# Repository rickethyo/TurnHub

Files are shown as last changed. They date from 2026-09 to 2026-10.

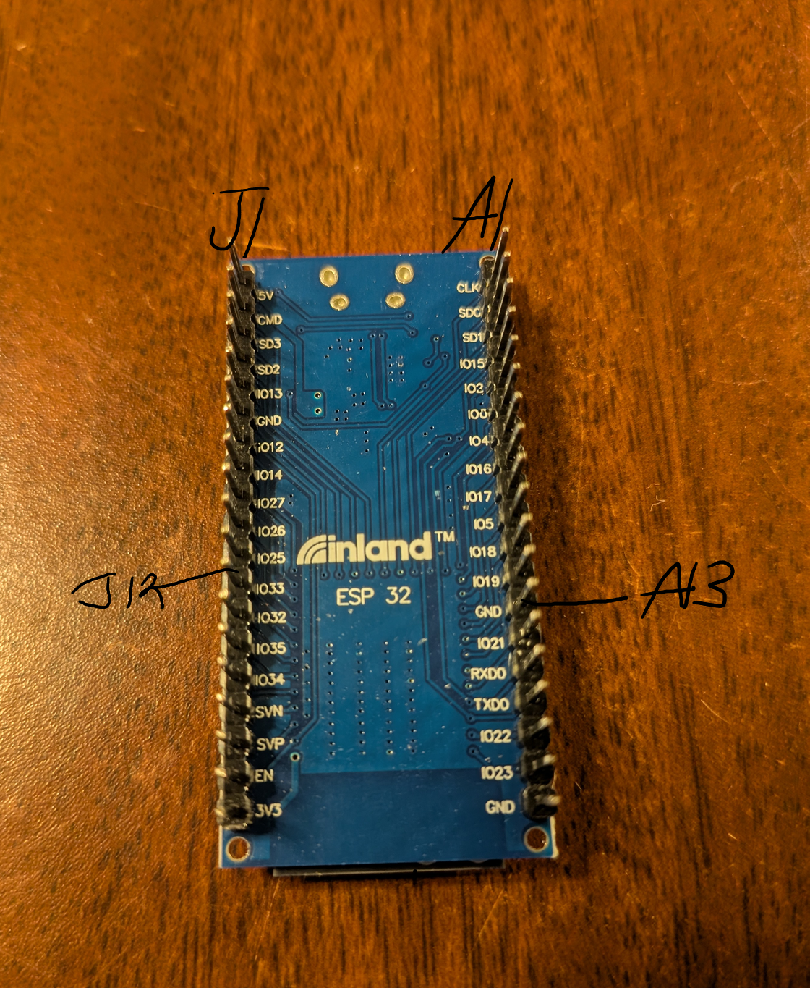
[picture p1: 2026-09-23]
KiCad/PCB/Sigilv1/reference/SigilBackMarked.png

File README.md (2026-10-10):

# TurnHub

TurnHub is a local-first tabletop game-management system: turn timer, lobby,
life totals and Commander damage, player profiles and statistics. An
authoritative **Atlas** table controller runs the game; player-facing
**Sigils**, phones and tablets (the Android app) and the Atlas
touchscreen request the same semantic actions from it.

**Current firmware:** Atlas **0.6.6**, Sigil **0.9.8** (protocol 3), on `master`.
Signed releases are published on GitHub Releases and installed from the
Android app or the Atlas portal.

Earlier Python/Raspberry Pi generations are recorded in
[Generation History](Documentation/engineering/history/GENERATION_HISTORY.md). They are
not part of this repository or the current runtime.

## Where to look

| Path | What |
|---|---|
| [`Atlas/`](Atlas/README.md) | ESP32 table controller: game engine, Wi-Fi AP, web portal and HTTP API, ESP-NOW radio, NVS and optional microSD storage |
| [`Sigil/`](Sigil/DISPLAY.md) | ESP32 player controller, e-ink and OLED variants ([Wokwi simulation](Sigil/WOKWI.md)) |
| [`Android/`](Android/README.md) | Native client: table view, player controls, guided setup and firmware updates |
| [`protocol/`](protocol/README.md) | Client contract: JSON schemas, [`http-v1.md`](protocol/http-v1.md), example responses |
| [`shared/include/`](shared/include) | Firmware headers shared by Atlas and Sigil (radio contract, firmware package format) |
| [`TestHarness/`](TestHarness/README.md) | Retired hardware test harness; historical source only, unsupported and excluded from builds |
| [`KiCad/`](KiCad/PCB/Sigilv1/README.md) | Sigil carrier PCB and schematics |
| [`Documentation/engineering/`](Documentation/engineering/README.md) | The engineering record: invariants, design references, staged work |
| [`Documentation/User Manual/`](Documentation/User%20Manual) | The user manual (newest `.docx`; the app bundles the same text) |

## Core architectural rule

**Atlas owns canonical game and table state.** Sigils, phones, the Atlas
touchscreen and simulators submit Intents and render Atlas state.
They never advance turns, resolve wins, own player identity or keep competing
game engines. See [Architectural Invariants](Documentation/engineering/ARCHITECTURAL_INVARIANTS.md).

```text
Profile (optional persistent person)
  -> Participant (one person at the current table)
    -> Controller assignment(s): physical Sigil seat, browser sessions, the app
```

Changing controllers never replaces the participant or moves its statistics.

## What works today

- Lobby with any-seated-player start (cancellable countdown), starter choice,
  turn passing with a three-second cancellable grace, pause/resume, concession,
  elimination, win claim/confirm, draw by the Atlas End match hold, rematch and reset.
- Game profiles (Generic, Magic, Commander, Yu-Gi-Oh!) with life totals,
  Commander damage and cross-player life requests the recipient approves.
- Turn timer with warning and expiry cues on Sigil lights and buzzers, the
  Atlas speaker and phones, with per-player accessibility preferences.
- Local profiles with PINs, phone-only and mixed phone/Sigil play, a Sigil
  profile picker, Admin/Game Master/Developer permissions, and table presence
  codes for protected actions.
- Deliberate pairing (60 s minimum window) over an encrypted Atlas-Sigil link,
  with forget/unpair and factory reset from menus, the portal and the BOOT button.
- Interrupted-match recovery: a power cut restores the match paused.
- Core statistics in NVS; detailed statistics, avatars and rotating
  diagnostics on an optional microSD card.
- Signed firmware updates for Atlas and both Sigil variants, delivered from
  the Android app or the portal, plus a first-run guided setup in the app.

Known limits are tracked in [Staged Changes](Documentation/engineering/STAGED_CHANGES.md).
The most important: statistics are not yet crash-safe exactly-once
([completion ordering](Documentation/engineering/STORAGE_AND_RECOVERY.md)).

## Persistence

Survives restart: profiles, PIN hashes, permissions and policy, core
statistics, seat bindings, pairings, game settings, accessibility
preferences, the Wi-Fi password, speaker volume, setup stage and touch
calibration (NVS); detailed statistics and diagnostics (microSD, optional).

RAM only: browser sessions, lobby participation and live game state, except
the interrupted-match recovery record, which restores paused and never
replays statistics.

## Building and testing

Commands for every target are in [`CLAUDE.md`](CLAUDE.md) and each
directory's README. CI (`.github/workflows/ci.yml`) runs the host suites,
contract checks, supported firmware builds and the Android tests; see
[Continuous Integration](Documentation/engineering/CONTINUOUS_INTEGRATION.md).

## Local-first

The core play path never needs a cloud service, subscription or internet
connection. Atlas serves the table on its own Wi-Fi. The broader ownership,
repairability, privacy and accessibility direction is in
[Product Principles](Documentation/PRODUCT_PRINCIPLES.md).

## Status

TurnHub is a prototype. Every Atlas and Sigil is reflashed together,
so there is no backward compatibility before release: a changed protocol or
storage layout means reflashing everything and, for storage, a factory reset.

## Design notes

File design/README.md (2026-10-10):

# TurnHub design system (V1)

One source of truth for how the Atlas portal, Android app and device screens look. Status:
**Implemented** in source (2026-10-02, V1 phase 0). The portal and the app adopt
it in later phases; see the V1 plan and `Documentation/engineering/WEB_PORTAL.md`.

| Path | What | Edit? |
|---|---|---|
| `tokens.json` | Themes (colors per role), type scale, spacing, radii, elevation, motion springs, layout constants | Yes, the source |
| `icons/*.svg` | The original icon set: 24-point grid, 1.75 stroke, round caps, `<path>` elements only | Yes, the source |
| `fonts/` | Inter and Cinzel variable fonts, subset to Latin (TTF for Android, WOFF2 for the web), with their OFL licenses | Replace only with a recorded source |
| `web/components.css` | The web component library (buttons, pills, lists, sheets, turn hero, life tiles, app shell), built only from tokens | Yes |
| `avatars/*.svg` | The player icons: filled glyphs on the 24-point grid, `<path>` elements only, with an optional lighter tone (`opacity`) and holes (`fill-rule="evenodd"`). One file per preset in `shared/include/avatars.h`, same keys; the build refuses a missing or extra one | Yes, the source |
| `styleguide.html` | Living specimen of all of the above, with a playable Game screen preview | Yes |
| `build_tokens.py` | Generates every file below from `tokens.json` and `icons/`, and checks contrast | Yes |
| `bundle.py` | Inlines stylesheets, fonts and the icon sprite into one HTML file | Yes |
| `shared/include/device_theme.h` | Generated device theme IDs and opaque RGB888 role palettes; alpha roles are flattened over the theme background | No, generated |
| `Atlas/include/modern_fonts.h`, `Sigil/include/modern_fonts.h` | Inter bitmaps generated by `tools/fonts/make_modern_fonts.py` from the licensed font below; device digits have equal advances | No, generated |
| `dist/tokens.css`, `dist/icons.svg` | Generated web tokens and icon sprite (icons are `i-<name>`, player icons `a-<key>`) | No, generated |
| `Android/.../ui/theme/DesignTokens.kt`, `Android/.../res/drawable/ic_th_*.xml`, `ic_avatar_*.xml`, `Android/.../res/font/*.ttf` | Generated Compose tokens and vector icons, and the fonts copied for Android | No, generated |

```
python3 design/build_tokens.py            # regenerate after editing tokens.json or icons/
python3 design/build_tokens.py --check    # CI: generated files current, contrast minimums met
python3 design/bundle.py design/styleguide.html --out design/dist/styleguide.html --embed-fonts
```

The scripts use the Python standard library only, so PlatformIO's Python runs
them on Windows too. Re-subsetting a font needs `fonttools` and `brotli`
(`pyftsubset`, command in "Fonts" below).

## Themes

| Key | Name | Use |
|---|---|---|
| `graphite` | Graphite | Default on dark devices. Modern, near-black with one warm gold accent |
| `daylight` | Daylight | Default on light devices. Replaces Parchment |
| `brass` | Brass | Optional. Gold and walnut with Cinzel display type, matching the Atlas screen |
| `contrast` | High contrast | Chosen automatically when the device asks for more contrast |

With no saved choice a client follows the device (`defaults` in `tokens.json`).
Midnight and Parchment from the pre-V1 portal are retired: Graphite and Daylight
cover them. Owner decision 2026-10-02: modern first, Brass kept as an option.

**Roles, not colors.** Components use `--c-<role>` (CSS) or `TokenColors.<role>`
(Kotlin), never a literal. The roles: `bg`, `surface1..3`, `fill`, `fillStrong`,
`separator`, `separatorStrong`, `text`, `textSecondary`, `textTertiary`,
`accent`, `accentPressed`, `onAccent`, `accentSoft`, `turn` (the active turn,
the one thing that glows), `onTurn`, `turnSoft`, `good`, `warning`, `critical`,
`info`, `focus`, `scrim`, and `glowA`/`glowB` (Brass background glow only).

**Contrast is enforced.** `contrast.checks` lists WCAG 2.2 minimums; the build
refuses to write files when a theme misses one (translucent colors are
composited over the theme background first). Status colors must reach 4.5:1 on
`surface1` because they are also used as text. Color never carries meaning
alone: every status pill and tile state also has words.

## Type

Inter (text and UI) for every theme; Brass swaps the display role to Cinzel.
Sizes are in `type`: `caption` 12 through `mega` 112. Clocks and life totals
(`clock`, `hero`, `mega`) use tabular figures so digits do not jitter.

## Motion

Three springs (`snappy`, `gentle`, `bouncy`) as Compose damping ratio and
stiffness. The CSS build simulates the same physics and emits a `linear()`
easing plus its settle duration (`--spring-<name>`, `--spring-<name>-dur`),
falling back to `--ease-standard` in browsers without `linear()`. Reduce motion
(system setting or the per-browser switch, `data-motion=reduce`) shortens every
animation and transition to 1 ms.

## Fonts

| Font | Source | Files |
|---|---|---|
| Inter 4 (variable: `opsz`, `wght`) | `github.com/google/fonts` `ofl/inter/Inter[opsz,wght].ttf`, fetched 2026-10-02 | `fonts/Inter-Variable.{ttf,woff2}`, `fonts/OFL-Inter.txt` |
| Cinzel (variable: `wght`) | `github.com/google/fonts` `ofl/cinzel/Cinzel[wght].ttf`, fetched 2026-10-02 | `fonts/Cinzel-Variable.{ttf,woff2}`, `fonts/OFL-Cinzel.txt` |

Both are SIL Open Font License 1.1 and recorded in
`Documentation/legal/DEPENDENCY_TRACKER.md`. They were subset with:

```
pyftsubset <font.ttf> --unicodes="U+0000-00FF,U+0131,U+0152-0153,U+02BB-02BC,U+02C6,U+02DA,U+02DC,U+2000-206F,U+2074,U+20AC,U+2122,U+2190-2199,U+2212,U+2215,U+2248,U+2260,U+2264-2265,U+2713,U+2715,U+00D7,U+2026,U+25B2,U+25BC,U+25CF" --layout-features='*' [--flavor=woff2] --output-file=<out>
```

## Icons

Add an icon by dropping a 24×24 SVG with `<path d="...">` elements into
`icons/` and running the build. Use `stroke="currentColor"`, no fills, no
`<circle>`/`<rect>` (draw them as arcs) so the Android conversion stays a copy.
The web references `#i-<name>` in the sprite; Android uses
`DesignTokens.Icons.<camelName>` (`R.drawable.ic_th_<name>`).

## Device screens

Atlas offers all four color themes under Menu > Device > Theme, defaulting to
Graphite. Sigils choose independently through their local Theme menu entry.
OLED Daylight is dark ink on white; its other themes are light ink on black.
E-paper normally uses black on white, adapting the typography, hierarchy and ornament
rather than trying to reproduce color. Brass alone uses Cinzel/Oswald and gears;
modern themes use Inter and plain cards, with distinct one-bit glyphs, life symbols and header marks. See
[Hardware](../Documentation/engineering/HARDWARE.md) for persistence and refresh
behavior. To regenerate Inter device fonts, install `freetype-py` in a Python
virtual environment and run `python tools/fonts/make_modern_fonts.py`. No fonts
are downloaded: it reads the checked-in Inter variable font at weight 600.

Each device also saves an independent Invert switch, exposed next to its theme
controls. Sigils swap foreground/background; Atlas complements its RGB palette
while retaining conventional black-on-white QR codes. This does not change LED
preferences. `shared/include/theme_emblem.h` owns the diamond, sun and boxed
hourglass marks; Brass retains its renderer's gear.

## Player artwork for LCD hardware (2026-10-10)

SVG player defaults are resolution independent. `build_avatar_masks.py`
rasterizes them at 256px and filters to 64px alpha masks in
`Atlas/include/avatar_masks.h`; current Atlas filters into its 16px slot without
blocky bitmap enlargement. Android uses the original vector drawables. Frozen
Sigils keep `shared/include/avatars.h` unchanged. Regenerate with
`pip install -r tools/artwork-requirements.txt` and run the generator; its
`--check` verifies source/artifact digests using stdlib only and runs in CI.
Uploaded JPEG masters are 512px/48KiB; 64/128px previews are provisional device
slots until the ESP32-S3 2.8/4-inch layouts are built.

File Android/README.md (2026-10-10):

# TurnHub Android

This directory holds the native TurnHub Android client.

The Android app is a controller and presentation client. It is not a second TurnHub game engine, with one exception: the standalone tablet game below.

## Hard architecture rule

The app may:

- Discover or connect to an Atlas.
- Authenticate a player/session.
- Request a current state snapshot.
- Render authoritative Atlas state.
- Send semantic Intents.
- Receive state/events.
- Cache user preferences and non-authoritative profile conveniences locally.
- Recover from connection loss by resynchronizing with Atlas.

The app must not:

- Advance turns locally as authoritative state.
- Decide whether a concession, win claim, pause, or life change is legal.
- Become authoritative for life totals, active player, timers, winner, or elimination state.
- Reimplement gameplay rules that already belong to Atlas.
- Depend directly on ESP32 C++ implementation details.

### The one exception: the standalone tablet game

Device-first entry (2026-10-08, implemented on `codex/app-only-entry`, device
acceptance pending): the disconnected landing screen leads with **Play on this
device**, or **Resume game** for a running/paused local match. No account,
network or nearby-device permission is needed. `MainActivity` owns navigation:
`turnhub_ui/prefer_device_play` remembers local play across launches, while the
saved instance state remembers the currently open screen across rotation.
Back returns to Home without changing the preference or game. Explicit Atlas
Connect, Try again or setup selects Atlas for future launches and requests local
network permission if needed. Fresh launches never request that permission;
Atlas-preferred launches rejoin only when permission is already available.
Entering device play cancels discovery, Wi-Fi joins and pending repository
connects, then disconnects polling and releases the Atlas network. A later
connection waits for the disconnect to finish. Local history and explicit Atlas-scoped linking are described below
(TH-001 in `COLLABORATION.md`).

With **no Atlas at the table**, **Play on this device**
runs a small game on the device itself: life, Commander damage, turns, pause,
concede and the winner (`standalone/StandaloneGame.kt`). It is a separate
game, never a copy of or a change to a game Atlas is running, so nothing is
merged back live. The rules above apply in full whenever Atlas is present.

- The table screen is tablet mode's (`ui/tablet/TabletTable.kt`); it sends
  the same seat actions through `data/TableControls`, which
  `StandaloneTable` applies locally instead of `AtlasTablet` sending them.
- Adding a typed name creates a reusable player with a local UUID. Selecting a
  saved player reuses that identity. Same-name players stay distinct and short ID
  labels distinguish them. Reset/rematch preserves IDs; records snapshot names.
- **Device players and history** opens from Home (connected or disconnected),
  and the local lobby. It shows results and basic played/won/draw totals derived
  only from retained local matches by local ID, without combining Atlas totals.
- The versioned local library owns roster, history and independent delivery
  metadata. Active game/library writes share one preference transaction. Every
  completed match is retained once by its match UUID; there is no automatic
  200-record pruning. Imported/rejected results stay in history. Current game
  and identities survive reconstruction; actual Android rotation/relaunch still
  needs device acceptance. Corrupt/future data fails closed, preserves the
  stored bytes, and explains the problem rather than overwriting it.
- Import is optional and explicit, never automatic on sign-in. From history,
  connect/sign in, load current Atlas profiles, choose a different profile for
  each player in a match, then Import mapped match. Nothing is preselected by
  name. The delivery mapping snapshots `(atlasId, profileId)` per match; it
  does not merge/replace local identities or change historical player names.
  Pending mappings are frozen through uncertain acknowledgements; retry uses the
  same match UUID and destination. Imported mappings cannot be resubmitted.
- History separately shows needs-linking, pending, imported and needs-attention
  (rejected) states. HTTP 400 retains the record and reason without automatic
  retry; explicit review/relink can queue it again. Transient/malformed responses
  keep pending work and block newer deliveries until acknowledged. A signed-in
  user can send only pending work for the current Atlas. Atlas 0.7.2+ requires
  exact destination/profile IDs and rejects missing, duplicate, deleted,
  archived or unreadable identities before taking a receipt; no name fallback.
  Acknowledged partial credit is displayed and never automatically retried.
- Existing queue records are retained as legacy history without guessed local
  or Atlas identity and can be explicitly mapped per match. Earlier imported/
  dropped records cannot be reconstructed. Atlas's 64-receipt dedupe window and
  possible partial credit after storage failure/power loss remain unchanged;
  this is not crash-safe exactly-once statistics across arbitrary retries.
- No turn timer, Two-Headed Giant, phones or Sigils in this mode.

```text
Compose UI
    -> ViewModel
        -> AtlasRepository
            -> TurnHub protocol adapter
                -> Atlas
```

State flows back in the opposite direction.

## Stack

- Kotlin, Jetpack Compose, Material3
- Unidirectional data flow with a ViewModel at screen boundaries
- Repository abstraction around Atlas communication
- Coroutines / Flow for asynchronous state

## Current source layout

The Gradle/Kotlin project was bootstrapped as a single `:app` module (Kotlin +
Jetpack Compose, Material3, no other UI framework). Current layout:

```text
Android/
  app/
    src/main/java/com/turnhub/android/
      MainActivity.kt
      protocol/                     wire DTOs + parser, 1:1 with /protocol schemas
        AtlasConnectionState.kt
        AtlasInfo.kt                /api/v1/info
        StateSnapshot.kt            /api/v1/state (+ PendingDecisions)
        Player.kt                   players[] (+ CommanderDamage, LifeRequest)
        GameProfile.kt
        TableState.kt
        AtlasWireParser.kt          strict org.json parsing, fails closed
      domain/
        TableSummary.kt             UI aggregate (+ TablePlayer, ControllerHandle,
                                    PhysicalSigilAtTable)
        TableSummaryMapper.kt       info + state -> TableSummary
        UserManual.kt               parser for the bundled manual asset
      data/
        AtlasRepository.kt          the only seam the UI talks through
        HttpAtlasRepository.kt      connect handshake, polling, reconnect rules
        AtlasTransport.kt           getInfo()/getState() seam (+ factory)
        HttpAtlasTransport.kt       HttpURLConnection implementation
        WifiPreferringConnectionOpener.kt
        AtlasEndpoint.kt            user-editable http://host[:port]
        AtlasCompatibility.kt       API "1" / protocol "0.1" / stateSnapshot
        AtlasFailure.kt             user-facing failure types
      ui/
        home/                       HomeScreen, HomeUiState, HomeViewModel
        manual/                     ManualScreen (the "?" in the top bar)
        components/                 ConnectionStateBadge, TableSummaryCard,
                                    PlayerRow, PhysicalSigilRow
        theme/
    src/main/assets/manual.md       generated user manual (see below)
    src/main/res/xml/network_security_config.xml
    src/test/java/com/turnhub/android/
      testing/Fixtures.kt           loads ../protocol/examples/*.json
      protocol/  domain/  data/  ui/home/
```

`protocol/` holds Kotlin wire models that mirror the JSON shapes in `/protocol`
(`state-v0.1.schema.json`, `info-v1.schema.json`) -- not the ESP32 C++ types,
and not a claim that the wire format is frozen. Unsigned 32-bit Atlas values
(revision, participant IDs, turn counts, `*Ms` clocks) are `Long`. `domain/`
holds UI-oriented models that combine more than one wire response
(`TableSummary` merges `/api/v1/info` identity fields with an `/api/v1/state`
snapshot) and so aren't a 1:1 mirror of any single schema.
`data/AtlasRepository` is the only seam the UI talks through; networking stays
below it. As lobby/game/player/settings/scanner screens are added, `ui/`
should grow one subpackage per screen alongside `ui/home`, following the same
pattern.

The app carries the user manual so it reads offline, before connecting to
any Atlas. `app/src/main/assets/manual.md` is generated from the newest
`Documentation/User Manual/TurnHub Manual V*.docx`; never edit it by hand.
After changing or adding a manual version, run
`python Android/tools/export_manual.py` (standard library only) and commit the
result. CI runs it with `--check` and fails when the asset is stale.

The application ID `com.turnhub.android` is frozen: the Google Play listing
was created with it on 2026-10-06 (Play App Signing), and Play never lets an
app change it.

## Development dependency order

Android work may proceed in parallel with firmware, but these interfaces need to stabilize in roughly this order:

```text
Intent vocabulary
    -> Atlas dispatcher enforcement
        -> v0.1 wire adapter
            -> state snapshot + revision
                -> Android repository
                    -> Android UI
```

The app UI does not need to wait for every TurnHub feature. It does need a stable way to say "I want X" and receive "this is now the authoritative state."

## Testing direction

Android tests should eventually include:

- Protocol serialization tests against files in `/protocol`.
- Repository tests using a fake Atlas transport.
- ViewModel tests that verify UI state follows repository state.
- Reconnect/state-revision tests.
- Duplicate `requestId` behavior once Atlas implements deduplication.
- Stale `expectedRevision` conflict handling.

Game-rule tests stay with Atlas/domain code. Android tests verify client behavior, not whether TurnHub rules are correct.

The current suite is plain JVM tests (no Robolectric/instrumentation). They
parse the real `protocol/examples/` fixtures, drive `HttpAtlasRepository`
through a scripted fake `AtlasTransport` in virtual time, and exercise
`HttpAtlasTransport` against the JDK's local HTTP server. `org.json` is a
test-only dependency because the unit-test `android.jar` only has stubs.

Build and test from `Android/` (Android Studio's bundled JDK works):

```text
./gradlew assembleDebug
./gradlew testDebugUnitTest
./gradlew testDebugUnitTest --tests "com.turnhub.android.data.HttpAtlasRepositoryTest"
```

Play builds: CI uploads a signed release bundle (`.aab`) from every run, ready
for the Internal testing track; see "Android release bundle" in
`Documentation/engineering/CONTINUOUS_INTEGRATION.md`.

## What the app does

The app talks to a physical Atlas over its HTTP API; production always uses
`HttpAtlasRepository`. It shows the live table, gives a signed-in player personal and shared-tablet game controls, runs first-run setup, and installs firmware
updates on Atlas and the Sigils.

1. Open the app. It asks for "Nearby devices" (local network, Android 17),
   then rejoins the saved table by itself (`HomeViewModel.onAppStarted`):
   Android remembers its approval, so this is silent when the table is
   there. *Verified* on the Pixel Fold, 2026-09-30: a cold start opens the
   live lobby with no taps.
   - The saved table doesn't answer: "Couldn't reach your table" with Try
     again and Set up a new table (a factory-reset Atlas).
   - A phone that never joined a table leads with Set up a new table, which
     joins with the printed default; first-run setup then opens.
   - No Wi-Fi scan. Spotting tables in range was tried first
     (NEARBY_WIFI_DEVICES, `neverForLocation`), but on this Android scan
     results need location permission (`WifiService`: "has no location
     permission", zero results), and the owner chose not to ask for location
     (2026-09-30).
   Connect still works as before. The address defaults to
   `http://192.168.4.1` and is under Advanced. For that address the app
   first joins Atlas's Wi-Fi itself (see "Targeted Wi-Fi" below); other
   addresses must already be reachable.
   Anything that restarts Atlas from the app (setup's Finish and updates,
   Settings > Wi-Fi password, factory reset) saves the password Atlas comes
   back with and rejoins by itself.
2. `GET /api/v1/info` must be a TurnHub Atlas with API `1`, protocol `0.1`
   and state snapshots; anything else fails with a clear message.
3. `GET /api/v1/state` is mapped into the Home screen; only then is the app
   CONNECTED. State is then polled about once per second.
4. Every poll replaces the view (clocks change at the same revision). A new
   `atlasId`, new `bootId` or a lower `revision` discards the view and
   re-runs info + state. Three failed polls in a row put the app offline
   (2026-10-07, *Implemented*): it stays on its current screen, tablet mode
   included, with the last snapshot shown read-only under an "Offline:
   reconnecting" banner and its age, rejoins Atlas's Wi-Fi if Android dropped
   it, and polls every 2 s until Atlas answers; the epoch rules above then
   apply, so a restarted Atlas is rebuilt from a fresh handshake and its
   sessions reset. Disconnect stops polling and clears state.
   During a game, tablet mode keeps working offline for life and Commander
   damage only: each change is kept per participant with when it was tapped
   (`AtlasTablet.queueOffline`), shown on the panels, and sent once Atlas
   answers again through the usual tablet routes with `queuedMs`, where
   Atlas's rules decide it. Changes from before an Atlas restart, from an
   earlier game, or for a player no longer in it are dropped, as is any Atlas
   refuses, with one note; a clean replay is silent. Passing, pausing,
   conceding, win claims, answers, seating and settings are refused offline,
   since they depend on Atlas's live clock and turn. A match Atlas recovered after a reboot is simply shown
   as `PAUSED`.

V1 redesign, phases 5 and 6 (2026-10-02, *Implemented*, built by CI; not yet
checked on a phone):

- Themes come from the shared design tokens (`design/tokens.json`, generated
  `ui/theme/DesignTokens.kt`): Automatic (the default: Graphite on a dark
  phone, Daylight on a light one), Graphite, Daylight, Brass and High
  contrast. `Palette.kt` builds every component role from them; a saved
  `midnight` or `parchment` choice opens as Graphite or Daylight. Only Brass
  draws ornament (sheens, rivets, the brass dial); the modern themes draw flat
  cards, tinted pills and buttons, and a turn ring.
- Inter (all text) and Cinzel (Brass headings) are bundled in `res/font`,
  copied from `design/fonts` by `design/build_tokens.py`; clocks and life
  totals use tabular figures.
- New launcher icon (the portal's gold gear, with an Android 13 themed-icon
  layer), an Android 12 splash on the theme's ground, edge-to-edge drawing with
  system bar icons that follow the theme, and a bottom bar using the shared
  icons: Game, Players, Me, Settings (Admins and Game Masters) and Developer.
- Game screen: the turn hero is a native ring that drains or fills with the
  clock and breathes while a game runs; the active player's avatar sits under
  it. Life tiles count to a new total on a spring, bounce slightly and show
  the change for a few seconds. Haptics: a firm tap when the turn reaches this
  phone's player, ticks on the life buttons and tab changes, confirm/reject on
  Pass. Reduce motion turns the springs, halo and transitions off.

V1 redesign, phases 7 and 8 (2026-10-02, *Implemented*, built by CI; not yet
checked on a phone):

- App lock and automatic sign-in (`data/ProfileVault.kt`, Android 11+): the
  sign-in sheet's "Sign in automatically" keeps that profile's PIN or password
  AES-GCM encrypted under an Android Keystore key that opens for 30 seconds
  after the phone's fingerprint, face or screen lock. It is saved only after
  Atlas accepts the secret. On each new Atlas boot the app asks for the
  phone's lock and signs in; cancelling or signing out by hand is respected
  until the next boot, and a rejected secret reopens the sheet. Me > This
  phone turns it off. Excluded from backup and device transfer.
- Sign-in is a bottom sheet with a grouped account list (`GroupedList`).
- The seat controls rise in as the join flow moves through its stages.
- Live turn notification (`data/TurnNotifier.kt`, `domain/LiveTurn.kt`): while
  the app is in the background and its player sits in a game, the shade and
  lock screen show whose turn it is with a running turn clock (or the turn
  timer counting down). It alerts only when the turn comes to you and asks to
  be a promoted live update on Android 16+. It lasts as long as the app holds
  the Atlas connection.
- Haptics use the vibrator's full-strength primitives (`ui/components/Haptics.kt`).

Native player experience (original parity pass: 2026-09-26):

- The app provides the player experience and shares TurnHub design tokens. The
  themes (since V1: Automatic, Graphite, Daylight, Brass, High contrast;
  `ui/theme/Palette.kt`) are chosen in My Account and saved on the phone only; the
  device's raised-contrast setting still forces High contrast. A Reduce motion
  switch stops the turning gear and dial sweeps.
- Native tabs: **Game** (the brass turn dial, my seat with every
  session controls: join, I go first, start, cancel
  countdown, pass/cancel pass, pause/resume, claim, confirm or deny a win,
  concede, leave, rematch, reset; life tiles for every player with my -5/-1/
  +1/+5 and custom changes, tap-to-request changes to other players, the
  incoming life-request banner with its 15 s countdown, Commander damage, game
  setup and table facts), **Players** (roster and seated Sigils) and **My
  Account** (name, PIN, avatar, Sigil light color, Sigil accessibility,
  appearance, connection).
- All of it goes through the same routes as the portal (`/api/control/*`,
  `/api/control/life*`, `/api/control/commander`, `/api/game/settings`,
  `/api/session/profile`, `/api/session/personalization`); Atlas validates
  every request.
- **Settings** (Admin or Game Master accounts) and **Dev** (Developer
  accounts) tabs appear from `/api/session/me`'s `permissions`:
  verify at the table (the six-digit code from the Atlas screen; a request
  Atlas answers `403 presenceRequired` asks for the code and retries once),
  Wi-Fi password, paired Sigils (rename, forget, factory reset), pairing
  window, speaker volume, Return to lobby, Atlas factory reset, account
  permissions and archiving, Game Master moderation, first-Admin setup, and
  the Developer activity feed, raw status/devices/seats/diagnostics JSON and
  a shareable serial log (`AtlasAdminConsole`). Firmware updates run from
  first-run setup and the **Update now** card ([Sigil OTA](../Documentation/engineering/FIRMWARE_UPDATES.md)).
- **First-run setup** (2026-09-30, FIRST_RUN_SETUP.md): after Connect the
  app reads `GET /api/setup`; while Atlas is new it shows the setup steps in
  place of the table (`AtlasSetupAssistant`, `ui/setup/SetupScreen.kt`):
  account (create or sign in), table code (makes the account the Admin),
  Sigil pairing, one update prompt for Atlas and every paired Sigil, and the
  table's own Wi-Fi password. Firmware comes from the public GitHub release
  feed (`GitHubFirmwareReleases`) over the phone's own internet, checked for
  size and SHA-256; Atlas checks each package's signature. After an Atlas
  restart the app rejoins with the saved password and signs in again with
  the PIN typed during setup (kept in memory only).
- **Quick app switch:** Android releases an app's `WifiNetworkSpecifier`
  network once the app leaves the foreground. When the app leaves the screen
  while connected, `AtlasLinkHoldService` (a `connectedDevice` foreground
  service with a notification) keeps the app eligible for two minutes
  (`HOLD_MS`) and stops as soon as the app returns.

Accessibility (2026-09-24):

- A signed-in player's **Sigil accessibility** button opens
  `AccessibilityDialog`: Sigil sound, light style and Action hold times, read
  from and saved to Atlas through `/api/session/accessibility` (the same
  endpoint and validation as the portal). Atlas stores them with the profile.
- When Android 14+'s contrast setting is raised, `TurnHubTheme` switches to fixed
  high-contrast colors instead of wallpaper colors, and follows changes live.

Targeted Wi-Fi (no trip to Android settings):

- `TargetedAtlasWifiLink` asks Android for `TurnHub-Atlas` with a
  `WifiNetworkSpecifier` (no internet capability). The network is used only
  by TurnHub: the phone keeps its normal Wi-Fi/mobile connection. The Pixel
  Fold even stayed on home Wi-Fi at the same time. The link is also the
  `HttpConnectionOpener`, so Atlas requests go over that network.
- Password order: the saved password for the SSID, else the shipped default
  `TurnHub-Setup` (protocol/http-v1.md), else the "Atlas Wi-Fi" prompt. The
  prompt allows editing the SSID and has an "I've joined this Wi-Fi already"
  option for the manual path. Only credentials that actually joined are saved
  (`PreferencesWifiCredentialStore`, app-private, excluded from backup and
  device transfer).
- Android shows its approval dialog at most once per access point, then
  remembers it. Disconnect or a failed handshake gives the network back; a
  lost connection keeps the request and rejoins with the saved password while
  the app is offline.
- Needs Android 10+ (API 29). On older phones the prompt points to the manual path.
- Verified on a Pixel Fold (Android 17): the default fails against an Atlas
  with an owner-set password, the prompt appears, Join connects, Disconnect
  releases, and the next Connect reuses the saved password with no prompt.

Networking notes:

- Android 17 enforces local network protection for apps targeting API 37:
  without the `ACCESS_LOCAL_NETWORK` runtime permission ("Nearby devices"),
  every TCP connection to Atlas silently times out. `MainActivity` requests it
  when the user taps Connect (Android 17+ only); if denied, Home explains why
  and offers "Open app settings". Verified on a Pixel Fold running Android 17.

- Cleartext HTTP is allowed only for `192.168.4.1`
  (`res/xml/network_security_config.xml`). Other addresses are refused by
  Android until that file is deliberately extended (e.g. for Home/LAN mode).
- For the manual path (phone joined to Atlas in settings), Android often
  keeps mobile data as the default route because Atlas has no internet.
  `WifiPreferringConnectionOpener` sends Atlas requests over the current Wi-Fi
  network (needs `ACCESS_NETWORK_STATE`).
- `/api/v1/state` carries each player's `displayName`; players without one
  show as `Player N`. Paired Sigils come from the Admin device list, not from
  the state snapshot.

### Local library feature boundary (TH-001 B/C implemented, device acceptance pending)

Android's standalone domain owns reusable local-player UUIDs, completed match
snapshots and their derived local statistics. Explicit add/select actions are
validated locally; names are labels and never identity keys. The local library
is a versioned JSON document in `turnhub_standalone/library`, separate from the
active game's `game` key. Match UUIDs remain stable across import. History is
retained without automatic pruning; delivery metadata references history by
match UUID and acknowledgement/rejection cannot delete a result. Clearing app
data/uninstall removes it; export and storage-error recovery remain future work.
Existing unscoped records are retained without inferred Atlas or local identity.

Optional delivery requires a per-match explicit `(atlasId, profileId)` mapping
for every player, validated locally and by Atlas's import domain. Connected
state remains Atlas-owned. No new dependency or gameplay Intent is needed;
the import form contract/validator changes together. Android renders text
statuses and labeled player picks in scrollable layouts; local controls use
existing TableControls. TalkBack, text-scale and phone/foldable acceptance must
be recorded separately from JVM tests and builds.

Local schema 1 uses JSON object fields `schema`, `players` (localId/name),
`history` (immutable GameRecord objects) and `deliveries` (recordId/status/reason/
atlasId/profileIds in immutable player order). IDs are UUID strings; dates and
clocks are Unix/integer milliseconds. JSON null marks unknown legacy identity.
Unknown schema, malformed records or duplicate local/match IDs fail closed.
Android platform backup may include these preferences under existing app backup
rules, but no TurnHub export/restore guarantee is offered. Every local game edit
currently serializes the library and commits preferences synchronously; very
large histories need performance/storage work before a release guarantee.

### Platform and control presentation boundaries

The profile vault checks Android 11 at its key-generation API boundary as well
as exposing availability; its authentication policy and stored format are
unchanged. Haptics use typed click/thud primitives, check each required motor
capability, and retain the existing predefined-click/pulse fallbacks. The
connected-player control transition renders its target table/player snapshot,
keyed by control stage so ordinary polls do not start another stage animation.
Outgoing-stage controls are disabled while the next stage is shown. These
presentation paths still send existing Atlas actions and require physical
app-lock, haptics, motion and assistive checks before device acceptance.

### App-first play cutover (2026-10-10)

Atlas 0.7.7 (with the embedded admin portal) retires browser gameplay and browser tablet/statistics.
Android polls state and seats with the current session token, or `?game=N` while
signed out. It parses Atlas’s existing `game`/`games` fields and offers the venue
selector in personal and shared-tablet views. Atlas validates switching; personal
players cannot leave an active game, and tablet switches leave their players in
place. Game changes rebuild name/avatar presentation and reset staged controls;
responses from changed polling contexts never publish. Tablet queued edits are
scoped by game, boot and participant. `expectedGame` protects raw table actions
from a session switch racing a queued request. No new gameplay owner or dependency.

The reachable Game setup now accepts custom 15–3600-second timers, saved explicitly.
Normal signed-in players can refresh paired Sigils and request attachment of an
empty seat A in the lobby, confirmed with Link phone. Atlas still rejects occupied
or unavailable seats. The Players invitation QR installs the app; joining Atlas
Wi-Fi and choosing Connect remain explicit steps. There is no password in the QR.

Native foreground event sound/vibration settings and a background win-decision
notification remain planned. Existing native haptics, turn notifications and
text decision controls remain; device acceptance is tracked in STAGED_CHANGES.

Atlas firmware includes the complete admin portal and its maintenance/Developer
assets. The update assistant lists only Atlas and Sigils, never queries portal
installation or card status, and ignores retired `portal` release entries.

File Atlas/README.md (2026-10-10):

# TurnHub Atlas ESP32

The ESP32 table controller: the authoritative game engine, the
`TurnHub-Atlas` Wi-Fi access point and web portal, the HTTP API, the ESP-NOW
radio to Sigils and NVS/microSD persistence. Firmware version: see
`include/firmware_version.h` (0.6.6 at the time of writing).

Module layout and the Intent pipeline are described in the repository's
`CLAUDE.md` and in [Software Architecture](../Documentation/engineering/ARCHITECTURE.md).
First-run setup is in [First-run setup](../Documentation/engineering/FIRST_RUN_SETUP.md);
the longer-term provisioning direction (home Wi-Fi, recovery mode) is in [`OOBE.md`](OOBE.md).

## Hardware

- LCDwiki E32R28T 2.8" display module (ESP32-32E). The touchscreen is the only
  physical input, plus the DevKit BOOT button for pair / unpair / factory reset.
- On-board speaker for table-wide cues; optional microSD card.
- ESP-NOW Sigil transport and the WPA2 access point, both on Wi-Fi channel 6.

Pins and the touchscreen layout are in the
[Hardware Reference](../Documentation/engineering/HARDWARE.md).

## Profiles and phone play

Use the Android app to create a local profile or sign in with its
PIN; no Sigil is needed. Signing in and joining the table are separate: choose
**Join game** after signing in. Any seated player may start (with a
countdown any seated player can cancel), choose the starter and rematch.
Phones support every game action through the same Intent handlers as Sigils.

Several phones may sign into one profile and control the same participant. In
the lobby, **Connect a Sigil → Attach seat A to my profile**, confirmed with
**Link phone** on the Sigil, attaches a Sigil to the signed-in participant.
A Sigil can also join on its own through its profile picker. Unassigned Sigils
and Guest play as guests, which never create saved accounts or statistics.

Logout revokes only that app session; signing in again reconnects to the
same participant. PIN changes revoke the profile's other sessions, and five
failed PIN attempts within 15 seconds throttle that profile.

Limits: 16 table participants (8 physical Sigils, two seats each), 32 HTTP
sessions, 64 profiles, 8 Wi-Fi stations at once.

Details: [Players and Accounts](../Documentation/engineering/PLAYERS_AND_ACCOUNTS.md).

## Turn-pass grace

A player's pass is provisional for three seconds. During the grace a second
Pass from the same player cancels it. When it expires, the engine commits the
pass at the original request time, so the outgoing player's turn doesn't gain
three seconds. The status API exposes `passPending` and `passGraceMs`. The
touchscreen's Table screen has a 2 s **Master pass** hold for a stuck turn,
which passes at once and logs `ATLAS|GAME|MASTER_PASS`.

## Statistics

Every ending (win, concession, elimination, End match draw) reaches statistics
through the engine's single game-completed event, after the finished-match
checkpoint commits ([completion ordering](../Documentation/engineering/STORAGE_AND_RECOVERY.md)).
NVS keeps a core record per profile (games played and won, last result and
game type); the detailed record (turn counts and times, game times, first
starts, eliminations) lives on the microSD card. After a completed game the
serial log shows `ATLAS|PROFILE_STATS|GAME_RECORDED|<count>`.

Statistics are served for the signed-in profile only:

```text
GET /api/session/stats
GET /api/session/stats/export
```

The Android app displays and exports profile statistics. The browser portal
is for administration and is embedded in Atlas firmware; it needs no card.

## Wi-Fi access point password

Atlas hosts `TurnHub-Atlas` (WPA2, channel 6). Until an owner sets a password
(the portal's Atlas Wi-Fi security card, after verifying at the table, or the last
step of first-run setup), Atlas uses the shipped passphrase `TurnHub-Setup`
from `config.h`, which lets the Android app join a new Atlas without asking.
The default is never written to NVS, so a factory reset returns to it. Boot
logs `ATLAS|WIFI_AP|PASSWORD_STORE|DEFAULT` or `|LOADED`, and the portal shows
"Factory default (change it)" while it is in use.

## Serial log and browser download

Atlas writes pipe-separated `ATLAS|...` lines to USB serial (115200 baud)
through `TurnHub::serialLog`. The same output goes to an 8 KB RAM ring, each
line stamped with uptime (`[     12.345]`), and is drained to the microSD card
when one is present ([SD diagnostics](../Documentation/engineering/DIAGNOSTICS.md)).
A Developer can download the RAM log from the Developer page (`/dev`) or:

```text
GET /api/diagnostics/log     (X-TurnHub-Token; Developer permission)
```

The file starts with the Atlas ID, boot ID, firmware version and uptime, and
says how many bytes were dropped. Secrets are redacted (`printlnRedacted`).
Framework messages (`log_e`, ESP-IDF) bypass the Atlas log and are not captured.

Lines that make a log readable on its own:

```text
ATLAS|GAME|START|<starter>|PROFILE|<generic|mtg|mtg_commander|yugioh>|LIFE|<n>|TIMER_MS|<0=off>|PLAYERS|<n>
ATLAS|LOBBY|JOIN|BROWSER|<controller>|PLAYER|<n>|PROFILE|<profileId>
ATLAS|LOBBY|LEAVE|BROWSER|<controller>|SLOT|<1|2>|PROFILE|<profileId>
ATLAS|LOBBY|EMPTY|RESET|ORIGIN|<SIGIL|BROWSER|SYSTEM|...>[|CONTROLLER|<id>]|FROM|<state>
ATLAS|TIMER|<WARNING|EXPIRED>|PLAYER|<n>
```

Browser and phone seats use controller IDs from 8 upward (shown as "Sigil 8A"
in `GAME|START`).

## Build, flash and test

From `Atlas/`:

```text
pio run -e atlas
pio run -e atlas --target upload --upload-port COMx
pio device monitor
```

Find the port each time (Atlas is the CH340 port); never hard-code it. Signed
local builds, the one-button `tools\flash-all.cmd` (run `tools\setup-boards.cmd`
first on a new PC or with new boards) and OTA updates are
described in the repository's `CLAUDE.md` and in
[Sigil OTA](../Documentation/engineering/FIRMWARE_UPDATES.md). The portal is at
`192.168.4.1`.

Host regression tests (no hardware) are in [`tests/host/`](tests/host/README.md).

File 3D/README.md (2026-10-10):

# TurnHub enclosure print files

Current prototype enclosure STLs for Atlas and both Sigil display variants,
uploaded on 2026-10-09. This upload is the first rough-fit enclosure generation;
`v1` (Atlas) and `v12` (Sigil) are the model revisions in the filenames.
These revision labels are separate from the electronics generation and firmware
version.

## Atlas: `atlas_enclosure_v1_print_set/`

Print one shell and one base plate. The logo inlay is a separate cosmetic part.

| File | Part | Mesh extents X × Y × Z* |
| --- | --- | --- |
| [atlas_shell_v1.stl](atlas_enclosure_v1_print_set/atlas_shell_v1.stl) | Main enclosure shell | 98.00 × 90.95 × 43.34 |
| [atlas_base_plate_v1.stl](atlas_enclosure_v1_print_set/atlas_base_plate_v1.stl) | Base plate | 98.00 × 80.00 × 8.00 |
| [atlas_shell_logo_inlay_v1.stl](atlas_enclosure_v1_print_set/atlas_shell_logo_inlay_v1.stl) | TurnHub logo inlay | 48.26 × 12.00 × 0.60 |

The [`tests/`](atlas_enclosure_v1_print_set/tests/) folder contains smaller pieces
for checking individual interfaces before committing to a full shell:

| File | Fit to check |
| --- | --- |
| [test_screen_face_v1.stl](atlas_enclosure_v1_print_set/tests/test_screen_face_v1.stl) | Display opening and screen seating |
| [test_sd_v1.stl](atlas_enclosure_v1_print_set/tests/test_sd_v1.stl) | microSD access |
| [test_speaker_v1.stl](atlas_enclosure_v1_print_set/tests/test_speaker_v1.stl) | Speaker fit and opening |
| [test_usb_v1.stl](atlas_enclosure_v1_print_set/tests/test_usb_v1.stl) | USB access and cable clearance |

## Sigil: `sigil_enclosure_v12_print_set/`

Both variants share the sloped shell and back plate. Print **one screen plate
matching the installed display**, plus the shared parts. The logo inlay is a
separate cosmetic part.

| File | Part | Mesh extents X × Y × Z* |
| --- | --- | --- |
| [sloped_shell_v12.stl](sigil_enclosure_v12_print_set/sloped_shell_v12.stl) | Shared enclosure shell | 64.00 × 167.28 × 73.70 |
| [back_plate_v12.stl](sigil_enclosure_v12_print_set/back_plate_v12.stl) | Shared back plate | 64.00 × 155.00 × 11.60 |
| [screen_plate_eink_v12.stl](sigil_enclosure_v12_print_set/screen_plate_eink_v12.stl) | E-ink screen plate | 48.40 × 81.80 × 8.20 |
| [screen_plate_oled_v12.stl](sigil_enclosure_v12_print_set/screen_plate_oled_v12.stl) | OLED screen plate | 48.40 × 78.40 × 9.40 |
| [sloped_shell_logo_inlay_v12.stl](sigil_enclosure_v12_print_set/sloped_shell_logo_inlay_v12.stl) | TurnHub logo inlay | 56.12 × 14.00 × 0.60 |

## Printing and fit checks

*Extents above are measured from the STL coordinates in their exported
orientation, rounded to two decimals. STL files contain no unit metadata;
import as millimeters and compare the displayed size with this table and the
actual hardware before slicing. These are bounding dimensions, not assembly
clearances or dimensions after slicer rotation.*

1. Start at 100% scale. Select a print orientation in the slicer and inspect
   overhangs, supports, thin features and the first layer. The exported axes do
   not prescribe a print orientation.
2. Print the Atlas fit-test pieces first and check them against the actual
   board, screen, speaker, card and USB cable.
3. Dry-fit the shell and plates with the intended hardware. Check display
   seating, connector access, wiring clearance, joystick travel and click,
   status-ring clearance, and access to BOOT/reset before final assembly.
4. Record the printer, material, nozzle, layer height, supports and any fit
   adjustments when evaluating a print. This upload includes STLs only;
   validated slicer settings, fastener specifications and editable CAD sources
   are not included.

**Sigil joystick orientation:** the owner reports rotating the stick 180° to
fit the case. That reverses both cardinal axes. After assembly, test Up, Down,
Left, Right and click with the installed firmware. The orientation correction
is tracked in [joystick PR #84](https://github.com/rickethyo/TurnHub/pull/84);
that build prints `SIGIL|JOYSTICK|ORIENTATION` at boot to identify the active
axis mapping. The owner verified correct joystick directions on both installed
Sigils on 2026-10-09.

These are rough-fit prototype models. Mesh inspection does not establish final
mechanical fit; keep print and assembly findings with the next model revision.

## Related references

- [Hardware, boards and pin maps](../Documentation/engineering/HARDWARE.md)
- [Sigil displays and hardware profiles](../Sigil/DISPLAY.md)
- [Sigil electrical drafts](../KiCad/PCB/Sigilv1/README.md)
- [Earlier Sigil PCB fit-test model](../KiCad/PCB/Sigilv1/case/sigil_fit_test.stl)
  — a separate PCB fit test, not part of these enclosure sets.

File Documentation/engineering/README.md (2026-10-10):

# TurnHub Engineering Reference

How TurnHub works today, one document per topic. Each describes current
behavior; dated findings and superseded plans live in [history/](history/README.md)
and are not kept up to date.

**Start with:** [Architectural Invariants](ARCHITECTURAL_INVARIANTS.md) (the
hard rules) and [Staged Changes](STAGED_CHANGES.md) (everything open). Then
read only the topic you're working on.

Cross-agent discussion and project-wide handoffs live in [`COLLABORATION.md`](../../COLLABORATION.md). Read it when starting work and update it when handing work back.

## Topics

| Document | Covers |
|---|---|
| [Architectural Invariants](ARCHITECTURAL_INVARIANTS.md) | Rules every change preserves: Atlas authority, one handler per action, the feature gate, accessibility |
| [Architecture](ARCHITECTURE.md) | Ownership, the Intent pipeline and the full Intent catalog |
| [Storage and Recovery](STORAGE_AND_RECOVERY.md) | Identities, every NVS and SD record, the microSD card, match recovery, completion ordering |
| [Radio Protocol](RADIO_PROTOCOL.md) | ESP-NOW packets, capability bits, menus, lights, Atlas lost |
| [Pairing and Secure Link](PAIRING_AND_SECURE_LINK.md) | Pairing with a code check, the BOOT button, forget, factory reset, sleep, link encryption |
| [Players and Accounts](PLAYERS_AND_ACCOUNTS.md) | Profiles, sign-in, joining from phones and Sigils, the picker, permissions, presence codes, moderation |
| [Gameplay](GAMEPLAY.md) | Game profiles, turns, turn timer, life and approvals, Commander damage, light and sound cues |
| [First-run Setup](FIRST_RUN_SETUP.md) | Guided setup of a new Atlas from the app or portal |
| [Firmware Updates](FIRMWARE_UPDATES.md) | `.thfw` packages, signing, releases, Sigil OTA, update notices, spare Sigils |
| [Web Portal](WEB_PORTAL.md) | The embedded admin portal, themes, layout and test contract |
| [Diagnostics](DIAGNOSTICS.md) | Serial, RAM and SD logs, tracing, and the multi-phone stability work |
| [Hardware](HARDWARE.md) | Atlas and Sigil boards, pins, the touchscreen, displays, controls, identifying and flashing boards |
| [Accessibility](ACCESSIBILITY.md) | Requirements and the implemented accessibility settings |
| [Continuous Integration](CONTINUOUS_INTEGRATION.md) | GitHub Actions checks, artifacts and local equivalents |
| [Planned Designs](PLANNED_DESIGNS.md) | Designs for features not built yet: venue model, Sigil sleep, front LED strip, shared SD cards |

Elsewhere: the HTTP client contract is [`protocol/http-v1.md`](../../protocol/http-v1.md);
Sigil screens and menus are [`Sigil/DISPLAY.md`](../../Sigil/DISPLAY.md); the
host test suites are [`Atlas/tests/host/README.md`](../../Atlas/tests/host/README.md);
the design system is [`design/README.md`](../../design/README.md); the Android
app is [`Android/README.md`](../../Android/README.md); dependencies and IP are
in [`Documentation/legal/`](../legal/README.md); build commands and
cross-file rules are in `CLAUDE.md`.

## Confidence labels

- **Verified:** confirmed by source, hardware, or a captured log.
- **Reconstructed:** strongly supported by history, not checked on the original hardware.
- **Planned:** agreed, not built.
- **Experimental:** existed during development, not necessarily the product.
- **Needs verification:** a placeholder, not authoritative.

Host tests passing is not hardware acceptance. As of 2026-10-02 the owner
reports that playtesting and bench testing verified nearly everything
built; the hardware checks still open are listed in
[Staged Changes](STAGED_CHANGES.md), "Open checks". Unlabelled statements in
these documents describe the code as it is.

## Keeping the record

- **One home per fact.** Put a fact in the topic document that owns it and
  link to it from elsewhere rather than repeating it. Keep documents about
  current behavior; don't narrate how a feature was built step by step
  (commit messages do that).
- **When something lands,** update its topic document in the same change and
  delete its line from Staged Changes. When a decision changes, rewrite the
  topic text; record the reason briefly if it matters ("owner, date").
- **Dated findings** (reviews, playtests, investigations) go in `history/` as
  `YYYY-MM-DD-<topic>.md`; lasting conclusions move into a topic document.
- **Feature gate.** Before a significant feature, define: (1) state owner,
  (2) Intent, (3) validator, (4) persistence owner, (5) rendering clients,
  (6) protocol/contract change, (7) third-party dependency impact (update
  `Documentation/legal/`), (8) accessibility impact. Put the answers in the
  topic document.
- **Structural changes:** review the invariants, Staged Changes and the
  affected topic first; if code would contradict the docs, resolve the docs
  explicitly.
- A changed user-facing interaction, cue, display or timeout gets an
  accessibility review, and the user manual, UI text and docs stay in
  agreement.
- Firmware-version bumps and large feature commits append a snapshot to
  [history/SIZE_AND_CHANGE_HISTORY.md](history/SIZE_AND_CHANGE_HISTORY.md).
- Never commit real board MAC addresses, keys, passwords or tokens.

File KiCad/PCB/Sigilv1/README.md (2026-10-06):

# Sigil Rev A electrical drafts

Rev A is drawn as two KiCad projects in this folder, plus `Sigil_JewelAdapter` (the status ring's small board, below). They share the symbol library (`Sigil.kicad_sym`) and differ only in the display interface:

| Project | Display | Display nets |
|---|---|---|
| `Sigil_EInk.kicad_pro` | Inland e-paper driver board (GxEPD2_213_B74), J2 `EPD_Module_Header` (8 pins) | EPD_SCLK, EPD_MOSI, EPD_CS, EPD_DC, EPD_RST, EPD_BUSY |
| `Sigil_OLED.kicad_pro` | Inland 1.3" OLED V2.0, J2 `OLED_Module_Header` (7 pins) | OLED_SCLK, OLED_MOSI, OLED_CS, OLED_DC, OLED_RST |

Both displays use the same sockets and GPIOs (A8/GPIO16 DC, A9/GPIO17 CS, A11/GPIO18 clock, A17/GPIO22 reset, A18/GPIO23 data); only the e-ink uses A14/GPIO21 BUSY. Both schematics also carry the buzzer interface J3 on J12/GPIO33, +3V3 from J19, and GND on A13, A19 and J6.

**Discrete LEDs and the old buttons are gone** (removed 2026-09-24). Their GPIOs are marked NC.

**Display-type strap (both, 2026-09-26).** A7/GPIO4 tells the firmware which display the board carries (`HW_TYPE_STRAP_PIN`, `Sigil/DISPLAY.md`): left NC on `Sigil_EInk` (the internal pull-up reads E-ink), tied to GND on `Sigil_OLED`. A build for the other display halts at boot, so a carrier with the wrong strap won't run.

**First-PCB footprints (2026-09-26).** Every carrier part now has a footprint and is in the BOM (through-hole except U2, SOT-23-5; U1 and the Jewel pins are local footprints in `Sigil.pretty`): J2 a 1x8 (E-ink) or 1x7 (OLED) 2.54 mm socket, J4 a JST-XH 5-pin socket for the joystick harness, J5 a JST-XH 3-pin socket for the Jewel adapter pigtail, J3 a 1x2 header for the buzzer leads, R1 an axial 0207 resistor, C2 a 10 uF ceramic on +3V3 beside the headers (5 mm disc footprint). *Planned*: footprints are chosen, no board is laid out.

**Joystick (both).** Both schematics carry J4, an unmarked 5-pin analog thumbstick that replaces the Pass/Action/Pause buttons: GND, "+5V" (fed **3.3 V**, never 5 V, since VRX/VRY swing to the supply and the ESP32 ADC is 3.3 V max), VRX to J15/GPIO34, VRY to J14/GPIO35 and SW to J13/GPIO32. VRX/VRY are ADC1 input-only pins because ADC2 is unusable under ESP-NOW. Firmware: the Sigil `sigil` and `sigil-oled` PlatformIO environments; the directions and click are the five menu keys. *Verified* on the owner's E-ink breadboard (2026-09-25): both axes read reversed as mounted, so the firmware inverts X and Y. The OLED Sigil's five pushbuttons (SW1-SW5) were replaced by the same stick on the same GPIOs on 2026-10-01 (owner); its mounting *Needs verification*.

**Status ring (both), on its own adapter board (2026-09-26).** The Adafruit NeoPixel Jewel 7 (RGBW) no longer sits on the Sigil board. `Sigil_JewelAdapter` is a small board with five pin holes where the Jewel's pads are (positions from Adafruit's [NeoJewel 7 board file](https://github.com/adafruit/Adafruit-NeoPixel-Jewel-7)): pins stand up from it and the Jewel is soldered on top, LEDs up, like it was on the breadboard. It carries C1 (470 uF bulk capacitor), the Jewel's two M2 mounting holes, an optional unfitted chain-out J3 (+5V, DOUT, GND) for more pixels after the Jewel, and J2, three holes for the bare end of a 3-wire JST-XH pigtail. The pigtail plugs into J5 on the Sigil board, a JST-XH 3-pin socket (1 +5V, 2 DIN, 3 GND, same order at both ends). On the Sigil board, GPIO26 (J10) goes through U2 and R1 (330 ohm, at the source; the Jewel has its own 470 ohm on DIN) to J5, and +5V comes from the DevKit's USB 5V (J1). Full RGBW draws about 560 mA, more than USB supplies, so the firmware caps brightness at 48/255. The ring draws the Sigil's status light from Atlas's LedState; the same information is always on a screen as text. *Verified* lit on the breadboard (owner, 2026-09-26); the adapter's pad positions are *Needs verification* (test-fit a Jewel against a 1:1 print).

**Front light output J6 (both, 2026-09-28).** A second JST-XH 3-pin socket for the possible player-facing strip on the case front lip (`STAGED_CHANGES.md`). It has its own data line rather than chaining off the Jewel adapter: the main board sits in the case base beside the front lip, while the Jewel is on the back wall. GPIO13 (socket J5; free on both boards and not a boot strap) goes through U3 (a second 74AHCT1G125, decoupled by C4) and R2 (330 ohm) to J6 pin 2; pinout as J5 (1 +5V, 2 DIN, 3 GND). J6, U3, R2 and C4 are fitted on every board (owner decision) so a strip can be added later without rework. Ring and strip share USB 5 V, so firmware must cap both (7 + 8 RGBW pixels at 48/255 is about 225 mA). No firmware drives GPIO13 yet. *Planned*.

The breadboard wiring the current firmware uses is in the [hardware reference](../../../Documentation/engineering/HARDWARE.md).

U1 is the removable, complete 38-pin ESP32 DevKit carrier interface (Inland ESP32-WROOM-32E, micro-USB, the narrow 38-pin format). Its custom symbol and local symbol library use **A1–A19 and J1–J19 as pin numbers**, not ESP32 module pad numbers. Its footprint, `Sigil.pretty/ESP32_DevKit_38_Socket_Row22.225mm` (from `build_schematic.py`), has 2.54 mm pitch and rows 22.225 mm (7/8 in) apart, and a 25.4 x 53.975 mm (1 x 2 1/8 in) outline that is not centred on the pins: the owner's breadboard fit (2026-09-28, first pins in row 1, USB end flush with the breadboard end, antenna end just reaching row 21) puts the USB end about 3.4 mm before A1/J1 and the antenna end about 4.86 mm past A19/J19. Row spacing, width, length and antenna size are the owner's ruler measurements (2026-09-28; 7/8 in rows, 1 in wide, antenna 1/4 in long from 1 7/8 in). An earlier breadboard fit suggested 22.86 mm (0.9 in), which conflicts by 0.635 mm. A 6.35 mm keep-out (no tracks, vias, pours or parts), 3/4 in wide so the pin rows stay routable, covers the WROOM-32E antenna at the A19/J19 end. It is drawn from the carrier's top side with the DevKit face up and micro-USB at the top, which mirrors the rear photo: the A row is on the left, the J row on the right, and A1/J1 at the USB end. *Needs verification*: caliper-check the row spacing and test-fit sockets before ordering. `Sigil_EInk.kicad_pcb` is routed (2026-09-28, Freerouting v2.4.1 plus a hand-placed BUZZER track, GND pours on both layers with solid pad connections); KiCad 10.0.6 CLI DRC reports 0 violations, 0 unconnected pads and 0 schematic parity issues. It is not fabrication-ready until U1 is test-fitted. The OLED PCB is still an empty placeholder.

## Authority and orientation

- GPIO functions: `Sigil/include/epaper_display.h` and the explicit SPI configuration in `Sigil/src/epaper_display.cpp` (e-ink), `Sigil/include/oled_config.h` (OLED), and `BUZZER_PIN` in `Sigil/src/main.cpp`.
- Socket identity: user-supplied [SigilBackMarked.png](reference/SigilBackMarked.png), photographed from the **BACK**, and the user's transcribed sequence. The schematics deliberately show J1 (5V) top-left and A1 (CLK) top-right in that rear-reference view.
- [The cross-check tables](CROSS_CHECK.md) are verified from both exported netlists and the firmware by `tools/verify_schematic.py`.

The rear-reference arrangement is **not** a carrier component-side footprint drawing. Future footprint work must translate the views explicitly and verify insertion against the physical part. Preserve each socket ID; do not blindly copy or mirror the schematic into a footprint.

This draft assumes power through the DevKit's own USB connector; J1/5V has no carrier connection. No additional regulator, USB-UART, BOOT, EN/reset, or other DevKit support circuitry is reproduced.

## Unresolved electrical details

- **Display J2 (both):** pin numbers follow the module's own header, pin 1 at the top, with the silkscreen labels as pin names. Order and the jumper wire color on each wire come from the owner's photos of the breadboard wiring (2026-09-24); the colors are annotations, not a harness specification. Tables are in [CROSS_CHECK.md](CROSS_CHECK.md). J2 has no footprint yet.
- **E-ink J2:** SDI, SCLK, CS, D/C, RES, BUSY, VCC, GND. The Inland driver board has two slide switches, P1 (3 / 0.47) and P2 (5VIN / 3.3VIN). J2 VCC is the DevKit 3.3 V rail (J19), so **P2 must be set to 3.3VIN** (owner decision, 2026-09-28: stay on 3.3 V; the board can take 5VIN but no supply jumper is added). The owner's working breadboard unit shows P2 on 3.3VIN and P1 on 3 (photo, 2026-09-28). Supply current and the panel itself need confirmation. The display has no carrier MISO connection.
- **OLED J2:** GND, VCC, CLK, MOSI, RES, DC, CS. The owner verified the SPI wiring, 3.3 V supply and a working image on 2026-09-24; the SH1106 controller and 128x64 geometry are inferred from the vendor example (see `Sigil/DISPLAY.md`).
- **Buzzer J3:** a logical SIG/GND interface only. Firmware proves GPIO33 tone output, but not whether the physical load is a passive piezo, magnetic transducer, or driven module. Confirm part, wiring, voltage/current, driver, bias and protection before implementing the load. No direct GPIO-drive rating is assumed.
- J3 is a plain 2-pin header (pin 1 SIG, pin 2 GND). **Locked 2026-09-28: a passive piezo**, driven directly by GPIO33 (no driver parts). A magnetic transducer was considered and rejected: louder, but it needs a transistor and flyback diode and draws 30-80 mA; a larger piezo disc is the fix if volume proves short.
- Confirm the DevKit regulator can supply the carrier/display load on +3V3 (the ring runs from USB 5 V).
- **Ring level shifter (2026-09-26):** 3.3 V data worked on the breadboard but is below the SK6812's ~3.5 V input spec, so the PCB adds U2, a 74AHCT1G125 (SOT-23-5) on +5V with C3 (100 nF): GPIO26 -> U2 -> R1 -> DIN (nets RING_DIN, RING_DIN_5V, RING_DIN_R).

## Mechanical release hold

No reliable dimensional drawing or measured dimensions were found in the repository. The photograph is sufficient for sequence and orientation, not mechanics. Measure or obtain a reliable drawing for:

- Actual pin pitch (likely 2.54 mm, not yet verified), row center spacing and pin locations.
- Exact board width/length, USB-C overhang and cable insertion envelope.
- Mounting-hole positions/diameters, if used.
- Female socket dimensions/height, insertion depth, underside and component keepouts.
- BOOT and EN/reset access plus antenna clearance requirements for the exact installed DevKit.

Use two 1x19 female socket rows so the complete DevKit remains removable. The eventual silkscreen must make A1/J1 and insertion orientation obvious. Keep USB-C accessible for flashing/debugging and leave BOOT and EN/reset operable. **No fabrication-ready DevKit footprint exists in this revision.**

## Validation and editing

KiCad 10.0.6 CLI ERC on both schematics: **0 violations**, without ERC exclusions (2026-09-24). After the 2026-09-26 changes (including the U1 rows and antenna keep-out), KiCad 10.0.6 CLI ERC on all three schematics: **0 violations**, and `verify_schematic.py` passes on KiCad-exported netlists. The files stay in the builder's compact form until KiCad re-saves them. Exported netlist checks verify all 38 socket names, the display and buzzer GPIOs against firmware, each display header pin's number, label and net, power and ground positions, that only U1/J2/J3 are present, and that every other socket is NC. Rendered schematics were visually reviewed. These checks do not resolve the electrical or mechanical holds above.

`tools/build_schematic.py` rebuilds both schematics and the symbol library deterministically. When `kicad-cli` is on PATH it then re-saves each file with `kicad-cli sch upgrade --force`, so the output matches what the KiCad editor writes (pin UUIDs are deterministic too). It overwrites both schematics and the library; do not rerun it after manual edits unless those edits have been incorporated into the script. Close the projects in KiCad first, or reload from disk afterwards, so an open copy does not overwrite the rebuild.

To validate, export each netlist and run the verifier; it refreshes CROSS_CHECK.md only after both pass:

```sh
kicad-cli sch export netlist --format kicadxml -o eink.xml Sigil_EInk.kicad_sch
kicad-cli sch export netlist --format kicadxml -o oled.xml Sigil_OLED.kicad_sch
kicad-cli sch export netlist --format kicadxml -o adapter.xml Sigil_JewelAdapter.kicad_sch
python tools/verify_schematic.py eink.xml oled.xml adapter.xml
```

Without KiCad, `python tools/offline_netlist.py Sigil_EInk.kicad_sch eink.xml` (and the same for OLED) writes an equivalent netlist from the generated files. It only understands what `build_schematic.py` writes and is not ERC.

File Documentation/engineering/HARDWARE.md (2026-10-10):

# Hardware: Boards, Pins, Screens and Flashing

The current Generation 2 prototype hardware and the tools that flash it.
Earlier generations are in [Generation History](history/GENERATION_HISTORY.md).
The Sigil carrier PCB is in `KiCad/PCB/Sigilv1/`; Sigil screen layouts and
menus are in `Sigil/DISPLAY.md`.

Pin maps are in daily use and the owner reports them verified through
playtesting and bench testing (2026-10-02).

## Hardware development direction (owner, 2026-10-10)

Current ESP32 DevKit e-paper and OLED Sigil feature development is frozen.
Their accepted firmware, radio contract and 16-pixel preset assets remain the
baseline. New screen work targets planned ESP32-S3 LCD hardware with 2.8-inch
and 4-inch displays. Board/panel selection, GPIOs, orientation, exact display
resolution, PSRAM, power budget and the new screen layouts are still to be
confirmed; neither S3 firmware target exists yet.

Player artwork begins independently of those ports: vector defaults, 64-pixel
Atlas alpha masks, and square JPEG masters up to 512 pixels/48 KiB stored on
Atlas's SD card. Android previews provisional 64/128-pixel icon slots for the
2.8/4-inch layouts. Inch size does not determine pixel resolution. Today's
Atlas renders a small approved RGB332 thumbnail in its existing 16-pixel slot;
future layouts consume the master rather than enlarging that thumbnail.

## Atlas: LCDwiki E32R28T

2.8" ESP32-32E display module (resistive touch): ESP32 N4, 4 MB flash, no
PSRAM, **CH340C** USB bridge (Sigils use CP210x), ILI9341V 240x320 TFT,
XPT2046 touch, microSD slot, common-anode RGB LED, speaker amplifier, battery
connector and charger (see "Atlas battery" below), RESET and BOOT buttons.

PlatformIO `Atlas/platformio.ini`: `esp32dev`, Arduino, 115200 baud,
`min_spiffs.csv` (two 1.9 MB OTA app slots, NVS at `0x9000`; a new partition
table needs one USB upload), LovyanGFX.

| Function | GPIO | Notes |
|---|---:|---|
| TFT SCK / MOSI / MISO | 14 / 13 / 12 | HSPI, display only |
| TFT CS / DC | 15 / 2 | Reset is the shared EN line |
| TFT backlight | 21 | Active high, PWM |
| Touch SCK / MOSI / MISO | 25 / 32 / 39 | XPT2046, bit-banged (HSPI is the TFT's, VSPI the card's) |
| Touch CS / IRQ | 33 / 36 | Active low; IRQ also wakes Atlas from sleep |
| microSD SCK / MOSI / MISO / CS | 18 / 23 / 19 / 5 | VSPI at 4 MHz, FAT32, never formatted by Atlas |
| RGB LED red / green / blue | 22 / 16 / 17 | Active low. Red blinks 250/250 ms while pairing; blue blinks while an update is available |
| Speaker amp enable | 4 | Active low, on only while a chime sounds (+250 ms) |
| Speaker audio | 26 | DAC 2 streamed by I2S0 (`atlas_speaker.cpp`) |
| Battery ADC | 34 | Cell voltage through the board's divider (halved); `atlas_battery.cpp` |
| BOOT | 0 | Pair / unpair all / factory reset (quick, 3 s, 10 s); never a game action |

There is no master button (2026-09-24): game controls are on the touchscreen.

### Atlas battery

*Experimental* (2026-10-08). A single-cell LiPo on the board's battery
connector (the first one tried: a 502030 pouch, 250 mAh, with its own
protection board) is charged by the on-board charger from USB. Atlas has no
fuel-gauge chip, so the charge is estimated from the cell voltage alone:
`atlas_battery.cpp` reads GPIO 34 four times a second (8 ADC reads averaged, the
ESP32's calibrated millivolts) and scales it by the divider ratio in
`config.h` (`BATTERY_DIVIDER_NUMERATOR` / `DENOMINATOR`, 2/1). The pure logic
in `battery_gauge.h` smooths their per-second average (an exponential average over about 16 s),
maps it through a LiPo discharge curve (flat through the middle, steep at both
ends, not linear), holds the shown percent until it moves 2 points, and
raises a low warning at 15 % that clears at 20 %. Below 2.5 V there is no cell.

Shown in: the touchscreen header (at the right, a phone-style cell icon and
the percent, the Sigil count having moved to the header's middle; the icon
fills red and a red **LOW BATTERY** pill appears while low; a lightning bolt
over it while charging, gone once full at 100%) and Menu > Info ("SD card: ready, battery 82%",
", charging" added when it fits), the portal's Atlas line under Devices, the
basic portal, and `GET /api/devices` (`atlas.battery`: `percent`,
`millivolts`, `low`, `charging`, or `null` with no cell). Each 5-point
change, and each start or end of charging, is logged as
`ATLAS|BATTERY|<mV>|<percent>` (`|LOW`, `|CHARGING`) for checking the curve
against a timed discharge.

**Charging** (2026-10-08). The charger is a TP4054 (the schematic's U6; the
fitted part is marked LTH7, the LTC4054 equivalent): 4.2 V, stopping on its
own as the current tapers, at about 300 mA set by R27 (3.3 kOhm on PROG,
1000 V / R). An SL2305 MOSFET runs the board from USB while it is plugged in,
so all of that current goes into the cell. 300 mA is 1.2 C for the 250 mAh
cell, above the 0.5-1 C most small pouches are rated to charge at; R27 at
6.8 kOhm (about 150 mA) or 10 kOhm (about 100 mA), or a cell of 500 mAh or
more, would be gentler. `BATTERY_CAPACITY_MAH` and `BATTERY_CHARGE_MA` in
`battery_gauge.h` must follow either change.

Plugged in, the reading is the charger's, not the cell's: the cell plus the
charge current through its resistance (about 210 mV on the bench), then a
flat 4.21 V at the charger's limit, and a flat 4.10 V once it has stopped
(measured 2026-10-08). Read through the curve that is "full" at once (it
jumped 60 % to 100 %). So while charging the percent is counted instead: it
starts from the last on-battery percent, never falls, and climbs one point
per 30 s (300 mA into 250 mAh), stopping at 90 % until the reading has held
steady at 4.08 V or more for 4 minutes (the charger's limit; climbing to it,
the reading rises 30 mV or more in that time). Then it climbs one point a
minute and shows 100 % only after 20 minutes there. Started on USB, with no
on-battery percent, it takes the cell as 210 mV below the reading, and as at
least 85 % once at the limit. Unplugged, it reads the curve again. Checked on
the bench (unplug, replug: the percent held and crept up with the bolt
showing); the counted rate is *Needs verification* against a timed charge.

**Screen off on battery** (2026-10-08). The cell is a backup that keeps the
game, the radio and the portal running through a pulled cable, not a power
source for play (it lasts minutes under Atlas's load), so on battery the
backlight, Atlas's biggest load, is off; it comes back on with USB. A touch
lights it for 15 s after the last touch (that first press presses nothing).
Nothing essential is lost while it is dark: the Sigils and the portal carry
all game state (`ACCESSIBILITY.md`).

The board has no USB-sense pin, so `PowerSourceTracker` (`battery_gauge.h`)
reads the power source from the raw samples. Measured on the 502030 with a
temporary probe (2026-10-08, four samples a second, two pulls and replugs):
pulling USB dropped the reading 220-240 mV within one sample (4.10 V to
3.83-3.87 V), plugging it back raised it 200-220 mV, sample noise stayed
within about 30 mV, and on the cell alone it fell about 100 mV in 45 s. So a
sample 100 mV below the highest of the last second is USB pulled, and 100 mV
above the lowest is USB back. Atlas starts as if on USB (screen on); if it
was started on the cell, a steady 60 mV fall within a minute (which the
charger never allows) switches it to battery, in about 20 s on the measured
trace, and a steady 60 mV rise switches it back. With no cell it is always
USB. Changes are logged as `ATLAS|POWER|BATTERY` / `ATLAS|POWER|USB`, and the
charge estimate restarts from the new level.

**Auto sleep on battery** (2026-10-08, owner: keep the cell from running
flat). On the cell, Atlas goes into the menu's deep sleep by itself
(`serviceAutoSleep`, `table_intents.cpp`; a System-origin `Sleep` Intent):
- between games, after `BATTERY_IDLE_SLEEP_MS` (5 min) with no player action:
  any Intent from a Sigil, phone or the touchscreen, or a touch;
- at any time, once the shown charge has stayed at or below
  `BATTERY_EMPTY_PERCENT` (3%, about 3.58 V under load) for 30 s. Mid-game
  the interrupted-match record brings the game back paused. A touch or BOOT
  doesn't wake an empty Atlas; only USB does.

On USB it never sleeps by itself, and an update, Sigil update or factory reset
under way holds it off. Asleep on the cell, the RTC timer wakes the chip 5 s
after it sleeps (the resting-cell reading) and then each minute
(`stayAsleepWithoutUsb`, `atlas_display.cpp`, before anything else in
`setup()`): a reading 80 mV over the last one, or 4.15 V and up, is the
charger, so Atlas starts; otherwise it is back asleep within a few
milliseconds. Deep sleep still leaves the board's regulator, CH340 and
power LED drawing a few mA, so a sleeping Atlas still drains the cell, only
far slower; the cell's protection board is the last stop.

*Needs verification:*
- Auto sleep's USB check: that plugging in raises the resting cell by more
  than `USB_STEP_MV` (80 mV), at any charge, and that noise never does.
- Sleep current on the cell, and how long a sleeping Atlas lasts.
- The divider ratio: compare the portal's voltage with a meter at the plug
  and correct `config.h` if they differ.
- The curve under Atlas's load (TFT backlight, Wi-Fi AP: roughly 1 C on a
  250 mAh cell), which sags the voltage so the estimate reads low.
- With USB in and no cell the charger output can look like a full battery.
  The board has no charge-status or USB-sense pin, so Atlas can't tell these
  apart from voltage alone.
- When the cell is too low for the 3.3 V regulator; the curve's 0 % (3.45 V)
  may need raising so Atlas warns before it browns out.

### Device theme choices

Each device owns its appearance independently. Atlas uses Menu > Device >
Theme to select a named theme; each Sigil uses Menu > Device > Theme to cycle
Graphite, Daylight, Brass and High contrast. The current Sigil theme is shown
in the OLED row and e-paper Device subtitle. Its menu stays open after a theme
tap. Local device menus also work while unpaired or Atlas is unreachable.
The joystick hold for pairing applies only outside the open device menu.

Choices are saved in the device's `display` NVS namespace (`theme`), preserved
by unpairing and cleared by factory reset. Missing/invalid choices use Graphite
on Atlas/OLED and Daylight on e-paper; failed writes retain the old theme.
Rendering consumes the new choice on the existing display task, and e-paper
invalidates its cache and partial-refresh frame so the first redraw is full.
No theme packets or new game state are introduced.

OLED Daylight uses dark ink on a light ground. Graphite, Brass and High contrast
use light ink on dark. E-paper keeps black ink on white in all themes: the
modern palettes converge on their one-bit typography and simple cards, Brass
keeps the serif/ornament family, and High contrast adds a second banner frame.
Monochrome panels cannot reproduce the color palettes or translucent surfaces.
Inter digits use equal advances; measured fallbacks preserve long names and
large/signed life totals. All status meanings remain in words and shapes.
Physical-panel readability, OLED current and e-paper ghosting need device
acceptance; host previews demonstrate source rendering only.

### Atlas touchscreen

Landscape, rotation 3. A 2 s splash, then the status screen in the selected
Graphite (default), Daylight, Brass or High contrast theme (`atlas_art.cpp`).
`design/tokens.json` generates RGB888 roles in `shared/include/device_theme.h`;
the TFT displays them at RGB565. Modern themes use Inter bitmaps from
`tools/fonts/make_modern_fonts.py`; Brass keeps Cinzel and Oswald from
`tools/fonts/make_fonts.py`. Modern themes use flat surfaces, an outlined turn
clock and teal turn emphasis; Brass retains its plates, gears and gauge.

- **Header:** state (LOBBY, STARTING, PLAYING, PAUSED, GAME OVER or the open
  screen), Sigils online, a red **NO SD CARD** pill, round and match time,
  and "Update available" when it applies.
- **Hero:** whose turn it is, a detail line (pairing countdown, pending pass,
  whom a claim waits on), and a turn clock: time left with a gauge and
  countdown tube, or elapsed time with the timer off.
- **Chips:** one per player (up to 8): name, life, the player's total turn
  time, and a tag in words (TURN, OUT, WINNER, STARTS, CONFIRM).

| State | Buttons |
|---|---|
| Lobby | Start (two or more players), Clear (hold), Menu. Tap a chip for the Player screen: Earlier/Later, Remove (hold 2 s) and the B side |
| Menu (between games) | Pair a Sigil (lobby), QR codes, Info, Device, Back |
| Device (between games) | Theme, Unpair Sigils (hold 3 s), Factory reset (hold 10 s), Sleep |
| Theme | Graphite, Daylight, Brass, High contrast, Back; the selected theme is framed |
| Starting | Cancel start |
| Running / Paused | Pause or Resume, Table. Tap a chip for the Player screen (-5/-1/+1/+5, Concede) |
| Table screen | Master pass (hold 2 s, running), End match (hold 5 s), Back |
| Game over | Rematch, Reset, Menu |
| Presence code / pairing code | The six-digit code and QR with Cancel; or Pair Sigil N with the code, Codes match, Reject |
| Setup | Welcome or "You're all set" ([First-run Setup](FIRST_RUN_SETUP.md)) |

Buttons are at least 60 px tall; holds say "hold", count down in words and
fill a bar. Taps act on release inside the button; a press may drift 12 px
(`TOUCH_SLOP_PX`) and contact gaps under 60 ms count as one press. Every
button dispatches an Intent with `IntentOrigin::AtlasHardware`
(`touch_controls.cpp`, host-tested); screens like Info and QR codes change no
state. The display redraws only regions whose part of the screen model
changed; `bash Atlas/tests/host/render-atlas-screens.sh` renders it to PNGs
and checks that incremental redraws match full ones.

**Calibration.** With nothing valid saved, a 4-point calibration runs after
the splash. Hold anywhere for 10 s in the lobby to recalibrate. Saved in
`atlas-touch/cal2`; `config.h` values are only the fallback. The XPT2046 is
sampled while the clock is high, with the first conversion dropped and a
median of three (the 2026-09-25 fix for misplaced touches).

**Speaker.** A small chime synthesizer on core 0 (22.05 kHz, up to four
voices, pentatonic, soft clip). Volume Off/Low/Medium/High (`spkvol`,
Admin). Loudness and tone on the real speaker are *Needs verification*.

## Sigils: ESP32 DevKit

Both Sigil types use a 38-pin ESP32-WROOM-32E DevKit (**CP210x**; the CP2102
reports serial `0001`, so connect two at a time if Windows misses one), the
same thumbstick, the NeoPixel Jewel 7 ring and a passive buzzer. Only the
display differs. Flash: `esp32dev` default partitions (two 1.25 MB app
slots).

| Function | GPIO | Notes |
|---|---:|---|
| Thumbstick X / Y / click | 34 / 35 / 32 | Directions are Up/Down/Left/Right, click is Select. Click (and BOOT) wake from sleep |
| Jewel 7 RGBW ring data | 26 | Via 330 Ω; powered from USB 5 V. The only status light |
| Buzzer | 33 | Passive piezo |
| Pair | 0 | DevKit BOOT button: quick press pairs, 3 s unpairs, 10 s factory resets |
| Display strap | 4 | Open = e-ink, wired to GND = OLED. A build for the wrong display halts at boot. On a bare DevKit, jumper `IO4` to `GND` for OLED (`A7` on the carrier) |
| Display SPI SCLK / MOSI / CS / DC / RST | 18 / 23 / 17 / 16 / 22 | Shared by both displays |
| E-ink BUSY | 21 | E-ink only; GPIO19 is detached from SPI MISO |
| Front LED strip (reserved) | 13 | J6 on the Rev A carrier, unused ([Planned Designs](PLANNED_DESIGNS.md)) |

- **E-ink Sigil** (`sigil`): 2.13" GDEM0213B74 (SSD1680) via
  `GxEPD2_213_B74`, portrait 122x250, rotation 0. Partial refresh with
  periodic full clean-ups; a trial with a driver-loaded waveform is on the
  bench (`Sigil/DISPLAY.md`).
- **OLED Sigil** (`sigil-oled`): Inland 1.3" 128x64 SH1106 over 4-wire SPI at
  3.3 V.
- **Wokwi** (`sigil-wokwi`) keeps an RGB LED on 27/14/13 and a Pair
  pushbutton on GPIO19; see `Sigil/WOKWI.md`.
- **Spare** (`sigil-spare`): inert image for either board
  ([Firmware Updates](FIRMWARE_UPDATES.md)).

**Controls** (one rule set since Sigil 0.9.10; details in `Sigil/DISPLAY.md`,
"Menus"): the click is the obvious next step (Join, Start, Pass, Undo pass,
Resume, Rematch, Confirm); Left/Right change life in a game (seat B and next
starter in the lobby, answers in a decision); Down switches seat on a shared
Sigil; Up always opens **Menu** with every other action, then Device (Sleep,
Unpair, Factory reset, Theme). The OLED shows Menu as a scrolling list, the e-ink as
compass pages. Holds use the seated players' times: long press 2 s default
(1-4 s), win hold 5 s (3-10 s, at least 1 s longer); the ring fills while
held. An unpaired Sigil also opens pairing with a 3 s click hold.

## Identifying and flashing boards

Never hard-code COM numbers; they change whenever the PC restarts. Boards are
identified by factory MAC:

```
pio pkg exec -p tool-esptoolpy -- esptool.py --port COMx read_mac
```

(Reading the MAC resets the board.) Each PC keeps its own list in the
git-ignored `tools\boards.local.md`; never put real boards in a committed
file. `tools\setup-boards.cmd` writes it: it reads each attached board's MAC,
suggests a type (CH340 = Atlas; a Sigil running TurnHub firmware reports its
strap as `SIGIL|HW|EINK` or `SIGIL|HW|OLED`), blinks the board in question
white for 10 s (the serial `identify` command), and lets you rename, retype,
make spare, return to service or delete (erases an attached board's flash).

The list's format, with made-up MACs (`02:` is locally administered, so no
real board has one):

| Board | Firmware | USB bridge | MAC | Notes |
|---|---|---|---|---|
| Atlas | `atlas` | CH340 | `02:00:00:00:00:01` | E32R28T; its MAC is its `THA-` ID |
| E-ink Sigil | `sigil` | CP210x | `02:00:00:00:00:02` | GPIO4 open |
| OLED Sigil | `sigil-oled` | CP210x | `02:00:00:00:00:03` | GPIO4 to GND |

`atlas`, `sigil` and `sigil-oled` are flashed; `spare` or
`spare:<firmware>` gets the spare image; anything else (the retired
`harness`) is listed and never flashed. `tools\flash-all.cmd` and the
signing tools are described in `CLAUDE.md`.

## Rules and open items

- **Hardware stops at the hardware boundary.** GPIO numbers, polarity and
  driver quirks never reach game rules; hardware code turns physical input
  into semantic events. A PCB revision must be able to move a pin without
  touching the engine.
- **Revision names:** `PROTO-G2-ESP` for today's boards. Reserve
  `ATLAS-REV-A` / `SIGIL-REV-A` for the first reproducible schematic + BOM,
  not a breadboard that happens to work.
- **Open:** the Sigil carrier PCB layout, DRC and a test fit (the OLED PCB is
  a placeholder); power measurements (idle, radio, display, buzzer, capped
  LEDs, sleep) and USB supply behavior; Atlas battery runtime and calibration
  (above), final Atlas module, enclosure
  and docking decisions. Tracked in [Staged Changes](STAGED_CHANGES.md).

### Display inversion and header marks (2026-10-09)

Atlas 0.7.5 and Sigil 0.9.17 add a separate saved `display/inverted` bool.
On Atlas use Menu > Device > Theme > Invert: on/off; on either Sigil use
Device > Invert. Changing theme retains inversion, unpairing retains it and
factory reset clears it. Saves must succeed before the visible setting changes.
Atlas complements the RGB palette; Sigils swap foreground/background. Atlas
QR codes retain conventional black-on-white modules and quiet zones for scanning.
LED colors/preferences are independent. Each theme has a header emblem on all
three displays: diamond, sun, gear or boxed hourglass. Normal/inverted host
previews and firmware checks do not establish physical panel acceptance.

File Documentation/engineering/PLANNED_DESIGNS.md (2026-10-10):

# Planned Designs

Agreed designs for features not built yet, with their feature gates. The
short list of open work is [Staged Changes](STAGED_CHANGES.md); when one of
these is built, move what is true into its topic document and delete it here.

## SD cards across several Atlases (*Planned*, owner 2026-09-25)

A card records its owner Atlas. A card from another Atlas is offered as
**Game night** (its profiles, statistics and settings are usable here for
now; the card is not taken over) or **Merge in** (it becomes this Atlas's
data and card). Still to design: the same profile on both, whose PIN wins,
which statistics merge, and where game-night results are written. No
statistics rollback to NVS.

## Venue model: several games on one Atlas (*Planned*)

A venue Atlas runs more than one game at once. Profiles, statistics, pairing
and the portal stay shared; each game has its own lobby, engine and table
decisions. Owner decisions (2026-09-29):

- **Atlas speaker:** muted while more than one game is running. Cues then play
  only on Sigil buzzers and in browsers. With one game it behaves as today.
- **Atlas touchscreen:** shows one game at a time, with a "Game 1", "Game 2",
  ... selector. The selection is presentation state (Invariant 6), not a table
  decision.

Steps:

1. **Done 2026-09-29 (host-tested, firmware builds):** `GameTable` in
   `atlas_app.h` groups one game's `Lobby`, `GameEngine`, `ClientState` and
   table decisions.
2. **Done 2026-10-07 (*Experimental*, host-tested; Atlas 0.7.0, Sigil
   0.9.13, portal pack 1.3.0): two tables.** Defaults chosen: Game 1 and
   Game 2; everyone starts in Game 1.
   - *State owner:* each `GameTable`, plus `sigilTable[]` (the game an
     unseated Sigil goes to, RAM) and each web session's `table` (the game a
     phone follows, RAM). Next-game settings are per table; the last saved
     ones are both tables' settings after a boot.
   - *Routing:* code reaches its game through `table()`, set by a
     `TableScope`. Sigil handlers scope to `tableForController` (the table
     whose lobby or game holds the Sigil, else its chosen one); HTTP routes
     and `/api/status` scope to `TurnHubWebApi::requestGame` (a tablet's
     chosen game, else the profile's game, else the followed game, else
     `?game=N` without a session); `loop()` ticks each table. Controller IDs
     stay global, so a Sigil (with its seat B), a phone controller and a
     profile each sit at one table at a time.
   - *Intent:* `ChooseTable` (a Sigil's menu item "Switch game",
     `SigilAction::SwitchTable`): offered outside that Sigil's game; it leaves
     its lobby first. Phones switch with `POST /api/session/game`, which
     leaves a lobby through the usual LeaveProfile Intent and refuses a
     profile in a game.
   - *Device-wide gates:* OTA, Sigil updates, Atlas factory reset, sleep and
     setup need both games between games; forgetting or factory-resetting a
     Sigil refuses one seated at either table. Pairing follows Game 1, the
     game the Atlas screen shows. Resetting a game frees only its own
     controllers.
   - *Persistence:* each table has its own recovery record in `th_game_v1`
     (`checkpoint`, `checkpoint2`), both restored paused at boot; the
     checkpoint-before-statistics order holds per table.
   - *Contract:* `/api/v1/state` and `/api/status` add `game` and `games`;
     `revision` is one counter for both games ([HTTP v1](../../protocol/http-v1.md)).
   - *Clients:* the portal shows a Game 1 / Game 2 switch; Sigils show
     "Switch game". *Speaker:* quiet while both games are in progress.
   - *Accessibility:* the switch names each game and its state in words.
3. Atlas touchscreen game selector (presentation state, Invariant 6), so the
   screen, pairing and turn order can serve Game 2; the tablet page's switch.
4. Android app game switch; then update the user manual (V0.12 section 19
   describes round one).

## Sigil sleep (*Planned*)

*Shipped meanwhile (2026-10-02):* a manual **Sleep** in the Sigil device menu
and on Atlas's Menu > Device screen, using deep sleep and a pin wake (see
[Pairing and Secure Link](PAIRING_AND_SECURE_LINK.md), "Sleep"), and
(2026-10-08) the same deep sleep chosen by itself: a Sigil idle outside a game
or without Atlas, Atlas idle or empty on its battery. The Atlas-managed light
sleep below, which may sleep a seated player's Sigil mid-game, is still
planned.

Owner, 2026-09-30: after 5 to 10 minutes with no physical input, a Sigil
sleeps and mostly drops off the radio until its buttons are pressed or Atlas
wants it. Mainly for future battery power (Atlas's battery connector, charger
and battery ADC on GPIO 34 now give a charge estimate, see the hardware
doc), and also for fewer active radio devices in a large game where
people play from phones. A seated player's Sigil may sleep mid-game; Atlas
wakes it when it's needed.

**The radio constraint.** An ESP32 has no wake-on-radio: with the radio off a
Sigil can't hear Atlas. So "Atlas sends a wake" is a duty cycle. The Sigil
light-sleeps (RAM kept, radio and CPU off) and wakes every few seconds (3 to
5 s, to tune) to send one check-in and listen briefly. Atlas answers a
sleeping Sigil's check-in with Wake or Stay asleep. ESP-NOW doesn't buffer
frames for sleeping peers, so Atlas only ever answers in that window. Worst
wake latency is one check-in interval. Deep sleep (lower current, but a
reboot and reconnect on every wake, and no Atlas wake at all) is a later
option for a battery Sigil left unused for hours.

**Wake sources.**
- Buttons: light sleep can wake on any GPIO. Both Sigils: the stick click
  (GPIO 32) and BOOT; the analog directions (GPIO 34 and 35) can't wake it,
  so the Sigil screen says "Press the stick to wake".
- Atlas: at a check-in, when the Sigil's player becomes active (their turn, or
  a pass, win claim, elimination or life request that involves them), when a
  game starts or is armed, when pairing or an update targets it, and from the
  portal/app device list ("Wake").
- The press that wakes a Sigil only wakes it (the screen shows "Awake"); it
  is not also sent as input, so a sleeping Sigil never passes a turn by
  accident.

**Rules (Atlas owns them).**
- Never sleep while the Sigil's player is the active player, during a
  countdown, with a decision pending on that player, during an update, or
  while pairing.
- Timeout (owner, 2026-09-30): short outside a game, about 3 minutes in the
  lobby or with the Sigil unseated, and at least 10 minutes while a game is
  running (someone may go a long while between their own turns). Atlas
  picks which applies and sends it to Sigils like the input timing, so the
  Sigil's idle timer changes when a game starts or ends. Admins can
  lengthen either or turn sleep off; the in-game value never goes below 10
  minutes. Atlas can refuse a sleep request (answer Wake) if a rule above
  applies.
- A sleeping Sigil is **Asleep**, not **Offline**: its seat, participant and
  statistics are untouched, and it stays out of the "controller lost"
  handling. Asleep that stops checking in for longer than the link timeout
  plus one interval becomes Offline as today.

**Feature gate.**
1. **State owner:** Atlas (`SigilBus` keeps Awake/Asleep per Sigil, from the
   radio; the timeout is a game setting). The Sigil owns only its own idle
   timer.
2. **Intent:** none for the radio handshake (transport state, like Hello).
   Admin setting change: the existing settings Intent path. Portal/app
   "Wake": a new `WakeSigil` Intent (validator: Admin or the seated player).
3. **Validator:** Atlas answers each sleep request by the rules above.
4. **Persistence:** the two timeouts (out of game, in game) in
   `game_settings_store` (NVS); sleep state is RAM-only.
5. **Rendering clients:** Sigil screens ("Asleep", "Press ... to wake");
   Atlas touchscreen and portal/app device list show Asleep; `/api/devices`
   gains `asleep`.
6. **Protocol/contract:** `shared/include/protocol.h`: new packet types
   (SleepRequest, CheckIn, WakeDecision) and a capability for "can sleep",
   taking one of the bits freed by the baseline Sigil (0x01, 0x02, 0x04, 0x08,
   0x20), read through `helloCapabilities()` from the firmware that
   introduces it. Reflash Atlas and every Sigil; a good first update to
   deliver over Wi-Fi OTA rather than USB. `/api/devices` and the Android
   `DeviceInfo` model add the field.
7. **Third-party dependencies:** none (ESP-IDF light sleep in the Arduino
   core).
8. **Accessibility:** the wake-up press must not also act, so a player who
   can't see the screen never passes by accident. Sleep can't hide a cue: a
   Sigil whose player has a pending cue (turn, request) is woken first, and
   the cue plays on waking, not only by LED or buzzer while asleep. A
   per-player accessibility preference "Never sleep my Sigil" (like the hold
   timings) for players who rely on its LEDs/buzzer between turns.

**Open questions.** Exact defaults (about 3 and 10 minutes above); whether the e-paper keeps its last
image or shows an "Asleep" card (e-paper holds either with no power); LED ring
behavior (off while asleep); measured current in light sleep versus today
(ties into check H03); how long a battery lasts either way.

## Sigil: required player-facing LEDs

*Planned, required* (owner, 2026-10-09; supersedes the conditional
2026-09-26 decision). Player-facing LEDs are required; confirm the implementation
for both display variants. The enclosure concept is a 45° wedge
about 48 mm wide, 78 mm deep and 78 mm tall: portrait e-paper on the upper
slope, joystick below it, main board flat in the base, USB through the back
wall. In that shape the Jewel 7 status ring faces the **other players** from the
back wall, so the seated player can't see it. A short LED strip on the front lip
gives the **player** their own light. Case revisions must retain visible
player-facing cues. Exact position and pixel count remain hardware decisions.

- **Hardware:** reserved on Sigil Rev A (2026-09-28): J6, a JST-XH 3-pin
  socket fed by its own data line, GPIO13 through U3 (74AHCT1G125) and R2, same
  pinout as J5. J6, U3, R2 and C4 are fitted on every board, so a strip can be
  added later without rework. A
  separate line suits the case better than the Jewel adapter's chain-out (the
  board is beside the front lip, the Jewel on the back wall) and gives the strip
  its own pixel chain. The chain-out stays as a fallback. Candidate: 6–8 SK6812
  RGBW pixels to match the Jewel's colour order.
- **Feature gate:**
  1. *State owner:* Atlas, unchanged. It already decides each Sigil's
     `LedState`; the Sigil only renders it.
  2. *Intent:* none. Lights are output only and add no gameplay action.
  3. *Validator:* none new. Any user setting (see 5) uses the existing
     accessibility preference path.
  4. *Persistence:* the pixel count is a build or hardware setting on the Sigil,
     not NVS. A per-player front-strip brightness, if added, belongs in the
     existing per-player accessibility preferences (`optional_preferences`).
  5. *Rendering:* the Sigil maps one `LedState` to two groups. The rear ring
     keeps today's table-facing role (turn state, player colour). The front strip
     shows the player's own cues (your turn, timer warnings, pending life
     approval). The exact split is an owner decision.
  6. *Protocol/contract:* probably none. If both groups are derived from
     `LedState` on the Sigil, `shared/include/protocol.h` doesn't change. A
     separate front-strip state from Atlas would be a radio contract change and
     need both firmwares reflashed.
  7. *Third-party dependencies:* none new (Adafruit NeoPixel already drives the
     Jewel).
  8. *Accessibility:* no information may live only on the strip; the e-paper
     repeats everything it shows. Brightness should be adjustable because the
     strip is a few centimetres from the player's eyes. Blink patterns follow
     the existing reduced-motion style (`LedStyle::ReducedMotion`).
- **Power:** USB can't supply full RGBW on 7 + 8 pixels. The firmware brightness
  cap (48/255) has to hold for the whole chain, and the front strip can run
  dimmer than the ring. *Needs verification:* measure current with both groups
  at the cap.
- **Before building:** settle the case (strip position, pixel count, cable
  route), then the owner's choice of which cues go front and which go rear.

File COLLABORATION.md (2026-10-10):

# Project-wide Codex / Claude collaboration

This is the permanent shared conversation and handoff document for **all of TurnHub**: Atlas, Sigils, Android, protocols, hardware, PCB and enclosure design, testing, releases, documentation, and product decisions. It is not limited to one feature or review.

Scope confirmed by project owner: 2026-10-08.

## Working agreement

- Persistent branch workflow adopted by the owner, 2026-10-09: Codex uses
  `codex/master`, Claude uses `claude/master`, and `agent/experimental` has one
  explicitly assigned owner at a time. `master` is the accepted baseline.
  See [Agent workflow](Documentation/engineering/AGENT_WORKFLOW.md) for the
  single source of branch, PR, merge and synchronization rules.

- Refer to the project owner by role, without their personal name, in document text and author metadata (owner, 2026-10-08).

- Read this document at the start of project work and fetch current Git state before editing. Read CLAUDE.md and relevant engineering references as well.
- Both Codex and Claude may add topics, ask questions, respond, record disagreements, and hand work to the other. Neither is assumed to have approved the other's proposal.
- Give each discussion a stable ID and title. Include date, author, reviewed commit, status, affected areas, evidence, next action, and any blocker.
- Append clearly attributed replies. Preserve the other agent's statements; explain corrections rather than silently rewriting them. Update the topic index as status changes.
- Before implementation, record the intended scope and current owner to reduce conflicting work. An ownership entry is coordination, not a lock; check branches and current work before editing overlapping files.
- Documentation-only updates should not run CI (project owner, 2026-10-08). Use `[skip ci]` in documentation-only commit messages; do not skip CI for code or mixed changes.
- Record implementation commits and actual validation results at handoff. Distinguish source review, host tests, and device acceptance. Never claim tests or hardware checks that did not happen.
- This document does not grant permissions or supersede project owner's directions. Follow the repository's feature gate and architectural rules.
- Git is the shared transport. Updating this file does not automatically notify or run either agent. project owner can ask either agent to read and reply here.

## One home per fact

This file owns cross-agent discussion and coordination. Accepted unfinished engineering work belongs in Documentation/engineering/STAGED_CHANGES.md. Current behavior belongs in the relevant topic document; user-facing changes belong in the manual. Link those sources rather than maintaining competing backlogs here.

Keep the topic index and active discussions here. When a discussion becomes long and closed, archive its detailed exchange under Documentation/engineering/history/ and retain a linked outcome here. Do not archive unresolved questions just to shorten the file.
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

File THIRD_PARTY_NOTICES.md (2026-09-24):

# TurnHub Third-Party Notices

TurnHub uses third-party open-source software and development tools. This file is the human-readable notice index for components currently known to the project.

This is a working development record, not a substitute for the complete license texts or a release-time legal review. Before any commercial hardware or software distribution, the dependency tracker in `Documentation/legal/DEPENDENCY_TRACKER.md` must be reviewed and the required upstream notices/license texts must be included with the distributed product.

## Current third-party software
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

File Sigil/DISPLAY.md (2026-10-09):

# Sigil display implementations

## Boundary and selection

`include/sigil_display.h` defines the `SigilDisplay` presentation interface:
`begin`, `showBooting`, `showUnpaired`, `showReady`, `setSeatName`, `showState`
and `showGame`. `src/sigil_display.cpp` returns a static implementation from
`getSigilDisplay()`. The existing display task calls that interface; it never
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

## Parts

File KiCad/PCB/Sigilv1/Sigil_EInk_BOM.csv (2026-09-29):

Refs | Value | Footprint | Qty | DNP
C2 | 10uF | Capacitor_THT:C_Disc_D5.0mm_W2.5mm_P5.00mm | 1
C3,C4 | 100nF | Capacitor_THT:C_Disc_D5.0mm_W2.5mm_P5.00mm | 2
J2 | INLAND E-PAPER HEADER (8-PIN) | Connector_JST:JST_XH_B8B-XH-A_1x08_P2.50mm_Vertical | 1
J3 | BUZZER 2-PIN HEADER | Connector_PinHeader_2.54mm:PinHeader_1x02_P2.54mm_Vertical | 1
J4 | ANALOG JOYSTICK HEADER (5-PIN) | Connector_JST:JST_XH_B5B-XH-A_1x05_P2.50mm_Vertical | 1
J5 | STATUS RING CABLE (JST-XH 3) | Connector_JST:JST_XH_B3B-XH-A_1x03_P2.50mm_Vertical | 1
J6 | FRONT LIGHT CABLE (JST-XH 3) | Connector_JST:JST_XH_B3B-XH-A_1x03_P2.50mm_Vertical | 1
R1,R2 | 330R | Resistor_THT:R_Axial_DIN0207_L6.3mm_D2.5mm_P7.62mm_Horizontal | 2
U1 | REMOVABLE ESP32 DEVKIT / 2 x 19 | Sigil:ESP32_DevKit_38_Socket_Row22.225mm | 1
U2,U3 | 74AHCT1G125 | Package_TO_SOT_SMD:SOT-23-5 | 2

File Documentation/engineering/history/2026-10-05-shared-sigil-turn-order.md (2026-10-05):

# Playtest: shared Sigil turn order (2026-10-05)

The Atlas order controls moved controllers rather than seats. In a four-player
table whose last Sigil held players 3 (A) and 4 (B), moving player 3 later was
rejected as already last. Seat B also needed a left/right choice to allow B/A
turn order.

## Feature gate

- Canonical state: Atlas `Lobby`, with an A/B order for each shared Sigil.
- Intents: `MoveSeat` swaps the pair when moving toward the other local seat;
  outside that pair it moves the whole controller. `SetSeatSide` explicitly
  chooses B before A (left) or B after A (right).
- Validator: the table intent handlers allow Atlas touchscreen requests in the
  lobby only, validate the target seat and require B for a side setting.
- Persistence: lobby RAM, retained for a rematch. The existing Atlas match
  checkpoint records the ordered physical seats; recovery accepts adjacent
  A/B and B/A pairs and reconstructs their order. No new NVS preference.
- Rendering: Atlas shows the player's actual position and the B side/order;
  Sigils render names, seat labels and avatars using physical seat identity.
  HTTP clients continue to receive ordered players and their physical slots.
- Shared contract: `DISPLAY_FLAG_PRIMARY_B` uses the retired host bit `0x10`.
  Atlas and Sigil firmware must be updated together; packet sizes stay the same.

## Controls and behavior

In the lobby, tap either player chip on a shared Sigil. Earlier/Later can swap
A/B. B left selects B before A; B right selects B after A. Both players remain
adjacent when their whole Sigil moves. The selected starter, participants,
profiles and seat bindings stay attached to their physical seats. Changing
order cancels a pending start arm. Removing B or emptying the table clears
that Sigil's side selection.

## Verification

Host scenarios exercise player 3 moving later in a four-player game, boundaries,
left/right controls, starter/participant preservation, unauthorized and invalid
requests, match turn progression, reversed-pair checkpoint restoration and
nonadjacent-pair rejection. OLED tests cover physical A with the higher player
number and B with the lower one. Hardware play testing is still required.

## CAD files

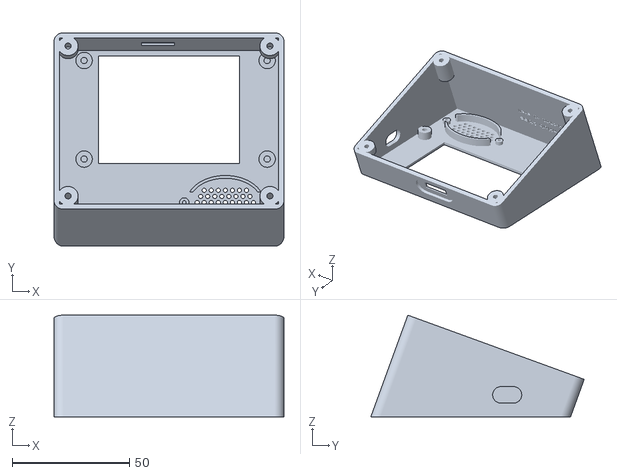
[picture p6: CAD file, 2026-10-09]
3D/atlas_enclosure_v1_print_set/atlas_shell_v1.stl
98.0 x 90.9 x 43.3

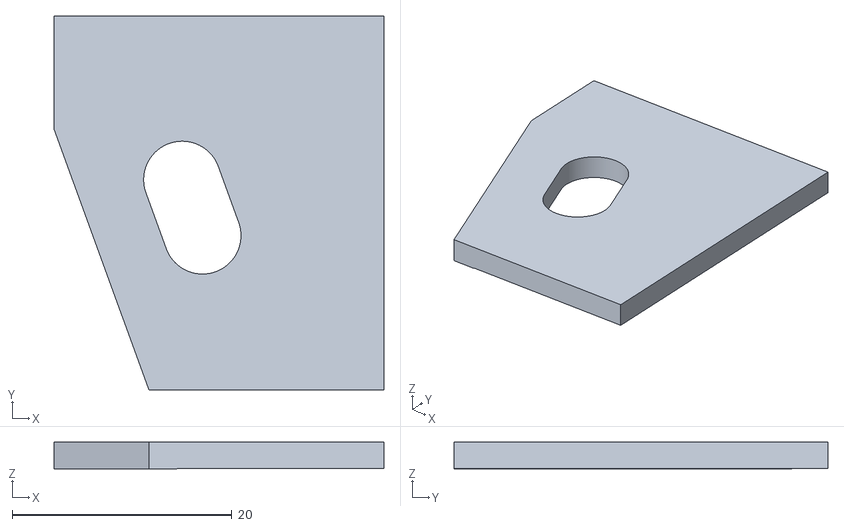
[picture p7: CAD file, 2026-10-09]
3D/atlas_enclosure_v1_print_set/tests/test_usb_v1.stl
30.0 x 34.0 x 2.45

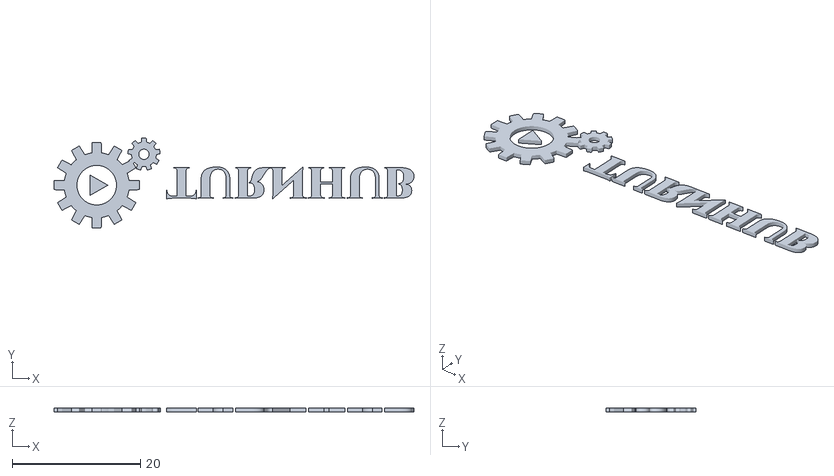
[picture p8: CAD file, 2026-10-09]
3D/sigil_enclosure_v12_print_set/sloped_shell_logo_inlay_v12.stl
56.1 x 14.0 x 0.6

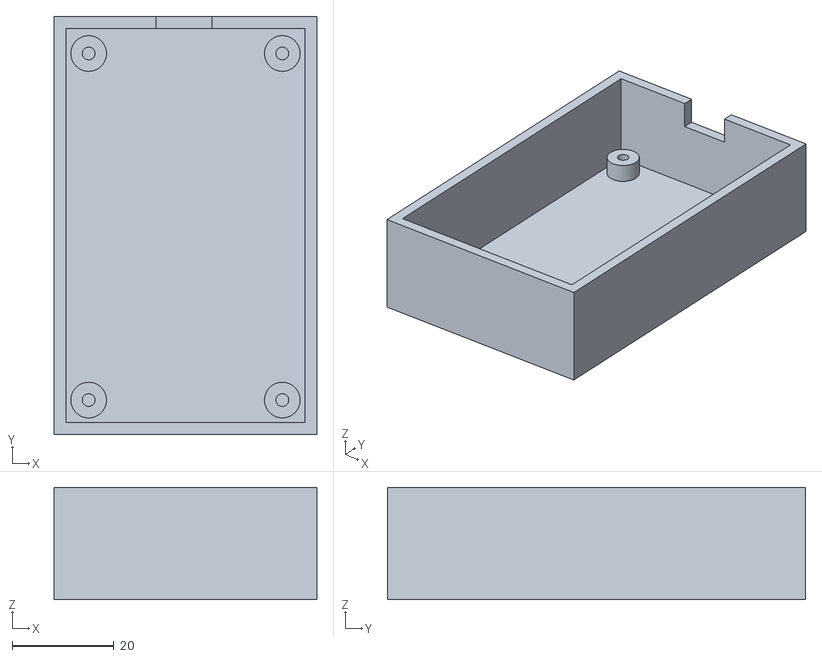
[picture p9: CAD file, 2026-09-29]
KiCad/PCB/Sigilv1/case/sigil_fit_test.stl
51.6 x 82.1 x 22.0

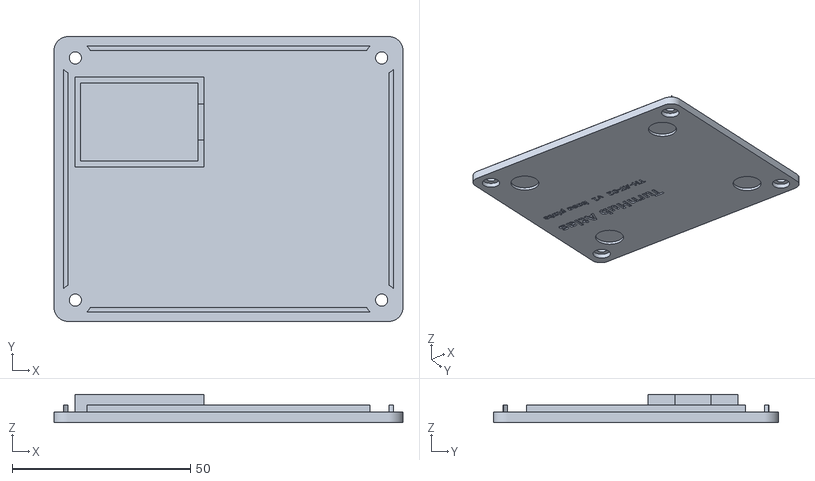
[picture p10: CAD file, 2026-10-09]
3D/atlas_enclosure_v1_print_set/atlas_base_plate_v1.stl
98.0 x 80.0 x 8.00

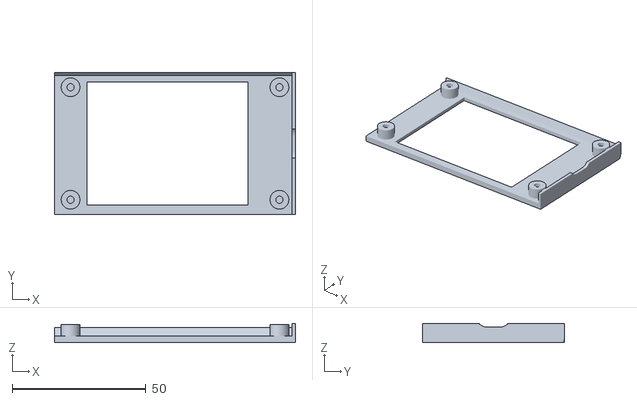
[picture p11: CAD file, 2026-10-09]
3D/atlas_enclosure_v1_print_set/tests/test_screen_face_v1.stl
90.0 x 53.0 x 7.20

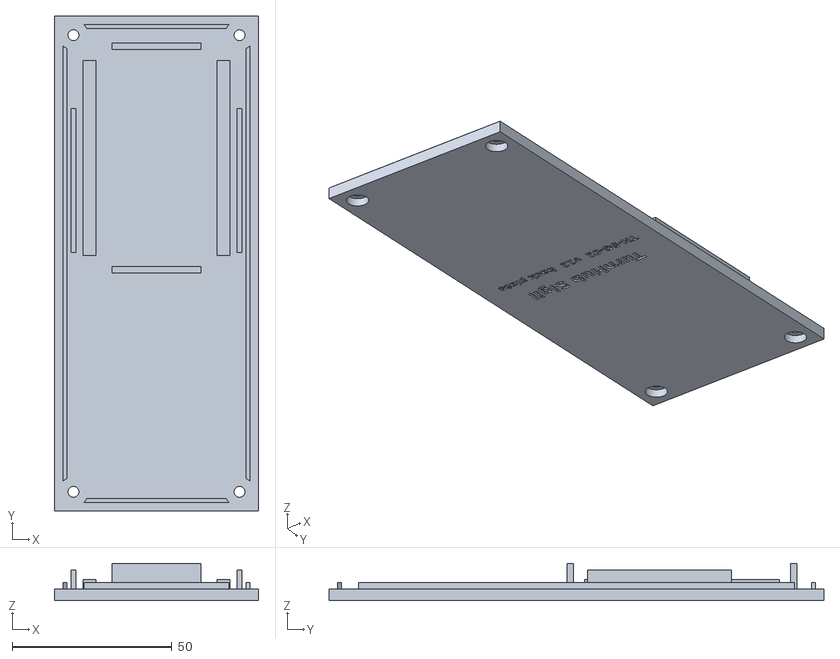
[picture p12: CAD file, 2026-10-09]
3D/sigil_enclosure_v12_print_set/back_plate_v12.stl
64.0 x 155.0 x 11.6

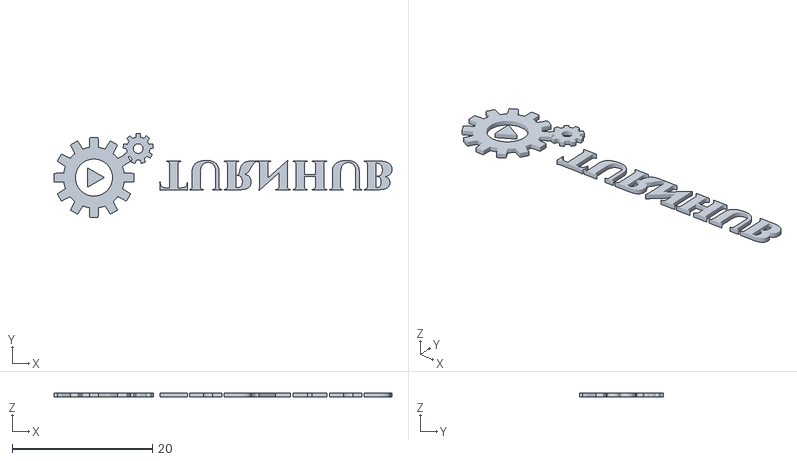
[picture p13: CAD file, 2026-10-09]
3D/atlas_enclosure_v1_print_set/atlas_shell_logo_inlay_v1.stl
48.3 x 12.0 x 0.6

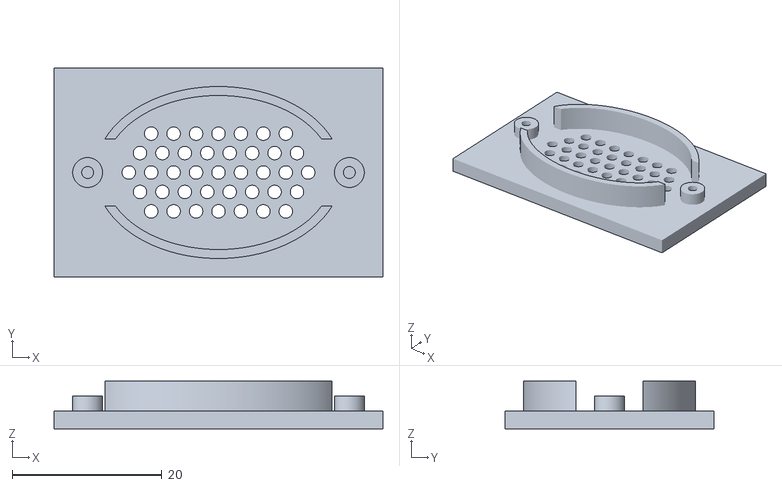
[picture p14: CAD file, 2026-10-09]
3D/atlas_enclosure_v1_print_set/tests/test_speaker_v1.stl
44.0 x 28.0 x 6.40

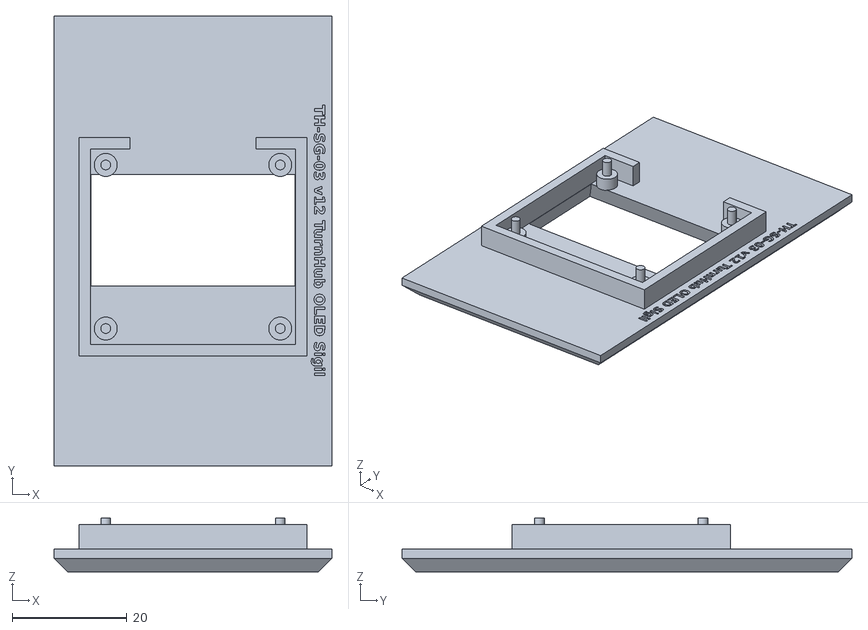
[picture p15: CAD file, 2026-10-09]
3D/sigil_enclosure_v12_print_set/screen_plate_oled_v12.stl
48.4 x 78.4 x 9.40

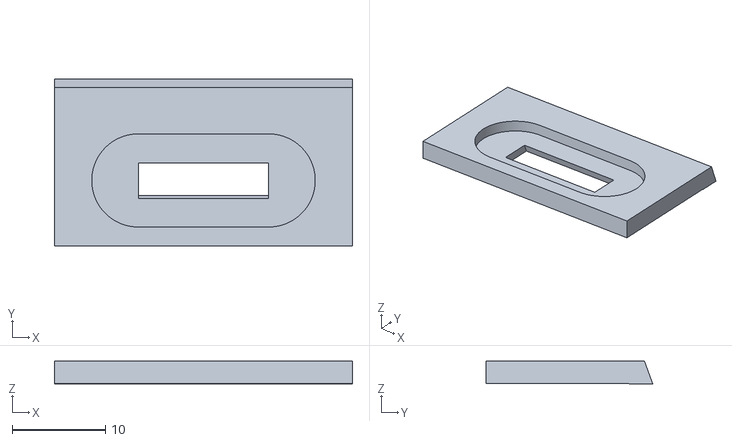
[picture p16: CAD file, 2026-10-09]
3D/atlas_enclosure_v1_print_set/tests/test_sd_v1.stl
32.0 x 17.9 x 2.45

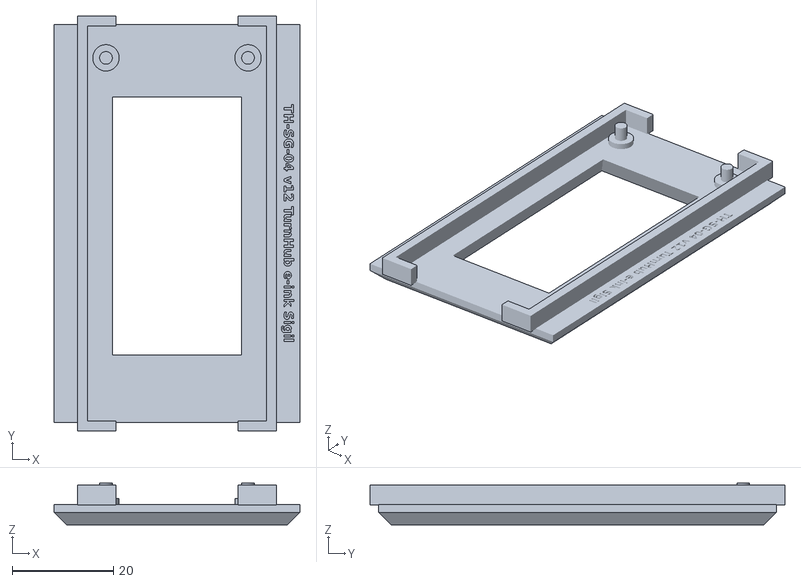
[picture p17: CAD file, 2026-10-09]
3D/sigil_enclosure_v12_print_set/screen_plate_eink_v12.stl
48.4 x 81.8 x 8.20

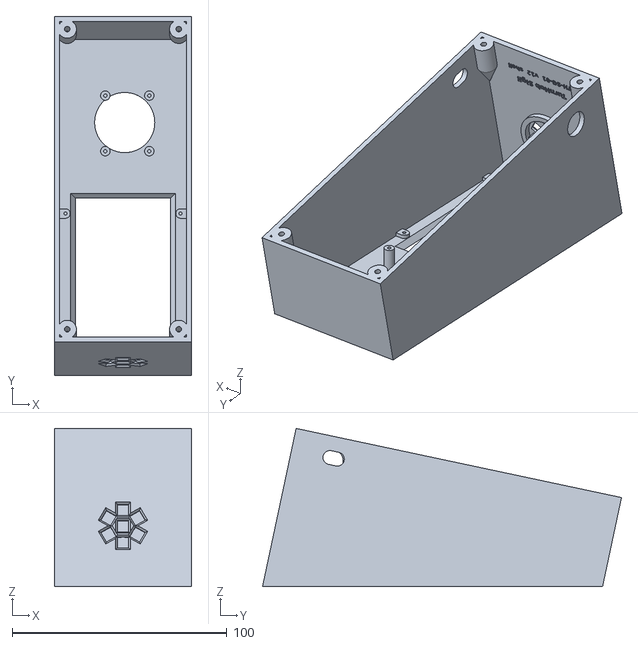
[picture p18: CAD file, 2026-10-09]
3D/sigil_enclosure_v12_print_set/sloped_shell_v12.stl
64.0 x 167.3 x 73.7

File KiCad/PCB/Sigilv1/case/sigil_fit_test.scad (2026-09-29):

// Sigil Rev A: fit-test tray (OpenSCAD).
//
// A quick FDM print to prove the carrier board, DevKit socket rows and USB
// opening fit before the real 45-degree wedge case is designed. It has no lid,
// display window or joystick hole yet.
//
// All board dimensions come from Sigil_EInk.kicad_pcb (Edge.Cuts 100..146 x
// 99.5..176, four M3 holes) and the DevKit footprint in Sigil.pretty. Positions
// below are board-local: origin at the board's bottom-left corner, viewed from
// above with the USB end at the top, the same view KiCad shows. KiCad's y axis
// points down, so y_local = 76.5 - (y_kicad - 99.5).
//
// Everything marked "VERIFY" is a guess to be checked with calipers against the
// real parts, not a measurement.

$fn = 48;

// ---- Board (from KiCad) ----------------------------------------------------
pcb_w = 46;          // Edge.Cuts x 100..146
pcb_l = 76.5;        // Edge.Cuts y 99.5..176
pcb_t = 1.6;         // VERIFY: ordered board thickness
hole_d = 3.2;        // MountingHole_3.2mm_M3
holes_kicad = [[104, 104], [142, 104], [104, 172], [142, 172]];

// ---- DevKit (owner's ruler measurements, 2026-09-28) -------------------------
// Fab outline in KiCad: x 109.98..135.38, y 100.0..153.98 (25.4 x 53.975 mm).
kit_x0 = 109.98 - 100;
kit_w  = 25.4;
kit_y_usb = 76.5 - (100.0 - 99.5);   // USB end, local y
kit_l  = 53.975;
socket_h = 8.5;      // VERIFY: female header body height
kit_pcb_t = 1.6;     // VERIFY
usb_w = 8.0;         // VERIFY: micro-USB shell width
usb_h = 3.2;         // VERIFY: micro-USB shell height
usb_x_local = kit_x0 + kit_w / 2;    // centred on the DevKit

// ---- Case ------------------------------------------------------------------
clear = 0.4;         // gap around the board; FDM, tune per printer
wall = 2.4;
floor_t = 2.0;
post_h = 4.0;        // lifts the board so solder tails (about 2.5 mm) clear the floor
post_d = 7.0;
screw_pilot_d = 2.5; // self-tapping M3 into PLA/PETG; use 4.0 for heat-set inserts
wall_h = 20;         // tall enough to show the DevKit and USB jack inside
usb_slot_margin = 1.5;   // extra room around the USB shell in the wall opening

show_ghosts = true;  // translucent board/DevKit for preview only; not printed

inner_w = pcb_w + 2 * clear;
inner_l = pcb_l + 2 * clear;
outer_w = inner_w + 2 * wall;
outer_l = inner_l + 2 * wall;

function to_local(p) = [p[0] - 100, 76.5 - (p[1] - 99.5)];

board_z = floor_t + post_h;
kit_bottom_z = board_z + pcb_t + socket_h;
usb_center_z = kit_bottom_z + kit_pcb_t + usb_h / 2;

module tray() {
    difference() {
        union() {
            // Shell, outer origin at (-clear - wall, -clear - wall) so the board
            // sits at local (0,0).
            translate([-clear - wall, -clear - wall, 0])
                cube([outer_w, outer_l, floor_t + wall_h]);
        }
        // Cavity
        translate([-clear, -clear, floor_t])
            cube([inner_w, inner_l, wall_h + 1]);
        // USB opening in the top (USB-end) wall
        translate([usb_x_local - (usb_w + 2 * usb_slot_margin) / 2,
                   pcb_l + clear - 0.01,
                   usb_center_z - (usb_h + 2 * usb_slot_margin) / 2])
            cube([usb_w + 2 * usb_slot_margin, wall + 0.02, usb_h + 2 * usb_slot_margin]);
    }
    // Screw posts
    for (h = holes_kicad) {
        p = to_local(h);
        translate([p[0], p[1], floor_t - 0.01])
            difference() {
                cylinder(d = post_d, h = post_h + 0.01);
                translate([0, 0, 0.5]) cylinder(d = screw_pilot_d, h = post_h + 1);
            }
    }
}

module ghosts() {
    if (show_ghosts) {
        // Carrier PCB
        %translate([0, 0, board_z]) cube([pcb_w, pcb_l, pcb_t]);
        // DevKit, raised on the sockets
        %translate([kit_x0, kit_y_usb - kit_l, kit_bottom_z]) cube([kit_w, kit_l, kit_pcb_t + 2]);
        // USB shell
        %translate([usb_x_local - usb_w / 2, kit_y_usb - 1, kit_bottom_z + kit_pcb_t])
            cube([usb_w, 5, usb_h]);
    }
}

tray();
ghosts();

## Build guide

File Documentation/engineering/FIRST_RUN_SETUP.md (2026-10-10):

# First-run Setup

The guided setup for a new or factory-reset Atlas (2026-09-30), in Atlas, the
Android app and the embedded portal, and in use (owner, 2026-10-02). It is the
implemented part of the broader provisioning ideas in `Atlas/OOBE.md`.

## Principles

- **Local-first:** no cloud account or internet; everything runs on Atlas's
  own Wi-Fi.
- **Physical presence:** a new Atlas is claimed by the first account set up on
  its own Wi-Fi (in range of the table, with the printed password). The
  six-digit presence code is an optional extra step, off by default since
  2026-10-08; with it on, the table code step asks for it
  ([Players and Accounts](PLAYERS_AND_ACCOUNTS.md)). The app skips that step
  when Atlas reports the account verified.
- **The public default Wi-Fi password must be replaced** before setup can
  finish. The default `TurnHub-Setup` lives in `Atlas/include/config.h`
  (`WIFI_DEFAULT_PASSWORD`) and `WifiCredentials.DEFAULT_ATLAS_PASSPHRASE`;
  keep them in sync.
- **Never block play:** **Skip for now** on the Atlas screen lets a table
  play first; setup comes back at the next start-up and under Menu.
- **One flow, app first:** Atlas defines the steps and endpoints; the app and
  the portal both follow them. The app is easiest because it joins Atlas's
  Wi-Fi by itself. Setup gives the network as typed text and doesn't depend
  on QR codes.

## The flow

```text
Atlas, stage Welcome: "Welcome to TurnHub"
  1. Open the TurnHub app and tap Connect (it joins the table's Wi-Fi)
  2. No app? Wi-Fi TurnHub-Atlas, password TurnHub-Setup, then 192.168.4.1
  [Pair a Sigil] [Skip for now] [Menu]

Phone, "Set up this table" (Step n of 5):
  1. Your account   create one or sign in
  2. At the table   type the code Atlas shows; this account becomes the Admin
  3. Sigils         pair each one (code check on the Atlas screen), or skip
  4. Updates        Atlas and every Sigil: running vs available; Install all
                    or Later. Atlas first, then each Sigil
  5. Secure Wi-Fi   choose the table's password (8-63 characters);
                    Finish saves it and restarts Atlas

Atlas restarts, stage Finished: "You're all set. Next: pair your Sigils."
  [Pair a Sigil] [Done]  -> stage Complete
  (skipped straight to Complete if a real Sigil was already paired)
```

The app reads `GET /api/setup` after Connect and opens setup while the stage
is Welcome. After Atlas restarts on the new password, the app rejoins with the
password it just set. On launch it rejoins its saved table; a phone with none,
or whose table no longer answers, offers "Set up a new table". The portal
pack runs steps 1, 2 and 5; pairing and updates stay on the Atlas screen and
in the app.

**Updates during setup** use the GitHub release feed
([Firmware Updates](FIRMWARE_UPDATES.md)). They come after the table code
(installing needs a verified Admin) and pairing (one prompt for every
device), and before the password change (so every restart still uses the
printed password). The app's network specifier leaves the phone's own
internet as the default network, so downloads go over the phone's connection.
With no internet the step says so and Continue works. Atlas sessions and
presence are RAM only, so after Atlas restarts the app signs in again and asks
for one new code before updating the Sigils.

## Stages and storage

`SetupStage` in NVS `turnhub/setup` (`setup_stage.h`):

| Stage | Meaning | Atlas screen |
|---|---|---|
| `Welcome` (0) | New or factory-reset | Welcome |
| `Finished` (1) | The phone finished | "You're all set" once |
| `Complete` (2) | Normal operation | Ordinary lobby |

No record at boot reads as Complete if an Admin exists, otherwise Welcome. A
storage failure reads as Complete (logged `ATLAS|SETUP|STAGE|LOAD_FAILED`),
so a broken NVS never locks the table in setup. Factory reset returns to
Welcome. Stages never go backwards otherwise.

## Feature gate

1. **State owner:** Atlas (`setup_stage.h`; `beginFirstRunSetup` in `table_intents.cpp` loads it at boot). Skip
   for now is RAM-only touchscreen state.
2. **Intent:** `AdvanceSetup`, `value` = target stage. To Finished: a
   presence-verified Admin from a phone. To Complete: the touchscreen or an
   Admin.
3. **Validator:** `handleAdvanceSetupIntent`: to Finished needs a verified
   Admin, Lobby or Game Over, and an owner-set Wi-Fi password already saved
   (with a real Sigil paired it stores Complete instead); to Complete needs
   stage Finished.
4. **Persistence:** `turnhub/setup`; the Wi-Fi password keeps its own store.
5. **Rendering:** the touchscreen (`ScreenKind::Setup`), the app's setup
   steps and the embedded portal.
6. **Contract:** portal-private routes, not part of `/api/v1`:
   `GET /api/setup` (no sign-in; stage, `adminExists`, `passwordIsDefault`,
   SSID, never the password) and `POST /api/setup/finish` (`password=`;
   saves the password, then the stage, then restarts; a refused
   `AdvanceSetup` means no restart). If power is cut between the two writes,
   setup simply runs again.
7. **Dependencies:** none.
8. **Accessibility:** every step is text on the Atlas screen and an
   accessible form on the phone; nothing relies on color, sound or LEDs.

## Status

Host scenario `firstRunSetup`, Android JVM tests (`AtlasSetupAssistantTest`,
`FirmwareReleasesTest`) and a full owner run on hardware (2026-09-30; an app
crash on the final reconnect was fixed the same day, log in
[history/logs](history/logs/README.md)). Still open: a "Setting up a new
table" section in the user manual, and an Atlas name step later.

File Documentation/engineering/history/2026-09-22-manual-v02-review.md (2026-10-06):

# Manual V0.2 implementation review

Reviewed on 2026-09-22 against commit `34a0363` and the local
`codex/manual-v02-gameplay` changes. The manuals describe the intended Prototype
1.0 experience; their wording is not evidence that each feature has shipped.

Sources: [V0.1 manual](../../User%20Manual/archive/TurnHub%20Manual%20V0.1.docx),
[V0.2 manual](../../User%20Manual/archive/TurnHub%20Manual%20V0.2.docx), and current Atlas source.
The content changes between these manuals are Game Master terminology and the
closing version number. V0.2's opening still says “Prototype Edition v0.1”.

## Gameplay and portal comparison

| Manual function | Current source status | Remaining work |
| --- | --- | --- |
| Local Atlas authority; physical and browser participants | Implemented through shared Intents | Hardware regression remains necessary after changes |
| Join, leave, start, turn passing, pause/resume, concession, confirmed win | Implemented | Continue mixed phone/Sigil acceptance |
| Starting life 20, 25, 40, 2000 | All accepted as custom values; format presets also exist | Optional preset presentation polish |
| Magic +10/-10 controls | Added in this local change | Bench acceptance |
| Changes to another player's life with a 15-second approval window | Added in this local change; only the recipient can approve/reject, Atlas handles timeout | Bench acceptance, especially a recipient reconnecting during the window |
| Commander damage | Added in this local change, separate counters per source and commander 1/2; damage and life change together | Bench acceptance; players still decide elimination |
| Pass to yourself with a distinct alert | No dedicated self-pass request/control in current Atlas | Define the semantic action and alert before adding UI |
| Nudges and browser alerts | General browser feedback exists; nudge sending is unimplemented, although mute preferences exist | Atlas nudge handler, recipient delivery, mute enforcement and UI |
| Profile name, PIN and personal settings | Implemented | Keep account, game host and Game Master roles distinct |
| Avatar selection | No current Atlas avatar field/control found | Profile representation, storage and portal selection |
| Game Master privileges | Force pass and configurable moderation exist | Manual leaves exact permissions open; retain explicit server-side permissions |
| Atlas status | Available in Device Settings and diagnostics according to permissions | Review navigation terminology with the owner |
| Restart and Shut Down | No standalone commands; changing Wi-Fi password restarts Atlas | Define Atlas system actions, state restrictions and supported shutdown behavior |
| QR connection | Manual describes it; no generated QR in the current Atlas portal | Decide printed label versus locally generated presentation |

## Other prototype gaps and wording decisions

The manual describes a deliberate 30-second pairing flow. Manual pairing is now
implemented with a 15-second window (see [Manual Pairing](../PAIRING_AND_SECURE_LINK.md)), so
the manual text needs updating. Physical auxiliary controls and standalone
profile selection also need their hardware/firmware work. These are separate from
the web counter changes.

Current source still keeps the active game and new counters in RAM. Persistent
profiles/settings and browser reconnection should not be mistaken for recovery
after Atlas power loss. The pending recovery design must include committed
Commander counters and cancel transient life approvals when restoring a match.

The manual describes statistics-related features as opt-in, while current profile
policy says statistics always accumulate and separately controls visibility.
Whether collection itself needs an opt-in is a product decision; this change
preserves existing recording behavior.

The manual names Game / Player / System sections. Last night's portal organization
uses Game / Players / My Account / Device Settings with independent permissions.
This pass preserves that organization while adding the chosen gameplay functions.

## Verification and next acceptance

See [Life approval and Commander damage](../GAMEPLAY.md) for the
implemented boundaries, endpoints and automated evidence. No firmware has been
flashed by this task. The next bench check is a three-player game: request/accept,
request/reject, unanswered request, reconnect during a request, Commander damage
and correction, win claim/concession while requests are pending, and rematch.

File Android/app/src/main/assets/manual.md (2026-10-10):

<!-- Generated from TurnHub Manual V0.15.docx by Android/tools/export_manual.py. Do not edit by hand. -->

# TurnHub User Manual

## Prototype Edition v0.13

**TurnHub** is a tabletop turn management system designed to keep the game moving without putting a phone in the middle of the table.

The system consists of a central Atlas and one or more player Sigils. Atlas maintains the authoritative game state while Sigils give each player a simple physical interface for turns, life totals, actions, and other game events.

**Prototype Notice**
This manual describes the current TurnHub prototype. Controls, menus, terminology, and hardware may change before the final production version.

# 1. Meet TurnHub

## Atlas

Atlas is the central controller for the table. It has a 2.8-inch touchscreen and no other buttons.

It is responsible for:

- Maintaining the current game state

- Tracking whose turn it is

- Managing connected Sigils

- Handling game-wide actions

- Hosting the TurnHub web interface and its Wi-Fi network

- Coordinating turn, life, pause, win, and elimination events

- Showing the table on its touchscreen

Atlas is the authority for the game. Sigils, browsers, the Android app and the Atlas touchscreen send requests to Atlas, which decides the result and shares the new game state.

## The Atlas Screen

The top line shows what the table is doing (Lobby, Starting, Playing, Paused or Game Over) and how many Sigils are online; during and after a game it also shows the round and how long the match has run. Below it, Atlas shows whose turn it is by name, a turn clock, and a card for each player with their name, life total, their total time on their own turns and a label: TURN, OUT, WINNER, STARTS, or CONFIRM for the player a win claim is waiting on.

The buttons along the bottom change with the game: Start (once two players have joined), Clear (hold, to empty the lobby) and Menu in the lobby; Cancel start during the countdown; Pause (or Resume) and Table during a game; Rematch, Reset and Menu after it. Menu holds Pair a Sigil (lobby only), QR codes, Tests (section 27) and Info; Back steps out one screen at a time. **Table** opens the less-used game controls, **Master pass** and **End match**, so they stay out of the way during play. A pressed button changes color and gains a heavier border, and buttons that must be held say so and count down while you hold them.

A red **NO SD CARD** label appears when no microSD card is in use. The game works without one; see section 22.

## Sigils

Sigils are the player-facing devices placed around the table. The prototype has two models:

- **E-ink Sigil:** a paper-like screen, a thumbstick that also clicks when pressed in, and a ring of lights. One E-ink Sigil can be shared by two players.

- **OLED Sigil:** a small bright screen, the same clicking thumbstick and the same ring of lights. An OLED Sigil can also be shared by two players.

A Sigil shows who is playing on it, whether it is their turn, their life total, the game status, pairing status, prompts, and which of its controls does what right now.

## Virtual Sigils

An Android phone or tablet can also participate through the TurnHub app. The browser portal is for Atlas administration.

Virtual Sigils provide many of the same player functions without requiring an additional physical module.

An Android tablet or phone can lie in the middle of the table as one shared screen with a panel facing each player: tablet mode (section 17). With no Atlas, the app can keep a simple game by itself (section 18).

# 2. Before You Begin

For a typical game you will need:

- One TurnHub Atlas

- One or more Sigils, Virtual Sigils (Android phones or tablets), or one shared Android tablet in tablet mode

- Power for Atlas

- Power or sufficient battery charge for each physical Sigil

- Optionally, a microSD card in Atlas for detailed statistics (section 22)

- A phone, tablet, or computer for initial setup when desired. Play can begin without adding profiles, setting up an administrator, or ever opening the web portal. Without profiles, players are shown as “Player 1”, “Player 2” and so on, and their statistics are not saved.

TurnHub is designed to operate locally and does not require an Internet connection for normal game operation.

No Atlas with you? The Android app can run a game on its own tablet or phone and hand the results to Atlas later (section 18).

# 3. Starting TurnHub

## Power On Atlas

Connect power to Atlas. It shows the TurnHub logo for a moment, then the lobby.

The first time Atlas starts, and after a factory reset, it asks you to calibrate the touchscreen: press and release the center of each cross as it appears, four in all. To calibrate again later, for example if touches land in the wrong place, press and hold anywhere on the lobby screen for 10 seconds.

Do not begin pairing devices until Atlas shows the lobby.

## Setting Up a New Table

A new Atlas, or one that was factory reset, shows **Welcome to TurnHub** instead of the lobby. Setup takes a few minutes and is easiest with the Android app: open it and tap **Set up a new table**; it joins Atlas’s Wi-Fi by itself. Without the app, join the Wi-Fi network TurnHub-Atlas (password TurnHub-Setup) and open 192.168.4.1 in the browser.

- **Your account:** create one or sign in.

- **At the table:** type the code the Atlas screen shows. This account becomes the table’s Admin.

- **Sigils:** pair each one (section 5), or skip.

- **Updates:** install new firmware on Atlas and every Sigil, or choose Later. This needs internet on the phone; without it, Continue.

- **Secure Wi-Fi:** choose the table’s own Wi-Fi password, 8 to 63 characters. Finish saves it and restarts Atlas, and the app rejoins with the new password.

The browser covers the account, the code and the Wi-Fi password; pairing and updates are on the Atlas screen and in the app. To play first, tap **Skip for now** on the Atlas screen: setup comes back at the next start-up and under Menu. When setup is done, Atlas says You’re all set; tap **Pair a Sigil** or **Done**.

## Power On Your Sigils

Turn on each Sigil you plan to use. It shows the TurnHub logo, then either its Sigil number (it is paired and ready) or “Unpaired”.

# 4. Connecting to Atlas

Atlas creates its own Wi-Fi network called **TurnHub-Atlas**. Its password is **TurnHub-Setup** until an administrator changes it.

Players can connect using:

- The QR codes on the Atlas screen

- The local TurnHub address, http://192.168.4.1/portal

- A previously configured connection method, such as the Android app

## QR Codes on the Atlas Screen

Tap **Menu**, then QR codes, on the Atlas screen (in the lobby or after a game) and choose a code:

- **Wi-Fi:** joins the TurnHub-Atlas network.

- **Portal:** opens the TurnHub page.

- **Sign in:** opens the profile sign-in page.

The chosen code is framed and marked “shown”. If an administrator has set their own Wi-Fi password, the Wi-Fi code only appears while an administrator is verified at the table (section 20), so the password is not shown to everyone. An empty lobby explains how to join; its codes are under Menu.

**Info** (under Menu on the Atlas screen) shows the Wi-Fi name, the portal address, the firmware version, how many Sigils are online, the microSD card status and how long Atlas has been running. When newer firmware is available, Atlas’s small light blinks blue (red means a pairing window is open), and every Atlas screen shows an Update available tag (Update available for Atlas, if only Atlas is behind). Sigils say Update available on their screens too, and the app shows an Update available card with an Update now button for an Admin. The TurnHub app checks for new firmware and tells Atlas, since Atlas itself has no internet; install it with the app or the portal’s update pages.

## Using the Android App

The TurnHub Android app is on Google Play. While TurnHub is a prototype it is offered through Google Play’s testing track, so the owner adds you as a tester first. Choose Play on this device for a local game (section 18), or Connect to Atlas to join a table. The app joins the TurnHub-Atlas Wi-Fi by itself. It tries the saved password, then TurnHub-Setup, and asks only if neither works. On newer Android versions, allow Nearby devices when you choose an Atlas action; local play needs no nearby-device permission.

Sign in with your PIN or password, or choose **New here? Create an account** on the sign-in sheet to make one: a name, and either a PIN (quick to enter on a Sigil) or a password. An account made without a PIN, for example by a tablet (section 17), asks you to choose one the first time you sign in from a phone; enter it twice. From then on it is checked as usual.

Signed in, you can join the table in the lobby, pass, pause or resume, change life and Commander damage, claim or answer a win, concede and set Sigil accessibility. Atlas keeps the turn clock.

If Atlas stops answering, the app stays where it is and shows the last known table under an **Offline: reconnecting to Atlas** banner that says how old it is. It rejoins Atlas’s Wi-Fi by itself and carries on as soon as Atlas answers. Changes wait until then, except life and Commander damage in tablet mode (section 17).

The app carries this manual (the ? in its top bar), so you can read it before connecting.

# 5. Pairing a Physical Sigil

Pairing normally starts from Atlas’s touchscreen (Menu, then Pair a Sigil). The small button marked **BOOT** on a board does three jobs: a quick press pairs, holding it for 3 seconds unpairs, and holding it for 10 seconds factory resets that board. A case can hide a Sigil's BOOT button, so an unpaired Sigil also goes into pairing mode when you hold its joystick in for 3 seconds; its screen says so. On Atlas, BOOT is a backup for the touchscreen: a quick press opens pairing, 3 seconds forgets every Sigil, and 10 seconds erases Atlas, the same as Menu, then Device, on the touchscreen. A tone sounds at 3 and at 10 seconds, so release at the tone to stop there. Each Sigil's device menu also has Unpair and Factory reset (section 9).

## To Pair a Sigil

1. In the lobby, tap **Menu**, then Pair a Sigil, on the Atlas screen. Atlas returns to the lobby screen, opens a pairing window of 60 seconds and counts it down. An administrator can lengthen it to 90 or 120 seconds under Device Settings. Atlas’s small light blinks red while the window is open.

2. Within that time, put the Sigil into pairing mode: hold its joystick in for 3 seconds (the light ring fills as you hold), or press its Pair (BOOT) button. Its light ring blinks while it looks for Atlas. The Sigil’s own window is always 60 seconds, so with a longer Atlas window tap Pair a Sigil on Atlas first, then start the Sigil.

3. The Sigil and the Atlas screen each show the same 4-digit code. If they match, tap Codes match on Atlas (or, as an administrator verified at the table, in Device Settings in the browser). If they differ, tap Reject: something else answered the Sigil. After Codes match the Sigil shows its number.

4. If nobody answers within a minute, nothing is saved: pair again. After updating to firmware with the secure link, a Sigil paired with older firmware shows Unpaired: pair it again once the same way. From then on everything Atlas and the Sigil say to each other is encrypted.

5. Repeat for additional Sigils as needed.

Do not hold the BOOT button while plugging a Sigil in or restarting it: that puts the board into its programming mode instead of starting TurnHub.

## Forgetting a Sigil

A paired Sigil stays paired through restarts. To remove a pairing:

- **On the Sigil:** open its device menu (section 9) and hold **Unpair** for 3 seconds, or hold its Pair button for 3 seconds. A tone sounds, the Sigil forgets Atlas, its lights go off and its screen shows “Unpaired”. Keep holding the Pair button to 10 seconds to factory reset the Sigil instead.

- **On Atlas:** an administrator opens Device Settings in the browser and chooses Forget next to a Sigil, or Forget all Sigils. This works in the lobby, for Sigils nobody is seated on. A Sigil that is switched on and in range also forgets Atlas.

A forgotten Sigil can be paired again at any time.

## Factory Reset

Device Settings has **Factory reset** next to each Sigil and a **Factory reset Atlas** button. Both need an administrator who is verified at the table (section 20), and neither works during a game.

At Atlas itself, tap **Menu**, then **Device**, between games. Hold **Unpair Sigils** for 3 seconds (in the lobby, with nobody seated on a Sigil) to make Atlas forget every Sigil, or hold **Factory reset** for 10 seconds to erase Atlas. Like Atlas’s BOOT button, these need no administrator: anyone at the table can use them.

The same screen has **Sleep**: tap it between games and Atlas says “Going to sleep. Touch the screen to wake”, then its screen goes dark. Touch the screen (or press BOOT) to wake it. Atlas restarts: profiles, pairings and settings are kept, but the lobby empties and phones sign in again. Sigils show that Atlas is lost until it wakes.

- **A Sigil** erases everything it has saved, including its pairing, and restarts as new. Atlas forgets it. Nobody may be seated on it. If the Sigil is out of range, Atlas only forgets it; hold the Sigil’s Pair button for 3 seconds to clear it too.

- **Atlas** asks you to type RESET to confirm. It then erases every profile, PIN, statistic it holds, Sigil pairing, the Wi-Fi password (back to TurnHub-Setup) and all settings, empties the microSD card (the admin portal stays in firmware), and restarts as new, asking for touchscreen calibration and then setup (section 3). This cannot be undone.

# 6. Player Setup

Players can create or select a profile (an account) before beginning a game. A profile has a name, usually a PIN or password, and the player’s Sigil accessibility choices.

Profiles are separate from physical Sigils. A player is not permanently assigned to one device, so the same Sigil can be used by different players in different games.

## Moving onto a Sigil During a Game

Nobody new joins a game once it has started, but a player who is playing from a phone or the tablet can move onto a Sigil. On a Sigil that is not in the game, choose **Join**: it lists only the players in the game who have no Sigil. Choose one, and that player carries on from the Sigil with their place, life and turn clock.

## Two Players on One Sigil

Every Sigil can carry two players. After joining, push Left in the lobby (**Add seat B**) for the second player; Left again drops seat B. The screen shows both names, prompts say which seat (A or B) they are for, and Down switches between the seats. In the lobby, tap either player on the Atlas screen to set turn order. Earlier and Later can swap A and B; moving past their pair moves the whole Sigil. Choose B left for B to take its turn before A, or B right for B to follow A. Both seats stay next to each other in turn order. Set this before starting the game. The order is kept for a rematch.

The same Player screen on Atlas has **Remove**: hold it for 2 seconds to take that player out of the lobby. Removing seat A of a shared Sigil removes seat B too.

# 7. Starting a Game

Any player seated at the table can set up and start the game. There is no table host.

1. Each player joins: choose Join game on a Sigil, or Join table in the Android app.

2. Optionally choose who goes first: Next starter or Random start on a Sigil, or I go first in the Android app.

3. Choose the game profile, starting life and turn timer on the Game tab in the Android app. Custom turn lengths accept 15 to 3600 seconds; choose Save game settings to apply.

4. Choose **Start game**, or tap **Start** on the Atlas screen. A 3-second countdown begins, which any seated player, or **Cancel start** on the Atlas screen, can cancel.

Game profiles and their starting life:

- Generic: 40

- Magic: 20

- Commander: 40

- Yu-Gi-Oh!: 8000

- Custom starting life: any whole number from 0 to 1,000,000

Changes to the game settings apply from the next game that starts.

Two-Headed Giant (Magic and Commander): turn it on in Game setup for teams of two. Players 1 and 2 are a team, then 3 and 4, and so on; change the turn order in the lobby to change teams. It needs an even number of players, at least 4.

- Teammates share one life total: 30 for Magic, 60 for Commander (you can change it). Either teammate can change it.

- Teammates take their turn together. Both see “Your turn”, and either can pass, cancel the pass or claim the win.

- Commander damage still counts per player, and each hit comes off the team’s life.

- When one teammate is eliminated or concedes, the whole team is out. The last team left wins, and both teammates get the win.

- The starting team skips its first draw; the Atlas screen reminds you during that first turn.

# 8. Taking Turns

TurnHub always maintains a current active player. The active player’s Sigil shows YOUR TURN, and the Atlas screen shows their name and turn clock.

When finished, pass play to the next player: choose Pass turn on the Sigil (it is the likely choice on your turn), or in the Android app. For 3 seconds after passing you can change your mind with Undo pass on the Sigil; after that the turn moves on. Meanwhile your Sigil shows PASSING and its light ring counts the 3 seconds down in green; every other Sigil shows which player is passing with an amber countdown, and the Atlas screen shows “Passing in 3s”. The table hears two falling ticks when a pass starts and two rising ticks if it is undone. On an OLED Sigil, clicking the stick again undoes the pass.

## A Stuck Turn: Master Pass

If the active player has stepped away or their Sigil is not responding, anyone at the table can move the game on. On the Atlas screen, tap **Table**, then hold **Master pass** for 2 seconds. The turn passes to the next player at once, with no undo window.

A master pass is recorded as a master pass, not as that player’s own pass. It is not available while the game is paused or while a win claim or elimination is waiting. A Game Master’s Pass turn in the app is recorded the same way.

## Passing to Yourself

TurnHub supports passing a turn back to yourself when required by the game or table rules.

A distinct alert is used for a self-pass so it is not easily confused with normal turn progression.

## Turn Timer

Any seated player can choose the turn timer in the lobby in the Android app. It applies from the next game that starts.

- Off: there is no countdown. After a turn has lasted five minutes, the active player’s Sigil shows a gentle long-turn reminder.

- Presets: 1, 2, 3 or 5 minutes.

- Custom: any whole number of seconds from 15 seconds to 60 minutes.

With a timer set, each turn counts down from the full time, shown as a clock and a bar on the Atlas screen. Pausing the game stops the countdown, and passing starts a fresh countdown for the next player.

When 10 seconds are left, the active player’s Sigil plays a short chirp and its light shows a slow warning pulse. The Atlas screen turns the clock red and still shows the time in numbers; the app show the time left and a warning.

When time runs out, the Sigil plays two low notes and its light stays steady. The turn does not end automatically: the player passes as usual.

# 9. Sigil Controls

A Sigil offers a short menu of what you can do right now. Atlas decides the choices, so the menu changes with the game: Join game in the lobby, Pass turn on your turn, Confirm win when a win claim is waiting on you, and so on.

## Choosing an Action

Every Sigil uses the same keys. Click (press the stick straight in) is the obvious next step: Join, Start game, **Pass turn** on your turn (Undo pass while it is passing), Resume, Rematch, Confirm win or Confirm out. In a game, Left and Right change your life (section 10). In the lobby, Left adds or drops seat B and Right picks the next starter. Down switches seat on a shared Sigil. Up always opens **Menu**, with every other action Atlas offers right now (such as Cmd damage, Pause, Claim win, I’m out, Partner, Random start, Leave lobby, Switch game or Link phone), then **Device**. The two Sigils show Menu differently:

- **E-ink Sigil:** Menu comes in pages of up to four choices, one each on the click, Up, Right and Down. The bottom of the screen lists them; each line starts with an arrow for a direction or a filled circle for the click. While more choices follow, Down is **More**. Left goes back a page, then out. The header names the page, such as Page 1 of 2.

- **OLED Sigil:** Menu is a scrolling list of everything you can do right now, ending with Device and Back. Push Up or Down to move through it, click (or push Right) to choose the highlighted line, and push Left to go back. The top line counts where you are in the list, and lines you must hold say (hold). Choosing an action closes the list. The bottom line of the game screen names one key at a time, starting with the click, and moves on every few seconds.

## Screen Themes

Each Atlas and Sigil remembers its own screen theme: Graphite, Daylight, Brass or High contrast. Changing one device does not change another device, the app, or the browser. Unpairing keeps the choice; factory reset clears it. Each device also remembers a separate Invert setting. It flips black and white on Sigils and reverses screen colors on Atlas. Changing theme keeps this setting; unpairing keeps it and factory reset clears it. The setting leaves player LED preferences unchanged. Atlas QR codes keep their usual black-on-white format.

On Atlas, between games, tap Menu, then Device, then Theme. Tap a named theme to preview and save it immediately. The framed choice is selected; Back returns to Device. Graphite is the default. Tap Invert: off/on on the same page to toggle inversion.

On a Sigil, push Up for Menu, choose Device when it is listed, then choose Theme. Each tap cycles to the next theme while the menu stays open. OLED shows the current name beside Theme; e-paper shows it under Device. The local menu works while Atlas is unavailable or the Sigil is unpaired. Close the menu before holding the joystick to pair. Choose Invert to toggle the screen polarity. On e-paper, choose More on the first Device page to reach Theme and Invert; INV beside the theme name means inversion is on. OLED shows Invert: on/off in the Device list.

Daylight uses dark text on a light OLED background; other OLED themes use light text on dark. E-paper keeps black text on white: Graphite uses chevrons and a life shield, Daylight uses outline icons and a heart, Brass uses engraved icons and a gauge with serif lettering, and High contrast uses boxed icons and heavier borders. Modern themes use clear sans-serif type. The screens always show turn and warning states in words. Calm ring lights default to teal for Graphite, blue for Daylight, amber for Brass and soft white for High contrast. A player’s saved ring color overrides the theme default. Action and warning colors and patterns keep their usual meaning. Each theme has a header emblem on all three displays: Graphite diamond, Daylight sun, Brass gear and High contrast boxed hourglass. Inverted Daylight OLED uses light text on a dark background.

## Device Menu

Each Sigil has its own **Device** menu that Atlas is not asked about. It is the last entry in Menu on both Sigils, at any time, even during a game. When Atlas cannot be reached, Menu opens straight on it.

- **Unpair:** hold for 3 seconds. The Sigil forgets Atlas and shows Unpaired; hold the joystick in to pair it again.

- **Sleep:** choose it. The Sigil shows how to wake it and sleeps; its lights go off. Click the joystick (or press its Pair button) to wake it; it restarts and reconnects to Atlas by itself.

- **Factory reset:** hold for 5 seconds. The Sigil erases everything it has saved, including its pairing, and restarts as new.

- **Back:** push Left to step back out, or choose Back at the end of the OLED list. The menu also closes by itself after 10 seconds.

## Actions You Hold

Actions that are hard to undo must be held: **Claim win**, **Confirm out**, **Reset table**, and the device menu's **Unpair** and **Factory reset**. While you hold, the light ring fills up. Let go early to cancel. Each player can change the hold times (except the device menu's 3 and 5 seconds); see Accessibility Settings in section 13.

## Pair Control

The Pair (BOOT) button is reserved for pairing: press it to pair, hold it for 3 seconds to make the Sigil forget Atlas, or hold it for 10 seconds to factory reset it. The hold works at any time, even during a game. If the case hides the button, an unpaired Sigil also starts pairing when you hold its joystick in for 3 seconds.

## Light Ring

The ring of lights shows the same thing as the screen: in the lobby it shows your player number as lit lights; during the game it shows your turn, waiting, paused, warnings and prompts. The words on the screen always carry the meaning, so nothing depends on color alone.

If a Sigil cannot hear Atlas for about 7 seconds (Atlas is switched off, restarting or out of range), its screen says Atlas lost, Searching… (NO ATLAS on the OLED Sigil) and one orange light sweeps back and forth around the ring. With Reduced motion, two opposite lights stay on instead. Game and lobby actions are hidden and their presses ignored, because nothing can reach Atlas. Menu stays on Up, so you can still put the Sigil to sleep, unpair it or factory reset it from its device menu; the Pair button still works too. When Atlas answers again, the Sigil returns to its normal screen on its own.

# 10. Life Tracking

When life tracking is enabled, players can adjust life totals through TurnHub. The Atlas screen shows every player’s life total.

On a Sigil, Left and Right change your own life during a game; hold to repeat. The light ring shows the change you are making, and the Sigil sends it 2 seconds after your last press. In games that start at 1000 or more, a Sigil steps by 100.

On the Atlas screen, tap a player’s card for -5, -1, +1 and +5, or Concede.

In the app and tablet mode the life steps are 1 and 5 (100 and 1000 for Yu-Gi-Oh!). Custom signed changes are also available.

Other players may also request changes to another player’s life total.

The player asked must approve it: Right approves and Left denies on a Sigil, or use the buttons in the Android app.

If they do not answer, the change is accepted after 15 seconds, or after 30 or 60 seconds if that player chose a longer time in Sigil accessibility (section 13). Pausing the game does not stop that time.

# 11. Commander Damage

TurnHub can track Commander damage separately from the player’s main life total.

Damage is recorded by the player who received it, from each opponent’s commander (and their partner, if they have one). Each hit also comes off that player’s life, or the team’s life in Two-Headed Giant, and a correction gives it back. Record it on your Sigil (below), on the Game screen of the Android app, or on your panel in tablet mode under More.

Partner commanders are off until a player turns them on: choose Partner from the Sigil’s Menu, or enter damage from a second commander in the Android app. Once a partner has dealt damage it stays on until a rematch or reset.

Because game formats vary, players remain responsible for determining when a game rule requires elimination. Recording 21 Commander damage does not eliminate a player by itself.

## Commander Damage from a Sigil

Record damage on the Sigil of the player who received it. On a shared Sigil, first show the correct seat with Down (Switch seat). Push Up for Menu and choose **Cmd damage**. The receiving name and A/B seat stay fixed while you enter the hit.

Use Left/Right to select who hit you and click; with partners on, choose Commander 1 or 2 and click; then enter the amount. Hold Left/Right to repeat. Click to review the life and Commander damage totals; click again to apply both together. Up goes back; Down cancels. This works during anyone’s turn without pausing the game.

Undo hit previews and reverses the last hit recorded this way for the shown seat. It restores the life lost and removes that Commander damage together. A correction to the same damage entry removes that undo option. Entry pages and Undo clear on a restart or new match; recovered life and damage totals remain.

# 12. Pausing the Game

TurnHub includes a global pause function. Any player in the game can pause from their Sigil menu, the Android app, or tap Pause on the Atlas screen. Resume works the same way.

When paused:

- Normal turn progression is suspended

- Players can resolve questions or interruptions without losing the current game state

- The game can resume from the same position afterward

This can be useful for rules discussions, food breaks, disconnected hardware, or other interruptions.

# 13. Nudges and Alerts

While a game runs, any player whose turn it is not can nudge the active player with Nudge in the Android app. The active player’s Sigil plays the nudge sound (if its sound is on), and their phone shows "<name> nudged you" and vibrates. Each player can nudge once every 30 seconds, and a Game Master can mute an account’s nudges, which stops that account sending them.

TurnHub can provide alerts through:

- Sigil lights and sounds

- The Atlas speaker

- App and Sigil alerts

The app shows turn and decision status in words. Native vibration and Android turn notifications supplement those cues; foreground event-sound and vibration preferences remain planned.

Check the player panel for Confirm or Deny when a win claim needs your answer. A tablet pause overlay does not cover these controls.

Turn-timer alerts (the 10-second warning and time running out) always appear as text in the app, as well as through the Sigil’s light and sound.

## Accessibility Settings

Each player can choose how their Sigil behaves. Sign in, then open Sigil accessibility in the Android app. Your choices are saved with your profile on Atlas and follow you to whichever Sigil you use.

- Sigil sound: turn your Sigil’s tones off. Everything a tone means still appears as text in the app.

- Sigil lights: Standard; Reduced motion (steady lights and slow blinks only, with your turn bright and waiting dim); or Monochrome-safe (no two signals differ by color alone).

- Hold times: how long to hold for deliberate actions (1 to 4 seconds, normally 2) and to claim a win (3 to 10 seconds, normally 5). The win hold is always at least one second longer.

- Time to answer life changes other players ask for: 15, 30 or 60 seconds (normally 15).

If two players share a Sigil, it uses the more accommodating choice: it stays quiet if either player turned sound off, uses reduced motion if either chose it, and uses the longer hold times.

When a decision is waiting on you, such as confirming a win or approving a life change, your Sigil plays two short tones (unless its sound is off) and the request appears on screen.

The administration portal offers System, Dark, Light and High contrast accessibility appearance, saved on this browser. Decorative themes remain in the app and devices. The Android app has themes and Reduce motion, and follows the phone’s contrast, text size and screen-reader settings.

# 14. Claiming a Win

A player can claim a win by holding Claim win on their Sigil, or from the Android app.

A win claim does not immediately end the game. Instead, TurnHub asks the remaining living players, one at a time, to approve the result with **Confirm win** or **Deny win**. The Atlas screen marks the player it is waiting on with CONFIRM.

All required players must approve the claim. If a player denies the request, the win claim is canceled and normal play continues.

This helps prevent an accidental button press from ending the game.

## After the Game

When a game ends, choose Rematch to play again with the same players, or Reset to empty the table. Both are on the Atlas screen as well as on the Sigils and in the app.

# 15. Conceding

A player who is leaving the game can concede. On a Sigil, choose I’m out from Menu, then hold Confirm out. On a shared Sigil, Other seat switches to the other player first. In the app or tablet mode, choose Concede and confirm.

Conceding removes that player from normal turn progression while preserving the rest of the game.

Earlier prototype versions may refer to this function as Eliminate. Current terminology uses Concede for a player intentionally leaving the game.

## Ending a Match as a Draw

If a match cannot or should not be finished, for example after a power cut, tap **Table** on the Atlas screen, then hold **End match** for 5 seconds while the game is running or paused. The button counts down while you hold it; a shorter press only shows a reminder.

The match ends with no winner. Every player’s statistics count one game played, with the result shown as a draw (players who had already conceded keep their result). The browser and the app show “Draw”. Any win claim, pending pass or elimination choice is canceled.

# 16. Atlas Administration Portal

The local browser portal is for Admin setup, maintenance and recovery. Personal and shared-tablet play, player account preferences, statistics and Game Master controls are in the Android app.

Open http://192.168.4.1/portal on Atlas Wi-Fi and sign in as Admin. Initial setup can create the first Admin account, verify the Atlas code and secure Wi-Fi.

Admin controls cover Wi-Fi, the table-code setting, pairing decisions, speaker/pairing window, device names/forget/reset and account roles/archive/restore. Choose Save for staged settings.

Signed local Atlas and Sigil firmware installation remains available. The full admin portal is included in Atlas firmware and works without a microSD card. Developer diagnostics and hardware tests require Developer permission, including for an Admin.

Atlas 0.7.6 and portal 2.0.0 form the cutover. A missing card or installed v1 pack uses flash administration recovery; install a signed v2 pack and reload old browser tabs. Browser /tablet and /stats open recovery.

Play, shared tablet mode, personal preferences/statistics and Game Master controls are in Android. The app’s game selector follows Game 1 or Game 2; Atlas validates every action.

The app’s Players screen displays an installation QR. After installing, join Atlas Wi-Fi and choose Connect. A signed-in player can refresh Paired Sigils, request attachment of empty seat A in the lobby and confirm Link phone on that Sigil.

# 17. Tablet Mode

## Player images

In My account, open Personalization to choose a smooth default icon or Upload your own image. Insert a working microSD card in Atlas first. Choose a JPEG, PNG or WebP image up to 20 MiB and 32 megapixels; the source stays on your phone.

Use Zoom, Horizontal position and Vertical position to crop a square. Preview compressed image shows the final crop and provisional 2.8-inch/4-inch display previews. Tap Upload for approval to save a 512-pixel JPEG up to 48 KiB on Atlas. An Admin opens Players → People, selects your account and approves or rejects the image. Until approved, only you and Admins can preview it; an earlier approved image stays visible while a replacement waits.

Refresh image approval reloads your image status. You can choose None or a default icon without deleting your uploaded image. Remove uploaded image deletes pending and approved artwork and selects None. Missing card or damaged artwork uses a fallback while play continues. The current Atlas shows a small thumbnail; current e-ink/OLED Sigils keep their existing icons. Larger ESP32-S3 LCD layouts are planned.

In tablet mode one Android tablet or phone lies in the middle of the table and acts for everyone. Panels face their seats and show name, life, Commander damage and turn clock. Atlas remains authoritative.

## Turning It On

- In the Android app, sign in, open Game and tap Open tablet mode. When activated, this device signs your personal account out and automatically switches to the Shared tablet account. Your own phone can stay signed in to your player account. Browser tablet mode is retired.

- Tap **Show a code on Atlas** and enter the six digits the Atlas screen shows. This proves the tablet is at the table. An account with the **Tablet access** role skips the code (section 20).

- Closing or leaving tablet mode ends the Shared tablet account and leaves this device signed out. Your player stays seated, and personal sessions on other phones stay active. Shared tablet access cannot open private account settings or Atlas administration. The app keeps the screen on during play.

## Seating Players

In the lobby, add everyone who is playing with **Seat player**. Type a new name to create an account for that player with no PIN, or pick a saved player. A saved player who keeps a PIN types it on the tablet, unless they turned on **Allow Sigil and tablet use without a PIN** in My account. Use the arrows to set turn order; panels sit clockwise in that order. Then choose the game, starting life and Two-Headed Giant, and tap **Start the game**.

Players seated by the tablet can still use their own Sigil or phone as well: a Sigil’s Join picker lists them as at the table, and a phone can sign in to the same player.

## Playing on the Panels

- Tap the top half of a panel to add life and the bottom half to subtract it; hold to repeat the bigger step.

- The player whose turn it is holds **Hold to pass**. While it says **Passing… tap to keep**, a tap undoes the pass.

- **More** on a panel holds **Claim the win** and **Concede** (tap again to confirm) and Commander damage received from each opponent, with partner commanders when needed.

- **Menu** in the middle of the table holds **Pause**, **Turn panels around**, **End without a winner** (a draw) and **Leave tablet mode**. After the game choose **Rematch** or **New players**.

If Atlas stops answering during a game, the panels keep taking life and Commander damage. The changes are saved with the time they were tapped and sent to Atlas as soon as it answers, and Atlas applies them by its usual rules. A change Atlas can no longer apply, for example after Atlas restarted or the player left the game, is dropped with a note. Passing, pausing, conceding, win claims and seating wait for Atlas.

# 18. Playing Without Atlas

The Android app can keep a game on this phone or tablet with no Atlas, account or network. Tap **Play on this device** on the first screen, or **Resume game** if a local match is running or paused. Local play is available while the app is looking for Atlas; choosing it stops that connection attempt. The app remembers device play for its next launch. Back returns to the connection screen without ending the local game; an explicit Atlas connection, search or setup chooses Atlas for future launches.

- Add everyone who is playing. Type a name to create a local player, or pick a saved player from this device. Short IDs distinguish people with equal names; names never select Atlas accounts automatically.

- Use the arrows to set turn order, choose the game and starting life, and tap **Start the game**.

- The table looks and works like tablet mode (section 17): life, Commander damage, passing, pause, concede and the winner. There is no turn timer, no Two-Headed Giant, and no phones or Sigils in this mode.

Atlas import is optional (firmware 0.7.2 or later). Connect and sign in, open Device players and history, then Load Atlas players for import. For a match, choose Link this match for Atlas import and explicitly pick a different Atlas profile for every player. Nothing is selected by name. Check the destination Atlas ID and all player choices, then Import mapped match. Local players and match results stay on this device. History shows pending, imported or needs-attention status and the response reason. Retry a pending import with the same mapping after reconnecting; review a rejected match before explicitly linking it again. The app never automatically resends an imported match. Atlas remembers only its last 64 import IDs, and storage failures or power loss can leave partial credit; acknowledged partial credit is shown and must be reviewed rather than blindly replayed.

This device saves the current game and reusable local players when you close the app. Device players and history on Home, or Players and history in the local lobby, shows finished matches and each local player’s played, won and draw totals. History has no automatic pruning and stays after import or rejection. Clearing app data or uninstalling removes it; export/backup is not available yet. Older queued records are kept without guessing their local identities; earlier discarded records cannot be recovered.

A game without Atlas is separate from any game Atlas is running: nothing in it changes a game on Atlas.

# 19. Two Games on One Atlas

One Atlas can run two games at once, **Game 1** and **Game 2**, each with its own lobby, players, settings and turn order. Everyone starts in Game 1. This is new in the prototype and still being tested at the table.

- **The Android app’s Game on this Atlas selector chooses Game 1 or Game 2 in personal and shared-tablet mode. Switching leaves a personal lobby seat; Atlas rejects switching during an active personal game. A shared-tablet switch keeps its players at their original game.**

- **On a Sigil,** choose **Switch game** from its menu while it is not in a game. It leaves its lobby and goes to the other game; a shared Sigil takes both seats with it.

- A player, a Sigil or a phone is in one game at a time.

- The Atlas screen, pairing and the tablet show Game 1 for now. The app shows the game your account is in, otherwise Game 1.

While both games are in progress the Atlas speaker stays quiet, so neither table hears the other’s sounds; screens, Sigil lights and Sigil sounds work as usual. Firmware updates, Atlas factory reset and Sleep wait until both games are between games.

# 20. Administrators and Game Masters

## Setting Up the First Administrator

On a new Atlas, or after a factory reset, the setup in section 3 makes your account the Admin. In the browser, the same step appears as a Set up this Atlas banner:

1. Create or sign into your account, with a PIN or password.

2. Select **Make my account the initial Admin**.

3. The Atlas screen shows a six-digit code and a QR code. Enter the code on your phone, or scan the QR code with the same phone.

Your profile is now the administrator. Other accounts can be given roles later under Device Settings.

## Verify at the Table

Some administrator actions need proof that you are at the table: changing the Wi-Fi password, naming devices, updating firmware, Return table to lobby, and factory reset. When you try one, the browser asks for a code automatically; you can also choose **Verify at the table** in Device Settings.

- The Atlas screen shows a six-digit code and a QR code for 90 seconds. They only work for the account that asked.

- Enter the code on your phone, or scan the QR code with the same phone.

- You stay verified for 10 minutes. **Stop** in Device Settings ends it early.

- Five wrong codes cancel the code; ask for a new one.

- If a code appears that nobody at the table asked for, tap **Cancel** on the Atlas screen.

Anyone at the table can read the code aloud to the person entering it.

## Game Master

TurnHub supports a privileged Game Master role for table setup, game administration, correcting unusual game states, troubleshooting and organized play. Exact permissions are still being refined for the prototype.

When a Game Master resets a player’s connections or removes them from a game, TurnHub records it privately with that player’s statistics. Only the player can see these counts, on their statistics page after signing in with their PIN. Game Masters, other players and statistics downloads never show them.

## Roles and Tablet Access

An administrator gives roles under Manage people in the administration portal, or Device Settings in the app: Admin, Game Master, Developer and Tablet access. Roles require a PIN or password. Tablet access permits tablet mode without a table code and grants no other administration permissions.

# 21. Reconnecting

If a Sigil or browser client temporarily disconnects, TurnHub attempts to restore it without requiring the game to restart.

Because Atlas owns the authoritative game state, a reconnecting player receives the current state from Atlas rather than relying on potentially outdated information stored on the client.

If a device does not reconnect automatically:

- Confirm Atlas is still powered on.

- Confirm the device is within range.

- Reopen the Android app or restart the Sigil. For maintenance, reload the administration portal.

- Pair the Sigil again if required.

Do not restart Atlas unless normal reconnection attempts fail.

The Android app does not give up when Atlas goes quiet: it shows the last known table, marked offline, and reconnects by itself (section 4).

# 22. Statistics and the microSD Card

Atlas keeps statistics for each profile. Without a microSD card it keeps the basics: games played, games won, the last result and the type of the last game.

With a microSD card, Atlas also keeps detailed turn statistics and last-game details. View them under statistics in the Android app; it explains when the card is needed.

- You can insert or remove the card while Atlas is running. Atlas notices within a few seconds and starts or stops using it without a restart. To be safe, avoid removing it just as a game ends, while Atlas saves statistics.

- Without a card, the Atlas screen shows a red NO SD CARD label, and Info shows “SD card: NOT INSERTED”.

- Playing never depends on the card.

- Games played on this device have their own local history and totals (section 18), separate from Atlas statistics.

# 23. Updating Firmware

Atlas, the Sigils and the web portal are updated over the air with signed update packages. Each device checks the signature itself and refuses a package that is unsigned, altered, made for another device or older than what it runs.

- **With the Android app:** while the phone has internet, the app checks for new releases and tells Atlas. Atlas, the Sigils and the app then show **Update available**. At the table, an administrator taps **Update now**; the app installs the update on Atlas and then on each Sigil that needs it. Atlas itself never needs the internet.

- **In the browser:** an administrator can install a package file on the Update page (Atlas and the portal) or the Sigil firmware page.

- Updates need an administrator verified at the table (section 20), and the table must be in the lobby or after a game. One update runs at a time.

Atlas restarts after its own update, and Sigils restart and reconnect by themselves. Keep Atlas and the Sigils powered until the update finishes.

# 24. Restarting Atlas

To restart Atlas, disconnect its power and connect it again. Atlas also restarts on its own after a Wi-Fi password change, a firmware update or a factory reset.

If a game was in progress, it comes back paused. Resume it to continue, or tap Table on the Atlas screen and hold End match for 5 seconds to end it as a draw.

Avoid disconnecting power while Atlas is saving settings.

# 25. Shutting Down

There is no shut-down command. For a normal shutdown:

1. End the current game, or pause it.

2. Disconnect power from Atlas.

3. Switch off the Sigils.

A game that was still in progress is restored, paused, the next time Atlas starts.

# 26. Privacy and Local Operation

TurnHub is designed around local-first operation.

Normal tabletop gameplay does not require game data to be sent to an external service.

Features involving statistics or potentially sensitive player information are intended to be opt-in.

TurnHub’s goal is to help manage the table without requiring players to hand over unnecessary personal data.

# 27. Troubleshooting

## My Sigil Will Not Pair

- Confirm Atlas is powered on and showing the lobby.

- Tap Pair on the Atlas screen again.

- Hold the Sigil’s joystick in for 3 seconds (or press its Pair (BOOT) button) within the pairing window. If you need more time, an administrator can lengthen Atlas’s window under Device Settings.

- Move the Sigil closer to Atlas.

- Restart the Sigil if necessary.

- If the Sigil was paired with a different Atlas, make it forget (Unpair in its device menu, or hold its Pair button for 3 seconds), then pair it again.

## My Sigil Disconnected

A Sigil that cannot reach Atlas shows Atlas lost and an orange light sweeping around its ring (section 9). Allow it a moment to reconnect; it returns to its normal screen on its own.

If it does not:

- Confirm Atlas is still available.

- Restart the Sigil.

- Pair it again if requested.

The game state should remain controlled by Atlas.

## Touches on the Atlas Screen Land in the Wrong Place

In the lobby, press and hold anywhere on the screen for 10 seconds, then press and release each cross as it appears.

## The Atlas Screen Shows a Code Nobody Asked For

Tap Cancel. A code only works for the account that asked for it, and it expires after 90 seconds.

## The Atlas Screen Says NO SD CARD

The game works normally. To keep detailed statistics, insert a microSD card; Atlas starts using it within a few seconds, without a restart. If the label stays, the card may be unreadable: try another card. Atlas never formats a card.

## The Wrong Player Has the Turn

Use the available game controls to correct the active player.

If the active player cannot pass, use **Master pass** on the Atlas screen’s Table controls (section 8). If that does not resolve the problem, use Game Master access.

## A Player Accidentally Claimed a Win

Other players can deny the win request.

A denied request cancels the claim and returns the game to normal play.

## Someone Changed My Life Total

Life changes requested by another player display a confirmation prompt.

Review the requested change before accepting it.

## The Turn Timer Ran Out but the Turn Did Not Change

This is expected. Running out of time is a reminder only; TurnHub never passes a turn on its own. The active player passes when ready.

## I Cannot Change the Turn Timer

Join the table first: any seated player can change the turn timer, and only in the lobby before the game starts.

## The Browser No Longer Shows Play Controls

Use the TurnHub Android app or a Sigil for play. The portal handles administration. Atlas firmware 0.7.7 includes the full portal: install one Atlas firmware update and reload existing browser tabs. No separate portal pack or microSD card is needed for administration.

Tap or click the TurnHub interface once, then try again.

## My Sigil Needs a Longer Press Than Expected

Hold times can be lengthened in Sigil accessibility. If two players share the Sigil, the longer of their hold times applies. You can also pause or claim a win from the Android app.

## A Tests Button Appeared in the Atlas Menu

It appears only while a TurnHub test harness, a developer tool that plays as extra Sigils, is connected. Players can ignore it.

## The App Says Offline: Reconnecting to Atlas

Atlas has stopped answering. Check that Atlas is on and the phone is in range; the app rejoins its Wi-Fi and carries on by itself. In tablet mode, life and Commander damage tapped meanwhile are sent when Atlas answers.

## A Game Played Without Atlas Is Missing From Statistics

Connect the app that kept the game to Atlas (firmware 0.7.2 or later), sign in and explicitly map each player through Device players and history (section 18). Names never select an Atlas account. Pending work can be retried with the same mapping; rejected records stay available with their reason. Import never deletes the local result.

## Tablet Mode Asks for a Code Every Time

If the table code setting is on, prove the tablet is at the table when enabling tablet mode. With table code off, or the account’s Tablet access role, no code is needed.

## The Atlas Speaker Went Quiet

Atlas silences its speaker while two games are in progress at once (section 19). Its volume is set in Device Settings.

# 28. Prototype Limitations

The current TurnHub prototype is still under active development.

You may encounter:

- Temporary interface elements

- Changing terminology

- Unfinished enclosure designs

- Features that move between software versions

- Different behavior between physical and Virtual Sigils

- Diagnostic controls not intended for the final product

Prototype users should report unexpected behavior with as much detail as possible.

Helpful information includes:

- What you were doing

- Which player was active

- Which Sigil was involved

- What you expected to happen

- What actually happened

- Whether the issue could be reproduced

# 29. The TurnHub Philosophy

TurnHub is not intended to play the game for you.

It is intended to quietly handle the bookkeeping that gets in the way of playing.

TurnHub should answer the question:

“Whose turn is it again?”

Then get out of the way.

## TurnHub Prototype Documentation

Manual Version: 0.15
Hardware: Prototype (Atlas E32R28T touchscreen board; frozen e-ink/OLED Sigils; ESP32-S3 LCD layouts planned)
Software: Atlas 0.7.8, existing Sigil firmware, TurnHub Android app (Google Play)
Product names and specifications subject to change.

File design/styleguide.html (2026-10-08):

Skip to content

TurnHub V1

# Design system

One set of tokens for the Atlas portal and the Android app. Pick a theme to see every specimen and the Game screen change together.

Auto Graphite Daylight Brass High contrast

Reduce motion

Direction

## Calm by default, loud only for the turn

The active turn, its clock and life totals are the only things that glow. Everything else sits back on quiet surfaces and hairlines, so a glance across the table lands on whose turn it is.

Color

## Semantic tokens

Components never name a color, only a role. Each theme fills the roles and the build checks their contrast against WCAG 2.2 before it writes a file.

Type

## Inter, with tabular figures for every number that changes

Clocks and life totals use tabular figures so digits never jitter as they count. Brass swaps the display face for Cinzel, the face already on the Atlas screen and the Sigils.

Mega112 / 750

40

Hero72 / 700

−7

Clock56 / 650

1:24

Large title36 / 750

Maya's turn

Title 130 / 700

Game over

Title 224 / 650

Players at the table

Title 320 / 600

Commander damage

Headline16 / 600

Pass the turn to Jonah

Body16 / 400

Other players have 15 seconds to approve a change to their life before Atlas accepts it.

Subhead15 / 400

Sigil A on seat 2 · battery good

Eyebrow12 / 600, caps

Turn 7 · Round 2

Components

## Controls

Buttons

Pass turnPause

CancelDetailsConcede

ApproveWaiting

Status

Active turnPaused10 s leftTime's up

ConnectedHostSpectatingSeat 3

Off90 s3 minCustom

Sound on this Sigil

Grouped list

- Atlas Wi-FiTurnHub-Atlas
- Paired Sigils4
- Speaker volumeMedium
- FirmwareUpdate

Fields

Starting lifeCommander tables usually start at 40.

Game profile

Show a sheet

Icons

## An original line set, one stroke weight

Drawn on a 24-point grid at 1.75 stroke with round ends. The same source becomes an SVG sprite for the portal and vector drawables for Android.

Player icons

## Filled glyphs, two tones, on the player's color

The presets from shared/include/avatars.h, drawn on the same 24-point grid as solid shapes with a lighter second tone. Atlas's screen and the Sigils draw the 16x16 one-bit versions of the same icons.

Motion

## Springs, not timelines

Three springs cover every movement. The portal plays them through CSS linear() curves generated from the same physics Android uses, and Reduce motion turns them all off.

Snappy

Gentle

Bouncy

Play

Space and shape

## An 8-point grid

TurnHub Atlas R

1:30left this turn

Turn 7 · Round 2 Maya

Active turnSeat 2

Pass turn

LifeMTG Commander · 40

Sample table for the preview. Changes to another player's life wait 15 seconds for their approval.

## Change Jonah's life

Jonah has 15 seconds to approve. If nobody answers, Atlas accepts the change.

−5−1+1+5

CancelSend request

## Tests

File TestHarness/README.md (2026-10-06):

# TurnHub Hardware Test Harness

**Status: Retired and unsupported (2026-10-05).** This hardware test harness
is retained as historical source. It is excluded from CI builds and firmware
artifacts, receives no maintenance or compatibility guarantees, and is no longer
a supported TurnHub target. Use the Atlas/Sigil host suites, Wokwi simulation,
and physical Sigils for current validation.

The remaining description and commands document the former harness and may not
work with current Atlas firmware or the shared radio protocol.

One ESP32 (any `esp32dev` board; the owner's is the former Atlas DevKit, with
no buttons or LEDs besides BOOT) plays **two menu Sigils** against a real Atlas
over ESP-NOW:

- **V1** is the board's Wi-Fi station MAC and **V2** its soft-AP MAC. Wi-Fi
  runs in AP+STA mode, so both MACs are live at once and Atlas pairs them as
  two separate Sigils (two of Atlas's eight slots). The soft-AP is hidden and
  password-protected; it exists only to own the second MAC on channel 6.
- Each virtual Sigil can take Seat B too, so one board seats up to **four
  players**.
- They report firmware **0.9.0**. Atlas treats every Sigil as a baseline
  Sigil (menu, game display, LedState; no capability bits needed since
  2026-09-30), and only V1 advertises `CAPABILITY_HARNESS`. So Atlas
  sends `MenuState2` (with **Leave** and **AdjustLife**), the profile picker,
  life requests and the game display with each seat's life. They act only
  through the packets a real Sigil sends: `SelectAction`, `PickerKey`,
  `LifeAdjust` and `LifeResponse`.
- V1 also carries `CAPABILITY_HARNESS`, so Atlas never opens the profile
  picker on it (Join seats a guest directly). V2 gets the picker and the
  harness picks **Guest** from it, so a run never plays as a real profile.
- Life requests (a portal user asking to change a harness player's life) are
  answered by the `lifereq` policy: approve by default, or deny, or ignore to
  let Atlas's 15 s timeout accept it.

## Architectural boundary

- Atlas remains the sole authority for table and game state. The harness reads
  the menus Atlas offers and picks from them; it never decides an outcome.
- Shared ESP-NOW packet definitions come from `../shared/include/protocol.h`;
  do not copy them into this project.
- Pairing goes through Atlas's real pairing window (tap **Menu → Pair a Sigil** on the
  touchscreen); the harness never edits Atlas's pairing storage.
- It must not depend on Atlas GPIO or display hardware.

## Feature gate

1. **State owner:** Atlas. The harness owns only transient run state and its
   own pairing record (NVS `th_harness/pair`: Atlas's MAC, then each virtual
   Sigil's ID and pair key).
2. **Intent/request:** the existing Sigil packets (PairRequest2, Hello,
   SelectAction, PickerKey, LifeAdjust, LifeResponse). No test-only gameplay semantics.
3. **Validator:** Atlas's normal transport adapters and Intent handlers.
4. **Persistence:** none for canonical state.
5. **Presentation:** serial console, machine-readable lines.
6. **Protocol change:** none.
7. **Third-party impact:** none (Arduino ESP32 core only).
8. **Accessibility impact:** none to gameplay; developer tooling only.

## From the Atlas touchscreen

V1 advertises `CAPABILITY_HARNESS`, so while the harness is online the Atlas
lobby's **Menu** shows **Tests** beside Info. It opens the premade tests: **Radio**
(radio check), **2p game**, **4p game**, **Rematch** (3 players: a game, a
rematch and a second game) and **Soak x5**. Tap one and the harness plays it
through its Sigils. The title and detail lines show the test, the current
checkpoint and the result in words, and **Stop test** aborts it. The test
screen stays up through the game until **Back**. Atlas and the harness speak
`HarnessCommand` and `HarnessReport` (see
`Documentation/engineering/RADIO_PROTOCOL.md`).

## Serial commands (115200 baud)

| Command | What it does |
|---|---|
| `status` | Radio, Atlas MAC, each virtual Sigil's MAC, ID, online state, seats and life, picker page and current menu |
| `pair` | Every unpaired virtual Sigil broadcasts PairRequest2. Tap **Menu → Pair a Sigil** on Atlas; each code is printed (`HARNESS|PAIR|V2|CODE|V1|0427`) and shown on Atlas one at a time: tap **Codes match** for each. Waits up to 90 s; `status` then shows `pairing=secure` |
| `forget` | Forgets the pairing on the harness only. Forget the two Sigils in the portal's Device Settings as well |
| BOOT button | As on a Sigil (2026-09-30): a press does `pair`; holding it for 10 s does `forget`. Acts on release, and not while a test is running |
| `sigils <1\|2>` | Use one or both virtual Sigils |
| `pace <ms>` | Pause before each menu choice (default 1500 ms, 0-10000, kept in NVS) so a run can be followed on the Atlas screen |
| `verbose <on\|off>` | Log every packet sent and received |
| `test [n]` | Runs premade test n, as the Atlas touchscreen does; with no number, lists them |
| `menu` | Print what Atlas currently offers each virtual Sigil |
| `select <V1\|V2> <action>` | Send one menu choice by hand (`join`, `start`, `pass`, `claim-win`, `leave`, ...) |
| `pick <V1\|V2> <up\|down\|left\|right\|select>` | Press a profile-picker key by hand (Up/Right/Down pick the page's names, Left backs out, Select pages or confirms) |
| `life <V1\|V2> <delta> [player]` | Send one LifeAdjust for that Sigil's shown player (or the given player number), then print its seats and life |
| `lifereq <approve\|deny\|ignore>` | How the harness answers life requests shown to its players (default approve) |
| `run smoke` | Each virtual Sigil is paired, answers Hello and has a menu |
| `run game [players] [turns] [rematch]` | A whole game (defaults: 4 players, 6 turns), below |
| `run soak [games] [players]` | Repeats `run game` (4 turns each) until one fails |
| `x` | Aborts a running scenario |

`run game` needs the table in its lobby. Any seated Sigil may start (there is
no table host since 2026-09-25), so V1 starts it. Its steps:

1. `LOBBY`, then `JOIN` for V1 and V2 (V2 first passes `PICKER`, choosing
   Guest from the profile picker), then `SEAT_B` for as many extra players
   as asked for (V1 B, then V2 B).
2. `HOST` (a harness Sigil offered Start; the step name is historical) and
   `START`: V1 picks Start, and the countdown ends in a running game.
3. `TURN` × N: the active Sigil picks Pass, sees Cancel pass while Atlas holds
   the pass for its 3 s grace, and the pass commits.
4. `LIFE`: every harness Sigil offered AdjustLife sends a LifeAdjust of -3
   for its shown player, checks the game display shows the new total, then
   sends +3 to put it back.
5. `PAUSE` and `RESUME`.
6. With 3+ players, `ELIMINATE`: V1 pauses, says "I'm out" and eliminates one
   of its seats, then the table resumes.
7. `CLAIM_WIN` by the active player, `CONFIRM_WIN` from every other living
   player in the order Atlas asks, then `GAME_OVER`.
8. `RESET_TABLE` back to an empty lobby, or with `rematch`: `REMATCH_LOBBY`,
   then `LEAVE` (the last harness Sigil leaves the rematch lobby) and `JOIN`
   again.

The harness 0.9.0 needs Atlas firmware from 2026-09-30 or later, which reads
its capability byte in the Sigil 0.9.0 layout.

Every step prints `HARNESS|PASS|<step>|...` or `HARNESS|FAIL|<step>|...` with
the menus at that moment, and each run ends with
`HARNESS|SUMMARY|<scenario>|passed=N|failed=N`. Games end in a guest win, and
Atlas records statistics only for signed-in profiles.

## Historical build and flash (unsupported)

From `TestHarness/` (the COM number changes between PC restarts; the harness
is a CP210x port, like the Sigils, so check which is which first):

```text
pio run -e harness
pio run -e harness --target upload --upload-port COMx
pio device monitor --port COMx
```

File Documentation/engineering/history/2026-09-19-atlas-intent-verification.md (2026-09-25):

# Atlas intent migration verification

Historical branch: `atlas-esp32-port`. Verification date: 2026-09-19 (local time).
Merged into `master` in `6844f94`. On 2026-09-20 the owner confirmed the repository
build and current installed hardware baseline. The records below describe that
migration; they do not validate later identity/storage changes.

## Scope and ownership

Atlas remains the only owner of game, lobby, and decision state. `IntentDispatcher`
binds exactly one handler per implemented intent. The application handlers in
`Atlas/src/main.cpp` (since split into the modules listed in `Atlas/include/atlas_app.h`) validate requests and call the existing game/lobby operations;
the engine's rules and statistics completion callback are unchanged.

The six architectural gate answers for this migration are:

1. Canonical owner: Atlas's existing GameEngine, Lobby, and application decision state.
2. Requests: the intent mapping below, including deferred Atlas transitions.
3. Validator: the bound Atlas handler, followed by existing domain validation.
4. Persistence: no new game persistence; existing Atlas profile/statistics owners remain.
5. Clients: physical Sigils and browser controls submit requests and render Atlas output.
6. Contract: internal intent vocabulary/payload documentation expands; ESP-NOW packet
   values/layout and HTTP endpoints do not change. The future JSON envelope is not a
   live ingress path for these internal operations.

| Control or transition | Authoritative intent |
| --- | --- |
| Physical/browser PASS | Pass |
| Atlas touchscreen master pass (Table screen hold, 2026-09-25) | MasterPass (immediate; logged as a master pass) |
| Action cancels pending PASS | CancelPass |
| Grace timer expires | CommitPass (Atlas System only) |
| Physical pause/resume; browser toggle | Pause / Resume / TogglePause |
| Browser concession | Concede |
| Physical/browser victory decision | ClaimWin / ConfirmWin / DenyWin |
| Primary module and secondary seat membership | Join / Leave |
| Exact browser seat, physical seat cycle, host random choice | SelectStarter |
| Host hold/release; any module cancels countdown | ArmStart / StartGame / CancelStart |
| Countdown expires | CompleteStart (Atlas System only) |
| Host game-over short/long action; armed lobby reset | Rematch / ResetGame |
| Paused elimination selection/cycle/cancel/confirmation | BeginElimination / CycleElimination / CancelElimination / Eliminate |

No new UI or leave gesture was added. The existing secondary-seat chord issues
Join or Leave; whole-module Leave is now available at the authoritative boundary.
Button held/long/chord/suppression fields remain adapter bookkeeping, not game rules.
Audio/LED invalidation remains adjacent to authoritative transitions for now.
Profile/device naming, authentication sessions, network settings, and statistics
persistence keep their existing owners; they are not alternate game-state mutators.

## Behaviors deliberately retained

- Claimant must be the active living seat; confirmations/denials follow Atlas's
  required player order, including two seats on one physical Sigil.
- Denial resumes a running claim or a completed armed pause-to-claim gesture.
  An ordinary browser claim made while paused stays paused on denial.
- Physical elimination keeps a surviving game paused. Concession restores running
  play only if it was running before concession. Both retain existing winner logic.
- Countdown requires the host and at least two players. Any discovered module can
  cancel it; any module can cancel a selected elimination, as before.
- Rematch retains joined seats; reset empties the lobby.
- PASS still uses a three-second grace interval and the original request timestamp
  for committed turn statistics, with unsigned timer rollover arithmetic.
- Future life/counters, nudges, and actual device pairing remain unimplemented.
  The follow-up below adds only a visual mock PairRequest handler.

## Optional Preferences/NVS reads

`OptionalPreferences` probes the requested NVS string/blob type. Only
`ESP_ERR_NVS_NOT_FOUND` returns the existing default without a framework error.
Other failures go through Preferences error reporting. Optional deletion likewise
treats absence as success and reports erase/commit failures. No log level is lowered.
This covers profile names, PINs, legacy name/PIN keys, bindings, device names,
statistics lengths, and the optional AP password.

No negative cache is introduced: saving a previously missing value is visible on
the next read. Existing migration, storage layout, and defaults are retained.

## Completed validation

- **Clean ESP32 firmware build: PASS.** `platformio run -d Atlas -t clean`, then
  `platformio run -d Atlas`, using installed Espressif32 7.1.3, Arduino ESP32
  `4.20017.260907+sha.dcc1105b`, Xtensa GCC `8.4.0+2021r2-patch5`.
  RAM: **47,908 / 327,680 bytes (14.6%)**. Flash: **924,281 / 1,310,720 bytes (70.5%)**.
- **Native regression executable: PASS, all six scenario groups.** MSVC
  14.51.36231, C++17, assertions enabled, `/W4`, no compiler warnings. Compiles
  actual application handlers/adapters, GameEngine, Lobby, and IntentDispatcher.
  Hardware, transport, presentation, clock, and NVS are stubbed.
- **Adapter audit: PASS.** `Atlas/tests/host/audit_adapters.py` checks 12 current
  input/transport/timer functions for direct canonical mutators and transition calls.
- **Whitespace validation: PASS.** `git diff --check`.

Native tests cover invalid/stale actors, duplicate binding refusal, unsupported
intents, shared seat ordering, early/out-of-order responses, game completion once,
host restrictions, countdown cancellation, rematch/reset, elimination conflicts,
concession pause restoration, PASS cancellation/grace/rollover, and NVS injected
NOT_FOUND/type/handle/erase/commit failures. These are not hardware persistence tests.

## Hardware verification — user reported complete

- [x] Flash Atlas only; confirm all implemented intents log BOUND and normal Wi-Fi,
  ESP-NOW, web, front-panel LEDs, and both physical Sigils still initialize.
- [x] Poll portal/status/profile/statistics views with unnamed seats and no PINs;
  verify repeated NOT_FOUND messages are gone. Save/clear/reload values and reboot
  to verify persisted values and legacy migration still work.
- [x] Exercise physical, browser, and master-button PASS; wait three seconds,
  cancel with PASS and Action, and verify turn audio including shared-seat passes.
- [x] Test physical/browser pause/resume and mixed-interface win confirmations and
  denials, including a paused browser claim, armed physical claim, and shared seats.
- [x] Exercise join and secondary join/leave, starter cycle/exact/random selection,
  host countdown, cancellation, start, game-over rematch, and empty reset.
- [x] Test elimination target cycle/cancel/confirm versus running/paused concession;
  verify winner, statistics, LEDs, and sounds once per completed game.
- [x] Recheck browser authentication, OTA gating/partition behavior, and reconnect.

The prior conversation reports physical PASS timing/front-panel success on the
pre-migration build. That evidence does not count as hardware validation of this patch.

## Follow-up: front-panel LED prototype

After supplying the hardware run above, the user confirmed that all remaining
gameplay checks were tested. This is user-reported acceptance; no additional
serial capture was supplied for those checks. The original automated build
figures above refer to the intent migration before the LED follow-up.

The LED follow-up binds PairRequest to an explicitly mock, Atlas-button-only
handler: five seconds of pairing LED flashes, automatic exit, no actual pairing
or persistence. Status flashes three times after startup and then stays on.

LED follow-up validation: PlatformIO Atlas build passed (47,924 bytes RAM,
924,797 bytes flash); all six existing native scenario groups and the adapter
audit passed. These automated checks do not verify physical LED appearance.

- [x] Owner accepted the current build/hardware baseline on 2026-09-20, including
  the checked-in LED prototype. This is user-reported acceptance, not a new
  instrumented capture or verification of real pairing (still unimplemented).

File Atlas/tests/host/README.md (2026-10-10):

# Atlas native regression scenarios

These tests compile the **actual** Atlas application modules (`main.cpp` plus the
handler and adapter modules declared in `atlas_app.h`), `GameEngine`, `Lobby`,
and `IntentDispatcher`. Clock, radio, GPIO, web server, presentation, and
NVS boundaries are replaced by deterministic stubs. No firmware is flashed.

On Linux, run `bash Atlas/tests/host/run-linux.sh` from the repository root.
It builds the application, storage, profile-store and OTA suites with C++14, AddressSanitizer and UBSan, then runs them.
GitHub Actions uses this runner; see [CI checks](../../../Documentation/engineering/CONTINUOUS_INTEGRATION.md).

On Windows, run `Atlas\tests\host\run.cmd` from an x64 Native Tools Command
Prompt for Visual Studio (C++ workload required). Assertions must remain enabled.

Alternatively, run `Atlas\tests\host\run-gcc.ps1` in PowerShell with the
PlatformIO `platformio/toolchain-gccmingw32` package installed, or pass
`-Compiler` with another Windows GCC path. This runner uses C++14-compatible
test globals and `-mno-ms-bitfields` to preserve the packed radio layout.
Both Windows runners execute gameplay and storage scenarios.
They also compile the real `profile_store.cpp` against an in-memory NVS boundary
and run `profile_store_scenarios`: unused seat lookups, 100 reconnect cycles,
guest reads/writes, temporary bindings, legacy remember-key cleanup and placeholder filtering before
the account limit. No saved user records are deleted by this filtering.

`src/atlas_speaker.cpp` (ESP32 DAC), `src/atlas_battery.cpp` (ESP32 ADC),
`src/sd_card.cpp` (Arduino SD) and `src/secure_link_backend.cpp` (mbedTLS
self-test) are firmware-only too; `test_globals.cpp` stubs them (no speaker,
a battery reading the scenarios set, no card, self-test passes; the gauge
logic itself is the header-only `battery_gauge.h`, tested directly), and the
speaker scenario plugs a fake `ToneOutput` into the real `AudioController`.
`src/atlas_display.cpp` and `src/atlas_art.cpp` are firmware-only (they need
LovyanGFX), so they are not in any runner's source list. `test_globals.cpp`
provides a no-op `beginAtlasDisplay()`.

**Screen previews (Linux, optional).** `bash render-atlas-screens.sh` builds
LovyanGFX from PlatformIO's download (`pio pkg install -e atlas` in `Atlas/`
first) with its framebuffer back end, runs the real `atlas_art.cpp` against an
off-screen sprite, writes one PNG per scene to `build/screens/`, and checks
that region-by-region redraws land on exactly the pixels of a full redraw
(clock tick, turn pass, life change, timer warning, hold progress, screen
changes). It exits non-zero on a mismatch. Previews are not hardware
acceptance: colors are RGB565 as the panel receives them, not as it shows them.

With GCC/Clang on another host, from this directory:

```sh
mkdir -p build
python3 ../../web/build.py --header build/generated/web_assets.h
c++ -std=c++17 -Wall -Wextra -Istubs -Ibuild/generated -I../../include -I../../../shared/include scenarios.cpp test_globals.cpp profile_fixture.cpp \
    ../../src/app_context.cpp ../../src/gameplay_intents.cpp ../../src/table_intents.cpp \
    ../../src/moderation_intent.cpp ../../src/sigil_input.cpp ../../src/sigil_menu.cpp ../../src/commander_picker.cpp ../../src/profile_picker.cpp ../../src/web_adapters.cpp ../../src/front_panel.cpp ../../src/touch_controls.cpp ../../src/harness_link.cpp ../../src/sigil_accessibility.cpp \
    ../../src/audio_controller.cpp ../../src/led_renderer.cpp ../../src/controller_profiles.cpp ../../src/web_api.cpp ../../src/web_session.cpp ../../src/web_profile_api.cpp ../../src/web_game_api.cpp ../../src/web_tablet_api.cpp ../../src/web_standalone_api.cpp ../../src/standalone_import.cpp ../../src/web_admin_api.cpp ../../src/sigil_update_service.cpp ../../src/sigil_update_jobs.cpp \
    ../../src/profile_statistics.cpp ../../src/profile_stats_bridge.cpp ../../src/web_pages.cpp ../../src/ota_manager.cpp \
    ../../src/game_engine.cpp ../../src/lobby.cpp ../../src/intent_dispatcher.cpp ../../src/client_state.cpp \
    ../../src/game_checkpoint.cpp ../../src/game_recovery.cpp ../../src/game_recovery_store.cpp ../../src/nvs_blob_store.cpp ../../src/serial_log.cpp \
    -o build/scenarios
./build/scenarios
c++ -std=c++17 -Wall -Wextra -Istorage_stubs -Istubs -Ibuild/generated -I../../include -I../../../shared/include \
    storage_scenarios.cpp test_globals.cpp ../../src/nvs_blob_store.cpp ../../src/sd_blob_store.cpp \
    ../../src/profile_stats_storage.cpp ../../src/profile_policy.cpp -o build/storage_scenarios
./build/storage_scenarios
c++ -std=c++17 -Wall -Wextra -Istorage_stubs -Istubs -Ibuild/generated -I../../include -I../../../shared/include \
    profile_store_scenarios.cpp test_globals.cpp ../../src/profile_store.cpp \
    ../../src/nvs_blob_store.cpp ../../src/profile_stats_storage.cpp \
    ../../src/profile_policy.cpp -o build/profile_store_scenarios
./build/profile_store_scenarios
c++ -std=c++17 -Wall -Wextra -Istubs -Ibuild/generated -I../../include -I../../../shared/include \
    ota_scenarios.cpp ../../src/sigil_update_jobs.cpp -o build/ota_scenarios
./build/ota_scenarios
```

`ota_scenarios` covers Sigil OTA on Atlas (`sigil_update_jobs.cpp`):
staging a Sigil package with every check, reloading it after a restart, and
one update job from offer to done or each failure.

Six scenario groups cover dispatcher ownership; lobby and lifecycle restrictions;
shared-seat win-response order and denial restoration; elimination versus
concession; PASS grace/cancellation/rollover and actor validation; optional NVS
absence versus injected type/handle/erase/commit errors.

`python audit_adapters.py` checks that current transport/input adapters do not
call canonical mutators or authoritative transition helpers directly.

This is application regression coverage, not proof of radio delivery, GPIO
debounce, flash persistence, buzzer/LED timing, browser authentication, or hardware
behavior. See `Documentation/engineering/history/2026-09-19-atlas-intent-verification.md` for the hardware gate.

The storage executable compiles the production NVS blob adapter and statistics
repository against injectable NVS calls. It checks identity contracts, deployed
v1 bytes, missing versus unreadable records, unsupported schemas, write protection
and read/set/commit failures. It does not simulate physical flash power loss.

The gameplay executable also compiles the real profile HTTP handlers and controller
registry. Three additional groups cover phone-only authentication/game lifecycle,
mixed physical/phone companion control, and 16-player capacity. `profile_fixture`
is an in-memory repository substitute; the SHA stub is a deterministic test double,
not cryptography. Existing storage scenarios test the real statistics blob layer.

Profile-policy scenarios cover all four owner choices, companion-session expiry,
PIN-protected physical claim rejection, hidden-stat accumulation, and unavailable
policy storage. The storage executable checks the real three-byte policy codec
and NVS failure handling; gameplay scenarios use the profile repository fixture.

Optional administration smoke: `node Atlas/tests/host/portal_smoke.cjs` with
Playwright/Chromium (or `PLAYWRIGHT_EXECUTABLE_PATH`). It rebuilds the assets
embedded by firmware and renders with/without a card, checks Admin-only visibility, bootstrap,
explicit hardware saves and absence of gameplay requests.
`maintenance_smoke.cjs` checks local signed-upload controls, Sigil selection
and Developer hardware tests. Both use the same assets embedded in firmware.
The gameplay executable also covers ending a match as a draw through the real
touchscreen adapter (hold threshold, overrides, statistics once, recovery
validation), table presence codes (request, confirm, wrong codes, expiry), no table host, the
Atlas speaker's cue routing and volume setting, and admin device management (forget one/all Sigils,
seated/in-game refusal, storage failure, the 60/90/120-second pairing window). The
storage executable checks the `pairwin` and `spkvol` codecs and the v1 `Draw` result byte.
The administration smoke covers both the SD-pack page and the cardless fallback, including staged settings and initial Admin setup.

Game/life checks cover persisted setup, host-only edits, captured match settings,
own-life authorization, bounds, companion sessions, negative life and rematches.
The harness now links real LED/audio renderers and replaces the radio boundary.

Life approval and Commander coverage: the native gameplay executable checks
recipient-only acceptance/rejection, duplicate and stale IDs, Atlas's 15-second
deadline including rollover, concurrent edits, lifecycle cancellation and atomic
Commander/life bounds. Browser gameplay tests are retired after the app-first
cutover. These features still require native device/table acceptance.

Manual pairing Intent scenarios cover origin authorization, radio unavailability,
15-second timeout, clock rollover and rejection during gameplay. Radio transport
and persistence still require the manual pairing bench checklist.

Named-profile attachment scenarios cover adopting a joined guest, preserving its
host and secondary seat, merging an already joined browser player, companion login
without duplication, and rejecting replacement of another named account. Profile
attachment and name edits push display names directly instead of requesting the
Sigil reconnect handshake that clears transient bindings. On hardware, attach a
named profile more than five seconds after boot and verify its name and player count
remain stable, then sign into the same profile from a second browser.

Sigil receive coverage copies both the 7-byte control packet and the 110-byte
game display through the production receive buffer, rejecting incorrect sizes.
The physical companion scenario checks game-end seat clearing, saved statistics,
rematch restoration and guest behavior after reset.

Native-client scenarios exercise the live state/info handlers, session-resolved
PASS, boot/revision conflicts, no-op revisions, deferred commits, life approval
expiry including clock rollover, Commander serialization, full 16-player matrices
and reconnect. They emit `build/client-*.json`. After running the host suite, run
`python check_client_contract.py` to check these actual responses and the shared
`protocol/examples` fixtures against the contract schemas (standard library only).
The checker supports only the schema keywords used here and rejects unknown ones.
Display-name tests cover repeated deliveries, truncation, shortening and clearing;
profile-store tests assert identical saves do not add NVS writes.

Interrupted-match recovery: the gameplay executable now also compiles
`game_checkpoint.cpp`, `game_recovery.cpp`, `game_recovery_store.cpp` and
`nvs_blob_store.cpp`, and runs a `gameRecoveryLifecycle` scenario against the
real `beginGameRecovery()`/`checkpointGame()` entry points main.cpp calls
(`stubs/nvs.h` uses a separate recovery namespace handle with real map-backed
reads and `checkpointReadError`; `OptionalPreferences` keeps its independent
canned-value/error contract). Recovery fault scenarios run last because they
change the process-wide store's writable state. They check: `NotFound` on a fresh store; a
checkpoint is written after a dispatched intent with no direct call to
`checkpointGame()` from the test, i.e. through the same observer hook
main.cpp uses; a simulated reboot (fresh `GameEngine`/`Lobby`, same
in-memory "flash") restores a paused, unfinished match with the elapsed game
clock unaffected by the simulated downtime and without replaying the
game-completed statistics callback; and a corrupted record fails safe to
`Corrupt` with no players restored rather than loading ambiguous state. This
does not simulate real flash power loss mid-write; see
`Documentation/engineering/STAGED_CHANGES.md` for the remaining hardware
acceptance items. Resume is the normal control; End match is the implemented
five-second draw path for ending a recovered game.

`completionRecoveryOrdering` runs the production completion bridge and recovery
store with interruptions after the first and second profile writes for draws,
confirmed wins and last-player-standing endings. The saved match must already
be Game Over, restoring it must not replay statistics, and it cannot end again.
It also injects failed writes, an uncertain commit that has written its bytes,
read errors, corrupt records and future schemas. These block statistics and
cannot be bypassed by the later observer. The per-profile boundary remains a
fixture; real profile-store/storage suites test those repositories separately.
Missing/partial results after interruption are an explicit limitation, not a
passing claim of exactly-once multi-record persistence.

`python3 Atlas/tests/host/firmware_portal_smoke.py` checks every actual C++ asset
response against its source bytes, including gzip decoding, binary icons,
cache/type headers and unknown paths. The administration browser smoke also
checks accessibility-only choices, preview versus Save and old-theme migration;
maintenance smoke checks saved High contrast across maintenance pages.

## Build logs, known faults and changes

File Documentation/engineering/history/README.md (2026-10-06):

# Engineering History

Dated records and long-form history. **Nothing here is updated as the code
moves on**, so don't read these to learn how TurnHub works today; use the
topic documents one level up. Read them when you need to know why something
was decided, what a bench run showed, or what a build measured.

| File | What |
|---|---|
| [GENERATION_HISTORY.md](GENERATION_HISTORY.md) | From the standalone Arduino timer through the Raspberry Pi generation to the ESP32 Atlas/Sigil system, with historical pin maps and facts still to recover |
| [SIZE_AND_CHANGE_HISTORY.md](SIZE_AND_CHANGE_HISTORY.md) | Source size and firmware RAM/flash snapshots. **Still appended to** on firmware-version bumps and large feature commits |
| [logs/](logs/README.md) | Captured serial logs that back *Verified* claims |
| [2026-09-19-atlas-intent-verification.md](2026-09-19-atlas-intent-verification.md) | The Intent migration on the ESP32 port and its owner-reported hardware acceptance |
| [2026-09-19-pass-audio-observation.md](2026-09-19-pass-audio-observation.md) | Missing PASS beeps and where audio could be dropped |
| [2026-09-22-stabilization.md](2026-09-22-stabilization.md) | Audit that added `/api/v1/info` and `/api/v1/state` and the client read model |
| [2026-09-22-manual-v02-review.md](2026-09-22-manual-v02-review.md) | User manual V0.2 against the code at the time |
| [2026-09-26-code-review.md](2026-09-26-code-review.md) | Code review of everything but Android |
| [2026-09-26-prototype-1-0-gap-review.md](2026-09-26-prototype-1-0-gap-review.md) | The Prototype 1.0 field-test lane against the tree |
| [2026-09-29-playtest-notes.md](2026-09-29-playtest-notes.md) | Playtest bugs and requests, the fix pass, and what the SD log showed about the phone crashes |
| [2026-10-01-code-review.md](2026-10-01-code-review.md) | Whole-repository review and the bugs it fixed |
| [2026-10-02-stability-plan.md](2026-10-02-stability-plan.md) | The staged multi-phone stability plan, with the first implementation (Atlas 0.6.7). Current status: [Diagnostics](../DIAGNOSTICS.md) |
| [2026-10-05-shared-sigil-turn-order.md](2026-10-05-shared-sigil-turn-order.md) | Playtest fix: turn order for both seats of a shared Sigil |

Superseded topic documents (the old `SECURE_LINK.md`, `SIGIL_OTA.md`,
`MANUAL_PAIRING.md` and so on, with their step-by-step build logs) were
merged into the current set on 2026-10-06; read them in git history
(`git log --follow` or `git show <commit>:Documentation/engineering/<file>`).

Add a dated record here as `YYYY-MM-DD-<topic>.md` when a review, playtest or
investigation produces findings worth keeping, and move anything that stays
true into the topic documents.

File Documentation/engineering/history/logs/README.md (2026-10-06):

# Captured device logs

Serial and other device captures from bench sessions, kept as dated evidence
for the *Verified* labels in the other engineering docs. Host tests passing is
not hardware acceptance; these files are.

Conventions:

- File name: `YYYY-MM-DD-<what>-<board>.log`. Name boards by role (`atlas`,
  `sigil-eink`, `sigil-oled`, `harness`), never by COM port. Boards are matched
  by MAC per [Board Inventory](../../HARDWARE.md).
- Each line is prefixed with seconds since capture start, added by the capture
  script. Serial lines can be split across reads, so a few lines are cut mid-word.
- Scan every capture for secrets (Wi-Fi passwords, keys, tokens) before
  committing, and replace them with `<redacted>`.

## Index

| Date | Files | What |
|---|---|---|
| 2026-09-30 | `2026-09-30-boot-*.log` | Reset of all four boards over USB (RTS), 45 s each, Atlas first then the Sigils and the harness. Atlas 0.6.0-dev, both Sigils 0.8.1-dev, harness 0.8.0, protocol 2. Sigils reported to Atlas over the secure link (`SIGIL|INFO`, `FW|0.8.1`). Nothing was paired or played. |
| 2026-09-30 | `2026-09-30-ota-*.log` | First real Sigil OTA through the portal, Atlas 0.6.0-dev, packages signed with key `bd3b55e0`. Passive capture (no resets), 160 s. E-ink Sigil 0.8.1 -> 0.8.2 (job 1) and OLED Sigil 0.8.1 -> 0.8.2 (job 0), each: presence code, package upload and stage, offer, accept, Wi-Fi join, download (about 0.5 s), `installed`, reboot (`SW_CPU_RESET`), `OTA\|BOOT\|PENDING_VERIFY` then `VALID` once the secure session was up, Atlas `done`. Atlas's Hello showed 0.8.2 for both. Observations: each Sigil logged `ATLAS\|LOST` then `RESTORED` during the Atlas package upload (Atlas busy writing flash, about 8 s). The Sigil boot banner still said `0.8.1-dev` because only `PATCH` had been bumped; fixed in the source afterwards. Rollback, interrupted transfers and the negative tests in [Sigil OTA](../../FIRMWARE_UPDATES.md) were not run. |

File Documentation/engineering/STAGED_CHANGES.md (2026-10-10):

# Staged Changes and Open Checks

The one list of what is agreed but not done: open work, hardware checks still
to run, and product decisions still to make. When an item lands, move any
lasting fact into its topic document and delete the line here; git keeps the
old entries. Longer designs for planned features are in
[Planned Designs](PLANNED_DESIGNS.md).

Owner, 2026-10-02: playtesting and bench testing have verified nearly
everything implemented. Only the checks listed below are still open.

## Standing decisions

- **No compatibility before release** (owner, 2026-09-30): reflash every
  board together, no saved-data migrations, a changed layout means a factory
  reset (`CLAUDE.md`). For release, the version rules in
  [Firmware Updates](FIRMWARE_UPDATES.md) come back first.
- **The OLED Sigil leads** (owner, 2026-09-28): new Sigil UI lands on the OLED
  first; the e-ink follows and may drop extras that cost it full refreshes.
- **No turn timer on e-ink**; try it on a future LCD Sigil.
- **Test harness retired** (2026-10-05): source kept, no builds, no upkeep.

## Open work

### Stability and diagnostics

- **2026-10-09 play-note investigation:** source findings and proposed designs
  for all ten notes are in [the report](history/2026-10-09-play-note-investigation.md).
  Minor tablet overlay and signup scrolling fixes are staged on `codex/master`;
  the former browser verification passed; Android build and device acceptance are tracked in TH-013.
- **Multi-phone stability** (in progress): bench the Atlas 0.6.7+ build with
  unchanged polling, then the wider matrix, then seat-metadata caching and
  lighter client polling. Steps in [Diagnostics](DIAGNOSTICS.md).
- **Open bug, not reproduced:** Atlas stuck on the pause screen during a
  harness soak (2026-09-28).

### Statistics and history

- **Crash-safe statistics:** durable MatchId and completion receipts before
  replaying completion, so a cut during profile writes can't leave missing or
  partial results ([Storage and Recovery](STORAGE_AND_RECOVERY.md)).
- **Game-scoped statistics** (owner, 2026-09-24, the long-term goal): a
  stable `gameProfileId` partitions statistics by game; existing totals stay
  unclassified; a draw counter; raw session facts are canonical and rates are
  derived. Participation facts public by default, derived performance private
  by default with opt-in sharing, enforced on Atlas. Hiding never stops
  recording.
- **Life event log:** record each change (profile, actor, time, old, new);
  rapid same-actor reversals within about a second count as corrections
  (`40 -> 48 -> 47` is +7 gained), with raw events kept.
- **Session history:** bounded game records on the card, enough to rebuild
  aggregates, with a retention limit, separate from the recovery record.

### Accounts, portal and app

- **Router-style web administration** (*Implemented locally; device acceptance pending*, owner confirmed, 2026-10-09):
  web portal for Admin settings/maintenance and Android for personal/shared
  tablet play; retire browser gameplay, including the web tablet. Preserve the
  app's HTTP game APIs.
  Define app parity, initial-Admin bootstrap, diagnostics permissions,
  cardless administration/updates before removal. [Feature parity audit](history/2026-10-09-portal-app-parity.md)
  records existing app coverage and missing custom timer entry, multi-game
  selection, empty paired-Sigil attachment, invite QR generation and local
  event feedback settings. Hardware tests/local signed-package uploads remain
  web-admin features. Implemented in the current TH-013 slice: administration-only embedded pages in Atlas 0.7.7-dev,
  retired separate pack build/install/app/release flows, retired tablet/statistics routes, preserved bootstrap and
  signed maintenance, native game/session polling, custom timer entry, empty
  seat A attachment and app-install QR. Android unit tests/debug build, Atlas
  host/firmware checks and administration browser checks with/without a card pass; device
  acceptance remains pending; native event-feedback preferences/background decision alert remain open.
- **Password hashing:** parked, see "Parked: storage batch" below.
- **High-resolution uploaded avatars and tablet card backgrounds** (*Planned*,
  owner, 2026-10-08; TH-003 in [COLLABORATION.md](../../COLLABORATION.md)):
  Connected avatar upload/crop/review is implemented in PR #86 (2026-10-10).
  Remaining: standalone local player avatars and player-card background artwork, with crop,
  preview, replace and remove controls. Preserve enough image detail for large
  tablet cards; choose explicit source/display dimensions and file limits during
  design rather than reducing everything to tiny icons. Retain the existing
  Admin-approval requirement for avatars before public display.
  Connected assets need an Atlas-owned metadata/storage design; standalone
  players must be able to use local artwork without owning Atlas. Scope artwork
  to player identity, not the tablet-only account. Plan device-sized derivatives
  and caching so large originals do not burden Atlas RAM or game-state polling.
  Define SD storage/failure behavior and safe fallback artwork; play must remain
  available without an image or SD card. Exact storage/transfer contracts remain
  to be designed.
- **Fuller tablet-mode presentation** (*Planned*, owner, 2026-10-08):
  "de minimize the tablet mode screen." Working interpretation: richer player
  cards, prominent avatar/background artwork, and more useful game information
  and controls visible without opening secondary views. Prepare a visual design
  before implementation to settle density and which controls remain exposed;
  this is not yet a request to disable Android immersive/full-screen mode.
  Keep life totals, active-player state, names and touch controls readable over
  custom artwork, with contrast overlays and accessible labels. Apply the
  presentation direction to connected and standalone tablet play, including
  phone/foldable layouts. Verify crop fidelity, large text, orientation changes,
  missing/rejected images, and responsive gameplay while images load.
- **App and portal screenshot tests:** golden images of the Android screens
  in every theme (Roborazzi or Paparazzi on the JVM) next to the portal
  renders.
- **Portal theme packs:** retired by owner, 2026-10-10; the portal keeps only
  System/Dark/Light/High contrast accessibility appearance.
- **HTTPS on Atlas:** revisit administration transport after the app-first cutover; native tablet wake/immersive behavior does not depend on portal HTTPS.

- **Tablet mode, later rounds** (round one, 2026-10-06: Atlas grant and
  seating, the portal's `/tablet` with life, Commander damage, pass, win and
  concede; round two, the same screen in the Android app; see
  PLAYERS_AND_ACCOUNTS.md). Next, as project owner asked: more counters
  per player (poison, commander tax, energy, experience and similar) in
  `GameEngine` and the state, each also kept in profile statistics as
  "counters received"; uploaded player backgrounds are tracked above;
  tablet seating of Sigil seat B.

- **Seat B attachment:** the picker offers already-seated tablet players but
  the handler rejects them. Needs identity-preserving seat-level reassignment,
  including an explicit order policy for nonadjacent shared players; see the
  play-note report. Do not solve it by removing a rejection alone.
- **Tablet win-claim acceptance:** verify reachable player-facing Confirm/Deny
  without the central Resume overlay on Android and the portal, including
  sequential four-player claims and denial. The browser regression passes;
  Android compilation/physical testing remains outstanding. Later UX: claim
  progress, responder/waiting labels and decision-first controls.
- **Fold signup acceptance:** verify staged scrolling with keyboard open,
  folded/unfolded, rotation, large text and long account lists; retain the
  7- and 10-inch tablet checks.

- **Standalone tablet game, later rounds** (round one, 2026-10-07: the app
  plays a game alone; round two: Atlas imports each finished game once,
  `POST /api/standalone/import`, protocol/http-v1.md; user manual V0.12,
  section 18). Local UUID players and retained history/basic local totals now
  and explicit per-match Atlas mapping/import/rejection status exist on
  `codex/app-only-entry` (TH-001 B/C; Android/README.md). Remaining: export/backup,
  deliberate deletion/retention controls, local-player editing, storage/performance
  work for large histories, and physical device acceptance.

### Setup and updates

- **Atlas fetches updates over home Wi-Fi** (optional): an Admin stores a
  home SSID and password (presence-gated); **Check for updates** joins it in
  station mode between games, reads the feed over HTTPS, downloads and
  verifies the same packages, then returns its AP and ESP-NOW to channel 6.
  Needs a CA bundle and about 40 KB heap; can't pass a sign-in page.
- **Atlas name** as a later setup step.

### Table, controllers and accessibility

- **Eliminated-controller release** (owner, 2026-10-09): permit release once
  all players on a Sigil are eliminated, preserving their match identities and
  results; then attach the hardware to another seated player. Needs seat-level
  reassignment, recovery, rematch and two-game isolation; report has the design.
- **Temporary turns** (owner, 2026-10-09): support gifted extra turns using
  a separate scheduled-turn model; grant order, permissions and team behavior
  require decisions before implementation.
- **Waiting LED breathing** (decision open): waiting is intentionally steady
  in each seat's custom color today. Evaluate optional gentle breathing while
  retaining steady reduced motion and distinct turn/decision cues.
- **Tablet re-entry and dedicated tablet-only accounts** (*Planned*, owner,
  2026-10-08; discussion TH-002 in [COLLABORATION.md](../../COLLABORATION.md)):
  - A seated player can reopen tablet mode during an active game after leaving
    that screen, without giving up their seat, resetting the game or creating
    another participant.
  - Add a distinct **Tablet-only account type**, not a player role. It has no
    PIN, earns no statistics of its own, and cannot take a seat or become a
    player participant. It represents a shared table screen.
  - Restrict it to capabilities needed to operate tablet mode, including game
    setup settings. It cannot change unrelated account, administration,
    network, device, firmware or system settings. Define the exact tablet
    operation allowlist before implementation; do not grant general Admin
    access to make tablet mode work.
  - Shared tablet mode can change player life directly, without the ordinary
    approval request. Apply that capability to authorized tablet operations,
    including a seated player's shared-tablet session, without granting the
    same bypass to ordinary personal-controller requests.
  - Atlas must validate account type, table scope and permitted operations on
    the server through the existing semantic action path. Hiding buttons or
    accepting a client-supplied tablet flag is not authorization. Player
    results/statistics remain attributed to the actual players.
  - Acceptance: seated-player re-entry mid-game preserves game/seat state;
    tablet-only access needs no PIN; seat-taking and own-stat creation are
    rejected; game setup and direct life edits work; unrelated settings remain
    rejected even through direct API calls; personal-controller life approval
    remains intact. Verify isolation between the two Atlas games.

- **Two games per Atlas, later rounds** (round one, 2026-10-07: two tables,
  Sigil "Switch game", the portal switch; see PLANNED_DESIGNS.md): the Atlas
  touchscreen game selector (with pairing and turn order for Game 2), a
  native personal/shared-tablet selector is implemented in TH-013, awaiting device acceptance. User manual V0.12
  (section 19) describes round one; update it when these land.
- **Profile picker:** a per-Sigil startup choice (last profile or picker).
- **Accessibility:** Sigil-local pairing/error lights in the player's style,
  e-ink text scale, a monochrome-safe portal
  theme, guest accessibility preferences. LED intensity and buzzer volume wait
  for hardware that can vary them.
- **Device theme acceptance (2026-10-09, PR #82):** owner to check all four
  normal/inverted looks on Atlas and both Sigils, header emblems, e-paper full
  refresh/ghosting, inversion retained through reboot/unpair and cleared by
  factory reset, scanning Atlas QR codes, and calm LED colors with independent
  shared-seat preferences. Host previews/tests and firmware builds passed;
  physical appearance/persistence acceptance is still open.
- **Atlas battery gauge, later rounds** (round one, 2026-10-08: the voltage
  estimate, see HARDWARE.md "Atlas battery"): calibrate the divider and curve
  on the board, the existing Android percent gauge needs device acceptance, and a manual entry once the
  readings are trusted. Auto sleep (2026-10-08: Atlas idle or empty on the
  cell, Sigils idle; HARDWARE.md, PAIRING_AND_SECURE_LINK.md) also needs its
  manual entry, and its USB wake check a bench test.

### Hardware

- **Player-facing Sigil LEDs are required** (owner, 2026-10-09): implement
  the existing GPIO13/J6 front-strip plan on both display variants; choose
  count/location/brightness and verify current and case fit.
- **Dedicated pass/action button alongside joystick** (proposal): settle
  Pass versus contextual Action behavior, then GPIO/carrier/wake design and
  shared semantic input routing. Keep the joystick.
- **Atlas S3/second-radio evaluation:** capture current multi-Android failure
  evidence first. A PSRAM S3 board addresses movable memory pressure; a wired
  radio bridge may isolate transport contention. Neither is a confirmed fix;
  the report records port requirements and a common acceptance matrix.
- **Sigil carrier PCB:** caliper-check the DevKit rows (22.86 mm assumed) and
  test-fit DevKit and Jewel footprints, finish layout and DRC, then inspect
  assembled boards. The OLED PCB is still a placeholder
  ([KiCad](../../KiCad/PCB/Sigilv1/README.md)).
- **Power:** measure idle, radio, display, buzzer, capped LED and sleep
  current; confirm the USB supplies and power banks hold up.
- Freeze hardware revisions only after GPIO, power, display, transport,
  controls and accessibility decisions settle.

## Frozen legacy Sigils (owner, 2026-10-10)

Current e-paper/OLED Sigil feature development is frozen. Future display work
moves to planned ESP32-S3 2.8/4-inch LCD hardware; board specifications, layouts,
firmware targets and artwork transfer/cache remain to be built. Player artwork's
512px SD master and provisional 64/128px app previews are implemented in PR #86;
physical acceptance of crop fidelity, card removal/reinsert, approval and Atlas
thumbnail display remains outstanding. Background artwork and standalone local
player images from TH-003 remain planned separately.

Shared tablet credential handoff is implemented in PR #86: Game-tab entry,
automatic replacement of this device's personal token with the restricted
Shared tablet account, and signed-out exit. Physical simultaneous tablet/phone
sign-in and exit/reconnect acceptance remains pending.

## Parked: storage batch

*Planned.* Proposed and parked by the owner (2026-10-06): do these together, since
both need a USB flash and a factory reset.

- **Larger NVS partition.** `min_spiffs.csv` gives NVS 20 KB (about 500
  entries) and each profile uses about 20, so the real ceiling is about 20
  profiles, not the 64 the code allows (*Needs verification*: estimated
  from code, not measured). Fix: a custom partition table with a bigger NVS.
- **Slow PIN and password hash.** Today it is one SHA-256 over the profile ID
  and secret (`web_session.cpp`), which a flash dump can brute-force. Fix:
  PBKDF2 via mbedTLS. Full protection also needs flash encryption (eFuse), a
  release-time decision.

Decided at the same time: storage stays NVS plus checksummed SD blobs, with
no SQL database. SQLite would add RAM pressure and power-loss risk on FAT,
and would make the card required. Revisit only for full per-match history, which would use
append-only files on the card.

## Open checks

Hardware checks that need a deliberate bench setup. Record runs as
`ID | PASS/FAIL | build | device(s) | evidence` here until they pass, then
delete the line. A host or compile result never checks off a hardware line.

- [ ] **C06** Multi-phone stability matrix ([Diagnostics](DIAGNOSTICS.md)).
- [ ] **R05** Cut power at completion before the finished-match checkpoint
  commits: counts don't advance and the match stays recoverable.
- [ ] **R06** Cut power after the checkpoint, during profile writes: restarts
  as Game Over and ending it again can't increment counts (missing or partial
  results are the known limit).
- [ ] **R07** Failed or uncertain NVS commits and corrupt or future recovery
  records: statistics fail closed, errors show in diagnostics, records kept.
- [ ] **D04** Swap the card during and after a game: no double counting, a
  different card works, the NO SD CARD warning follows.
- [ ] **D05** Log rotation on a real card stays bounded; slow writes don't
  disrupt input, radio or display.
- [ ] **U06** Interrupt an update (Wi-Fi drop, Sigil power cut, package
  upload, Atlas restart mid-job) and install a signed image that fails to
  reconnect: everything recovers and the bootloader rolls back without USB.
- [ ] **S09** Secure Link negatives: Reject, the 60 s timeout, portal Codes
  match, eight Sigils at once, forged/replayed/cleartext packets refused.
- [ ] **G11** Playtest Sigil Commander entry and partners (Sigil 0.9.10) and
  shared-Sigil turn order (2026-10-05).
- [ ] **G13** Playtest Two-Headed Giant (2026-10-06): four players on separate
  Sigils and on two shared Sigils, Magic and Commander, either teammate
  passing, team life on every client, team concession and the win.
- [ ] **G12** Spare Sigil end to end: make spare, pair without a code, return
  to service over the air, flash-all records it.
- [ ] **H03** Power measurements (above).
- [ ] **F02** Someone unfamiliar with the build sets up, pairs, assigns
  players and plays using only the kit and manual.
- [ ] **F03** Name the accepted candidate with a tag and matching firmware
  and APK packages.

## Production decisions

- Production Sigil transport: ESP-NOW with the Secure Link today; BLE and
  other options not compared on latency, power, count, interference and
  complexity.
- Maximum Sigil count for product hardware (firmware allows 8).
- Two players per Sigil: product feature, optional mode, or prototype only.
- Protocol version negotiation and compatibility messages for released
  hardware; which radio messages need acknowledgement or deduplication.
- Atlas: separate USB-C power and data, input voltage and regulator,
  battery/backup power, a secure element for authenticity.
- Sigil: battery chemistry and form factor; charging approach.
- First reproducible `ATLAS-REV-A` / `SIGIL-REV-A` with BOMs; enclosure
  mounting and docking after power and connectors settle; a
  design-for-assembly review with the PCBA maker.
- A decision log for major product decisions and reversals.

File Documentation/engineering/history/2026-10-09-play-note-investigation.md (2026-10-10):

# Play-note investigation, 2026-10-09

Owner: Codex. Branch: `codex/master`. Reviewed baseline: `5e067f7`.
The owner authorized thorough investigation and small, easy fixes. Changes are
staged locally for review; significant features and hardware changes are proposals.

Confidence: source findings below are **Reconstructed**, the browser and host
results are **Verified** within those environments, and physical acceptance is
**Needs verification**. No Atlas, Sigil or Android device is attached.

## 1. Resume during a win claim — small fix implemented

Both `Android/.../ui/tablet/TabletTable.kt` and `Atlas/web/src/tablet.html`
treated every PAUSED state as an ordinary pause. Their central modal covered
the confirming player's existing Confirm/Deny panel. Atlas's
`handleResumeIntent` correctly rejects resume during a win claim or elimination
selection (`Atlas/src/gameplay_intents.cpp`). Bypassing this validation would
break the confirmation flow.

The tablet clients now leave the central overlay closed during a win claim,
so the scheduled player's panel can answer. Ordinary pause retains Resume.
An elimination selection shows an explanation directing the table to Atlas or
the selecting Sigil, with no invalid Resume action. No authority, permission,
Intent or wire change. The Android standalone game uses this same table view;
its ordinary pause remains available because it reports no pending decisions.

**Verified:** real Chromium page, four virtual players, claim then denial,
another claim with three sequential confirmations, portrait panels, ordinary
resume and elimination-selection display. Atlas's host suites also cover the
authoritative tablet controls and win flow. Android compilation and device
interaction remain unverified.

## 2. Seat B after tablet seating — confirmed implementation restriction

`profile_picker.cpp::buildEntries` offers profiles already seated through a
browser/tablet and marks them as attachable. But
`table_intents.cpp::bindPhysicalProfile` explicitly rejects `addsSeatB && joined`
with "That profile is already at the table; leave there first". This affects
already-seated profiles even with four players. The actual table capacity is
16 players (`turnhub_types.h`), not four. An existing host scenario around
`scenarios.cpp`'s Add seat B tests intentionally encodes this rejection.

Simply removing that rejection is unsafe. `Lobby::replaceController` requires
the destination controller to be unseated and replaces an entire controller
with slot A; it cannot move a browser participant to an occupied Sigil's B.
Binding the profile and ignoring a failed replacement could release its browser
handle while losing its live participation. Mid-game attachment is separately
limited to slot A (`attachInGame`), so it also needs explicit seat-level work.

**Proposed:** add an Atlas-owned operation to move an existing participant to
an empty physical seat, validating profile policy, destination vacancy, game
scope and physical confirmation before any mutation. Preserve participant ID,
profile, starter, and, in-game, life/counters/timing and pending references.
Bind/release controllers only after a successful move, with failure rollback.
Shared Sigil seats currently remain adjacent in lobby order; attaching a
nonadjacent tablet player needs an explicit ordering decision, not a silent
promise that arbitrary turn order survives. Cover full capacity, A/B versus
B/A, nonadjacent players, two games, duplicate selection and binding failures.
This is larger than a minor investigation fix.

## 3. Dedicated pass/action button beside the joystick — recommended trial

`Sigil/src/main.cpp` currently reads four virtual direction keys and GPIO32
joystick click, then routes menus and game actions. There is no separate
pass/action GPIO. The click also wakes the device and, while unpaired and
outside the menu, has a long-hold pairing gesture.

**Proposed:** retain the joystick, add one debounced button, and reuse the
existing semantic action path. During ordinary active play it requests Pass
(or cancels its own pending pass); during a required decision it requests only
the explicitly displayed action. Keep win claim/concede holds and menu safety
rules; a new button must not accidentally inherit pairing or destructive holds.
Settle whether it is a dedicated Pass button or a context-sensitive Action
button before PCB work. GPIO25 is described as unused in current Sigil source,
but check carrier access, electrical loading and wake requirements before
assigning it. GPIO13 is already reserved for the front LEDs; BOOT stays Pair.
Test concurrent joystick/button input and held-button wake without a game action.

## 4. Player-facing LEDs — requirement recorded, hardware path exists

The prior design made the front strip conditional on the case. The owner's
new requirement supersedes that condition. `PLANNED_DESIGNS.md` now records
player-facing LEDs as required.

The Rev A carrier already reserves J6 and GPIO13, with its own level shifter
and 330-ohm resistor. The documented candidate is 6–8 SK6812 RGBW pixels.
Production Sigil firmware drives only the GPIO26 Jewel; it does not drive J6.
The OLED PCB remains a placeholder, so its implementation needs the same
player-facing requirement carried into layout.

**Proposed:** derive both outputs from Atlas's existing semantic LED state and
seat colors, preserving text cues, reduced motion and brightness limits. Start
with the same essential turn/decision cues on both sides. Choose pixel count,
case location, connector/cable clearance and player-eye brightness, then measure
combined ring/strip current. No new dependency or wire field is inherently
needed; a genuinely independent cue or user brightness preference may need a
contract/preference extension. Do not freeze the hardware before these checks.

## 5. Atlas instability with >2 Android clients — cause still unproven

Current Atlas is ESP32-WROOM-32E N4, 4 MB flash and no PSRAM. It configures
eight AP stations, so the symptom is not an explicit two-client cap.
Already implemented: 16 KiB loop stack, health/stack logging, cached state
names, change-driven display/LED sends and a separate ESP-NOW transmit task.
Do not present those as new fixes. The documented historical 73-second send
stall and `ESP_ERR_ESPNOW_NO_MEM` are evidence from older playtests, not a
fresh capture of this build.

Remaining source-level candidates, not confirmed causes:

- Synchronous `server.handleClient()` runs in the same loop that services
  gameplay, display, recovery and input. Slow HTTP handling can delay them.
- Android state polling is serialized at about one second, but seat metadata
  refreshes on every revision change and every fifth unchanged poll. Each
  revision change also launches a session refresh from HomeViewModel, which
  can fetch settings too. Those streams/actions have no shared per-device
  request budget. The session mutex serializes its calls but can accumulate
  redundant refresh work when latency rises.
- `ClientState::revision_` is static across tables, so activity at the other
  table can trigger metadata/session refreshes here too.
- The normal portal polls status, seats, session and counters each second,
  plus slower settings/devices requests. The tablet portal is lighter (one
  state request every 800 ms), but action/visibility-triggered calls can overlap
  scheduled polling; it lacks the normal portal's in-flight guard.
- State JSON still allocates a String per response and grows with players and
  nonzero Commander cells. Extra counters/artwork must not unnecessarily
  increase this burden. ESP-NOW has bounded queues (48 TX, 32 RX/events),
  bounded NO_MEM retries and a 250 ms send-completion wait. Queue pressure and
  HTTP/heap behavior need measurement together.

**Recommended bench:** exact flashed SHA/ELF, USB serial plus SD log, heap and
largest-block trend, loop stack minimum, request durations, queue depth/drops,
send errors and pass latency. First reproduce with 2/3/4 Android clients at
unchanged polling; compare Sigil-only and tablet-only runs, then mixed clients,
both tables, join/leave and slower links. Follow C06's longer 4/8-client matrix.
Use firmware-specific panic decoding. Tune only after a baseline capture and
compare one change at a time. A host suite cannot prove radio stability.

### S3 versus second radio

Espressif's [ESP32-S3 datasheet](https://www.espressif.com/sites/default/files/documentation/esp32-s3_datasheet_en.pdf)
was read for this investigation. It specifies dual cores up to 240 MHz, 512 KB
SRAM, a 2.4 GHz 802.11b/g/n radio, and optional flash/PSRAM variants. An S3
is not automatically more internal SRAM or a second Wi-Fi radio. A suitable
board with PSRAM offers room for movable display/application allocations;
Wi-Fi/internal allocations still need their own budget. It does not prove a
fix for radio contention or blocked handlers.

An S3 port needs a specific display/PSRAM board, GPIO remapping, touch/SD/power
validation, partitions and OTA, and a speaker change: current Atlas uses
`I2S_MODE_DAC_BUILT_IN`/GPIO26, which is not an S3 built-in DAC path. It also
needs validation against the pinned Arduino-ESP32 2.0.17 toolchain or a
deliberate toolchain migration. This is a hardware port, not a board-name edit.

A second MCU/radio could isolate ESP-NOW from phone Wi-Fi via a bounded wired
SPI/UART bridge. Atlas must retain game authority; the bridge owns transport
only. Add framing, flow control, sequence/ack handling, restart behavior and
diagnostics. The board has few spare pins because display, touch, card, speaker,
LED and battery functions already consume them. Two nearby 2.4 GHz radios
also need channel/antenna/coexistence testing.

**Recommendation:** measure first. Prefer a PSRAM-equipped S3 evaluation if
internal heap is the limiting evidence and offloadable allocations are large.
Evaluate a radio bridge if failures correlate with Wi-Fi/ESP-NOW pressure
after application load is controlled. Either prototype should meet the same
multi-client acceptance test; neither is currently an established cure.

## 6. Pixel Fold signup/PIN fields — small mitigation implemented

`ui/home/SignInDialog.kt` used a non-scrolling Column inside ModalBottomSheet.
Create-account fields, account lists, confirm-secret fields, remember controls
and actions can exceed the available height on a Fold or with the keyboard.
The sheet now scrolls using the standard Compose scroll state; Material's
existing inset handling remains responsible for keyboard/window insets.

**Needs verification:** this is a source-supported mitigation, not a device
reproduction. Check folded/unfolded, portrait/landscape, keyboard open, large
text, long account lists, field focus, create/sign-in and rotation. Include the
7- and 10-inch tablets. Further bring-into-view work depends on those results.

## 7. Non-turn breathing — deliberate current behavior, decision open

`Sigil/src/sigil_led.cpp` sets Waiting to a constant level of 64/255. It
already renders the seat's custom color (or the theme's calm default), including
separate A/B halves. YourTurn breathes for A and double-pulses for shared B.
The absence of waiting breathing is therefore not a broken animation.

**Recommendation:** allow a gentle optional waiting breathe in the custom
seat color, with a dimmer/narrower range and longer period than the turn cue.
Keep reduced-motion waiting steady, preserve monochrome-safe differences and
give turn/decision/timer overlays priority. A preference must be Atlas-owned;
adding a setting requires the accessibility/preference and radio contracts to
be designed. The owner has not yet chosen this behavior; no LED code changed.

## 8. Free a Sigil after all its players are eliminated — needs detachment

Elimination preserves the game's player/controller records for results and
rematch. `sigil_menu.cpp::canTakeOverPlayer` refuses a controller already in
the game, `attachInGame` refuses an occupied controller, and `ChooseTable`
refuses one still in a game. The restriction remains even when all its seats
are eliminated. Unpairing hardware is a separate lifecycle operation and
does not provide identity-preserving game detachment.

**Proposed:** explicit Release controller, validated by Atlas only when every
seat on it is eliminated and no decision/entry depends on it. Preserve each
eliminated participant/profile, life/counters and stats in the original match,
move its live controller references to virtual/detached seats, release the
physical A/B bindings and then expose the normal attach picker. Preserve the
old game's recovery and define rematch behavior when hardware is now used
elsewhere. Cover one survivor refusing release, shared seats, two games,
reboot and no double statistics. Reuse seat-level reassignment work from #2.

## 9. Poison, commander tax and other counters — cross-layer feature

Connected GameEngine currently has life and source-specific Commander damage;
`ChangeCounter` means Commander damage, not a generic named counter. HTTP
state/schema, Android models and the standalone engine likewise lack the
requested general counters. A UI-only addition would lose canonical/recovery
state and split behavior between clients.

**Proposed:** a small bounded counter vocabulary (poison, commander casts/tax,
energy, experience; settle the initial list). Add Atlas-owned per-participant
values and one validated semantic counter mutation; persist in match recovery,
reset on new matches and render/edit through tablet, web and app. Mirror the
separate state in Android standalone play and local match records. Extend
contracts and signed-size/recovery tests deliberately.

Poison is bookkeeping and must not auto-eliminate. Commander tax should
distinguish commander 1/2 and preferably track command-zone cast count, with
the standard +2-per-prior-cast display and manual correction; settle whether
the owner instead wants an editable mana-tax total. It is not Commander
damage and must not change life. Decide bounds, team ownership and which
counters count as "received" in statistics; tax is not naturally a received
counter. Preserve labeled text, large touch targets and no new dependencies.

## 10. Modified order / gift an extra turn — scheduled turns, not seat moves

`Lobby::moveSeat` is lobby-only. `GameEngine::passTurn` selects the next living
player/team in circular order; neither engine has an extra-turn schedule.
Moving seats or force-passing repeatedly would distort timers/statistics and
permanent order.

**Proposed:** an Atlas-owned bounded queue of temporary turns, separate from
base order, with explicit Grant/cancel extra turn Intents validated for the
current table. On pass, consume the appropriate scheduled turn, then resume
at the correct base-order cursor. Record completed turns and time normally;
do not mutate participant numbers. Capture the queue/cursor in recovery and
clear at new games. Display who goes next and why on all clients; the Sigil's
next-player display/protocol needs review. Standalone needs equivalent local
behavior under its existing separate-game exception.

Open decisions: who may grant/cancel, immediate versus after-a-specified-turn
insertion, multiple-grant order (Magic's most recently created extra turn goes
first), self turns, skipped turns and team turns. Test eliminated recipients,
multiple/self grants, pass grace/cancellation, pause, claims and reboot before
implementation. No new dependency; edits need accessible confirmation/undo.

## Shared-screen win-claim UX follow-up

Fix #1 restores the existing flow for players with no other input device;
the browser regression exercises exactly that case. Beyond this fix, show the
claimant and responding player, progress through the remaining confirmations,
and a waiting message on other panels. Prevent drawers/life controls from
competing with decisions, keep the prompt facing the responder, and test teams,
shared Sigils, 2–8 panels and disconnected sessions. Preserve sequential Atlas
confirmation and explicit denial. Consider a prominent claim action with its
existing confirmation gesture instead of hiding it exclusively in More.

## Validation and next work

### Owner follow-up: router-style web administration

The owner is considering retiring browser gameplay and concentrating on the
Android app (estimated >90% of expected use; not measured telemetry). This is
a proposed product direction, not authorization to delete the current portal.
Whether the shared `/tablet` browser page retires too is being clarified.

Follow-up decision, owner 2026-10-09: web administration and app play are now
the planned direction, including shared tablet play. The completed
[portal/app parity audit](2026-10-09-portal-app-parity.md) identifies migration
gaps and supersedes the provisional scope below; no pages have been removed.

**Recommended boundary:** web administration for Atlas setup, network/device
settings, account permissions, signed firmware/portal updates and diagnostics;
Android for personal play, shared tablet play, counters, win claims, seating
and history. Retain Atlas as game authority and preserve the HTTP API used by
Android. `/api/v1/state`, session/profile endpoints, `/api/control/*` and
`/api/tablet/*` are also app transports, despite their names and source files.
Do not remove them when deleting browser buttons. API authentication and
per-operation authorization must remain; absence of browser UI is not an
app-only security boundary.

Scope of a deliberate retirement slice:

1. Inventory app parity for seating A/B, turn order, claims, moderation,
   counters/history and controller management. Complete blocking app flows
   before removing their only usable client path.
2. Settle first-Admin bootstrap and recovery. A fresh/factory-reset Atlas has
   no Admin, so a blanket Admin gate needs a limited setup exception or an
   app/touchscreen bootstrap. Preserve sign-in for existing administrators.
   Diagnostics currently requires Developer; explicitly decide its portal
   visibility without silently broadening API permissions.
3. Replace the full SD portal and the flash basic fallback with the same
   administration scope. Retire browser game/player controls, stats/profile
   play pages, and `/tablet` if chosen. Update navigation, root/QR landing,
   signed portal pack contents/version and remove obsolete browser assets,
   strings and smoke tests together. Existing installed/cached packs need
   a cutover check so old gameplay pages do not persist by accident.
4. Preserve an administration/update path when the card or app is unavailable.
   Native play means an iPhone/browser-only player loses personal web control;
   a shared Android tablet and physical Sigils remain alternatives. Decide
   that product tradeoff explicitly.
5. Validate authorization on every retained settings action, initial setup,
   cardless fallback, firmware recovery and all app game APIs. Rewrite the
   manual and references around the final boundary.

This reduces duplicated UI, assets and browser polling, but Android polling and
the shared radio are still present. It is not itself proof of a multi-Android
stability fix. Prioritize app counters and win UX; defer new browser gameplay
features while this direction is reviewed. The small staged portal overlay fix
and its regression remain useful evidence for current firmware and can be
removed with the retired page in the cutover slice.

- Atlas application/storage/profile-store/OTA host suites: passed with
  ASan/UBSan, `ASAN_OPTIONS=detect_leaks=0` (workspace tracing prevents LSan).
- Client contracts: passed, 10 generated HTTP/projection responses and
  10 shared fixtures. Adapter audit: passed, 31 adapters.
- Real tablet browser regression: passed using local Chromium and Playwright.
  Run `node Atlas/tests/host/tablet_smoke.cjs`; optionally set
  `PLAYWRIGHT_EXECUTABLE_PATH` or `PLAYWRIGHT_CHANNEL` for the installed browser.
- Portal pack check: passed (1.3.3, 20 files). Whitespace check: passed.
- Android build attempt blocked before compilation: Gradle distribution is
  not cached and its default lock path is outside writable workspace roots;
  no configured Android SDK is available. No Android build/test pass claimed.
- PlatformIO unavailable; no new firmware code was changed. No firmware
  build, flashing, hardware stability or physical layout/LED test claimed.

Recommended order: review the minor UI fixes; implement/test seat-level B
attachment; capture Atlas stability while device-checking Fold/win flows;
reuse seat reassignment for eliminated-controller release; settle button/front
LED hardware together; then counters and temporary-turn scheduling.

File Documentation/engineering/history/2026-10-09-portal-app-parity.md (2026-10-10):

# Portal versus Android feature audit

Date: 2026-10-09. Author/owner: Codex. Branch: `codex/master`.
Baseline: `5e067f7`, plus the staged tablet-overlay/signup fixes from TH-011.

The owner confirmed the planned direction: **web portal for administration,
Android app for play**, including shared tablet play. This audit identifies
what must move, what already exists, and what can remain in the admin portal.
No gameplay pages, APIs or app features were removed or implemented here.

Evidence is **Reconstructed from source**, not device acceptance. The audit
examined full portal pages and the flash basic fallback, Android UI entry
points/callback wiring, repositories/transports, protocol models and Atlas
handlers. Finding an endpoint or an unused UI component does not establish a
reachable app feature. No new builds/tests were needed for this documentation
slice; previous TH-011 results do not establish Android parity on devices.

## Confirmed differences

| Feature | Current portal | Reachable Android app | Recommended disposition |
|---|---|---|---|
| Select/follow Game 1 or Game 2 | Main portal lists both games with state/player counts; signed-in switching uses `/api/session/game`, signed-out viewing uses `?game=N` | No game selector, session-game call or equivalent game-scoped polling path | Move before retiring web play; include personal and shared-tablet selection |
| Enter a custom turn duration | Game setup has Custom seconds, 15–3600, alongside presets | Current GameTab setup offers presets plus an already-configured custom value; cannot enter a new arbitrary duration | Move into active game setup before retirement |
| Attach an unseated paired Sigil from the phone | Paired-device cards offer Attach seat A to my profile in the lobby, even when the device has no table seat | PlayersTab offers Use this seat only for physical players already in the roster; Settings device cards offer administration, not attachment | Add a normal-player paired-device picker and attach action; reuse existing physical confirmation |
| Player invite QR generation | Invite players displays portal and sign-in QR codes | App displays instructions/portal address and refers to Atlas's QR; it scans Admin presence codes but does not generate player invitations | Replace with app-oriented invite/install/connect flow; retire old portal-play links |
| Configurable local sound and vibration feedback | Browser sound on/off, vibration on/off, volume Low/Medium/High, test feedback; tones for turn, decision, pause/resume and game over | Themes/reduced motion, action/turn/nudge haptics and Android turn notification exist; no matching in-app event-sound, volume or vibration preferences, or win-decision notification alert | Define native feedback defaults/settings; prioritize a clear decision-needed alert |
| Device hardware tests | Developer page selects Atlas/Sigil and starts screen, buzzer and Sigil light tests | Developer UI has activity/raw JSON/log sharing, but no hardware-test action or `/api/device/test` client call | Keep in web administration/diagnostics; optional later app convenience |
| Upload a local signed firmware/portal package | `/update` accepts a selected `.thfw` for Atlas or portal; Sigil update page accepts a local package and lets the admin choose one compatible device | Update assistant downloads release-feed packages and uploads them; no local file picker/manual signed-package installation UI | Keep in admin web as recovery/development path; optional later app support |
| Choose one Sigil to update manually | Web Sigil page explicitly selects a target | App's release-update flow constructs a batch of outdated devices; no equivalent arbitrary local-package target picker | Keep in web administration unless per-device app maintenance is requested |

The first three are the clearest gameplay capability gaps. Invites need a
cutover redesign because their current destination becomes administration.
Feedback is partial parity, not a complete absence of turn/vibration support.
Hardware tests and local update uploads need not delay gameplay retirement if
they remain usable in the admin portal.

### Source evidence for the gaps

- Game selection: [portal index](../../../Atlas/web/src/index.html),
  `renderGameSwitch`, `forGame` and the `/api/session/game` handler;
  [Atlas session handler](../../../Atlas/src/web_session.cpp),
  `handleSessionGame`. No corresponding app request/UI was found. Current
  `TableSummary`/state polling does not supply a selectable list of games.
- Custom timer: [GameTab](../../../Android/app/src/main/java/com/turnhub/android/ui/home/GameTab.kt),
  `SetupCard` builds a dropdown from presets and the current value.
  [PlayerPanelCard](../../../Android/app/src/main/java/com/turnhub/android/ui/home/PlayerPanelCard.kt)
  contains `TurnTimerSetting` with custom input, but the production UI has no
  call to `PlayerPanelCard`; its view-model setter is not wired from MainActivity.
  The data-layer game-settings action already accepts a timer value.
- Empty Sigil attachment: portal `renderDevices` supplies the action;
  [PlayersTab](../../../Android/app/src/main/java/com/turnhub/android/ui/home/PlayersTab.kt)
  derives claim buttons from `summary.players` only. `SettingsTab::DeviceRow`
  has Rename/Forget/Factory reset, with no attach action.
  [AtlasPlayerSession](../../../Android/app/src/main/java/com/turnhub/android/data/AtlasPlayerSession.kt)
  already implements `claimSeat(module, slot, ...)`, so much of the request
  path exists. Pairing and selecting the profile directly on the Sigil remain
  alternatives, but do not replace the portal's phone-side workflow.
- Invites: portal `renderInviteCodes` generates `/portal` and `/login` URLs.
  PlayersTab has explanatory text only; the app's `QrScanner` is a decoder.
  AndroidManifest currently declares only launcher navigation, not an app-join
  deep-link handler. An app invitation needs a deliberate payload/navigation
  design, not a copied web-login QR.
- Feedback: portal `saveBrowserPrefs`, `playFeedback` and
  `processBrowserFeedback`; app `AccountTab::AppearanceCard`, `Haptics.kt`,
  `GameTab::StageCard`, `LiveTurn` and `TurnNotifier`. The notification models
  turns/paused state, not a win-confirmation-needed alert. System notification
  channel controls are distinct from the portal's foreground event settings.
- Hardware tests: [web Developer page](../../../Atlas/web/src/dev.html),
  `runHardwareTest`; [app DevTab](../../../Android/app/src/main/java/com/turnhub/android/ui/home/DevTab.kt)
  and `AtlasAdminConsole` offer monitoring and logs only.
- Local updates: web `update.html` and `sigil-update.html` file inputs;
  app `SetupScreen` and `AtlasSetupAssistant` implement release discovery,
  download, Atlas/portal upload and Sigil batches, with no file-selection path.

## Features already represented in the active app

“Present” below means reachable UI and request wiring were found in source;
it does not claim successful physical-device testing.

| Area | App coverage found | Evidence / important limit |
|---|---|---|
| Account registration/sign-in/logout | Present, including PIN/password and first-secret confirmation | SignInDialog, HomeViewModel, AtlasPlayerSession; Fold scrolling mitigation is staged |
| Phone participation and controls | Join/leave, starter selection, start/cancel countdown, pass/cancel pass, pause/resume, claim/confirm/deny win, concede, rematch/reset, nudge | GameTab, ControlAction, MainActivity/HomeViewModel wiring and session transport |
| Life totals and edits | Own preset/custom edits, other-player requests, accept/reject and outgoing status | GameTab life/request controls; same authoritative Atlas operations |
| Commander damage | Source and commander 1/2 selection, signed corrections, life coupling, displayed totals | GameTab CommanderCard and counter requests |
| Game setup | Profile, starting life, Two-Headed Giant, timer presets/current custom value | GameTab SetupCard; arbitrary new timer input is the gap above |
| Roster and game presentation | Names, avatars, life, active turn/timers, passing, elimination, winner, team grouping and Commander totals | GameTab/PlayersTab and TableSummary |
| Existing physical seat linking | Use this seat with Link phone approval, A/B slots, existing-profile sign-in | PlayersTab, SeatActions, AtlasPlayerSession; empty paired-device selection is missing |
| Shared tablet access/seating | Enable with role/presence grant, add new/saved players, PIN prompts, unseat, earlier/later ordering, profile/life/team setup | TabletScreen, AtlasTablet |
| Shared tablet play | Oriented player/team panels, life, Commander damage, pass/cancel, pause/resume, win claims, confirmations, concede, rematch/reset | TabletTable; claim overlay fix staged; no multi-game selector |
| Personal profile/privacy | Rename, set/remove secret subject to rules, physical-without-PIN policy, stats privacy | AccountTab/AtlasPlayerSession |
| Player personalization | Preset avatar and custom Sigil seat color/standard colors | AccountTab, personalization transport |
| Sigil accessibility | Sound, LED style, hold thresholds, life-approval window | AccessibilityDialog and session transport |
| App appearance | Automatic/Graphite/Daylight/Brass/Contrast and reduced motion | AccountTab/Theme; local feedback preferences are separate missing controls |
| Profile statistics/export | Lifetime, turn/time records, last game, private moderation history and JSON sharing | StatsSheet/ProfileStatistics, exportStats, MainActivity shareStats |
| Game Master tools | Force pass, connection reset, removal, nudge mute subject to sub-permissions | PeopleSheet, AtlasAdminConsole, MainActivity callbacks |
| Account administration | Roles, initial Admin protection, archive/restore | PeopleSheet, AdminConsole |
| Atlas/device administration | Presence code and QR scan, table-code switch, network password, paired device names/forget/reset, pairing decisions, speaker/pair window, table reset/factory reset | SettingsTab/AdminConsole |
| Setup and release updates | Initial-Admin onboarding, Wi-Fi setup, release-feed Atlas/Sigil/portal updates, restart/reconnect | SetupScreen/AtlasSetupAssistant; local file upload differs |
| Diagnostics | Activity feed, status/devices/seats/runtime panels, serial-log sharing | DevTab/refreshDeveloper; hardware tests differ |

The app also adds standalone local play, saved local players/history and
optional finished-match import, automatic network joining/sign-in and turn
notifications. These are not portal capabilities that need migrating.

## Similar workflows that do not require exact copies

- Portal seat-based PIN login has an app equivalent: select the seat owner's
  profile and sign in; existing participation follows that profile. A dedicated
  seat-specific PIN dialog is convenience, not a missing authorization path.
- Portal statistics downloads a JSON file; the app shares the same export
  response through Android. If a guaranteed local Save file action is desired,
  add it deliberately; basic export capability is already present.
- Portal offers additional ±10 life shortcuts in some formats; the app's custom
  delta supports the same value, so this is a speed-of-entry difference.
- Portal paired-device cards expose more metadata (age/capability details).
  The app has an admin device list/raw diagnostics but not an equivalent
  normal-player device browser. Add the needed player-facing metadata with the
  empty-Sigil attachment flow instead of exposing admin controls to players.
- Both shared tablet screens omit the main portal's custom timer editor; the
  app's personal Game setup must be complete before that portal editor goes.

## Shared gaps, not features lost from the portal

Seat B attachment to an already-seated tablet profile, controller release
after elimination, poison/tax/general counters and gifted extra turns are not
complete in either client. They stay on the play-note backlog, with Android
as the target play UI. Likewise tablet-only account semantics, richer tablet
artwork and re-entry require the separately staged work; do not count them as
existing web capabilities merely because designs or endpoints are mentioned.

## Cutover plan

1. Finish app game selection and scope all polling/actions to the selected
   table. Respect Atlas's profile-in-one-game rules; handle tablet sessions
   separately. Isolate state/name/queued-action caches when changing tables.
2. Add custom timer entry to the active setup card and paired-Sigil attachment
   to the normal Players UI. Keep Atlas validation/physical confirmation.
3. Redesign player invitations and notifications/feedback for app play. Verify
   the staged Fold and win-claim fixes, teams, shared seats and two games.
4. Replace both SD and flash portal gameplay with Admin administration while
   retaining setup/bootstrap, diagnostics, hardware tests and manual signed
   updates/recovery. Specify Developer versus Admin visibility explicitly;
   current diagnostic API permissions must not silently broaden.
5. Retire `/tablet`, `/stats` and personal gameplay/profile pages after their
   app paths are accepted. Keep administrator sign-in and every HTTP API the
   app needs, including `/api/tablet/*`. Replace old invitations/QR links and
   manual copy. Check installed/cached portal packs during cutover.

Acceptance should verify each surviving web-admin feature plus all migrated
app flows on devices. This audit documents the source comparison; removal and
implementation are separate reviewable work.

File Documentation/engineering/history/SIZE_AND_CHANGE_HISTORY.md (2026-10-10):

# TurnHub Size and Change History

This document tracks engineering growth over time without replacing Git history.
Git commits remain the authoritative record of exact changes. This file captures
repeatable size snapshots, firmware footprint measurements, and notable milestones
so growth can be reviewed without reconstructing every checkpoint manually.

## What to track

At meaningful development checkpoints, record:

- commit SHA and firmware version
- raw source-file sizes for Atlas and Sigil firmware
- largest or fastest-growing source files
- PlatformIO RAM and flash usage when a real build is available
- major added/removed behavior at that checkpoint
- notable commit diff size for large milestones

Raw source sizes are Git blob byte sizes, not compiled firmware size. They are useful
for identifying concentration and growth, while PlatformIO RAM/flash measurements
remain the relevant device-capacity figures.

Update this file at release candidates, firmware-version changes, major architecture
milestones, and unusually large feature commits. It does not need an entry for every
small documentation or bug-fix commit.

## Baseline snapshot: 2026-09-21

Checkpoint: `810731439c85b5a9d6c3d1295df5583c3edeee1c`
Atlas firmware line: `0.6.0-dev`

### Source footprint

| Scope | Files | Raw bytes |
| --- | ---: | ---: |
| `Atlas/src` | 18 | 257,579 |
| `Sigil/src` | 2 | 29,349 |

Largest current implementation files:

| File | Raw bytes |
| --- | ---: |
| `Atlas/src/main.cpp` | 62,912 |
| `Atlas/src/web_api.cpp` | 43,176 |
| `Atlas/src/web_pages.cpp` | 42,129 |
| `Sigil/src/main.cpp` | 18,014 |
| `Atlas/src/game_engine.cpp` | 13,851 |
| `Atlas/src/led_renderer.cpp` | 13,448 |
| `Atlas/src/sigil_bus.cpp` | 12,517 |
| `Sigil/src/sigil_display.cpp` | 11,335 |
| `Atlas/src/ota_manager.cpp` | 11,180 |
| `Atlas/src/profile_store.cpp` | 10,771 |

`main.cpp`, `web_api.cpp`, and `web_pages.cpp` are the main concentration points to
watch during hardening. File size alone is not a refactor trigger, but continued
growth should prompt a boundary review before adding another unrelated responsibility.

### Comparison with ESP32-port merge baseline

Checkpoint: `6844f94910c6e25d4e4ddd044119a4b7afeb8d2a`

| Scope | Merge baseline | 2026-09-21 | Change |
| --- | ---: | ---: | ---: |
| `Atlas/src` raw bytes | 228,180 | 257,579 | +29,399 (+12.9%) |
| `Atlas/src` files | 14 | 18 | +4 |
| `Atlas/src/main.cpp` | 56,159 | 62,912 | +6,753 |
| `Atlas/src/web_api.cpp` | 36,199 | 43,176 | +6,977 |
| `Atlas/src/web_pages.cpp` | 39,868 | 42,129 | +2,261 |
| `Atlas/src/lobby.cpp` | 8,090 | 9,408 | +1,318 |
| `Atlas/src/profile_store.cpp` | 9,269 | 10,771 | +1,502 |

The growth from the merge baseline primarily reflects profile-independent browser
login/participation, logical controller registration, storage boundaries, and related
verification support rather than duplication of the game engine.

## Historical firmware footprint records

These values are preserved from engineering verification documents and should not be
silently compared across toolchain changes without noting the build environment.

| Checkpoint | RAM | Flash | Notes |
| --- | ---: | ---: | --- |
| Intent migration verification, 2026-09-19 | 47,908 bytes | 924,281 bytes | Clean Atlas build before LED follow-up |
| Pairing-LED mock follow-up | 47,924 bytes | 924,797 bytes | Five-second visual PairRequest mock added |
| Identity/storage foundation | 47,940 bytes | 925,265 bytes | Blob/NVS statistics boundary and identity groundwork |
| Current `0.6.0-dev` profile-login build | not yet recorded here | not yet recorded here | Record next confirmed PlatformIO build output |
| Local profile-policy slice, 2026-09-21 | 51,628 bytes | 953,345 bytes | Uncommitted changes based on `0cbb707`, still `0.6.0-dev`; Atlas build only, no flash |
| Local game profiles and life totals, 2026-09-21 | 51,748 bytes | 967,273 bytes | Includes profile-policy slice and diagnostics; same toolchain, uncommitted `0.6.0-dev` based on `0cbb707`; build only, no flash |
| Local accounts, moderation and portal cleanup, 2026-09-21 | 51,764 bytes | 983,505 bytes | Includes prior local slices; same toolchain and baseline; focused tests/build passed, not flashed |
| Local life approval and Commander counters, 2026-09-22 | 59,036 bytes | 1,012,233 bytes | Based on `34a0363`, branch `codex/manual-v02-gameplay`; same toolchain, native/storage/browser checks and adapter audit passed; not flashed |

The local profile-policy build used Espressif32 7.1.3, Arduino ESP32
`4.20017.260907+sha.dcc1105b`, and Xtensa toolchain `8.4.0+2021r2-patch5`.
It is not a measurement of the unchanged profile-login baseline above.

A future automated build should capture RAM/flash usage directly into CI or a generated
artifact so this ledger does not depend on manual transcription.

## Notable change ledger

### `6844f94` - Atlas ESP32 port merged

- ESP32 Atlas becomes the accepted `master` baseline.
- Authoritative Intent migration, ESP-NOW Sigil transport, portal, profile/statistics,
  OTA, LED/audio, and native regression framework are integrated.

### `a9b0555` - profile login, virtual play, identity/storage expansion

Large feature commit: 2,256 additions and 429 deletions across the repository.

- firmware version advances to `0.6.0-dev`
- browser profile registration/login no longer requires a physical Sigil
- phone-only and mixed physical/phone games share Atlas Intent handlers
- controller identity is separated from physical radio module identity internally
- NVS blob/storage boundaries and additional identity groundwork are introduced
- native and portal smoke verification are expanded
- physical profile selection is explicitly documented as the next remaining reuse gap

### 2026-09-21 documentation sync

The engineering record was brought into line with current `0.6.0-dev` behavior:

- Prototype 1.0 field-test priority lane added
- interrupted-match recovery target documented
- current persistence limitations clarified
- `controllerId` terminology corrected in Intent documentation
- pairing/recovery verification items added
- root and Atlas READMEs updated to stop describing the Raspberry Pi as the current Atlas

### 2026-09-24 - turn timer and LED/audio cue layers (`android/testing`, uncommitted)

Large feature change; firmware version unchanged (`0.6.0-dev`).

- Atlas-owned turn timer (Off/presets/custom), 10 s warning, non-gameplay expiry cue
- LED selection separated from styling (`led_cues.h`); audio cue profile with mute
- `gamecfg` schema 2; HTTP state/settings additions; no radio-contract change
- Android player slice UI (sign in, join, PASS, pause/resume, sign out, host timer)

Atlas `pio run -e atlas`, same toolchain, measured against the parent commit `cac3a68`:

| Build | RAM | Flash |
|---|---:|---:|
| `cac3a68` (before) | 73,860 B (22.5%) | 1,046,965 B (79.9%) |
| This change | 74,780 B (22.8%) | 1,053,261 B (80.4%) |

The RAM growth is the two static default cue tables.

### 2026-09-24 - web portal redesign and selectable themes (`claude/tender-cerf-84yd8v`)

Large presentation change; firmware version unchanged (`0.6.0-dev`). No gameplay,
Intent, storage or protocol change.

- New shared `/theme.css` (`THEME_CSS`) linked by portal, login, stats, dev and update pages
- Four per-browser themes: Brass (default steampunk), Midnight, Parchment, High contrast
- Portal relayout: brass turn gauge, life tiles, phone bottom tab bar, themed dialogs
- See [Web Portal Design System](../WEB_PORTAL.md)

Embedded page text (raw-string literals in `web_pages.cpp`, `profile_login_page.cpp`,
`stats_page.cpp`, `ota_manager.cpp`): 92,995 B → 131,098 B (+38,103 B, all in flash).
Compiled RAM/flash was **not measured** for this change: no PlatformIO build was
possible in the authoring environment. Record a `pio run -e atlas` figure before
treating the ~3-point flash increase over 80.4% as confirmed.
The first measured build that contains this change is in the reorganization
entry below (83.7% flash).

### 2026-09-24 - code review and module reorganization (`claude/code-review-cleanup-cn4zoy`)

Major architecture milestone; firmware version unchanged (`0.6.0-dev`). Behavior,
Intents, storage schemas and the radio contract are unchanged, apart from removing
the unused `/api/device/persistence` endpoint and the always-false `persistentA`
device field (see [Physical Profile Selection](../PLAYERS_AND_ACCOUNTS.md)).

- `main.cpp` split along the Intent boundary into the modules declared in
  `atlas_app.h`; `handleTableIntent` becomes focused per-IntentType handlers.
  `main_internal_fwd.h` and its `-include` flag are gone.
- `web_api.cpp` split into session, profile, game and admin modules behind
  `web_api_internal.h`; shared JSON escaping in `json_text.h`.
- Duplicates merged (debounce, Wi-Fi password store, JSON escapers, reconnect,
  error responses, life bound `LIFE_LIMIT`); unused `SigilBus::injectEvent` removed.
- `audit_adapters.py` now scans the adapter modules and rejects direct handler calls.

Measured against the branch base `fdd8659` (Git blob bytes):

| Scope | `fdd8659` | This change |
| --- | ---: | ---: |
| `Atlas/src` | 25 files, 433,424 B | 36 files, 443,177 B |
| `Atlas/include` | 36 files, 116,388 B | 39 files, 142,494 B |
| `Sigil/src` | 2 files, 38,058 B | 2 files, 38,882 B |
| `Atlas/src/main.cpp` | 91,005 B | 14,803 B |
| `Atlas/src/web_api.cpp` | 72,178 B | 7,477 B |

The largest logic file is now `table_intents.cpp` (27,131 B); `web_pages.cpp`
(115,176 B of embedded portal text) is unchanged apart from one dead function.
Source growth is interface documentation and one-statement-per-line formatting.
Compiled RAM/flash, measured afterwards on the same branch (after a C++11
constructor fix in `front_panel.cpp`, the only compile error the reorganization
left), with the same toolchain as above (Espressif32 7.1.3, Arduino ESP32
`4.20017.260907+sha.dcc1105b`, Xtensa `8.4.0+2021r2-patch5`). The Atlas figure
also includes the portal redesign and the 16 KB serial-log ring, neither of
which had been measured, so it is not a pure delta for the reorganization:

| Build | RAM | Flash |
|---|---:|---:|
| Atlas `pio run -e atlas` | 91,340 B (27.9%) | 1,097,033 B (83.7%) |
| Sigil `pio run -e sigil` | 48,360 B (14.8%) | 769,037 B (58.7%) |
| Sigil `pio run -e sigil-wokwi` | 48,336 B (14.8%) | 793,713 B (60.6%) |

Build only; nothing was flashed.

### 2026-09-24 - per-player Sigil accessibility (`claude/code-review-cleanup-cn4zoy`)

Large feature change. Sigil firmware `0.5.3-dev` -> `0.5.4-dev` (adjustable hold
timing needs a Sigil reflash); Atlas stays `0.6.0-dev`; radio protocol version 1
with a new backward-compatible `InputTiming = 24` packet.

- Per-player Sigil sound, light style and hold times stored with the profile
  (`x<profileId>`), merged per Sigil; reduced-motion and monochrome-safe LED
  profiles; per-Sigil mute; `ActionRequired` emitted
- `GET/POST /api/session/accessibility`; portal Sigil accessibility card,
  reduce-motion switch and OS-contrast default; Android editor and high-contrast theme
- New `Atlas/src/sigil_accessibility.cpp`, `Atlas/include/accessibility_prefs.h`

Same toolchain as the reorganization entry above, measured before and after:

| Build | Before | After |
| --- | ---: | ---: |
| Atlas RAM | 91,340 B (27.9%) | 92,724 B (28.3%) |
| Atlas flash | 1,097,033 B (83.7%) | 1,111,241 B (84.8%) |
| Sigil RAM | 48,360 B (14.8%) | 48,360 B (14.8%) |
| Sigil flash | 769,037 B (58.7%) | 769,285 B (58.7%) |
| Sigil (Wokwi) flash | 793,713 B (60.6%) | 793,957 B (60.6%) |

The Atlas RAM growth is the two extra static LED profiles and per-Sigil state;
the flash growth is mostly portal text. Build only; nothing was flashed.

### 2026-09-24 - draw ending, forgetting pairings, pairing window (`android/testing`)

Sigil firmware `0.5.4-dev` -> `0.5.5-dev` (10-second Pair hold forgets; honors
`Unpair`); Atlas stays `0.6.0-dev`; radio protocol version 1 with a new
backward-compatible `Unpair = 12` packet.

- `EndMatch` (5 s master-button hold ends a match as a draw), `ForgetPairing`
  and `ConfigurePairing` Intents; `Draw` last-game result (byte 4, v1-compatible);
  recovery validator accepts a finished match without a winner
- `POST /api/device/forget`, `GET/POST /api/pairing`; portal Paired Sigils card;
  new header `Atlas/include/pairing_settings.h`

PlatformIO on Linux; "before" is `master` at `af5d770` built with the same
toolchain (it reproduces the previous entry's Atlas and Sigil figures):

| Build | Before | After |
| --- | ---: | ---: |
| Atlas RAM | 92,724 B (28.3%) | 92,780 B (28.3%) |
| Atlas flash | 1,111,241 B (84.8%) | 1,119,653 B (85.4%) |
| Sigil RAM | 48,360 B (14.8%) | 48,360 B (14.8%) |
| Sigil flash | 769,285 B (58.7%) | 770,509 B (58.8%) |
| Sigil (Wokwi) RAM | 48,368 B (14.8%) | 48,440 B (14.8%) |
| Sigil (Wokwi) flash | 795,441 B (60.7%) | 798,109 B (60.9%) |

Build only; nothing was flashed.

### 2026-09-24 - Atlas moves to the E32R28T display board (`android/testing`)

Large hardware change. Atlas stays `0.6.0-dev`, and the radio protocol is unchanged.

- New board pin map in `config.h`; Pair button and front-panel LEDs removed;
  BOOT (IO0) is the master button
- New `Atlas/src/atlas_display.cpp` (LovyanGFX 1.2.30, DejaVu fonts): TurnHub
  splash
- Partition table `default.csv` -> `min_spiffs.csv` (app slot 1,310,720 B ->
  1,966,080 B), so the percentages below use different denominators

Same PlatformIO toolchain as the entry above. "Before" is that entry's "after":

| Build | Before | After |
| --- | ---: | ---: |
| Atlas RAM | 92,780 B (28.3%) | 94,728 B (28.9%) |
| Atlas flash | 1,119,653 B (85.4% of 1.25 MB) | 1,220,625 B (62.1% of 1.875 MB) |

About 100 KB of the growth is LovyanGFX plus the two fonts. Build only; nothing
was flashed.

### 2026-09-24 - Atlas touchscreen controls (`android/testing`)

Feature change; Atlas stays `0.6.0-dev`, radio protocol unchanged.

- Screen flipped to rotation 3; status screen after the splash
- New `Atlas/src/touch_controls.cpp` (host-tested adapter + screen model):
  Pair, Pass, Pause/Resume, end-match hold, BOOT-hold countdown
- Bit-banged XPT2046 reads in `atlas_display.cpp`

| Build | Before | After |
| --- | ---: | ---: |
| Atlas RAM | 94,728 B (28.9%) | 95,000 B (29.0%) |
| Atlas flash | 1,220,625 B (62.1%) | 1,233,741 B (62.8%) |

Build only; nothing was flashed.

### 2026-09-24 - No master button, Atlas speaker, OLED one-player limit (`android/testing`)

Feature change; Atlas stays `0.6.0-dev`, Sigil `0.5.6-dev`. Radio protocol
version unchanged; new Hello capability bit `CAPABILITY_DISPLAY_OLED` (0x10).

- Master button removed: the touchscreen's 3 s Unlock admin hold opens a 60 s
  physical-presence window; End match hold replaces the BOOT draw hold
- New `Atlas/src/atlas_speaker.cpp` (DAC cosine tones) and the `ConfigureSpeaker`
  Intent / `spkvol` setting; table-wide cues play on Atlas
- Atlas refuses Seat B on OLED Sigils and blocks a start with a leftover one

| Build | Before | After |
| --- | ---: | ---: |
| Atlas RAM | 99,764 B (30.4%) | 99,788 B (30.5%) |
| Atlas flash | 1,300,721 B (66.2%) | 1,307,673 B (66.5%) |

"Before" is the microSD step-1 build. Build only; nothing was flashed.

### 2026-09-25 - Sigil-rendered light, joystick, status ring, speaker

Sigil `0.5.6-dev` -> `0.6.0-dev`; Atlas stays `0.6.0-dev`. Radio protocol
version unchanged; new `LedState = 25` packet and Hello capability bit
`CAPABILITY_LED_STATE` (0x20).

- Atlas sends semantic `LedState` to capable Sigils; the Sigil renders it
  (`sigil_led.cpp`) to an RGB LED and, on the E-ink build, the NeoPixel Jewel
- E-ink `sigil` build: analog joystick input and Jewel status ring
  (Adafruit NeoPixel 1.15.5); Pair moves to the DevKit BOOT button (GPIO0)
- Atlas speaker: LEDC square wave with louder volume steps instead of the DAC sine

| Build | After |
| --- | ---: |
| Atlas RAM | 99,860 B (30.5%) |
| Atlas flash | 1,308,245 B (66.5%) |
| Sigil E-ink (`sigil`) RAM | 48,808 B (14.9%) |
| Sigil E-ink (`sigil`) flash | 796,397 B (60.8%) |
| Sigil OLED (`sigil-oled`) RAM | 44,736 B (13.7%) |
| Sigil OLED (`sigil-oled`) flash | 798,969 B (61.0%) |

Atlas and the OLED Sigil were flashed; the E-ink Sigil was built only.

### 2026-09-25 - Sigil menus

Sigil `0.6.0-dev` -> `0.7.0-dev`; Atlas stays `0.6.0-dev`. Radio protocol
version unchanged; new `SelectAction = 13` and `MenuState = 26` packets and
Hello capability bit `CAPABILITY_MENU` (0x40).

- Atlas works out each menu Sigil's available actions (`sigil_menu.cpp`) and
  dispatches choices through the existing Intents (`handleSelectAction`)
- Sigil five-key input (joystick on E-ink, new five-button d-pad on OLED),
  e-ink compass legend and OLED menu list (`sigil_menu.cpp`), hold-to-confirm
  with ring progress

| Build | After |
| --- | ---: |
| Atlas RAM | 99,956 B (30.5%) |
| Atlas flash | 1,310,389 B (66.6%) |
| Sigil E-ink (`sigil`) RAM | 49,040 B (15.0%) |
| Sigil E-ink (`sigil`) flash | 799,973 B (61.0%) |
| Sigil OLED (`sigil-oled`) RAM | 44,944 B (13.7%) |
| Sigil OLED (`sigil-oled`) flash | 802,801 B (61.2%) |

All three were flashed (Atlas COM12, E-ink COM13, OLED COM3).

### 2026-09-25 - Touch fix, test harness, screen overhaul, statistics split (`android/testing`)

Firmware versions unchanged (Atlas `0.6.0-dev`, Sigil `0.7.0-dev`; harness
`0.1.0`). Radio protocol version 1, extended additively: `CAPABILITY_HARNESS`
(0x80), `HarnessReport = 14`, `HarnessCommand = 27`.

- Atlas touch read samples XPT2046 DOUT while the clock is high (it raced the
  chip's bit change); calibration key `atlas-touch/cal2`. *Verified* by the
  owner on hardware.
- `TestHarness/`: two virtual menu Sigils (station and soft-AP MACs) play whole
  games against a real Atlas; premade tests start from the Atlas touchscreen.
- Atlas screen overhaul: header with a NO SD CARD warning, names, life, turn
  clock, player chips, Info and QR code screens.
- Sigils share `sigil_icons.h`; the e-ink screens get the OLED's look.
- Statistics split: core counts in NVS (`c<profileId>`), detail on the microSD
  card, with a checked migration.

| Build | After |
| --- | ---: |
| Atlas RAM | 100,924 B (30.8%) |
| Atlas flash | 1,329,957 B (67.6%) |
| Sigil E-ink (`sigil`) RAM | 48,976 B (14.9%) |
| Sigil E-ink (`sigil`) flash | 803,053 B (61.3%) |
| Sigil OLED (`sigil-oled`) RAM | 45,056 B (13.8%) |
| Sigil OLED (`sigil-oled`) flash | 811,353 B (61.9%) |
| Test harness RAM | 43,736 B (13.3%) |
| Test harness flash | 751,501 B (57.3%) |

Measured NVS use on the owner's Atlas: 130 of 630 entries (one profile). The
largest flash items are web assets (portal HTML 103 KB uncompressed, theme CSS
19 KB, stats page 10 KB); see the microSD item in STAGED_CHANGES.

All four boards were flashed at the end of the session.

### 2026-09-25 - Optional SD diagnostics (experimental, `codex/sd-diagnostics`)

Atlas stays `0.6.0-dev`; Sigil firmware and radio protocol are unchanged.
Redacted serial capture can drain to four rotating SD logs, with boot markers,
explicit overflow reporting and self-test gating. Authoritative NVS data is
unchanged. The worker requests a 6,144-byte dynamic task stack, including a
2,048-byte drain buffer; this is not a measured total RAM delta. No new library.

Host storage and serial-stream scenarios cover retention, restarts, redaction,
overflow and injected failures. Firmware RAM/flash figures are unavailable in
this environment; a firmware build and physical SD acceptance are still required.

Merged into `android/testing` with the statistics split, which shares the card
through a lock in `sd_card.cpp` (2026-09-25). The combined Atlas build: RAM
100,980 B (30.8%), flash 1,333,357 B (67.8%). Physical SD acceptance is still
pending.

### 2026-09-25 - Touchscreen table actions and master pass

Atlas stays `0.6.0-dev`; Sigil firmware and radio protocol are unchanged. The
touchscreen gains Start, Cancel start, Rematch and Reset between games and an
in-game Table screen; its Pass button is replaced by a 2 s Master pass hold
(new `MasterPass` Intent, logged as `ATLAS|GAME|MASTER_PASS`). Each Atlas
speaker level is about 10% quieter. Atlas build: RAM 101,124 B (30.9%), flash
1,346,697 B (68.5%).

### 2026-09-25 - E-ink profile picker and Atlas screen flicker fix

Sigil `0.8.0-dev` (was `0.7.0-dev`); Atlas stays `0.6.0-dev`. Radio protocol
version stays 1, with two new packets: `PickerKey = 15` and the 51-byte
`ProfilePicker = 33`. Atlas gains `profile_picker.cpp` and the `PickProfile`
Intent; the TFT draws the turn clock, countdown bar and hold bars over old
pixels instead of clearing them. Atlas build: RAM 104,468 B (31.9%), flash
1,350,885 B (68.7%). E-ink Sigil build: RAM 49,032 B (15.0%), flash 806,165 B
(61.5%).

### 2026-09-26 - Prototype v1 completion guard and verification checklist

Branch: `codex/prototype-v1-stabilization`, based on `959a09b`.
Atlas remains `0.6.0-dev`; Sigil firmware and all storage/radio/HTTP schemas are
unchanged. The production completion bridge commits Game Over before profile
increments and skips statistics on failed/uncertain checkpoint writes. This
prevents the reproduced duplicate count but does not replay missing results.
The recovery owner reuses its existing buffers; no new persistent record or
third-party dependency is added to the firmware.

Source snapshot (production `.cpp` / `.h` files only): Atlas `src/`: 46 files,
660,368 bytes / 14,949 lines; Atlas `include/`: 53 files, 199,856 bytes / 4,568
lines. Host tests and documentation are excluded from these totals.

All six host suites, the 32-adapter audit and the 10-response/9-fixture contract
check pass. Atlas suites were rebuilt with GCC 13.3.0, C++14, ASan and UBSan;
LeakSanitizer is unavailable in this execution runtime. Hardware acceptance is
pending. Atlas firmware build passes for source commit `56c058f` (published as `199c467` with the identical source tree): RAM
**105,156 B (32.1%)**, flash **1,366,405 B (69.5% of the 1,966,080 B slot)**.
Environment: PlatformIO 6.2.0, Espressif32 7.1.3, Arduino framework
`4.20017.260907+sha.dcc1105b`, Xtensa GCC `8.4.0+2021r2-patch5`, LovyanGFX
1.2.30. Built locally with telemetry disabled; no board was flashed. These are
absolute measurements, not a before/after firmware delta.
See [the line-item checklist](../STAGED_CHANGES.md).

### 2026-09-29 - Brass display theme, Atlas Menu and screen previews

Branch: `claude/modest-mendel-c7ym34`, based on `db1e4f8`. Atlas remains
`0.6.0-dev`, Sigil firmware version unchanged; no radio, storage, HTTP or
schema change. The portal's Brass look now covers the Atlas TFT and both
Sigils. New: `Atlas/src/atlas_art.cpp` (drawing split out of
`atlas_display.cpp`), generated `brass_fonts.h` for Atlas (VLW, 71,280 B of
font data) and Sigil (GFXfont, 11,530 B), `tools/fonts/make_fonts.py`, and
host screen previews for both firmwares (also run in CI). The Atlas screen
model gains a Menu screen, the round, the match clock and per-player turn
time; the lobby's persistent QR code is gone.

Source snapshot (production `.cpp` / `.h`, excluding the generated
`brass_fonts.h`): Atlas `src/` + `include/`: 105 files, 896,810 bytes /
20,419 lines. Generated font headers: Atlas 438,366 bytes, Sigil 69,157 bytes
of source text.

Firmware builds (PlatformIO 6.2.0, same toolchain as 2026-09-26; no board
flashed), before -> after on this branch:
- Atlas: flash **1,384,437 -> 1,474,169 B (+89,732; 75.0% of 1,966,080)**,
  RAM 105,684 -> 107,140 B. Heap at run time also holds the header sprite
  (16,640 B), the gauge sprite (7,904 B) and the fonts' glyph tables (~5 KB).
- Sigil e-ink (`sigil`): flash 830,433 -> 844,725 B (+14,292; 64.4%), RAM
  unchanged at 49,576 B.
- Sigil OLED (`sigil-oled`): flash 840,681 -> 841,161 B (+480), RAM unchanged.

All Atlas and Sigil host suites, the 32-adapter audit and both screen
previews pass (the Atlas preview's nine incremental-redraw checks match full
redraws pixel for pixel). Hardware acceptance of the new look is pending.

### 2026-09-30 - OLED Sigil in the Brass fonts

Same branch, after `51e4028`. The OLED Sigil now uses Cinzel and Oswald where
they fit (header title, filled tickets, names, status big lines, life
figures), with the built-in font as the measured fallback. Four OLED fonts
are added to `tools/fonts/make_fonts.py` and `Sigil/include/brass_fonts.h`
regenerated: `OledHeader` (Cinzel Black 10 px), `OledName` (Cinzel 15 px),
`OledLifeMid` (Oswald 22 px), `OledLifeSmall` (Oswald 18 px). Sigil font data
grows from 11,530 to 15,250 bytes; Atlas fonts are unchanged byte for byte.

Firmware builds (local PlatformIO 6.2.0, same toolchain; no board flashed):
- Sigil OLED (`sigil-oled`): flash **841,161 -> 849,221 B (+8,060; 64.8% of
  1,310,720)**, RAM unchanged at 45,352 B. The CI build of `51e4028` was
  reported as 847,840 B; the local toolchain measures that commit at 841,161 B.
- Sigil e-ink (`sigil`) and `sigil-wokwi`: unchanged (844,725 B and
  852,281 B); the OLED fonts are not linked into them.

Sigil host suites (OLED stub now checks custom-font glyph bounds and
overlaps), Atlas host suites and the Sigil screen previews pass.

### 2026-09-30: Atlas RAM reduction

After the playtest crashes (see the playtest notes, section G), Atlas's RAM
use was cut. CI builds (PlatformIO 6.2.0, espressif32 7.1.3, Arduino-ESP32
2.0.17). Static RAM went from 109,748 to 90,196 B, and flash from 1,512,720 to
1,412,896 B, since the portal and CSS are now stored gzipped. Measured on Atlas
with no phones connected, free heap after start-up went from ~48 KB to 99 KB
(largest block 98 KB). Per-step costs are now: SD card 21 KB, Wi-Fi hotspot
54 KB, ESP-NOW 13 KB, web server 2.6 KB.

### 2026-09-30: First-run guided setup (branch `oobe-guided-setup`)

Setup stages, the Welcome and "You're all set" touchscreen screens,
`GET /api/setup` and `POST /api/setup/finish` (see
[First-run setup](../FIRST_RUN_SETUP.md)). CI build of the branch (run
36679680047; PlatformIO 6.2.0, espressif32 7.1.3, Arduino-ESP32 2.0.17):
Atlas static RAM 90,228 B, flash 1,411,185 B of 1,966,080 (71.8%). The
previous entry's figures came from an earlier commit on `turnhub-integration`;
the setup code itself is small (a two-byte NVS record, one Intent, two routes,
one screen). No setup web page was added: the Android app is the setup client.

### 2026-09-30: Baseline Sigil, Sigil 0.9.0 (branch `oobe-polish`)

Atlas assumes the features every Sigil has; the Hello capability byte keeps
only OLED vs e-paper, d-pad vs thumbstick and the test harness
([Protocol and Pairing](../RADIO_PROTOCOL.md), "Baseline Sigil"). Removed:
Atlas's three-button gesture adapter and pause-to-win arm, the per-channel LED
stream and Atlas's copy of the LED cadence tables, the old `MenuState`, every
capability and 0.8 firmware check; on the Sigil the three-button fallback, the
menu/picker/ring build switches, old `MenuState`, legacy LED channels and the
one-LED view. About 1,570 source lines out, 505 in (tests included). Local
builds (PlatformIO 6.2.0, espressif32 7.1.3, Arduino-ESP32 2.0.17):

| Build | Static RAM | Flash |
| --- | --- | --- |
| Atlas | 88,132 B (was 90,228) | 1,403,485 B (was 1,411,293) |
| Sigil e-ink (`sigil`) 0.9.0 | 53,620 B | 920,489 B |
| Sigil OLED (`sigil-oled`) 0.9.0 | 49,396 B | 924,957 B |
| `sigil-wokwi` (now joystick + ring) | 50,576 B | 878,173 B |
| Harness 0.9.0 | 44,544 B | 777,133 B |

Protocol version stays 2.

## 2026-09-30 BOOT button: pair, unpair, factory reset

Atlas `0.6.2-dev` -> `0.6.3-dev`, Sigil `0.9.2-dev` -> `0.9.3-dev`. One shared
`three_part_button.h` state machine drives the Sigil Pair button and Atlas's BOOT
button: quick press pairs (on release), 3 s unpairs, 10 s factory resets
(replacing the old 10 s forget-only hold). Atlas gains a BOOT-button adapter
(`updateBootButton`) and lets `AtlasHardware` forget all Sigils and factory reset
Atlas without an Admin; the OLED Sigil's menu list ends in a local Factory
reset. Local builds (PlatformIO 6.2.0, espressif32 7.1.3, Arduino-ESP32 2.0.17):

| Build | Static RAM | Flash |
| --- | --- | --- |
| Atlas 0.6.3 | 88,116 B | 1,399,941 B |
| Sigil e-ink (`sigil`) 0.9.3 | 53,628 B | 920,809 B |
| Sigil OLED (`sigil-oled`) 0.9.3 | 49,404 B | 925,217 B |
| `sigil-wokwi` | 50,584 B | 878,461 B |
| Harness | 44,552 B | 779,177 B |

Protocol version stays 3.

## 2026-10-02 Compass on both Sigils, device menu

Sigil `0.9.3-dev` -> `0.9.4-dev`. The OLED Sigil's scrolling action list is
replaced by the e-ink's compass (`MenuLayout` removed); the OLED shows the
legend one key at a time on its bottom row, stepped by the display task's idle
work. Both Sigils gain a device-local compass device menu (Menu on a free
Up/Down key outside a game: Factory reset held 5 s, Back), so the e-ink can
factory reset from its screen too. Undo pass moves to the click on both. The
OLED profile picker stays a list. Manual V0.7. Local builds (PlatformIO 6.2.0,
espressif32 7.1.3, Arduino-ESP32 2.0.17):

| Build | Static RAM | Flash |
| --- | --- | --- |
| Sigil e-ink (`sigil`) 0.9.4 | 53,548 B | 920,901 B |
| Sigil OLED (`sigil-oled`) 0.9.4 | 49,564 B | 932,721 B |
| `sigil-wokwi` | 50,512 B | 878,565 B |

Atlas and the harness are unchanged. Protocol version stays 3: nothing on the
radio changed.

## 2026-10-02 Unpair everywhere, joystick pairing, Atlas Device screen

Atlas `0.6.3-dev` -> `0.6.4-dev` (also covering the update-notice-everywhere
work merged before it, which kept 0.6.3), Sigil `0.9.5-dev` -> `0.9.6-dev`.
Sigil device menu: Unpair held 3 s on the click, Factory reset moved to Down
(5 s). An unpaired Sigil opens its pairing window when the thumbstick click is
held 3 s (BOOT may be inside a case); the Unpaired screens say so. Atlas's
touchscreen gains Menu > Device with held Unpair Sigils (3 s) and Factory reset
(10 s), the BOOT button's gestures as the same AtlasHardware Intents;
`MAX_TOUCH_BUTTONS` 6 -> 7. Manual V0.9. Local builds (PlatformIO 6.2.0,
espressif32 7.1.3, Arduino-ESP32 2.0.17):

| Build | Static RAM | Flash |
| --- | --- | --- |
| Atlas 0.6.4 | 88,244 B | 1,405,041 B |
| Sigil e-ink (`sigil`) 0.9.6 | 53,556 B | 921,553 B |
| Sigil OLED (`sigil-oled`) 0.9.6 | 49,572 B | 933,209 B |
| `sigil-wokwi` | 50,520 B | 879,213 B |

Protocol version stays 3.

## 2026-10-02 Sleep on Sigils and Atlas (Atlas 0.6.5, Sigil 0.9.7)

Device-menu **Sleep** on both Sigils (Up; deep sleep, a joystick click or BOOT
wakes) and on Atlas's Menu > Device (a tap between games; the new `Sleep`
Intent; deep sleep, a touch or BOOT wakes). Manual V0.10. CI builds of
`f799030` (PlatformIO 6.2.0, espressif32 7.1.3, Arduino-ESP32 2.0.17):

| Build | Static RAM | Flash |
| --- | --- | --- |
| Atlas 0.6.5 | 88,348 B | 1,412,641 B |

Signed OTA packages from the same run: Atlas 1,419,344 B, Sigil e-ink 0.9.7
935,488 B. The Sigil RAM/flash figures were not read back from CI for this
entry. Protocol version stays 3.

## 2026-10-02 OLED Sigil menus become a scrolling list (Sigil 0.9.8)

Sigil `0.9.7-dev` -> `0.9.8-dev`. `SigilMenu` gains a style: the e-ink keeps
the compass; the OLED (`MenuStyle::List`) keeps the compass's click (Pass,
Undo pass, Join, Start...) and Left/Right life, and Up opens one scrolling
list of every offered action plus Sleep, Device recovery (a second list with
Unpair and Factory reset) and Back, in a
game too (owner request). `MenuView` carries the rows and cursor; the OLED's
device-menu screen became the list (header row count, scroll bar, "HOLD:"
row) with its own stepping legend. Manual V0.11. Firmware sizes were not
measured for this entry (cloud session; CI builds both Sigils). Protocol
version stays 3: nothing on the radio changed.

## 2026-10-02 Flash portal removed (owner decision)

The SD portal pack is now the full web portal. Atlas's flash keeps the shared
stylesheet, the sign-in, firmware and Sigil firmware pages, and a basic portal
(`BASIC_PORTAL_HTML`, 13.7 KB, 5.3 KB gzip) so a failed card still leaves game
controls, accessibility, device settings and updates. Removed from flash: the
built-in portal (`PORTAL_HTML` and its gzip copy), `DEV_HTML` and
`stats_page.cpp`. Source: `web_pages.cpp` 138,233 B → about 38 KB;
`stats_page.cpp` (10,900 B) deleted.
Compiled flash was not read back for this entry.

## 2026-10-02 Touchscreen fix for the chime synthesizer (Atlas 0.6.6)

The chime synthesizer (I2S into the built-in DAC) called `i2s_set_pin(nullptr)`,
which in Arduino-ESP32 2.0.17's legacy I2S driver enables both DAC channels.
Channel 1 is IO25, the XPT2046 touch clock, and setting the DAC mode to the
left channel afterwards never turns channel 1 back off, so the DAC drove the
touch clock and every reading came back scrambled (touch calibration rejected
every attempt with "Those presses did not line up"). `atlas_speaker.cpp` now
sets only the DAC mode (channel 2, IO26). Firmware sizes were not measured for
this entry (cloud session; CI builds Atlas).

## 2026-10-03 First multi-phone stability changes (Atlas 0.6.7)

Atlas 0.6.6 -> 0.6.7: a 16 KiB loopTask stack, correct historical-minimum
stack diagnostics, bounded constant-route HTTP tracing and low-stack warnings.
Status formatting and counter snapshots move to explicitly owned HTTP working
storage; counter JSON avoids long chains of String temporaries. The working
storage adds about 1.5 KiB static RAM, plus 8 KiB more allocated stack versus
an 8 KiB baseline. Host GCC frame estimates fall from 1376 to 352 B for status
and 1280 to 160 B for counters; these are not ESP32 runtime measurements.
Local firmware compilation was unavailable; GitHub figures follow below.
Radio version and client polling stay unchanged. Hardware acceptance
remains open; see `2026-10-02-stability-plan.md` and verification C06.

The first GitHub build passed: static RAM 94,436 B, flash 1,418,397 B,
PlatformIO 6.2.0 / espressif32 7.1.3 / Arduino-ESP32 2.0.17. Actual target
reports also exposed large aggregate reset temporaries in checkpoint capture,
decode and the counter callback; a follow-up resets those workspaces in place.
Use the follow-up CI artifact for final sizes and hardware testing.

## 2026-10-06 Commander damage reaches Sigils (Atlas 0.6.8, Sigil 0.9.10)

Sigil 0.9.9 -> 0.9.10: the radio receive filter now accepts the sealed
80-byte Commander page (95 bytes on air). 0.9.9 dropped every page, so
choosing Cmd damage did nothing visible. Amount-stage taps no longer wait for
each e-ink refresh. Atlas 0.6.7 -> 0.6.8: the source picker skips the
recipient and eliminated players, profile names are read once per opened
flow, and `TURNHUB_HTTP_TRACE` is off by default. Same versions, later the
same day: per-player partner commanders (`SetPartner`, menu actions 26/27;
without partners the Commander step is skipped) and one menu layout for both
Sigil displays (Up always opens Menu; `Sigil/DISPLAY.md`, Menus). Radio
version unchanged; all Atlas and Sigil firmware must be flashed together.
Local firmware compilation was unavailable; use the CI artifact for sizes.

Atlas 0.6.8 -> 0.6.9 and Sigil 0.9.10 -> 0.9.11 (2026-10-06): the Secure
Link boot self-test runs two X25519 multiplications instead of eight (both
firmwares); Atlas captures framework `log_e`/ESP-IDF output into its RAM and
SD logs; the Sigil profile picker numbers duplicate names. Radio version
unchanged. Local firmware compilation was unavailable; use the CI artifact
for sizes.

Atlas 0.6.9 -> 0.6.10 (2026-10-06): Remove (hold 2 s) on the Atlas lobby
Player screen (`RemoveSeat`); a per-player life-approval window of 15, 30 or
60 s, packed into the accessibility record's flags byte (existing records read
as 15 s); Nudge from the app and the portal (`NudgePlayer`, state `nudge`,
`/api/control/nudge`). Portal pack 1.1.1. Radio version unchanged; Sigil
firmware unchanged. Local firmware compilation was unavailable; use the CI
artifact for sizes.

## 2026-10-06 Tablet mode, round one (Atlas 0.6.12, portal pack 1.2.0)

Atlas 0.6.11 -> 0.6.12: `web_tablet_api.cpp` (238 lines): a table presence
code with `purpose=tablet` turns a signed-in browser into the shared table
screen, which seats players (new PIN-less profiles or existing ones by their
PIN choice) and acts for any seat through the phone's seat callbacks
(`/api/tablet/*`). Portal pack 1.2.0 adds `tablet.html` (571 lines) and
`tablet.css` (150 lines). Radio version unchanged; Sigil firmware unchanged.
Local firmware compilation was unavailable; use the CI artifact for sizes.

## 2026-10-07 Tablet turn order, Sigils joining mid-game (Atlas 0.6.13, portal pack 1.2.1)

Atlas 0.6.12 -> 0.6.13: a table tablet may set the lobby's turn order
(`MoveSeat` from the new `TableTablet` origin, `move-earlier`/`move-later`);
during a running or paused game a Sigil outside it may take over a player
seated from a phone or the tablet (`attachInGame`,
`GameEngine::replaceController`; the picker then lists only those players).
Portal pack 1.2.1 and the app add the lobby's turn-order arrows and put Claim
the win and Concede at the top of each panel's More. Radio version unchanged;
Sigil firmware unchanged. Local firmware compilation was unavailable; use the
CI artifact for sizes.

## 2026-10-06 Tablet mode, round two (Android app)

The Android app gains the tablet screen (`ui/tablet/TabletScreen.kt` 429
lines, `TabletTable.kt` 782 lines) and its requests (`data/AtlasTablet.kt`
209 lines), opened from My account. Same `/api/tablet/*` routes as the portal;
Atlas and Sigil firmware unchanged.

## 2026-10-06 Sigil welcome text (Sigil 0.9.12)

Sigil 0.9.11 -> 0.9.12: the paired idle screen on both displays reads
"Welcome to TurnHub!" instead of "Ready for game". Radio version unchanged;
Atlas firmware unchanged. Local firmware compilation was unavailable; use the
CI artifact for sizes.

## Tracking rules

1. Git history is authoritative; this document is a milestone ledger, not a substitute.
2. Source byte growth is diagnostic, not a quality score.
3. Record compiled RAM/flash only from a known build and include toolchain context when it changes.
4. Do not optimize only to make numbers smaller; preserve architectural boundaries first.
5. When a large file grows because multiple responsibilities accumulated, review whether a
   documented module boundary already exists before refactoring.
6. Preserve historical measurements even when a later refactor reduces them.
7. At Prototype 1.0 release-candidate time, record a fresh Atlas/Sigil source snapshot,
   compiled RAM/flash usage, protocol version, and the exact release commit/tag.

Last updated: 2026-10-06

## 2026-10-07 App offline mode, tablet changes replayed on reconnect (Atlas 0.6.14)

Atlas 0.6.13 -> 0.6.14: `/api/tablet/life` and `/api/tablet/commander`
accept an optional `queuedMs` from the app's offline queue and log it as
`ATLAS|TABLET|OFFLINE|...`; the change itself goes through the same seat
callbacks and Intents as before. Android: the app keeps the last known table
when Atlas stops answering and queues tablet life and Commander changes for
replay. Radio version unchanged; Sigil firmware and portal pack unchanged.
Local firmware compilation was unavailable; use the CI artifact for sizes.

## 2026-10-07 Tablet access role (Atlas 0.6.15, portal pack 1.2.2)

Atlas 0.6.14 -> 0.6.15: a new account permission, **Tablet access** (bit 32,
`TurnHubAccounts::TabletAccess`), lets `POST /api/tablet/enable` skip the
table presence code, e.g. for a dedicated tablet account that never joins the
table. Admins set it from People (portal and app) like the other roles, and
like them it needs a PIN on the account. Everyone else still enters the code.
The account record layout is unchanged (the permissions byte already had room).
Portal pack 1.2.1 -> 1.2.2 (People role, tablet gate); Android shows the role
and turns tablet mode on directly for such an account. Radio version and Sigil
firmware unchanged. Planned release: v0.9.11.

## 2026-10-07 Phone sign-in for PIN-less profiles (Atlas 0.6.16, portal pack 1.2.3)

Also planned for v0.9.11: a profile with no PIN yet (made on a Sigil or the tablet) can
sign in from a phone. Its first `POST /api/session/login` saves that PIN or
password as its secret. The app lists such profiles as selectable and asks for
the new secret twice; the portal login notes the PIN becomes theirs.

## 2026-10-07 Two games per Atlas, round one (Atlas 0.7.0, Sigil 0.9.13, portal pack 1.3.0)

Atlas runs Game 1 and Game 2 side by side (`MAX_GAME_TABLES` 2): each game has
its own lobby, engine, next-game settings and recovery record (`checkpoint2`),
and code reaches the right one through `table()` under a `TableScope`. The
radio gains `SigilAction::SwitchTable` ("Switch game", bit 28 of MenuState2),
so Atlas and Sigils must be reflashed together. HTTP adds `POST
/api/session/game` and `game`/`games` in state and `/api/status`. RAM: one
more `GameTable`; the two recovery records share one set of scratch buffers.
Flash size not measured here (CI builds the firmware).

## 2026-10-08 Explicit standalone identity and local history (Atlas 0.7.2)

Atlas 0.7.1 -> 0.7.2: standalone import requires destination `atlasId` and
unique explicit profile IDs; invalid/deleted/archived/unreadable identities are
rejected before receipt/statistics writes, with no name fallback. Receipt ring
layout/capacity, radio and Sigil firmware are unchanged. Android now retains
local UUID players, immutable history and separate delivery states with explicit
per-match mapping. No new dependency or NVS allocation. CI run 218 at
`ae5df30` built Atlas successfully: static RAM 105,148 / 327,680 bytes (32.1%),
flash 1,471,169 / 1,966,080 bytes (74.8%); the signed descriptor reports Atlas
0.7.2, radio 3. These are build sizes, not runtime heap or bench measurements.

## 2026-10-09 Shared device themes (Atlas 0.7.4, Sigil 0.9.15)

Implementation on `codex/device-screen-themes`, based on `f3c559e` plus the
`c8472c2` Atlas host CI fixture fix. Four independent saved display themes,
generated RGB888 palettes from the portal/app tokens, Inter bitmap fonts with
tabular digits, modern cards/hearts, and retained Brass type/ornament. OLED
Daylight uses a light ground; e-paper adapts the theme family in black/white.
Device `display/theme` NVS setting only; radio/game contracts unchanged. Manual
V0.13 documents the new controls.

Verified local PlatformIO 6.2.0 builds (configured project dependencies; no
hardware attached). These are static RAM/flash sizes, not runtime heap:

| Environment | Static RAM / 327,680 B | Flash / application partition |
|---|---|---|
| Atlas | 105,276 B (32.1%) | 1,545,293 / 1,966,080 B (78.6%) |
| Sigil e-paper | 53,868 B (16.4%) | 945,337 / 1,310,720 B (72.1%) |
| Sigil OLED | 49,908 B (15.2%) | 954,661 / 1,310,720 B (72.8%) |
| Sigil spare | 48,996 B (15.0%) | 880,613 / 1,310,720 B (67.2%) |

Inter adds 65,530 B of Atlas glyph data and 14,658 B of Sigil glyph/metric data
in generated headers (the linker retains fonts referenced by each target).

Atlas flash size includes the font reload ownership fix in `f108a34`;
the unchanged static RAM figure excludes dynamically allocated font tables.

Atlas raw source/header total before that fix: 1,926,216 B in 124 files. Largest: `Atlas/include/brass_fonts.h` (438,366 B), `Atlas/include/modern_fonts.h` (402,949 B), `Atlas/src/touch_controls.cpp` (63,404 B).

Sigil raw source/header total: 467,718 B in 33 files. Largest: `Sigil/include/brass_fonts.h` (91,265 B), `Sigil/include/modern_fonts.h` (87,297 B), `Sigil/src/main.cpp` (79,069 B).

### 2026-10-09 / Sigil 0.9.16 theme identities

Verified local PlatformIO 6.2.0 builds; no hardware acceptance claimed.
E-paper glyph families/frames and calm LED defaults reuse the existing fonts.

| Environment | Static RAM / 327,680 B | Flash / 1,310,720 B |
|---|---|---|
| Sigil e-paper | 53,868 B (16.4%) | 947,129 B (72.3%) |
| Sigil OLED | 49,908 B (15.2%) | 954,657 B (72.8%) |

### 2026-10-09 / Device inversion and header emblems

Verified local PlatformIO 6.2.0 builds; no hardware acceptance claimed.
Atlas 0.7.5 and Sigil 0.9.17 save screen inversion independently of theme.
All themes have a header mark; glyphs reuse existing graphics primitives.

| Environment | Static RAM / 327,680 B | Flash / application partition |
|---|---|---|
| Atlas | 105,388 B (32.2%) | 1,546,557 / 1,966,080 B (78.7%) |
| Sigil e-paper | 53,876 B (16.4%) | 948,509 / 1,310,720 B (72.4%) |
| Sigil OLED | 49,916 B (15.2%) | 955,973 / 1,310,720 B (72.9%) |

### 2026-10-10 / Atlas 0.7.6-dev app-first administration cutover

Verified local PlatformIO 6.1.19 Atlas build; no hardware acceptance claimed.
Portal pack 2.0.0 removes browser play and requires matching cutover firmware.
Native Android actions can pin their selected game with `expectedGame`; Atlas
rejects a changed game before dispatching the existing action handler.

| Environment | Static RAM / 327,680 B | Flash / application partition |
|---|---|---|
| Atlas | 105,388 B (32.2%) | 1,545,377 / 1,966,080 B (78.6%) |

Sigil source is unchanged. SD pack: 17 files, 401 KB raw / 243 KB packed.

### 2026-10-10 / Atlas 0.7.7-dev embedded administration

PlatformIO Atlas build verified locally; no hardware acceptance claimed.
The complete compressed admin portal (17 assets, 247,904 stored bytes) is
embedded in the application, including Developer and signed maintenance pages.
Portal archives, SD installer/serving, duplicated fallback pages and the retired
browser QR script are removed. Existing partitions and OTA slots are unchanged.

| Environment | Static RAM / 327,680 B | Flash / application partition |
|---|---|---|
| Atlas | 105,164 B (32.1%) | 1,728,329 / 1,966,080 B (87.9%) |

Actual firmware.bin is 1,735,040 B, leaving 231,040 B in the OTA application
slot. Packaging/verification of the complete image passed using a disposable
test key, without signing a release or installing on hardware. Sigil firmware
source is unchanged apart from the shared package product allowlist retiring
product 4; its package regression now verifies refusal.

### 2026-10-10 / Accessibility-only portal after firmware handoff

Baseline `4da302a` already embeds administration in Atlas 0.7.7-dev. The portal
now keeps System/Dark/Light/High contrast appearance, uses system fonts, and
excludes decorative Brass/font assets. Shared app/device themes are unchanged.
Verified local PlatformIO 6.1.19 build; no hardware acceptance claimed.

| Environment | Static RAM / 327,680 B | Flash / 1,966,080 B |
|---|---|---|
| Atlas | 105,164 B (32.1%) | 1,583,385 B (80.5%) |

13 embedded web files use 103,155 B (previously 17 files / 248 KB).
Complete firmware image: 1,590,096 B; OTA slot headroom: 375,984 B.
Both existing OTA slots remain unchanged. Sigil source is unchanged.

### 2026-10-10 / Atlas 0.7.8-dev SD artwork and shared tablet identity

Verified local PlatformIO build; no physical acceptance claimed. High-resolution
64-pixel default masks are generated from the existing vector masters. Custom
512-pixel/48-KiB JPEG masters and 16-pixel RGB332 display projections live on SD;
no new partition or legacy Sigil firmware/radio change. Tablet activation rotates
this device's personal token into a restricted, profile-free RAM credential.

| Environment | Static RAM / 327,680 B | Flash / 1,966,080 B |
|---|---|---|
| Atlas | 109,516 B (33.4%) | 1,646,429 B (83.7%) |

Complete firmware image: 1,653,152 B; OTA slot headroom: 312,928 B.
Relative to the accessibility-only portal baseline: +4,352 B static RAM and
+63,044 B reported flash. Existing application slots are unchanged.
Android debug APK: 15,849,907 B; all 218 unit tests passed.

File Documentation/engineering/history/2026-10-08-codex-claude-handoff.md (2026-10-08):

# Handoff moved

The permanent, project-wide Codex / Claude conversation is now [COLLABORATION.md](../../../COLLABORATION.md) at the repository root.

The original 2026-10-08 app-only experience and battery-presence review is preserved there as topic **TH-001**. Add all new project discussions and replies to the root document.

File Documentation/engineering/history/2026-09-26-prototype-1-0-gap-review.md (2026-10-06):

# Prototype 1.0 gap review (2026-09-26)

A check of the current tree against the
Prototype 1.0 field-test priority lane, then in [Staged Changes](../STAGED_CHANGES.md)
(removed 2026-10-02; see git history).
The goal of that lane is a build another person can use **without a development
computer**. Confidence labels follow the engineering README: host tests passing is
not hardware acceptance.

Follow-up: stabilization is now tracked in the
[line-item v1 checklist](../STAGED_CHANGES.md). Completion checkpoint
ordering is host-tested on the Codex branch; complete replay-safe statistics
remain open. The review below describes the baseline examined that morning.

## Summary

The software side of the lane is largely built. Very little of it has been accepted
on hardware. Since 2026-09-24 (58 commits in three days) the work drifted into new
hardware and features: the Atlas touchscreen, the Jewel ring, the joystick and OLED
Sigils, microSD statistics and diagnostics, the Android app, the test harness,
avatars and table-clock sync. Several of those help the field test, but they also
broke lane item 2, the feature freeze, and added bench checks that nobody has run.

**Recommendation:** freeze features now. Spend the next sessions on bench acceptance
(items 3, 5 and 6 below) and on the first carrier PCB, which is what makes three
identical field-test Sigils practical.

## Lane items

| # | Lane item | Status | Evidence / gap |
|---|---|---|---|
| 1 | Physical profile selection, reusable Sigils | *Partially implemented* | Seat-A and seat-B picker on e-ink and OLED Sigils (host-tested; seat B since 2026-09-29). Selectable startup and duplicate-name labels remain; see [../PLAYERS_AND_ACCOUNTS.md](../PLAYERS_AND_ACCOUNTS.md). Hardware: *Needs verification*. |
| 2 | Freeze major portal features | **Not held** | Since the lane was written: avatars, a Personalization card, Admin/GM/Developer tabs in Android, touchscreen table actions and more. Needs an explicit freeze from here on. |
| 3 | Interrupted-match recovery | *Implemented, host-tested* | Wired into `setup()`/dispatcher observer on 2026-09-23. Discard is the 5 s End match hold. The abrupt-power test matrix (backlog lines 109-118) is still open; those checkboxes also need updating to match what was built. |
| 4 | Auxiliary button path | *Superseded* | GPIO32 now carries the joystick click (e-ink) or the Select key (OLED); Pause/Win became menu actions. The backlog's "revisit Action long-press" item can be closed or restated. |
| 5 | Pairing state machine | *Implemented* | Manual pairing defaults to 15 s, Pair = DevKit BOOT button. Forget-device and local unpair flows are implemented; radio bench acceptance remains. |
| 6 | Three-Sigil field-test set | **Not started as a set** | Sigils are breadboards of two different kinds (e-ink/joystick and OLED/buttons). No repeated cold-boot / power-loss / reconnect / re-pair runs are recorded. The carrier PCB (below) is the blocker for building three alike. |
| 7 | Out-of-box setup | *Mostly implemented* | Atlas screen shows QR codes, access codes replace the admin hold, Android joins the Atlas Wi-Fi itself, factory reset exists on both devices. Not yet tried end to end by someone other than the owner. |

## Added since the lane was written (not in Prototype 1.0 scope)

- **Hardware:** Atlas moved to the LCDwiki E32R28T touchscreen board with an on-board
  speaker; Sigils gained the NeoPixel Jewel 7 ring, the analog joystick (e-ink) and
  five pushbuttons (OLED; replaced by the same joystick on 2026-10-01), and a GPIO4
  display-type strap.
- **Features:** Commander damage and life approvals, game profiles, accounts and
  moderation, microSD statistics/diagnostics, preset avatars, table-clock light sync,
  TestHarness 0.8.0, the Android client with Settings/Dev tabs.
- **Useful for the field test:** the touchscreen (no phone needed to run a table),
  the test harness (repeatable games without people), factory reset and QR setup.
- **Cost:** each one adds bench checks. The verification backlog has 77 open items,
  many from before this lane; the ones that block Prototype 1.0 are the recovery
  matrix, radio pairing acceptance, profile persistence across an update, the
  Sigil GPIO/breadboard check and Sigil current draw.

## Hardware path: the e-ink Sigil carrier

The e-ink Sigil stack is complete for the first prototype: DevKit, e-paper board,
joystick, Jewel ring and buzzer. As of 2026-09-26 the Rev A schematic
([KiCad/PCB/Sigilv1](../../../KiCad/PCB/Sigilv1/README.md)) has through-hole footprints
for every carrier part, the ring's bulk capacitor, +3V3 decoupling and the GPIO4
strap. Before a board can be ordered:

Update the same day: U1 has a footprint (rows 22.86 mm apart, corrected from the
published 25.4 mm after the owner's DevKit was seen to straddle a standard breadboard
with one free hole outside each row; *Needs verification*) with a 7 mm antenna
keep-out, the buzzer is a passive piezo driven directly, and
a 74AHCT1G125 level shifter (U2) was added for the ring. The Jewel moved to a
small adapter board with a JST-XH pigtail into the Sigil board. What's left:

1. **Caliper-check the DevKit** row spacing and outline, and test-fit the sockets.
   Print both footprints 1:1 and test-fit the DevKit and a Jewel.
2. Re-run KiCad ERC, then lay out the board.

An LED strip can be chained later from the adapter's optional chain-out (J3: +5V,
DOUT, GND). It must be RGBW (SK6812) to match the Jewel, the firmware pixel count
must change, and the USB current budget still applies.

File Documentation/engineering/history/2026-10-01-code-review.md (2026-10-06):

# Code review, 2026-10-01 (whole repository)

Scope: Atlas, Sigil, `shared/`, TestHarness, Android, `protocol/`, `tools/`
and the docs they touch, read for bugs, unintended behavior, wording,
clunky behavior and misplaced code, with small improvements made where the
code was open anyway. Done while the prototype Sigils are out of service
(rewired into a new enclosure), so nothing here is hardware-tested.

Branch: `ccr-490e3776-lytu1y`. Earlier review: [2026-09-26](2026-09-26-code-review.md).

## Checks run

| Check | Result |
|---|---|
| Atlas host suites (`run-linux.sh`, ASan + UBSan) | Pass |
| Sigil host suites (`run-linux.sh`, ASan + UBSan) | Pass |
| `audit_adapters.py`, `check_client_contract.py` | Pass (27 adapters; 10 responses, 9 fixtures) |
| Firmware builds: `atlas`, `sigil`, `sigil-oled`, `sigil-wokwi`, `harness` | Pass (PlatformIO 6.2.0 on Linux) |
| Android `testDebugUnitTest` | Pass (139 tests) |
| `tools/firmware/test_thfw.py`, `export_manual.py --check` | Pass |
| KiCad `verify_schematic.py` | Not run (needs kicad-cli netlist exports) |

All of the behavior below is *Host-tested only* unless marked firmware-only;
each needs verification on hardware.

## Bugs fixed

1. **E-ink Sigils could never use Switch seat.** The compass layout had no key
   for `SigilAction::SwitchSeat`, so the playtest #3 fix (show and adjust the
   other seat) worked only on the OLED list. It now takes whatever is left of
   click, Up and Down, never Left/Right (life). Waiting on another player's
   turn, that is the click. `Sigil/src/sigil_menu.cpp`, menu host test.
2. **Leaving from a phone left the Sigil seat bound.** A profile seated on a
   Sigil that left from its phone (or was removed by a Game Master) kept the
   Sigil's seat binding: the Sigil still showed the name and its next Join
   seated the same profile. Drop seat B had the same gap. Both now free the
   binding like the Sigil's own Leave (`TurnHubControllers::releasePhysical`).
3. **A Sigil reboot dropped seated players' profiles.** Atlas cleared a Sigil's
   seat bindings whenever it asked for its names after starting up, even while
   seated in the lobby, so a power blip turned its players into guests. A
   seated Sigil now keeps them (`SigilBus::setSeatedQuery`). Firmware-only.
4. **Turn statistics could record a ~49-day turn.** `passTurn`, `resume` and
   the end-of-game pause used plain unsigned subtraction, so a clock sampled
   before a fresh stamp wrapped; the rest of `GameEngine` already used the
   wrap-safe helper. They do now, and `passTurn` checks for a next player
   before touching statistics.
5. **Return from Paused could leave a Sigil on the paused screen.** The Sigil
   drops its game view on any `DisplayState`; Atlas only resent the game view
   if the snapshot changed, and relied on an `invalidateAll()` at resume. The
   renderer now also compares the display payload.
6. **Game start during an Atlas firmware upload.** Start waited for a Sigil
   update but not for an Atlas OTA upload, which restarts Atlas when it lands.
7. **The shipped Wi-Fi password could be stored as the owner's**, through
   Network settings, breaking "a stored password always means the owner chose
   it". Both password paths now refuse it.
8. **The profile picker never said "Table is full"**; it now does when that is
   why a join failed.

## Load (playtest crash with several phones)

The 4-phone crash is still unexplained (see the 2026-09-29 playtest notes,
section G). Three per-request or per-loop costs were cut:

- The life-expiry tick dispatched every loop pass re-encoded and CRC'd the
  recovery checkpoint each time; it now skips that when nothing expired (the
  once-a-second recovery poll still runs).
- Seat colors (profile lookups and String churn per seat) were re-read every
  loop pass; now every 500 ms.
- `/api/seats` and `/api/devices` re-resolved every session for every seat;
  they now resolve sessions once per request (`resolveAllSessions`).

## Small improvements

- Yu-Gi-Oh! life in hundreds everywhere: Atlas Player screen (100/1000),
  Android life pad and request dialog, and Sigils (steps of 100 when a game
  starts at 1000+ life; the ring counts steps).
- Firmware upload errors read as sentences (`errorMessage`) on the Atlas and
  Sigil update pages instead of codes such as `olderVersion`.
- The Atlas screen's Paused detail names an open elimination.
- Durations spelled out in messages are tied to their constants with
  `static_assert` (pass grace, life approval, the 3 s Pair hold); the claim
  message uses `CLAIM_TIMEOUT_MS`.

## Wording and placement

Stale "admin unlock" text (one in a portal dialog), "the table host" (portal
hint, Android timer editor), "press Action" (claim flow, now Link phone), the
retired Action button in the PASS reply, "not used by the radio yet" (secure
link self test), the RGB LED pins, radio version 1/2 in the client contract
(it is 3), and comments that had drifted away from their code (pairing window,
factory reset, presence-code screens, InputTiming, a profile-store migration
that no longer exists). `/api/status` lost its dead `"host": -1`.

## Found, not changed

- **`DISPLAY_FLAG_HOST`** is never set; the Sigils still draw a crown for it.
  Resolved 2026-10-05: its bit now identifies physical seat B; Sigils no longer
  use it to draw a host crown. See `2026-10-05-shared-sigil-turn-order.md`.
- **`hostModuleId` and `host`** remain in the client contract for the same
  reason.
- **Session lookups read NVS** (`TurnHubAccounts::load`, `primaryAdmin`) on
  every authenticated request. Cheap per call, but a RAM cache would remove it
  if the multi-phone load is still a problem after a logged replay.
- **The user manual** (`Documentation/User Manual/*.docx`) does not yet
  describe the changes above, nor the playtest items listed in
  `STAGED_CHANGES.md`.
- **No firmware version bump.** Raise `PATCH` before installing these builds
  over OTA on boards that already run 0.9.3.

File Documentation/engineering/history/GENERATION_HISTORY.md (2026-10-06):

# TurnHub Generation History

This document reconstructs TurnHub development in generations. Generation boundaries are practical engineering milestones, not formal commercial revisions.

## Generation 0 - Standalone turn-timer proof of concept

**Status:** Reconstructed

### Product goal

Prove that a tabletop device could manage turn timing and communicate game state physically without requiring a phone.

### Hardware

- Arduino-class microcontroller prototype.
- Physical Pass and Action controls.
- Red, green, and blue status indication.
- Piezo/buzzer feedback added during prototype development.
- Early timer adjustment used a potentiometer; later experiments moved toward fixed timer modes/DIP selection.

### Software behavior

- Two-player turn sequencing was the original scope.
- Short Pass interaction advanced the active player.
- Long Action interaction was used for pause/resume behavior.
- Extended holds and multi-press/hold concepts were explored for game-end/winner functions.
- LED states communicated active player, waiting state, pause, timer warning, and game end.

### Architectural characteristic

Game behavior and hardware behavior were comparatively close together. The primary question was whether the interaction model worked at all.

### What this generation proved

- Physical turn passing is understandable at the table.
- Turn warnings and status LEDs provide useful at-a-glance feedback.
- Long-press interactions can provide secondary functions without excessive controls.
- Audible feedback helps confirm actions without requiring players to look at the device.

### Items still to verify

- Exact first-day board model and pinout.
- Exact order in which buzzer, timer adjustment, pause, and winner behaviors were introduced.
- Exact potentiometer and DIP wiring used in the earliest prototype.

---

## Generation 1 - Raspberry Pi Atlas with wired modules

**Status:** Verified in repository, with some reconstructed hardware details

### Product goal

Move game-state authority away from individual player modules and prove that one central host could coordinate multiple physical controllers.
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

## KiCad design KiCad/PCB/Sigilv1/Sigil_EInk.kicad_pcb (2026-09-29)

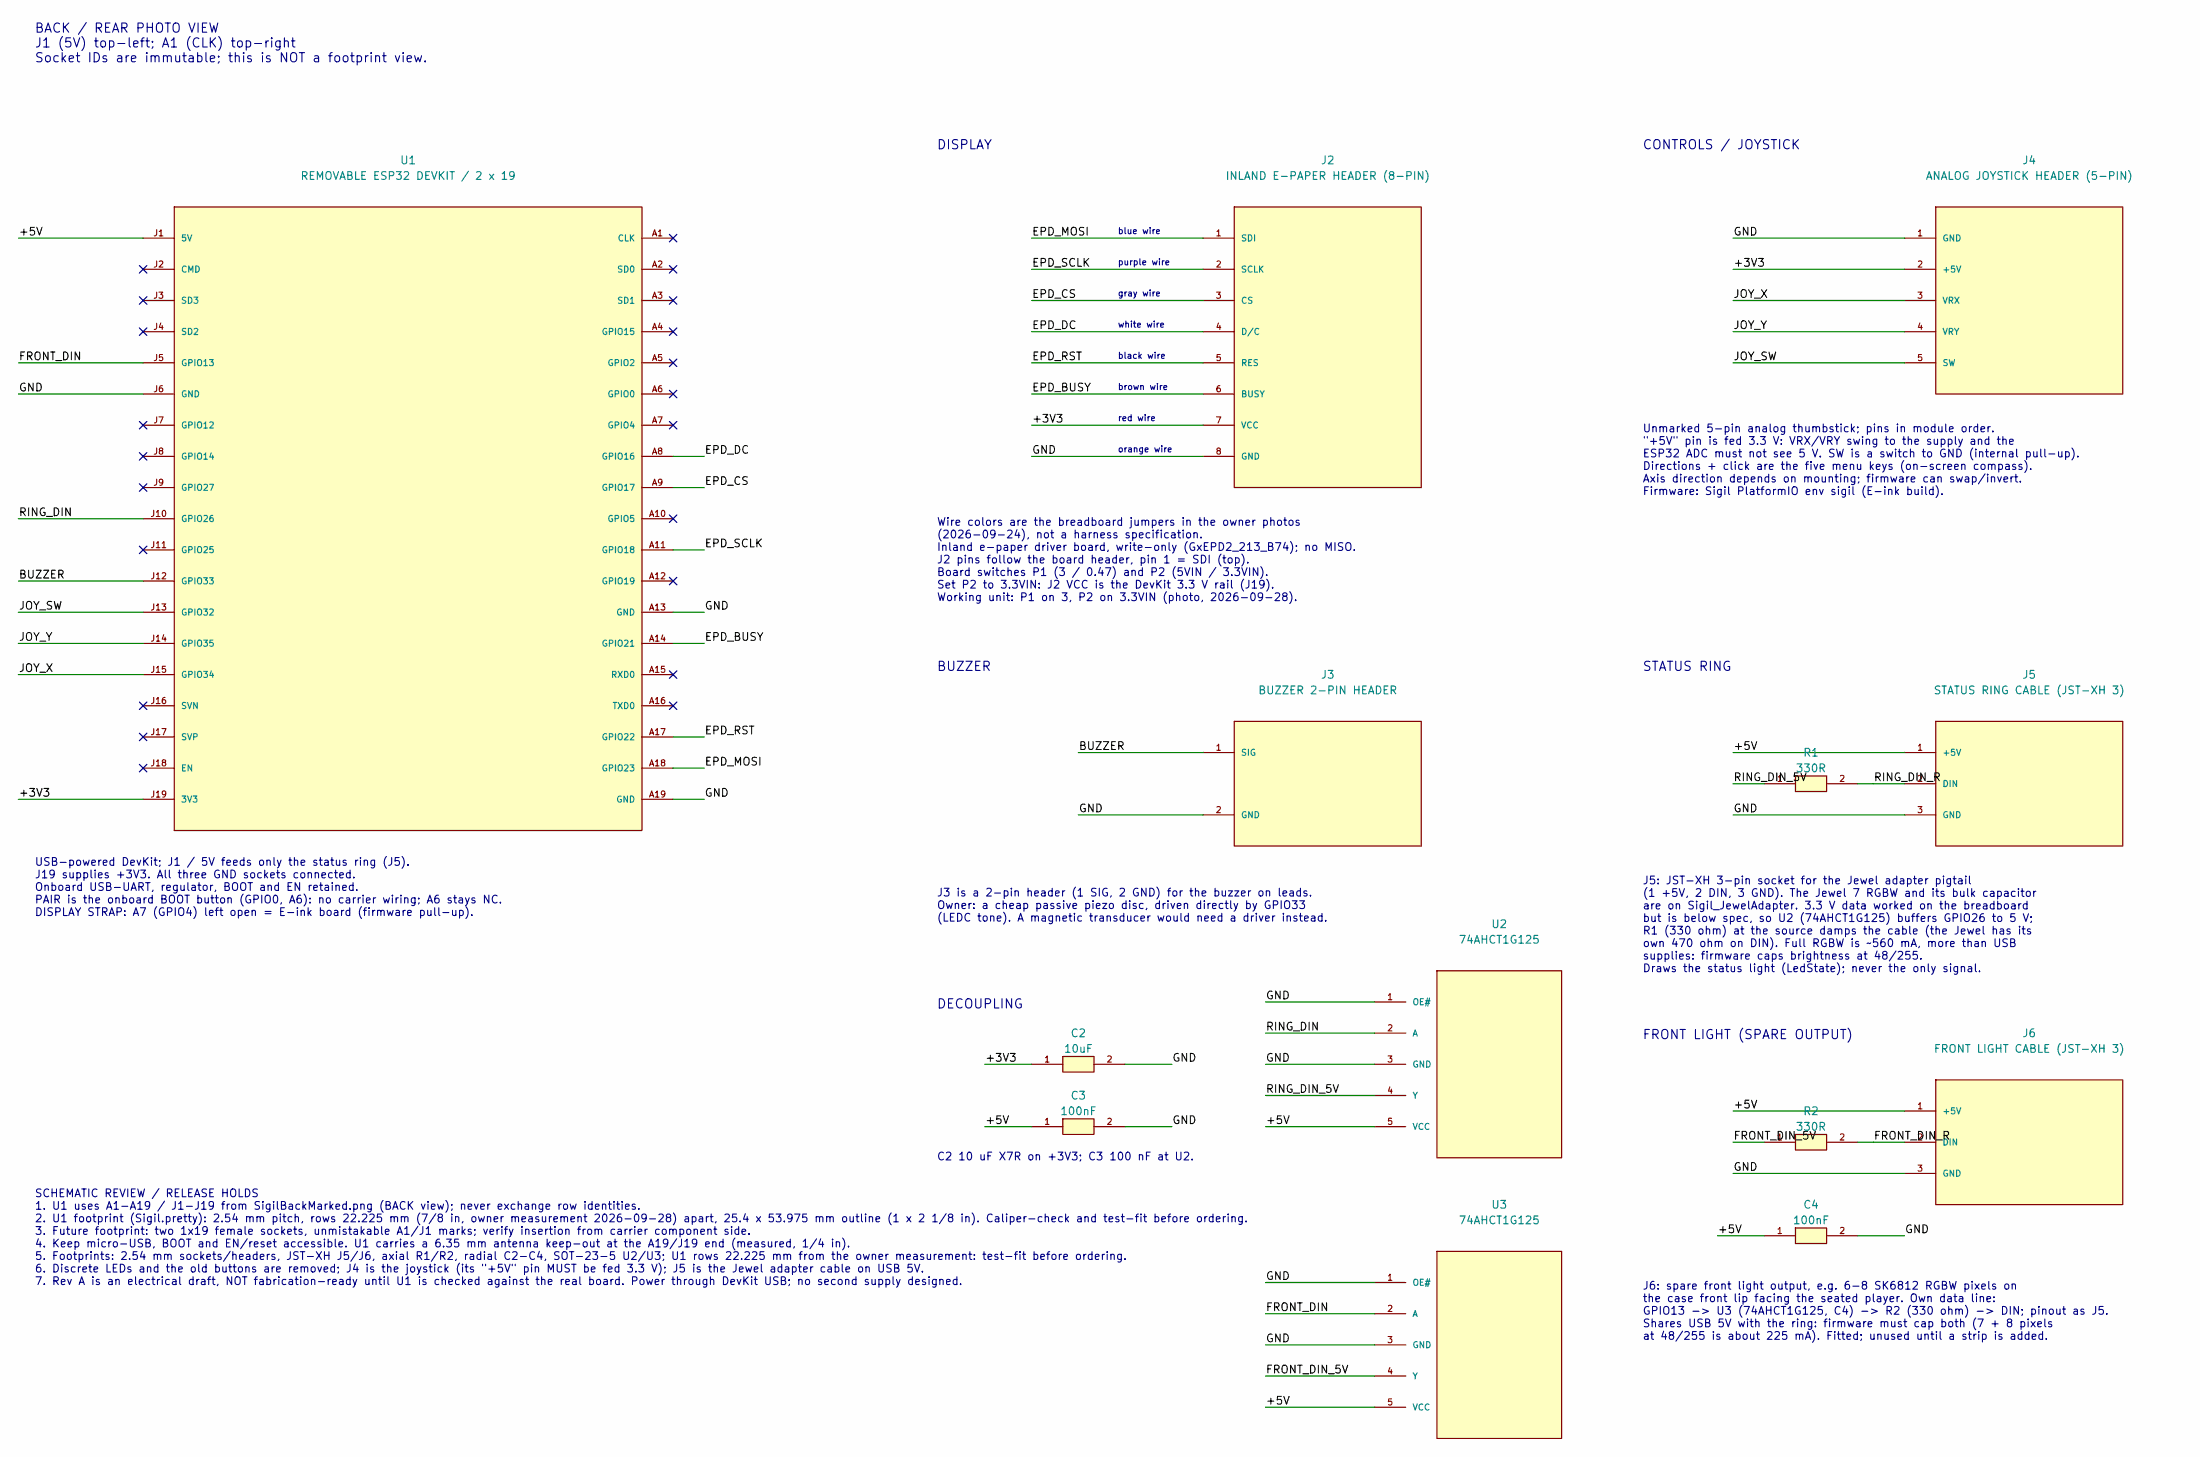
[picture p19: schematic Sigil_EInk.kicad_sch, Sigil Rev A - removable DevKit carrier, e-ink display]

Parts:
C2: 10uF; C_Disc_D5.0mm_W2.5mm_P5.00mm
C3, C4: 100nF; C_Disc_D5.0mm_W2.5mm_P5.00mm
J2: INLAND E-PAPER HEADER (8-PIN); JST_XH_B8B-XH-A_1x08_P2.50mm_Vertical
J3: BUZZER 2-PIN HEADER; PinHeader_1x02_P2.54mm_Vertical
J4: ANALOG JOYSTICK HEADER (5-PIN); JST_XH_B5B-XH-A_1x05_P2.50mm_Vertical
J5: STATUS RING CABLE (JST-XH 3); JST_XH_B3B-XH-A_1x03_P2.50mm_Vertical
J6: FRONT LIGHT CABLE (JST-XH 3); JST_XH_B3B-XH-A_1x03_P2.50mm_Vertical
R1, R2: 330R; R_Axial_DIN0207_L6.3mm_D2.5mm_P7.62mm_Horizontal
U1: REMOVABLE ESP32 DEVKIT / 2 x 19; ESP32_DevKit_38_Socket_Row22.225mm
U2, U3: 74AHCT1G125; SOT-23-5

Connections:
/+3V3: C2.1, J2.7 (VCC), J4.2 (+5V), U1.J19 (3V3)
/+5V: C3.1, C4.1, J5.1 (+5V), J6.1 (+5V), U1.J1 (5V), U2.5 (VCC), U3.5 (VCC)
/BUZZER: J3.1 (SIG), U1.J12 (GPIO33)
/EPD_BUSY: J2.6 (BUSY), U1.A14 (GPIO21)
/EPD_CS: J2.3 (CS), U1.A9 (GPIO17)
/EPD_DC: J2.4 (D/C), U1.A8 (GPIO16)
/EPD_MOSI: J2.1 (SDI), U1.A18 (GPIO23)
/EPD_RST: J2.5 (RES), U1.A17 (GPIO22)
/EPD_SCLK: J2.2 (SCLK), U1.A11 (GPIO18)
/FRONT_DIN: U1.J5 (GPIO13), U3.2 (A)
/FRONT_DIN_5V: R2.1, U3.4 (Y)
/FRONT_DIN_R: J6.2 (DIN), R2.2
/GND: C2.2, C3.2, C4.2, J2.8 (GND), J3.2 (GND), J4.1 (GND), J5.3 (GND), J6.3 (GND), U1.A13 (GND), U1.A19 (GND), U1.J6 (GND), U2.1 (OE#), U2.3 (GND), U3.1 (OE#), U3.3 (GND)
/JOY_SW: J4.5 (SW), U1.J13 (GPIO32)
/JOY_X: J4.3 (VRX), U1.J15 (GPIO34)
/JOY_Y: J4.4 (VRY), U1.J14 (GPIO35)
/RING_DIN: U1.J10 (GPIO26), U2.2 (A)
/RING_DIN_5V: R1.1, U2.4 (Y)
/RING_DIN_R: J5.2 (DIN), R1.2

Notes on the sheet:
C2 10 uF X7R on +3V3; C3 100 nF at U2.
CONTROLS / JOYSTICK
USB-powered DevKit; J1 / 5V feeds only the status ring (J5). J19 supplies +3V3. All three GND sockets connected. Onboard USB-UART, regulator, BOOT and EN retained. PAIR is the onboard BOOT button (GPIO0, A6): no carrier wiring; A6 stays NC. DISPLAY STRAP: A7 (GPIO4) left open = E-ink board (firmwar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
purple wire
BACK / REAR PHOTO VIEW J1 (5V) top-left; A1 (CLK) top-right Socket IDs are immutable; this is NOT a footprint view.
gray wire
DECOUPLING
orange wire
brown wire
Wire colors are the breadboard jumpers in the owner photos (2026-09-24), not a harness specification. Inland e-paper driver board, write-only (GxEPD2_213_B74); no MISO. J2 pins follow the board header, pin 1 = SDI (top). Board switches P1 (3 / 0.47) and P2 (5VIN / 3.3VIN). Set P2 to 3.3VIN: J2 VCC 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
blue wire
DISPLAY
red wire
FRONT LIGHT (SPARE OUTPUT)
J6: spare front light output, e.g. 6-8 SK6812 RGBW pixels on the case front lip facing the seated player. Own data line: GPIO13 -> U3 (74AHCT1G125, C4) -> R2 (330 ohm) -> DIN; pinout as J5. Shares USB 5V with the ring: firmware must cap both (7 + 8 pixels at 48/255 is about 225 mA). Fitted; unused 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
J5: JST-XH 3-pin socket for the Jewel adapter pigtail (1 +5V, 2 DIN, 3 GND). The Jewel 7 RGBW and its bulk capacitor are on Sigil_JewelAdapter. 3.3 V data worked on the breadboard but is below spec, so U2 (74AHCT1G125) buffers GPIO26 to 5 V; R1 (330 ohm) at the source damps the cable (the Jewel has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
STATUS RING
SCHEMATIC REVIEW / RELEASE HOLDS 1. U1 uses A1-A19 / J1-J19 from SigilBackMarked.png (BACK view); never exchange row identities. 2. U1 footprint (Sigil.pretty): 2.54 mm pitch, rows 22.225 mm (7/8 in, owner measurement 2026-09-28) apart, 25.4 x 53.975 mm outline (1 x 2 1/8 in). Caliper-check and tes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
black wire
white wire
Unmarked 5-pin analog thumbstick; pins in module order. "+5V" pin is fed 3.3 V: VRX/VRY swing to the supply and the ESP32 ADC must not see 5 V. SW is a switch to GND (internal pull-up). Directions + click are the five menu keys (on-screen compass). Axis direction depends on mounting; firmware can s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
J3 is a 2-pin header (1 SIG, 2 GND) for the buzzer on leads. Owner: a cheap passive piezo disc, driven directly by GPIO33 (LEDC tone). A magnetic transducer would need a driver instead.
BUZZER

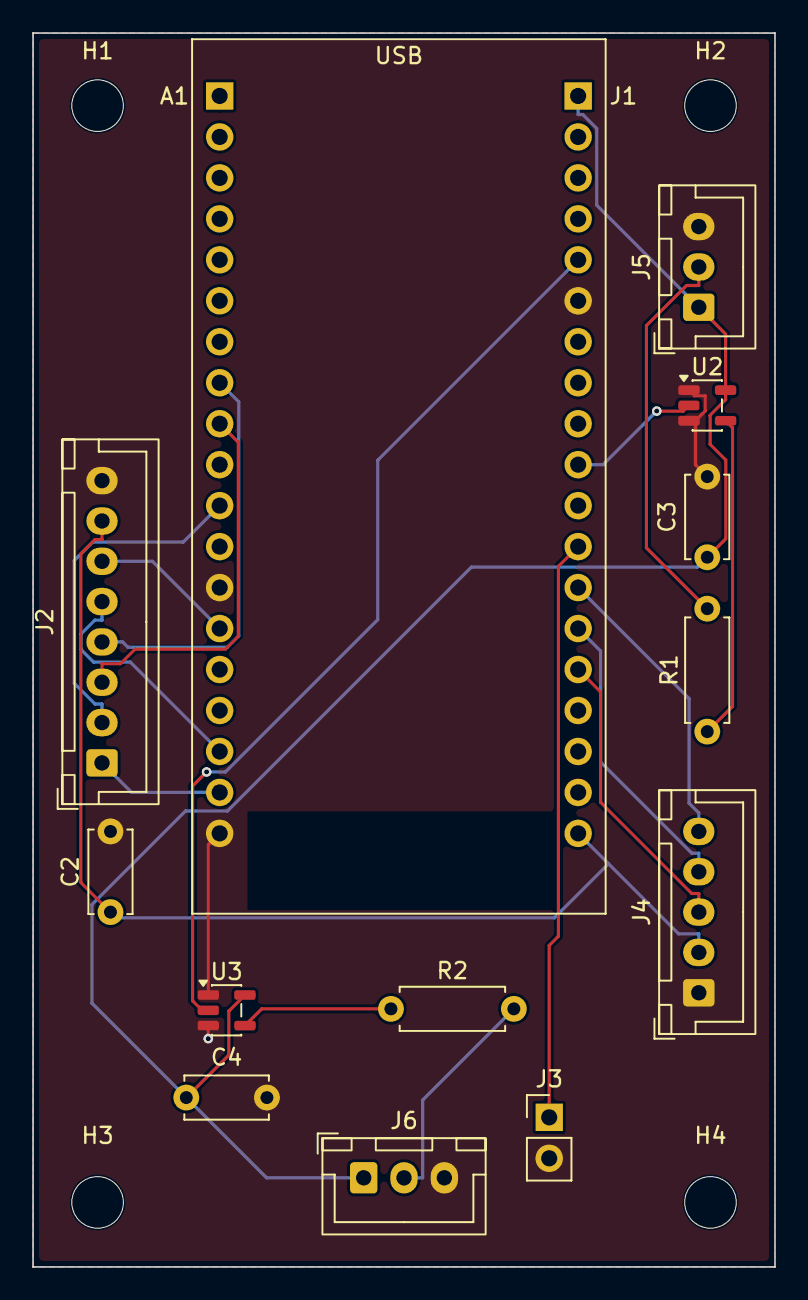
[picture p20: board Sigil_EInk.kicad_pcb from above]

Board: 2 copper layers, 46.0 x 76.5 mm, 17 parts (0 on the bottom side), 19 nets.

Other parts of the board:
H1, H2, H3, H4: M3; MountingHole_3.2mm_M3

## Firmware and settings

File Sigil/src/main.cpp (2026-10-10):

// Sigil player controller firmware. Buttons become ESP-NOW packets for
// Atlas; Atlas's packets drive the LEDs, buzzer and selected display. Sigil
// decides nothing about the game (ARCHITECTURAL_INVARIANTS.md, Invariant 1):
// it only persists the minimum pairing binding needed to find Atlas again.
//
// Threads: ESP-NOW receive callbacks only enqueue packets; loop() handles
// them. Rendering runs on its own task (displayTask) because e-paper refresh
// blocks for seconds; state shared with it is guarded by displayProfileMux.

#include <Arduino.h>
#include <WiFi.h>
#include <esp_now.h>
#include <esp_wifi.h>
#include <esp_sleep.h>
#include <driver/rtc_io.h>
#include <driver/gpio.h>
#include <nvs_flash.h>
#include <Preferences.h>
#include <freertos/queue.h>

#include "atlas_link.h"
#include "firmware_version.h"
#include "protocol.h"
#include "three_part_button.h"
#include "sigil_display.h"
#include "sigil_led.h"
#include "received_packet.h"
#include "pairing_v2.h"
#include "secure_session.h"
#include "secure_link_mbedtls.h"
#ifndef TURNHUB_SPARE
#define TURNHUB_SPARE 0
#endif
#ifndef TURNHUB_WOKWI
#include "firmware_package.h"

#if !TURNHUB_SPARE
// This build's identity, read by tools/firmware/thfw.py when it packages
// firmware.bin for OTA (FIRMWARE_UPDATES.md). The Wokwi build has none, so it can't
// be packaged.
#ifdef TURNHUB_DISPLAY_OLED
constexpr TurnHubFirmwarePackage::Product SIGIL_PRODUCT = TurnHubFirmwarePackage::Product::SigilOled;
#else
constexpr TurnHubFirmwarePackage::Product SIGIL_PRODUCT = TurnHubFirmwarePackage::Product::SigilEink;
#endif
TURNHUB_FIRMWARE_DESCRIPTOR(sigilFirmwareDescriptor, SIGIL_PRODUCT, TurnHubSigilFirmware::MAJOR,
    TurnHubSigilFirmware::MINOR, TurnHubSigilFirmware::PATCH, TurnHubProtocol::VERSION);
#endif
#include "sigil_updater.h"
#define TURNHUB_OTA 1
#else
#define TURNHUB_OTA 0
#endif

#include "joystick_input.h"
#ifndef TURNHUB_DISPLAY_OLED
#define TURNHUB_DISPLAY_OLED 0
#endif
// Every Sigil has the same thumbstick (five keys), Atlas's action menu and
// the Jewel ring, on the same GPIOs; only the display differs (2026-10-01).
#include "sigil_menu.h"
#include "picker_list.h"
#include "life_adjust.h"
#include "status_ring.h"
#include "idle_sleep.h"

namespace {

using TurnHubProtocol::DisplayMode;
using TurnHubProtocol::Packet;
using TurnHubProtocol::PacketType;
using TurnHubSigil::SigilDisplay;

constexpr uint8_t UNASSIGNED_SIGIL_ID = 0xFF;
constexpr uint8_t WIFI_CHANNEL = 6;

// Hardware-type strap (carrier header A7, GPIO4): left open on an E-ink
// Sigil, wired to GND on an OLED Sigil. It stays with the board through every
// flash and erase, so a build for the other display refuses to start.
constexpr uint8_t HW_TYPE_STRAP_PIN = 4;

// Status light: NeoPixel Jewel 7 Data Input, via 330 ohm (J10). Powered from
// 5V (J1). Both hardware Sigils use it; there is no separate LED.
constexpr uint8_t STATUS_RING_PIN = 26;
// Five keys (Up, Down, Left, Right, Select). Each is a debounced button: a
// real GPIO switched to GND, or a virtual pin (0xE0+) read from the stick.
constexpr uint8_t STICK_UP_PIN = 0xE0;  // 0xE0-0xE3: Up, Down, Left, Right.
// Analog thumbstick (powered from 3.3 V, never 5 V: VRX/VRY swing to the
// supply); clicking it is Select. VRX/VRY must be ADC1 pins: ADC2 is unusable
// while ESP-NOW has the radio. GPIO25 is unused; GPIO26 drives the ring.
constexpr uint8_t JOYSTICK_X_PIN = 34;     // VRX, input-only ADC1 (J15).
constexpr uint8_t JOYSTICK_Y_PIN = 35;     // VRY, input-only ADC1 (J14).
constexpr uint8_t JOYSTICK_CALIBRATION_SAMPLES = 16;
constexpr uint32_t JOYSTICK_SAMPLE_MS = 5;
constexpr uint8_t KEY_PINS[] = {STICK_UP_PIN, STICK_UP_PIN + 1, STICK_UP_PIN + 2,
    STICK_UP_PIN + 3, 32 /* SW (J13) */};
constexpr uint8_t BUZZER_PIN = 33;
constexpr uint8_t BUZZER_CHANNEL = 7;
#if defined(TURNHUB_WOKWI)
constexpr uint8_t PAIR_BUTTON = 19;  // diagram.json's Pair pushbutton.
#else
// The DevKit's onboard BOOT button (GPIO0, pulled up on the board). GPIO0 is
// a strapping pin only at reset: holding BOOT while resetting enters the ROM
// downloader instead of this firmware, so Pair works from boot onward.
constexpr uint8_t PAIR_BUTTON = 0;
#endif

// Spare build (env:sigil-spare, FIRMWARE_UPDATES.md): one image for any Sigil
// board, with no display, input or buzzer. It keeps its pairing, announces
// CAPABILITY_SPARE and its strap's display type, and takes the matching OTA
// package, which brings it back as a normal Sigil.
bool spareStrapOled = false;

// Hello announces only what varies between Sigils (protocol.h); Atlas assumes
// the rest. The display bit also picks the OTA package (a spare reports its
// GPIO4 strap).
uint8_t deviceCapabilities() {
#if TURNHUB_SPARE
  return TurnHubProtocol::CAPABILITY_SPARE |
      (spareStrapOled ? TurnHubProtocol::CAPABILITY_DISPLAY_OLED : 0);
#else
  return TURNHUB_DISPLAY_OLED ? TurnHubProtocol::CAPABILITY_DISPLAY_OLED : 0;
#endif
}

constexpr uint32_t DEBOUNCE_MS = 30;
constexpr uint32_t HELLO_INTERVAL_MS = 2000;
constexpr uint32_t PAIRING_DURATION_MS = TurnHubProtocol::PAIRING_WINDOW_MS;
// Status light: frames are rendered at most this often.
constexpr uint32_t LED_FRAME_MS = 20;
constexpr uint32_t DISPLAY_TASK_STACK_BYTES = 4096;
constexpr uint32_t PROFILE_REQUEST_RETRY_MS = 1000;
constexpr uint8_t PROFILE_REQUEST_MAX_ATTEMPTS = 4;
constexpr uint8_t PROFILE_SLOT_MASK = 0x03;
constexpr uint8_t RECEIVE_QUEUE_LENGTH = 32;

// The saved pairing in NVS, one record: Atlas's MAC (6 bytes), this Sigil's
// ID (1) and the pair key agreed at pairing (PAIRING_AND_SECURE_LINK.md). A record of any
// other size isn't a pairing and is dropped.
constexpr char PAIRING_NAMESPACE[] = "th_pair";
constexpr char PAIRING_KEY[] = "atlas";
constexpr size_t PAIRING_RECORD_SIZE = 7 + TurnHubSecureLink::KEY_BYTES;

constexpr uint8_t BROADCAST_MAC[6] = {
    0xFF, 0xFF, 0xFF, 0xFF, 0xFF, 0xFF};

// Active-low INPUT_PULLUP button with debounce and hold tracking.
struct ButtonState {
  explicit ButtonState(uint8_t buttonPin) : pin(buttonPin) {}

  uint8_t pin;
  bool rawState = HIGH;
  bool stableState = HIGH;
  uint32_t lastDebounceMs = 0;
  uint32_t pressStartMs = 0;
  bool longSent = false;
};

ButtonState pairButton(PAIR_BUTTON);
// Quick press pairs, a medium hold unpairs, a long hold factory resets.
TurnHubProtocol::ThreePartButton pairGesture;
ButtonState keys[] = {ButtonState(KEY_PINS[0]), ButtonState(KEY_PINS[1]),
    ButtonState(KEY_PINS[2]), ButtonState(KEY_PINS[3]), ButtonState(KEY_PINS[4])};
static_assert(sizeof(keys) / sizeof(keys[0]) == TurnHubSigil::KEY_COUNT, "One button per key");
// The e-ink uses the fixed-key compass; the OLED, which redraws instantly, a
// scrolling list behind Up (the click still passes) that names a held action
// on screen. The e-ink leaves hold progress to the light.
TurnHubSigil::SigilMenu sigilMenu(TURNHUB_DISPLAY_OLED ? TurnHubSigil::MenuStyle::List
                                                       : TurnHubSigil::MenuStyle::Compass);
TurnHubProtocol::SigilAction lastSelectedAction = TurnHubProtocol::SigilAction::Count;
// Menu snapshot for the display task (guarded by displayProfileMux).
TurnHubSigil::MenuView publishedMenuView;
TurnHubSigil::MenuView pendingMenuView;
bool menuViewChanged = false;
// Menu Sigils also draw Atlas's profile picker (ProfilePickerPacket): the
// e-ink as a compass, the OLED as a list (picker_list.h).
// Latest page from Atlas (guarded by displayProfileMux). While open, the keys
// go to the picker (PickerKey) instead of the menu. pickerCursor is the OLED
// list row, reset on every new page.
TurnHubProtocol::CommanderFlowPacket pendingCommander{};
volatile bool commanderActive = false;
bool commanderChanged = false;
uint16_t commanderDrawnRevision = 0;
TurnHubProtocol::CommanderStage commanderDrawnStage = TurnHubProtocol::CommanderStage::Closed;
TurnHubProtocol::ProfilePickerPacket pendingPicker{};
volatile bool pickerActive = false;
bool pickerChanged = false;
uint8_t pickerCursor = 0;
// Life (AdjustLife, LifeRequest): Left/Right presses batched by lifeAdjuster;
// the request shown for this Sigil's answer. lifeKeyRouted remembers which
// key-downs went to life so their releases do not reach the menu.
TurnHubSigil::LifeAdjuster lifeAdjuster;
TurnHubProtocol::LifeRequestFields lifeRequest;
uint8_t seatAvatars[2] = {0, 0};  // From SeatColor; drawn by the OLED.
int32_t startingLife = 0;  // From StartingLife: sizes the life heart.
uint8_t passingPlayer = 0;  // From PassPending: whose pass is pending.
uint8_t updateNotice = 0;   // From UpdateNotice: 0 none, 1 Atlas, 2 a Sigil.
bool lifeKeyRouted[TurnHubSigil::KEY_COUNT] = {};
// Snapshot for the display task (guarded by displayProfileMux).
TurnHubSigil::LifeOverlay publishedLifeOverlay;
TurnHubSigil::LifeOverlay pendingLifeOverlay;
bool lifeOverlayChanged = false;
SigilDisplay &sigilDisplay = TurnHubSigil::getSigilDisplay();

bool espNowReady = false;
bool atlasKnown = false;
// Whether the paired Atlas still answers; atlasLostShown mirrors it for the
// display task.
TurnHubSigil::AtlasLink atlasLink;
volatile bool atlasLostShown = false;
uint8_t atlasMac[6] = {};
volatile uint8_t sigilId = UNASSIGNED_SIGIL_ID;
uint32_t lastHelloMs = 0;
uint32_t buzzerStopAtMs = 0;
// Status light: Atlas's LedState plus Sigil-local
// pairing and pass-ack, rendered to the Jewel ring.
TurnHubSigil::SigilLedModel ledModel;
uint32_t lastLedFrameMs = 0;
bool ledOutputValid = false;
volatile bool pairingActive = false;
uint32_t pairingStartMs = 0;
int32_t pairingToken = 0;
uint32_t lastPairRequestMs = 0;
// Pairing (pairing_v2.h, PAIRING_AND_SECURE_LINK.md): the key agreement and code check,
// and the pair key for the saved Atlas.
TurnHubSecureLink::MbedtlsCrypto linkCrypto;
TurnHubSecureLink::SigilPairing pairingV2;
TurnHubSecureLink::PairRequest2Packet pairRequest2{};
uint8_t atlasPairKey[TurnHubSecureLink::KEY_BYTES] = {};
// The secure session with the saved Atlas (secure_session.h). Everything
// but pairing and the handshake travels sealed in it; RAM only.
TurnHubSecureLink::SigilSession linkSession;
// When a packet from Atlas last opened (or its handshake answer arrived).
uint32_t lastAtlasFrameMs = 0;
// The code on screen while the owner checks it (read by the display task).
volatile bool pairingCodeShown = false;
volatile uint16_t pairingCodeValue = 0;
// Hold thresholds: Atlas sends them from the seated players' accessibility
// preferences (InputTiming). Runtime only; a reboot returns to the defaults
// until Atlas resends them.
uint32_t longPressMs = TurnHubProtocol::DEFAULT_LONG_PRESS_MS;
uint32_t winHoldMs = TurnHubProtocol::DEFAULT_WIN_HOLD_MS;
using TurnHubSigil::ReceivedPacket;
QueueHandle_t receiveQueue = nullptr;
volatile bool displayNeedsRefresh = false;
volatile int32_t displayPayload = 0;
uint8_t displayRenderedSigilId = UNASSIGNED_SIGIL_ID;
TaskHandle_t displayTaskHandle = nullptr;

TurnHubProtocol::GameDisplayPacket pendingGameDisplay{};
bool gameDisplayValid = false;
portMUX_TYPE displayProfileMux = portMUX_INITIALIZER_UNLOCKED;
TurnHubTheme::Id selectedTheme = TURNHUB_DISPLAY_OLED ? TurnHubTheme::Id::Graphite : TurnHubTheme::Id::Daylight;
TurnHubTheme::Id pendingTheme = selectedTheme;
bool themeChanged = false;
bool selectedInverted = false;
bool pendingInverted = false;

#if TURNHUB_OTA
// Sigil OTA (sigil_updater.h). While an update runs, loop() is inside
// updater.run(); the display task draws the progress below.
TurnHubSigil::SigilUpdater updater;
bool updateScreenActive = false;   // Guarded by displayProfileMux.
bool updateScreenChanged = false;
char updateScreenText[24] = {};
int8_t updateScreenPercent = -1;
#endif
char pendingSeatNames[2][TurnHubProtocol::DISPLAY_NAME_MAX_LENGTH + 1] = {};
uint16_t receivedNameChunks[2] = {};
uint8_t finalNameChunk[2] = {0xFF, 0xFF};
volatile uint8_t pendingSeatNameMask = 0;
volatile uint8_t completedProfileSlotMask = 0;
volatile bool profileSyncStartPending = false;
bool profileRequestActive = false;
uint8_t profileRequestAttempts = 0;
uint32_t lastProfileRequestMs = 0;

void printMac(const uint8_t *mac) {
  Serial.printf(
      "%02X:%02X:%02X:%02X:%02X:%02X",
      mac[0], mac[1], mac[2], mac[3], mac[4], mac[5]);
}

bool ensurePeer(const uint8_t *mac) {
  if (esp_now_is_peer_exist(mac)) {
    return true;
  }

  esp_now_peer_info_t peer{};
  memcpy(peer.peer_addr, mac, 6);
  peer.channel = WIFI_CHANNEL;
  peer.encrypt = false;

  const esp_err_t result = esp_now_add_peer(&peer);
  if (result != ESP_OK) {
    Serial.print("SIGIL|ESP_NOW|PEER_ERROR|");
    printMac(mac);
    Serial.print("|");
    Serial.println(static_cast<int>(result));
    return false;
  }

  return true;
}

void rememberAtlas(const uint8_t *mac) {
  if (!atlasKnown || memcmp(atlasMac, mac, 6) != 0) {
    memcpy(atlasMac, mac, 6);
    atlasKnown = true;

    Serial.print("SIGIL|ATLAS|DISCOVERED|");
    printMac(atlasMac);
    Serial.println();
  }

  ensurePeer(atlasMac);
}

// Every packet to Atlas travels sealed in the current session; with none
// (before Atlas answers SecureHello) nothing is sent.
void sendPacket(PacketType type, int32_t value = 0) {
  if (!espNowReady || !atlasKnown || !linkSession.ready() || !ensurePeer(atlasMac)) {
    return;
  }
  const Packet packet = TurnHubProtocol::makePacket(type, sigilId, value);
  uint8_t frame[sizeof(Packet) + TurnHubSecureLink::SECURE_OVERHEAD];
  const size_t length = linkSession.seal(linkCrypto, &packet, sizeof(packet), frame, sizeof(frame));
  if (length == 0) return;
  const esp_err_t result = esp_now_send(atlasMac, frame, length);

  if (result != ESP_OK) {
    Serial.print("SIGIL|ESP_NOW|SEND_ERROR|");
    Serial.println(static_cast<int>(result));
  }
}

// A pairing v2 request (38 bytes), broadcast like the old PairRequest.
void sendBroadcastRaw(const void *data, size_t length) {
  if (!espNowReady || !ensurePeer(BROADCAST_MAC)) return;
  const esp_err_t result =
      esp_now_send(BROADCAST_MAC, static_cast<const uint8_t *>(data), length);
  if (result != ESP_OK) {
    Serial.print("SIGIL|ESP_NOW|SEND_ERROR|");
    Serial.println(static_cast<int>(result));
  }
}

// Every HELLO_INTERVAL_MS. With a session and Atlas heard lately, a sealed
// Hello keeps it alive; otherwise (boot, pairing, Atlas restarted or quiet)
// a SecureHello starts a new one.
void sendHello() {
  lastHelloMs = millis();
  if (!atlasKnown || !linkSession.hasKey()) return;
  const int32_t helloInfo = TurnHubProtocol::encodeHelloInfo(
      TurnHubSigilFirmware::MAJOR,
      TurnHubSigilFirmware::MINOR,
      TurnHubSigilFirmware::PATCH,
      deviceCapabilities());
  if (linkSession.ready() && millis() - lastAtlasFrameMs <= 2 * HELLO_INTERVAL_MS) {
    sendPacket(PacketType::Hello, helloInfo);
    return;
  }
  TurnHubSecureLink::SecureHelloPacket hello;
  if (!espNowReady || !linkSession.makeHello(linkCrypto, helloInfo, hello) ||
      !ensurePeer(atlasMac)) {
    return;
  }
  esp_now_send(atlasMac, reinterpret_cast<const uint8_t *>(&hello), sizeof(hello));
}

// Renders the current light state to the Jewel ring (hardware Sigils) or the
// RGB LED pins (Wokwi; PWM on all three for full color). Hardware changes
// only when the frame differs.
// "identify" on the serial console (tools\setup-boards.cmd sends it) blinks
// the whole ring white until then, so the owner can tell which board the
// script is asking about.
constexpr uint32_t IDENTIFY_MS = 10000;
uint32_t identifyUntilMs = 0;
bool identifying = false;
uint32_t ringTestStartedMs = 0;
bool ringTesting = false;
bool screenTestPending = false;  // Guarded by displayProfileMux.
bool screenTestBusy = false;     // Guarded by displayProfileMux.
void publishMenuView();
void publishLifeOverlay();

void updateLeds() {
  const uint32_t nowMs = millis();
  if (ledOutputValid && nowMs - lastLedFrameMs < LED_FRAME_MS) return;
  lastLedFrameMs = nowMs;
  if (identifying && static_cast<int32_t>(nowMs - identifyUntilMs) >= 0) identifying = false;
  TurnHubSigil::LedFrame frame = ledModel.render(nowMs);
  if (ringTesting) {
    const uint32_t elapsed = nowMs - ringTestStartedMs;
    if (elapsed >= 6000) ringTesting = false;
    else {
      const TurnHubSigil::Rgb colors[] = {{80, 0, 0}, {0, 80, 0}, {0, 0, 80}, {80, 80, 80}};
      for (auto &pixel : frame.pixels) pixel = colors[elapsed / 1500];
    }
  }
  if (identifying) {
    const bool on = nowMs % 500 < 250;
    for (auto &pixel : frame.pixels) pixel = on ? TurnHubSigil::Rgb(80, 80, 80) : TurnHubSigil::Rgb();
  }
  TurnHubSigil::statusRingShow(frame);
  ledOutputValid = true;
}

// Both physical builds swap the stick axes. Owner case-installation check
// (2026-10-09): both sticks report reversed cardinal directions after the
// 180-degree mounting rotation; reverse both axes in each physical profile.
TurnHubSigil::StickConfig stickConfig() {
  TurnHubSigil::StickConfig config;
#ifndef TURNHUB_WOKWI  // The simulated stick reads the right way round.
  config.swapAxes = true;
#ifdef TURNHUB_DISPLAY_OLED
  config.invertX = false;
  config.invertY = true;
#else
  config.invertX = true;
  config.invertY = false;
#endif
#endif
  return config;
}
TurnHubSigil::StickTracker stick(stickConfig());
uint32_t lastStickSampleMs = 0;

// Rest the stick at boot: a missing or held stick disables the directions
// (the click still works as Select).
void calibrateJoystick() {
  const auto config = stickConfig();
  Serial.printf("SIGIL|JOYSTICK|ORIENTATION|SWAP_XY|%u|INVERT_X|%u|INVERT_Y|%u\n",
      static_cast<unsigned>(config.swapAxes), static_cast<unsigned>(config.invertX),
      static_cast<unsigned>(config.invertY));
  int16_t xs[JOYSTICK_CALIBRATION_SAMPLES];
  int16_t ys[JOYSTICK_CALIBRATION_SAMPLES];
  for (uint8_t i = 0; i < JOYSTICK_CALIBRATION_SAMPLES; ++i) {
    xs[i] = static_cast<int16_t>(analogRead(JOYSTICK_X_PIN));
    ys[i] = static_cast<int16_t>(analogRead(JOYSTICK_Y_PIN));
    delay(2);
  }
  const bool ok = stick.calibrate(xs, ys, JOYSTICK_CALIBRATION_SAMPLES);
  Serial.printf("SIGIL|JOYSTICK|%s|CENTER|%d|%d\n", ok ? "READY" : "NOT_CENTERED_DISABLED",
      stick.centerX(), stick.centerY());
}

void updateJoystick(uint32_t nowMs) {
  if (nowMs - lastStickSampleMs < JOYSTICK_SAMPLE_MS) return;
  lastStickSampleMs = nowMs;
  const TurnHubSigil::StickDirection before = stick.direction();
  const TurnHubSigil::StickDirection after = stick.update(
      static_cast<int16_t>(analogRead(JOYSTICK_X_PIN)),
      static_cast<int16_t>(analogRead(JOYSTICK_Y_PIN)));
  if (after != before) {
    Serial.print("SIGIL|JOYSTICK|");
    Serial.println(TurnHubSigil::stickDirectionName(after));
  }
}

// Active-low reading; joystick virtual pins are LOW while pushed that way.
bool readButton(uint8_t pin) {
  if (pin >= STICK_UP_PIN && pin <= STICK_UP_PIN + 3) {
    static constexpr TurnHubSigil::StickDirection DIRECTIONS[] = {
        TurnHubSigil::StickDirection::Up, TurnHubSigil::StickDirection::Down,
        TurnHubSigil::StickDirection::Left, TurnHubSigil::StickDirection::Right};
    return stick.direction() == DIRECTIONS[pin - STICK_UP_PIN] ? LOW : HIGH;
  }
  return digitalRead(pin);
}

// The last key, joystick or Pair press or release (auto sleep, idle_sleep.h).
uint32_t lastInputMs = 0;

// Returns true once each time the button settles in a new state.
bool debouncedEdge(ButtonState &button, uint32_t nowMs) {
  const bool reading = readButton(button.pin);
  if (reading != button.rawState) {
    button.rawState = reading;
    button.lastDebounceMs = nowMs;
  }
  if (nowMs - button.lastDebounceMs < DEBOUNCE_MS || button.stableState == button.rawState) {
    return false;
  }
  button.stableState = button.rawState;
  lastInputMs = nowMs;
  return true;
}

void notifyDisplayTask() {
  if (displayTaskHandle != nullptr) {
    xTaskNotifyGive(displayTaskHandle);
  }
}

void loadDisplayTheme() {
  Preferences prefs;
  if (prefs.begin("display", true)) {
    const uint8_t stored = prefs.getUChar("theme", static_cast<uint8_t>(selectedTheme));
    selectedInverted = prefs.getBool("inverted", false);
    prefs.end();
    if (TurnHubTheme::valid(stored)) selectedTheme = static_cast<TurnHubTheme::Id>(stored);
  }
  pendingTheme = selectedTheme;
  pendingInverted = selectedInverted;
  sigilDisplay.setInverted(selectedInverted);
  sigilDisplay.setTheme(selectedTheme);
  ledModel.setTheme(selectedTheme);
}
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
void loop() {
#if !defined(TURNHUB_WOKWI)
  readSerialCommands();
#endif
  // Going to sleep: nothing else runs (the display task draws the screen).
  if (sleepRequested) {
    if (displayTaskHandle == nullptr) updateDisplay();
    updateSleep(millis());
    delay(1);
    return;
  }
  ReceivedPacket received;
  // Bounded so a packet burst cannot starve the buttons.
  for (uint8_t n = 0; receiveQueue && n < RECEIVE_QUEUE_LENGTH &&
       xQueueReceive(receiveQueue, &received, 0) == pdTRUE; ++n) {
    handleEspNowReceive(received.mac,
        received.data, received.length);
  }
#if TURNHUB_OTA
  // A new image is kept only once it has a secure session with Atlas again.
  updater.confirmBoot(linkSession.ready(), millis());
  if (updater.pending()) updater.run();  // Blocks; restarts on success.
#endif
  updateJoystick(millis());
#if TURNHUB_SPARE
  updateSpareKeys();
#else
  updateMenuKeys();
#endif
  updatePairButton();
  updatePairing();
  applyAtlasLinkChange(atlasLink.update(millis()));
#if !TURNHUB_SPARE
  updateIdleSleep(millis());
#endif
  updateLeds();
  updateBuzzer();
  updateDisplayProfileSync();

  if (displayTaskHandle == nullptr) {
    // Safe fallback if the display worker could not be created.
    updateDisplay();
  }

  if (espNowReady && millis() - lastHelloMs >= HELLO_INTERVAL_MS) {
    sendHello();
  }

  delay(1);
}

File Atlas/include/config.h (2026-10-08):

#pragma once

#include <stddef.h>
#include <stdint.h>
#include <Arduino.h>

namespace AtlasConfig {

// Arduino-ESP32 2.0.17's loopTask runs setup, gameplay and synchronous HTTP.
// Provision headroom here; main.cpp overrides the core's weak size function.
constexpr size_t LOOP_TASK_STACK_BYTES = 16 * 1024;
constexpr uint32_t LOOP_STACK_WARNING_BYTES = 3 * 1024;

// Atlas board: LCDwiki 2.8" ESP32-32E display module (E32R28T, resistive
// touch). Pin map from the vendor's pin allocation table; see
// Documentation/engineering/HARDWARE.md. The previous prototype's
// Pair button, status/Pair LEDs and master button are not carried over: the
// touchscreen is Atlas's only physical input (GPIO0 stays the flashing-only
// BOOT strap).

// ILI9341V TFT on its own SPI bus (HSPI). Reset is tied to the ESP32 EN line.
constexpr int8_t TFT_SCLK_PIN = 14;
constexpr int8_t TFT_MOSI_PIN = 13;
constexpr int8_t TFT_MISO_PIN = 12;
constexpr int8_t TFT_CS_PIN = 15;
constexpr int8_t TFT_DC_PIN = 2;
constexpr int8_t TFT_BACKLIGHT_PIN = 21;  // Active high.

// XPT2046 resistive touch controller on a separate SPI bus.
constexpr int8_t TOUCH_SCLK_PIN = 25;
constexpr int8_t TOUCH_MOSI_PIN = 32;
constexpr int8_t TOUCH_MISO_PIN = 39;
constexpr int8_t TOUCH_CS_PIN = 33;
constexpr int8_t TOUCH_IRQ_PIN = 36;  // Active low.

// Screen rotation: 3 is landscape with the board's left-edge connector
// pigtails leaving from the top of the screen (1 would point them at the user).
constexpr uint8_t TFT_ROTATION = 3;

// Touch calibration: raw 12-bit XPT2046 readings at the screen edges, and
// how the raw axes map onto the rotated screen. Starting values from common
// ESP32 2.8" boards; confirm them with the ATLAS|TOUCH|RAW serial lines.
constexpr uint16_t TOUCH_RAW_X_MIN = 200;
constexpr uint16_t TOUCH_RAW_X_MAX = 3700;
constexpr uint16_t TOUCH_RAW_Y_MIN = 240;
constexpr uint16_t TOUCH_RAW_Y_MAX = 3800;
constexpr bool TOUCH_SWAP_XY = false;
constexpr bool TOUCH_INVERT_X = true;
constexpr bool TOUCH_INVERT_Y = true;
// Minimum pressure (Z) that counts as a touch.
constexpr uint16_t TOUCH_PRESSURE_MIN = 400;

// microSD slot on VSPI, shared with the "SPI" expansion header (CS IO27).
constexpr int8_t SD_SCLK_PIN = 18;
constexpr int8_t SD_MOSI_PIN = 23;
constexpr int8_t SD_MISO_PIN = 19;
constexpr int8_t SD_CS_PIN = 5;
// Conservative clock for bring-up; raise once cards are proven on the bench.
constexpr uint32_t SD_SPI_HZ = 4000000;

// Common-anode RGB LED: each channel is active low.
constexpr uint8_t RGB_RED_PIN = 22;
constexpr uint8_t RGB_GREEN_PIN = 16;
constexpr uint8_t RGB_BLUE_PIN = 17;

// The board's BOOT button (GPIO0, pulled up, low when pressed). GPIO0 is a
// strapping pin only at reset, so it is free to use once Atlas is running:
// quick press pairs, a medium hold forgets every Sigil, a long hold factory
// resets Atlas (three_part_button.h). A backup for the touchscreen.
constexpr uint8_t BOOT_BUTTON_PIN = 0;

// Speaker amplifier: enable is active low; audio input is IO26 (the DAC pin,
// driven as an LEDC square wave by atlas_speaker.cpp).
constexpr uint8_t AUDIO_ENABLE_PIN = 4;
constexpr uint8_t AUDIO_DAC_PIN = 26;

// Battery voltage divider (input-only ADC pin), from the board's battery
// connector (a single-cell LiPo, charged on board). The cell voltage is the
// pin voltage times NUMERATOR / DENOMINATOR: the LCDwiki ESP32-32E boards
// halve it. *Needs verification*: if the shown voltage disagrees with a
// meter at the battery plug, correct the ratio here (atlas_battery.cpp).
constexpr uint8_t BATTERY_ADC_PIN = 34;
constexpr uint32_t BATTERY_DIVIDER_NUMERATOR = 2;
constexpr uint32_t BATTERY_DIVIDER_DENOMINATOR = 1;

// Auto sleep on the cell (owner 2026-10-08: keep the small backup cell from
// running flat). Between games, Atlas sleeps after this long with no player
// action (an Intent from a Sigil, phone or the touchscreen, or a touch). On
// USB it never sleeps by itself.
constexpr uint32_t BATTERY_IDLE_SLEEP_MS = 5UL * 60UL * 1000UL;
// At or below this shown charge, on the cell, Atlas sleeps even mid-game (the
// interrupted match comes back paused) and stays asleep until USB returns.
constexpr uint8_t BATTERY_EMPTY_PERCENT = 3;
// The empty reading must hold this long, so one sag under load can't trip it.
constexpr uint32_t BATTERY_EMPTY_CONFIRM_MS = 30UL * 1000UL;
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

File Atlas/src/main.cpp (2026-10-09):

// Atlas entry point: defines the runtime objects, binds one handler per
// IntentType, brings up Wi-Fi/ESP-NOW/HTTP, restores an interrupted match and
// runs the cooperative main loop. The handlers and adapters themselves live in
// the modules listed in atlas_app.h.

#include <Arduino.h>
#include <WebServer.h>
#include <WiFi.h>

#include "atlas_app.h"
#include "sigil_update_service.h"
#include "sigil_menu.h"
#include "profile_picker.h"
#include "commander_picker.h"
#include "atlas_battery.h"
#include "atlas_display.h"
#include "atlas_speaker.h"
#include "config.h"
#include "firmware_version.h"
#include "firmware_package.h"
#include "game_recovery.h"
#include "game_settings_store.h"
#include "pairing_settings.h"
#include "runtime_diagnostics.h"
#include "http_diagnostics.h"
#include "profile_store.h"
#include "sd_card.h"
#include "secure_link_backend.h"
#include "serial_log.h"
#include "speaker_settings.h"
#include "table_code_setting.h"
#include "wifi_password_store.h"

#if defined(ARDUINO_ARCH_ESP32)
// Supported by the pinned core; app_main uses this value to create loopTask.
SET_LOOP_TASK_STACK_SIZE(AtlasConfig::LOOP_TASK_STACK_BYTES);
#endif

// This build's identity, read by tools/firmware/thfw.py when it packages
// firmware.bin for OTA (FIRMWARE_UPDATES.md).
TURNHUB_FIRMWARE_DESCRIPTOR(atlasFirmwareDescriptor, TurnHubFirmwarePackage::Product::Atlas,
    TurnHubFirmware::MAJOR, TurnHubFirmware::MINOR, TurnHubFirmware::PATCH,
    TurnHubProtocol::VERSION);

using TurnHub::serialLog;

WebServer server(AtlasConfig::HTTP_PORT);

namespace TurnHubAtlas {

// Construction order matters: the renderers and OTA hold references to
// sigilBus and server, which are defined first.
SigilBus sigilBus(AtlasConfig::WIFI_CHANNEL);
IntentDispatcher intents;
LedRenderer leds(sigilBus);
AudioController audio(sigilBus);
TurnHub::ToneOutput *hardwareTestSpeaker = nullptr;
OtaManager ota(server, otaAllowed);

GameTable tables[MAX_GAME_TABLES];
static_assert(MAX_GAME_TABLES <= TurnHub::GAME_RECOVERY_SLOTS, "every game table needs a recovery record");

namespace {
uint8_t currentTable = 0;
}  // namespace

GameTable &table() { return tables[currentTable]; }
uint8_t tableIndex() { return currentTable; }

uint8_t selectTable(uint8_t index) {
  const uint8_t previous = currentTable;
  if (index < MAX_GAME_TABLES) currentTable = index;
  return previous;
}

TableScope::TableScope(uint8_t index) : previous_(selectTable(index)) {}
TableScope::~TableScope() { currentTable = previous_; }

bool gameSettingsAvailable = true;
bool espNowReady = false;
uint32_t pairingWindowMs = TurnHub::DEFAULT_PAIRING_WINDOW_MS;
TurnHub::SetupStage setupStage = TurnHub::SetupStage::Complete;

namespace {
// The SD card generation the luxury store was last pointed for.
uint32_t luxuryStoreGeneration = 0;

// Polling cadence for the elapsed-clock recovery checkpoint (see below).
constexpr uint32_t RECOVERY_POLL_INTERVAL_MS = 1000;
uint32_t lastRecoveryPollMs[MAX_GAME_TABLES] = {};

// Catches the "periodically checkpoint elapsed clocks" requirement for a long
// turn with no dispatched intents in between: GameRecovery::save() only
// writes when >=60s have passed since the last save of a running match, so
// polling this once a second is cheap (no encode-vs-previous work happens
// between checkpoints) and never spams NVS.
void updateGameRecoveryClock(uint32_t nowMs) {
  uint32_t &lastPollMs = lastRecoveryPollMs[tableIndex()];
  if (nowMs - lastPollMs < RECOVERY_POLL_INTERVAL_MS) return;
  lastPollMs = nowMs;
  TurnHub::checkpointGame(table().game, nowMs);
}

// Heap and Wi-Fi client figures, logged periodically and whenever the phone
// count changes, so a crash under load leaves a trail in the serial log, the
// RAM log download and the SD diagnostics log (playtest 2026-09-29, item 1).
constexpr uint32_t HEAP_LOG_INTERVAL_MS = 60000;
uint32_t lastHeapLogMs = 0;
int lastStationCount = -1;

// Names in /api/v1/state are re-read when a seat's occupant changes; this
// also picks up a rename (profile page, Sigil picker) within a few seconds.
constexpr uint32_t CLIENT_NAME_REFRESH_MS = 5000;
uint32_t lastClientNameRefreshMs[MAX_GAME_TABLES] = {};

void refreshClientNames(uint32_t nowMs) {
  uint32_t &lastRefreshMs = lastClientNameRefreshMs[tableIndex()];
  if (nowMs - lastRefreshMs < CLIENT_NAME_REFRESH_MS) return;
  lastRefreshMs = nowMs;
  table().clientState.refreshNames();
}

void logRuntimeHealth(uint32_t nowMs) {
  const int stations = WiFi.softAPgetStationNum();
  if (stations == lastStationCount && nowMs - lastHeapLogMs < HEAP_LOG_INTERVAL_MS) return;
  lastHeapLogMs = nowMs;
  lastStationCount = stations;
  serialLog.print("ATLAS|HEALTH|stations=");
  serialLog.print(stations);
  serialLog.print("|");
  serialLog.println(TurnHub::runtimeDiagnosticsJson());
  TurnHub::warnLowLoopStack(TurnHub::taskStackMinimumFreeBytes(), nowMs);
}

// Free heap after a start-up step, so each boot shows what every part costs
// (ATLAS|HEAP|<step>|free=<bytes>|largest=<bytes>).
void logHeapStep(const char *step) {
  uint32_t freeHeap = 0, largestBlock = 0;
#if defined(ARDUINO_ARCH_ESP32)
  freeHeap = esp_get_free_heap_size();
  largestBlock = heap_caps_get_largest_free_block(MALLOC_CAP_8BIT);
#endif
  serialLog.printf("ATLAS|HEAP|%s|free=%lu|largest=%lu\n", step,
      static_cast<unsigned long>(freeHeap), static_cast<unsigned long>(largestBlock));
}
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

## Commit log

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2026-09-24 Share radio protocol header, set 15s pairing window, add CLAUDE.md
    - Move the hand-copied Atlas/Sigil protocol.h to shared/include/protocol.h
    (Invariant 4); both PlatformIO projects and the host test runners add it
    to the include path.
    - Define PAIRING_WINDOW_MS = 15000 once in the shared header and use it in
    Atlas, SigilBus, Sigil and the pairing scenario instead of four separate
    30000 literals. Update README, engineering docs and User Manual V0.2.
    - Fix the life-change reply to say 15 seconds, matching LIFE_APPROVAL_MS,
    the portal and the docs (manual and V0.2 review table updated too).
    - Remove references to the deliberately absent Controller/ directory and
    delete leftover leg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
    [main.cpp]
2026-09-24 Ignore and untrack local KiCad, PiLogger and scratch files
    - KiCad/.gitignore: local history repo (.history, previously committed as a
    broken gitlink), restore backups, lock files, per-user .kicad_prl, autosaves.
    - PiLogger/.gitignore: local config.toml, telemetry databases, venvs.
    - Root: ignore the "Claude outputs/" scratch folder.
    - Stop tracking the matching files; local copies are kept.
    [Sigilv1.kicad_sch]
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2026-09-24 Atlas: ship a default Wi-Fi password until the owner sets one
    A new or factory-reset Atlas now hosts TurnHub-Atlas with the shipped
    pre-setup passphrase "TurnHub-Setup" (AtlasConfig::WIFI_DEFAULT_PASSWORD)
    instead of generating and storing a random one. This lets the Android app
    join a new Atlas without asking; the OOBE setup flow must replace it.
    - The default is never written to NVS: a stored password always means the
    owner chose it, and erasing NVS returns Atlas to the default. Units that
    already stored a password (including the old random ones) keep it.
    - /api/network reports passwordIsDefault; the portal shows
    "Factory default (change it)" while it is in use.
    - Boot logs ATLAS|WI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
    [config.h, main.cpp]
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2026-09-24 Atlas: downloadable RAM serial log and self-describing log lines
    Serial log download
    - New TurnHub::serialLog (serial_log.h/.cpp): a Print that writes to the
    USB serial port unchanged and keeps a 16 KB RAM ring of the same output,
    each line stamped with Atlas uptime. RAM only: cleared on reboot, never
    written to flash; oldest lines drop when full and the loss is reported.
    - All Atlas Serial.print/println/printf calls now go through serialLog.
    Ring updates are short spinlock sections (ESP-NOW callbacks and the TX
    task log from other tasks); stamps are formatted without printf there.
    - GET /api/diagnostics/log (Developer permission, like the other
    diagnostics) returns it as a text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
    [main.cpp]
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2026-09-24 Atlas: split monolithic main.cpp into application modules
    main.cpp had grown to ~2,400 lines holding every Intent handler, every
    transport adapter, the lifecycle transitions and the boot/loop glue, and
    relied on a force-included forward-declaration header to compile.
    Split it along the documented Intent boundary. atlas_app.h now declares
    the shared runtime objects and table-decision state in namespace
    TurnHubAtlas and maps each module:
    - main.cpp: object definitions, handler bindings, networking, setup/loop
    - app_context.cpp: seat lookups, audio masks, Intent builders
    - gameplay_intents.cpp: PASS, pause/resume, concede, win claims,
    life/Commander counters, turn-timer cues
    - table_intents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
    [config.h, intent.h, main.cpp]
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2026-09-24 Tidy Sigil buttons, shared life bound and storage codecs
    Sigil: the Pass, Pair and Action buttons each carried their own copy of
    the debounce logic; they now share debouncedEdge(). The pairing NVS
    namespace/key/binding size and the receive-queue length are named
    constants, the repeated red-LED restore is one helper, and the file
    header documents the thread model. Behavior is unchanged.
    Atlas:
    - LIFE_LIMIT in game_profile.h replaces eight 1000000 literals across
    the engine, checkpoint validation, settings codec and HTTP parsing.
    - game_settings_store.h and login_limiter.h are reformatted with named
    sizes, keys and limits instead of magic numbers.
    - game_recovery.cpp documents the checkpo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
    [main.cpp]
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2026-09-24 Add the Pause/Win button to the Sigil Rev A schematic
    Firmware (PAUSE_WIN_BUTTON = 32) and HARDWARE_REFERENCE.md put the
    Pause/Win button on GPIO32 / socket J13. The schematic had only a
    hand-added BTN_PAUSE label with no switch, so the net was one-ended and
    the embedded U1 symbol no longer matched Sigil.kicad_sym.
    build_schematic.py now draws SW5 from BTN_PAUSE to GND and names the
    J13 pin; verify_schematic.py checks the new mapping and switch. The
    script also emits deterministic pin UUIDs and re-saves through
    kicad-cli when available, so its output matches KiCad's own format.
    KiCad 10.0.6 ERC: 0 errors, 0 warnings.
    Claude-Session: h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
    [Sigilv1.kicad_sch]
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2026-09-24 Atlas: flip the screen and add touchscreen controls
    - The TFT uses rotation 3, so the board's connector pigtails leave from the
    top of the screen instead of pointing at the user.
    - After the 2 s splash, a status screen shows the table state, a detail line
    (pairing countdown, counts, turn, time left, pending pass, result), action
    messages, and touch buttons.
    - New touch_controls.cpp (host-tested) builds the screen and holds the touch
    adapter. Buttons dispatch Intents with IntentOrigin::AtlasHardware: Pair a
    Sigil (PairRequest, replacing the Pair button), Pass, Pause, Resume (for
    the active seat), and a hold-only "end match (draw)" (EndMatch after
    MASTER_END_MATCH_HOLD_MS) with a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
    [config.h, main.cpp, touch_controls.h]
2026-09-24 Atlas: on-device touchscreen calibration
    On the first E32R28T, the touch defaults borrowed from similar boards put
    touches about one button-height below the drawn Pair button. Resistive
    panels vary from unit to unit, so Atlas now calibrates on the device instead
    of relying on hand-tuned constants.
    - New touch_calibration.h (host-tested): solves swap and invert and each
    axis's raw range from four inset crosses, extended to the screen edges.
    It refuses presses that don't span the panel or whose axes don't separate.
    - atlas_display.cpp: a 4-point calibration screen runs after the splash
    when none is saved, and a 10 s hold anywhere in the lobby reruns it. The
    hold never fires the button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
    [touch_controls.h]
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2026-09-25 Sigil OLED: select verified carrier wiring, flip 180°, restyle screens
    Fill OLED_CONFIG with the owner-verified SH1106 128x64 software-SPI wiring
    on the EPD header (CLK 18, MOSI 23, RES 22, DC 16, CS 17) and rotate 180°
    to match the mounted panel. Restyle the renderer: inverted title bar with
    host crown, highlighted turn/pause/winner banners with icons, heart plus
    large life total, and an hourglass boot splash. The host stub now bounds-
    checks drawing primitives and rejects overlapping text.
    [oled_config.h]
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2026-09-25 Atlas: fix touch read timing; stop pinning COM ports
    The bit-banged XPT2046 read sampled DOUT just after the falling clock
    edge, racing the chip's own bit change and scrambling positions (and any
    calibration solved from them). Sample while the clock is high, discard
    the first conversion per axis, and gate each sample on pressure before
    and after. Move the saved calibration to atlas-touch/cal2 so each Atlas
    recalibrates once, and add a 12 px slop for a press already on a button.
    COM numbers change when the PC restarts, so neither platformio.ini pins
    a port any more. Record the owner's microSD "limp mode" direction.
    [touch_controls.h]
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2026-09-25 TestHarness: emulate two menu Sigils and play whole games
    The harness board's station and soft-AP MACs pair with Atlas as two
    Sigils (V1, V2), each able to seat two players. They speak only the
    shared ESP-NOW contract and pick from the MenuState Atlas sends, so a
    run exercises the real menu-Sigil path. Serial commands: status, pair,
    forget, sigils, pace, verbose, menu, select, run smoke|game|soak.
    run game covers join, seat B, start, turns with the pass grace,
    pause/resume, an elimination (3+ players), a win claim confirmed by
    every player, and reset or rematch. Passed on the owner's Atlas with
    2, 3 and 4 players (28/28 steps for 4 players, 6 turns). A 1.5 s pace
    before each choice (pace <m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
    [main.cpp]
2026-09-25 Atlas touchscreen launches premade test-harness runs
    New CAPABILITY_HARNESS Hello bit and two additive packet types:
    HarnessCommand (Atlas -> harness: run a test or stop) and HarnessReport
    (harness -> Atlas: state, test, last checkpoint, steps passed/failed).
    Protocol version stays 1; Sigils ignore both.
    - Atlas: harness_link tracks the online harness and its reports. While
    one is online the lobby shows Tests beside Pair a Sigil, opening Radio,
    2p game, 4p game, Rematch and Soak x5, Stop test while one runs, and
    progress in words. No Intents: the harness still plays only through
    its own Sigils' SelectAction. Up to six touch buttons per screen.
    - TestHarness: V1 advertises the bit, r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
    [main.cpp, touch_controls.h]
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2026-09-25 Factory reset for Atlas and each Sigil from Device Settings
    New FactoryReset Intent (Admin, admin unlocked at the table, never during
    a match):
    - Sigil (lobby, nobody seated): Atlas sends FactoryReset = 28 with
    FACTORY_RESET_CONFIRM ("FRES"), queued ahead of the Unpair that
    forgetting it sends. The Sigil honors it only from its saved Atlas, for
    its own ID, and erases its NVS and restarts. An out-of-range Sigil is
    only forgotten, and the reply says so. The harness clears only that
    virtual Sigil's pairing.
    - Atlas (lobby or game over): replies, then after 1.5 s erases its NVS
    partition and restarts (factory_reset.cpp, firmware-only). The microSD
    card is kept. The portal asks for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
    [intent.h, main.cpp]
2026-09-25 Replace table host and admin unlock with the accepted access gate
    No table host (owner decision): any seated controller may start (the
    countdown stays cancellable by any seated player), pick or randomize the
    starter, change next-game settings, rematch or reset. Sigil menus and
    legacy gestures, the portal, the next-game settings API and Android all
    follow; the host LED overlay, display flag, chip tag and "Table host"
    badge are gone. Contract fields stay: hostModuleId is always null, and
    the session's "host" now means "seated".
    Presence code replaces the 3 s Unlock admin hold (front_panel.cpp):
    - POST /api/presence/request (an Admin, or anyone signed in before any
    Admin exists) shows a six-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
    [main.cpp, touch_controls.h]
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2026-09-25 Touchscreen table actions, master pass, quieter Atlas speaker
    The Atlas touchscreen can start, cancel the countdown, rematch and reset
    between games. During play its main row is only Pause/Resume and Table; the
    Pass button is gone (players pass from their seats). The Table screen holds
    Master pass (2 s hold) for a stuck turn and End match (5 s hold).
    Master pass is a new Atlas-hardware-only MasterPass Intent: it passes the
    active turn at once, clears a queued PASS, waits for open table decisions,
    and is logged as ATLAS|GAME|MASTER_PASS plus a master_pass activity entry.
    A Game Master's portal pass logs the same line.
    Each Atlas speaker volume level is about 10% quieter.
    Host scenarios, en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
    [intent.h, main.cpp, touch_controls.h]
2026-09-25 E-ink Sigil profile picker; stop Atlas screen flicker
    Join on an e-ink menu Sigil (firmware 0.8.0+) opens an Atlas-owned
    picker: Guest, then profiles by name, three per page on fixed compass
    keys, with a confirm step. The new PickProfile Intent enforces "Allow
    physical use without a PIN" in the handler. New radio packets
    PickerKey (15) and ProfilePicker (33); protocol version stays 1.
    The Atlas TFT now draws the turn clock, countdown bar and hold bars
    over old pixels instead of clearing first, and a hold repaints only
    its own button.
    Host-tested; hardware verification pending.
    [intent.h, main.cpp]
2026-09-25 Atlas touchscreen: Clear hold empties the lobby
    A Clear button joins the lobby row once anyone has joined. Holding it
    for 2 s sends ResetGame from Atlas hardware, which the reset handler now
    accepts in an unstarted lobby; a tap only explains. With a harness
    connected the six-button row uses equal widths.
    [touch_controls.h]
2026-09-25 OLED Sigil schematic: five discrete pushbuttons replace the d-pad header
    J4 (a d-pad module header) becomes SW1-SW5, momentary pushbuttons from
    each key GPIO to a shared GND with the internal pull-ups: Up J11/GPIO25,
    Down J9/GPIO27, Left A12/GPIO19, Right A14/GPIO21, Select J13/GPIO32.
    Firmware already reads them this way. Rebuilt with build_schematic.py;
    verify_schematic.py passes and KiCad ERC reports 0 violations on both
    schematics.
    [Sigil_EInk.kicad_sch, Sigil_OLED.kicad_sch]
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2026-09-26 Sigil display-type strap on GPIO4; Atlas table clock syncs Sigil lights
    - Header A7 (GPIO4) is a hardware flag: open = E-ink, GND = OLED. A build
    for the other display halts at boot (serial MISMATCH line, red status
    light) before the display or radio start. Wokwi skips the check.
    - New TableClock packet (39): Atlas sends its millis() with the LedState
    stream and every 2 s. Sigils keep the best-of-four offset and run every
    looping cue/overlay pattern on table time, so all Sigils blink and
    breathe in step. Sigil-local states stay on local time.
    - Host scenario covers two Sigils booted apart, radio delay and an Atlas
    restart. Lock-step on real hardware still needs verification.
    Co-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
    [main.cpp]
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2026-09-26 Sigil schematics: first-PCB footprints, GPIO4 display strap, ring and 3V3 capacitors
    - Every carrier part except the DevKit (U1) gets a through-hole footprint
    and joins the BOM; J3 becomes a numbered 2-pin buzzer header.
    - A7/GPIO4 strap: open on the E-ink board, GND on the OLED board, matching
    HW_TYPE_STRAP_PIN (the OLED draft had it NC, which would halt at boot).
    - C1 470 uF across the Jewel supply, C2 10 uF on +3V3.
    - tools/offline_netlist.py lets verify_schematic.py run without KiCad;
    ERC still needs a KiCad re-run.
    Claude-Session: https://claude.ai/code/session_01EuTMd98XaCZ1DRqGGQFyaV
    [Sigil_EInk.kicad_sch, Sigil_OLED.kicad_sch]
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2026-09-26 Sigil schematics: ring level shifter, DevKit socket footprint, piezo buzzer
    - U2 74AHCT1G125 (SOT-23-5, C3 100 nF) buffers GPIO26 to 5 V ahead of R1.
    - U1 gets Sigil.pretty/ESP32_DevKit_38_Socket_Row25.4mm from published
    Inland DevKit dimensions (2.54 mm pitch, 25.4 mm rows); needs a caliper check.
    - J3 documented as a directly driven passive piezo.
    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
    [Sigil_EInk.kicad_sch, Sigil_OLED.kicad_sch]
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2026-09-26 Sigil schematic review fixes
    - DevKit footprint courtyard was skewed (two slanted edges); draw Fab,
    silk and courtyard as true rectangles.
    - Chain-out J3 gets its own symbol (pin 2 named DOUT, not DIN).
    - Stale comments and docs: U2 is SMD, U1 has a footprint, strip chaining
    is from the adapter's J3; verifier PASS line names what it checked.
    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
    [Sigil_JewelAdapter.kicad_sch]
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2026-09-29 Sigil E-ink PCB: measured DevKit footprint, routed board, fab outputs
    - U1 footprint rows 22.225 mm (7/8 in) apart per owner measurement,
    25.4 x 53.975 mm outline; renamed ESP32_DevKit_38_Socket_Row22.225mm.
    - Antenna keep-out narrowed to the measured antenna (6.35 x 19.05 mm)
    so the pin rows stay routable.
    - Board top edge moved up 0.5 mm to clear silkscreen.
    - Routed with Freerouting v2.4.1 plus a hand-placed BUZZER track; GND
    pours on both layers with solid pad connections. KiCad 10.0.6 DRC:
    0 violations, 0 unconnected, 0 schematic parity issues.
    - Added BOM CSV, Gerber/drill zip and position CSV under fab/.
    - Not fabrication-verified: U1 row spacing still needs a test-fit.
    Co-Au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
    [Sigil_EInk-B_Cu.gbl, Sigil_EInk-B_Mask.gbs, Sigil_EInk-B_Paste.gbp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]
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2026-09-29 Sigil: show "Atlas lost" when the paired Atlas stops answering
    After LINK_TIMEOUT_MS (7 s, now shared with Atlas's Sigil timeout) with
    no valid packet from its Atlas, a Sigil replaces its stale screen with
    "Atlas lost / Searching..." (no menu) and its light with an orange
    back-and-forth sweep (reduced motion: two steady pixels; one LED: double
    blink). Menu and life keys are ignored and stale menu/life state dropped
    until Atlas answers again; the last screen is then redrawn.
    [main.cpp]
2026-09-29 Atlas: microSD hot-plug without a restart
    The SD worker now owns the card: it probes a mounted card with a raw
    sector read, unmounts on a failed probe or log write, and retries
    mounting every 2 s (30 s for a card that fails its checks). A card
    inserted after boot, or reinserted, is mounted and the application loop
    re-points detailed statistics at it. The locked store re-checks the card
    inside the lock so it never touches a card the worker just dropped.
    A present card that refuses writes stops logging for that mount rather
    than remounting in a loop.
    [main.cpp]
2026-09-29 Secure link: mbedTLS backend and boot self-test (WIP checkpoint)
    MbedtlsCrypto (X25519 with RFC 7748 clamping, AES-128-CCM, HMAC-SHA256,
    hardware RNG) in shared/include/secure_link_mbedtls.h, and a generic
    knownAnswerTest against RFC 7748/4231/3610 vectors (confirmed with an
    independent library) plus a fresh agreement and sealed round trip.
    Atlas and Sigil run it at boot and log PASS/FAIL. Firmware builds not
    yet re-run after a PC crash; Sigil secure-link host test passes.
    [main.cpp]
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2026-09-29 Sigil: pairing v2 key agreement, code screen and pair key storage
    Pair broadcasts PairRequest2 with a fresh X25519 key; Atlas's
    PairAccept2 puts the 4-digit code on the e-ink and OLED screens (no
    menu) with the pairing light on; a MAC-checked PairConfirmed stores
    Atlas, the slot and the pair key (NVS atlas_k), PairRejected or 65 s
    without a verdict stores nothing. Keyless bindings still load. The
    receive buffer takes the 39- and 15-byte pairing packets.
    [main.cpp]
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2026-09-29 Pairing windows: 60 s minimum on every device
    PAIRING_WINDOW_MS goes from 15 s to 60 s (the Sigil's window and
    Atlas's default); Atlas's admin choices become 60, 90 or 120 s, never
    shorter, and a saved 15 or 30 s reads as 60 s. The harness waits long
    enough for the window plus two code checks. UI text, Wokwi, docs,
    CLAUDE.md and manual V0.4 updated.
    [main.cpp]
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2026-09-29 Sigil: secure session and sealed traffic with its Atlas
    Sends SecureHello when it has no session or Atlas went quiet, else a
    sealed Hello; every packet it sends is sealed, and only frames that
    open in the session (plus pairing and the handshake) are handled. A
    keyless binding from before pairing v2 is forgotten at boot. The old
    PairAccept path is gone.
    [main.cpp]
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2026-09-29 Complete portal Sigil OTA with signed Atlas uploads and integration tests
    Connect staging, single-use downloads, update offers/status and portal controls. Enforce display variant and presence checks; rehash staged packages and require a fresh authenticated reboot before reporting success. Add host integration tests and a hardware verification checklist.
    [intent.h, main.cpp]
2026-09-29 Use Atlas startup AP credentials for Sigil OTA offers
    Avoid unsupported WiFi.softAPPSK; pass the actual SSID/password from startup. Remove the inaccurate host accessor and assert both credentials in the OTA service test.
    [main.cpp]
2026-09-30 Playtest #1: lighter portal polling and runtime health log
    Several phones crashed Atlas in play testing. Each portal tab polled 5-9
    endpoints every 800 ms on the single-threaded web server. The timer now
    polls live data each second and devices, settings and admin data every
    fifth tick, after a table-state or Sigil-count change, or on any action;
    hidden tabs stop polling. Atlas logs heap and Wi-Fi client figures every
    minute and whenever a phone joins or leaves, so a crash leaves a trail.
    [main.cpp]
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2026-09-30 Playtest #5: player names in /api/v1/state and for phone players
    Names were unreliable on Android and the Atlas screen:
    - The Atlas screen looked names up only for Sigil seats in the lobby, so
    phone-joined players showed as "Player N" until the game started.
    - /api/v1/state never carried names (the schema allows displayName), so
    the app depended on a separate /api/seats call it refreshes only now and
    then and silently keeps stale on failure.
    profileIdForTableSeat()/displayNameForTableSeat() now resolve a seat's
    profile the same way for the screen and the state. ClientState carries
    displayName, looked up through a hook only when a seat's occupant changes
    or every 5 s (renames), so poll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
    [main.cpp]
2026-09-30 Playtest #6: slower life ramp on e-ink, scaled by hold timing
    Holding a life key on the e-ink Sigil counted faster than the panel can
    show. LifeAdjuster takes a LifePace: the OLED keeps the protocol pace,
    e-ink repeats from 0.7 s every 0.3 s and switches to steps of 5 at 3 s.
    Both scale with the seated player's InputTiming long press (default 2 s),
    so a player who asked for longer holds also gets a slower ramp.
    Also fixes run-gcc.ps1's last line, where a backslash-f in a path had
    become a form feed, so the firmware package scenarios never ran on
    Windows.
    [main.cpp]
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2026-09-30 Fix firmware builds after the playtest fixes
    - sigil_update_service.h includes stddef.h/stdint.h for size_t (Atlas, Linux host).
    - LifePace uses a constexpr constructor: the ESP32 toolchain is C++11, which
    cannot brace-initialize a struct with default member values (both Sigils).
    - The harness names the new switch-seat SigilAction (its static_assert).
    [main.cpp]
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2026-09-30 Atlas: cut RAM use and send the portal gzipped
    After the playtest crashes and a 73 s ESP-NOW NO_MEM stall with phones
    connected (free heap about 48 KB), trim what Atlas holds in RAM:
    - Portal page and theme CSS are gzipped at build time
    (tools/gzip_web_pages.py): 114.5 KB -> 31.4 KB and 18.9 KB -> 5.5 KB per
    load, so phones tie up far fewer Wi-Fi transmit buffers.
    - The Developer log download streams from the ring in 512-byte chunks
    instead of building ~32 KB of Strings.
    - Serial log ring 16 KB -> 8 KB; the SD worker drains it fully each pass
    with a 1 KB buffer and a 5 KB task stack (was 2 KB in 6 KB).
    - Recovery buffers sized to the largest record (2,679 bytes, not two
    4 KB copie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
    [main.cpp]
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2026-09-30 OOBE: Atlas setup stages, AdvanceSetup Intent and /api/setup
    A new Atlas starts at Welcome; a presence-verified Admin who has replaced
    the shipped Wi-Fi password finishes setup (Finished), and the touchscreen
    or an Admin acknowledges it (Complete). An Atlas that already has an Admin
    skips setup. GET /api/setup and POST /api/setup/finish serve the app and
    the portal alike. Compiles on the host; scenarios still to add.
    [intent.h, main.cpp]
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

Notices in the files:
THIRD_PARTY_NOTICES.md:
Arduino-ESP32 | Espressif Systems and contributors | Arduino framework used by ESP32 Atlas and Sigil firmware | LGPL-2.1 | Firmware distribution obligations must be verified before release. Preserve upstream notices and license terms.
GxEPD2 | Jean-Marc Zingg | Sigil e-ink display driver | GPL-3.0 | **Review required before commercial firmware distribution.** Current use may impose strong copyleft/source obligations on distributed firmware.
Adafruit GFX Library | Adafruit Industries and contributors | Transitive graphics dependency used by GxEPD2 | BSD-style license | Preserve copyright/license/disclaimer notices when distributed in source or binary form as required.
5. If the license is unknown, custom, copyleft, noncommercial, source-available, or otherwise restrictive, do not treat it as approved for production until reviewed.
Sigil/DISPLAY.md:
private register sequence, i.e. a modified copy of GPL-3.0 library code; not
